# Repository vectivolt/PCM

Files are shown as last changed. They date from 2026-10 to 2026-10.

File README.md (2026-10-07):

<p align="center">
  PCM – power conversion modules: DC/DC and DC/AC, designed in Python
</p>

<p align="center">
  
  
  
  
  
</p>

**PCM** is a family of power conversion modules for solar-plus-storage systems: a 75 kW non-isolated bidirectional
MPPT DC/DC (PV-P75, with a 100/110 kW four-phase build), a 125 kW three-phase battery inverter (PCS-P125, with a
four-wire build PCS-P125-4W) and a 60 kW isolated dual-active-bridge DC/DC (DAB-D60). Everything here — KiCad 10 schematics, BOMs, costed BOMs and the
simulations behind every component value — is generated by Python scripts in this repository. Nothing is
bench-validated: every figure is calculated, simulated or estimated, and is labelled as such.

<p align="center">
  <a href="docs/README.md"><b>Documentation</b></a> ·
  <a href="docs/guide/01-overview.md">Overview</a> ·
  <a href="docs/guide/07-sourcing-and-cost.md">Cost</a> ·
  <a href="docs/guide/11-megarevo-comparison.md">Comparison</a> ·
  <a href="docs/guide/12-risks-and-open-items.md">Risks</a> ·
  <a href="docs/guide/13-repository-guide.md">Repository guide</a>
</p>

---

## ⚡ At a glance

| Product | What it is | Rating | Ports | Status as of 2026-10-07 |
|---|---|---|---|---|
| **PV-P75** | non-isolated bidirectional buck-boost DC/DC with MPPT | 75 kW · 82.5 kW max | both 250–1000 V · 135 A | power board **PV-PWR rev A2** + control board **PV-CTL rev A2** drawn (recorder flash, chainable stop, ready, battery-fault input and status relay added; Ethernet footprints only, [D-075](docs/requirements/DECISIONS.md)); every build check passes; independent review answered ([D-065](docs/requirements/DECISIONS.md), [D-072](docs/requirements/DECISIONS.md)); **75 kW from 556 V; 74.25 kW at 550 V × 135 A** — the current-limited corner (the delivered rating from 562 V at equal port voltages; calculated); DESAT string re-rated to 1,300 V diodes ([D-081](docs/requirements/DECISIONS.md)); BOM 980 / 820 USD |
| **PV-P100/110** | four-phase build of the same design | 100 / 110 kW | both 250–1000 V · 145 A on the battery port | PV-PWR-4 + PV-CTL drawn; checks pass; a derated build today (100 kW from 690 V, full power to 35 °C inlet); PV-P110's 110 kW is a PV-input rating (108.8 kW delivered A→B); BOM 1,171 / 981 USD |
| **PCS-P125** | three-phase bidirectional DC-to-AC battery inverter, three-wire (3W+PE) | 125 kW · 150 kVA for 2 min | DC 590–950 V required, 624–950 V calculated at 400 V AC · 400 V AC, 180 A | power board **PCS-PWR rev A0** + control board **PCS-CTL rev A0** (assembly PCS-CTL-3W) drawn, every build check passes; start-up from the grid through an AC tap and AC precharge, Ethernet (Modbus TCP) fitted ([D-074](docs/requirements/DECISIONS.md), [D-075](docs/requirements/DECISIONS.md)); control studied by calculation, off-grid accuracy and ride-through included ([D-066](docs/requirements/DECISIONS.md), [D-077](docs/requirements/DECISIONS.md)); independently re-checked (R2) and corrected at zero BOM cost — trip chain, gate resistor, backup band, start-up sequence, bounded transients ([D-078](docs/requirements/DECISIONS.md), [D-079](docs/requirements/DECISIONS.md)); re-checked again (R3) — one-coil synchronised close, both trip layers on the four-wire short, PCS / PV bus coordination, two SiC module grades, the declared off-grid envelope ([D-080](docs/requirements/DECISIONS.md)); and once more, economically (R4) — DESAT diodes re-rated to 1,300 V, the battery-less bus window enforced (750 V default, 782 V clamp), the envelope as a declared output capability, full operation from −10 °C inlet, grade B rated 124.57 kW at 60 °C ([D-081](docs/requirements/DECISIONS.md)); BOM 1,589 / 1,349 USD |
| **PCS-P125-4W** | the same inverter, four-wire (3W+N+PE), with a fourth two-level leg for the neutral | 125 kW · 100 % unbalanced load (one phase at its tier) | DC 650–950 V required, 624–950 V calculated (neutral leg in mode B) · 400/230 V AC, 180 A | power board **PCS-PWR-4W rev A0** + **PCS-CTL rev A0** (assembly PCS-CTL-4W) drawn, every build check passes ([D-074](docs/requirements/DECISIONS.md)); auxiliary supply re-rated for it ([D-076](docs/requirements/DECISIONS.md)); BOM 1,926 / 1,636 USD (a lower bound: two lines unpriced) |
| **DAB-D60** | isolated dual-active-bridge DC/DC | 60 kW | 590–950 V · 400–900 V | device study with Chinese discretes (not drawn), corrected after the review ([D-068](docs/requirements/DECISIONS.md)); board DAB60 rev B (Wolfspeed modules) frozen, to be redrawn cost-first |

<sub>Ratings: <a href="docs/requirements/REQUIREMENTS.md">REQUIREMENTS.md</a> (PV-01…08, AC-02, DAB-01, DAB-10/11). BOM figures are catalogue / 5,000 units in USD, estimates where no price exists (<a href="bom/COST.md">bom/COST.md</a>, as of 2026-10-07). The earlier full-featured eight-board platform is kept as the roadmap's reference implementation and is not developed further.</sub>

## 🔬 Status dashboard

| | Requirements | Architecture | Design study | Schematic | Build checks | Costed BOM | Bench test |
|---|:---:|:---:|:---:|:---:|:---:|:---:|:---:|
| **PV-P75** |  |  |  |  |  |  | — |
| **PV-P100/110** |  |  |  |  |  |  | — |
| **PCS-P125 / -4W** |  |  |  |  |  |  | — |
| **DAB-D60** |  |  |  |  |  |  | — |

<sub>Teal = done · amber = partial, in study or frozen · — = not started. Bench tests and PCB layout are outside this repository's scope. Generated detail: <a href="docs/guide/01-overview.md#-status">Overview › Status</a>. Pin audit: 247 parts drawn, 192 pass (1,961 pins), 0 fail, 55 not auditable with a written reason (<a href="gen/data/pin_audit_report.csv">pin_audit_report.csv</a>). Review registers: the independent review of commit <code>033d8d8</code> — 27 findings, 22 closed, 5 open — is <a href="gen/data/review_pcm.csv">gen/data/review_pcm.csv</a>; the re-check of commit <code>a427981</code> — 14 findings, all closed in the register — is <a href="gen/data/review_r2.csv">gen/data/review_r2.csv</a>; the re-check of commit <code>615e4b5</code> — 5 findings, all closed in the register — is <a href="gen/data/review_r3.csv">gen/data/review_r3.csv</a>; the economical re-check of commit <code>845131d</code> — 12 decision areas, all closed in the register — is <a href="gen/data/review_r4.csv">gen/data/review_r4.csv</a>; all four summarised in <a href="docs/guide/08-verification.md#-independent-design-reviews">Verification</a>.</sub>

**Independent re-check R2 (2026-10-07).** A second independent review re-checked commit `a427981` and raised 14
findings (8 high, 6 medium). Each was reproduced on our own models before anything changed: 9 *Confirmed*, 1 *Firmware
Handled*, 2 *Already Fixed*, 1 *Not Applicable*, 1 *Improvement Recommended* ([review_r2.csv](gen/data/review_r2.csv)).
[D-078](docs/requirements/DECISIONS.md) answers the power stage and protection chain — the inverter's trip turns the
gates off at about 520 A, so the turn-off gate resistor went from 7.5 to 8.75 Ω (1,437 V against 1,445 V, calculated),
the controller's backup band was lowered below the L1 knee, the SiC devices get an absolute R<sub>DS(on)</sub> limit with
a per-lot derating, and the AC coil and the residual-current monitor get one contract each.
[D-079](docs/requirements/DECISIONS.md) answers the control study — a 1,944-case tolerance regression (the reviewer's
own reproduction of the nominal margins matched ours), off-grid transients bounded at 0.43 / 1.77 pu (the 2.17 pu
figure is superseded), stiff-grid ride-through without derating (the derating is now the fallback) and the AC start as
an executed state machine with five repairs. Nothing was added to the BOM. The installation conditions the modules rely
on are collected, row by row with their source lines, in [INSTALLATION.md](docs/requirements/INSTALLATION.md); what only
hardware can close stays open in [Risks and open items](docs/guide/12-risks-and-open-items.md).

**Independent re-check R3 (2026-10-07).** A third review re-checked the R2 response, commit `615e4b5`, and raised five
findings (4 high, 1 low): 4 *Confirmed*, 1 *Improvement Recommended*, all closed in the register
([review_r3.csv](gen/data/review_r3.csv)). [D-080](docs/requirements/DECISIONS.md) answers them with firmware and
acceptance rules and one requirement row, nothing added to the BOM (simulated or calculated): the inverter's
synchronised close now pulls in one AC contactor coil at a time (38.9 / 42.2 W against the 48 W peak; 646 state-event
pairs and 24 fault runs pass); the four-wire line-to-neutral short is replayed through both hardware trip layers, and a
5 ms onset clamp keeps it 13.3 A below the lower one; the assumed 50 µs DC/DC stop is replaced by the coupled PCS / PV
trajectory, on which an island rides a full-load rejection with the PV modules' coordination row (its one-node 909 V is
a model validity, not a rating — the window enforced since D-081 is 750 / 782 V); the SiC devices grade each module A
or B with a full tier table (at 60 °C 198.0 / 216.0 / 242.9 A against 179.8 / 192.6 / 192.6 A; grade B's 179.8 A is
124.57 kW at PF 1), bound to the module serial; and the off-grid envelope is the ITIC-style curve from memory, adopted by
delegation as requirement AC-04 (+0.054 pu margin, simulated). The reviewer's own inner-loop reruns matched the study to
the last digit.

**Independent re-check R4 (2026-10-07).** A fourth, economical review of commit `845131d` grouped its points into
twelve decision areas (2 high, 5 medium, 5 low), each with a preferred option, an alternative, a no-change boundary and a
cost basis: 3 *Confirmed*, 4 *Already Fixed*, 3 *Improvement Recommended*, 2 *Not Applicable*, all closed in the
register ([review_r4.csv](gen/data/review_r4.csv)). [D-081](docs/requirements/DECISIONS.md) answers them (calculated or
simulated): its one new technical finding was right and our own envelope made it wider — the DESAT string of every
1,700 V gate-drive channel now has two 1,300 V diodes (Vishay BYG23T-M3/TR) instead of 1,000 V ones that relied on
unproven sharing, each blocking the 1,130 V static envelope alone, for +0.96 to +2.12 USD per module at 5,000 units; the
coupled DC bus carries the inter-module cable (up to +28 V) and runs inside an enforced window — 750 V default, 782 V
firmware clamp, no island start above 791 V — over a harness contract for the integrator; requirement AC-04 is reworded
as the module's declared output capability, not a load-compatibility claim, with a release sequence; the inverter's
passive cold-start table is too small to be useful, so its cold rating is full operation from −10 °C inlet (AC-02
amended by delegation); grade B states its rating, 124.57 kW at 60 °C; and the custom magnetics get an RFQ index
([RFQ-MAGNETICS.md](docs/requirements/RFQ-MAGNETICS.md)). No topology, capacitor bank, brake chopper or inter-module trip
line was added. The restrictions it accepts, each with the boundary that stays, are listed in
[Risks and open items](docs/guide/12-risks-and-open-items.md#standing-restrictions).

**Independent closure re-check R5 (2026-10-07).** A fifth review of commit `5c56aaa` found no new defect: six closure
rows, 4 *Already Fixed*, 1 *Not Applicable* (the earlier platform's GDRV-HB / DAB60 keep their own 1,200 V-class diode
strings, deferred with their own qualification), 1 *Improvement Recommended*, all closed in the register
([review_r5.csv](gen/data/review_r5.csv)). The reviewer verified D-081 at BOM level (the BYG23T counts per board) and by
his own arithmetic (the 6.415–9.365 V DESAT window, the 790.9 V bus permissive, the −10 °C inverter grade), and his
bottom line is accepted in [D-082](docs/requirements/DECISIONS.md): the next useful milestone is a representative
switching cell and a controlled prototype, not another declaration that every script passes. What changes is one
document: every open gate of the five rounds — the DESAT string's dynamic qualification, the battery-less bus and its
harness, the cold rating and grid code, the SiC cell's short-circuit survival, layout, supplier data, magnetics, bench
protection tests, pre-compliance, production controls — is consolidated into the
[Qualification plan](docs/requirements/QUALIFICATION-PLAN.md): 44 gates Q-01..Q-44 in four stages, each with the
acceptance criterion our records give, the test asset and the product or claim it blocks. No hardware change; nothing
is measured; no unrestricted HV, full-power or production sign-off is claimed from the script passes.

---

## 🧭 The cost-first PV module

One power board and one control board, control referenced to the negative DC rail, **one** reinforced barrier to
everything a person or another device can touch ([ARCHITECTURE-COSTFIRST.md](docs/requirements/ARCHITECTURE-COSTFIRST.md)):

```mermaid
%%{init: {"theme": "base", "themeVariables": {"primaryColor": "#EEF3F7", "primaryBorderColor": "#0B1F33", "primaryTextColor": "#0B1F33", "lineColor": "#5B6B7A", "secondaryColor": "#D9F2EF", "tertiaryColor": "#FFF4D6", "fontFamily": "Inter, Helvetica, Arial, sans-serif"}}}%%
flowchart LR
    PV["PV array<br/>250–1000 V"]:::ext
    BAT["battery or DC bus<br/>250–1000 V"]:::ext
    subgraph LIVE["DC side · referenced to BUS−"]
        PA["Port A<br/>varistors · contactor<br/>no fuse, no precharge"]:::live
        PH["3 interleaved buck-boost phases<br/>2 × 1700 V SiC per switch · 32 kHz<br/>12 NSI6651 gate drivers"]:::live
        PB["Port B<br/>aR fuse per pole · contactor<br/>precharge"]:::live
        AUX["75 W flyback<br/>fed from both ports"]:::live
        CTL["controller F280039C<br/>trip latch · watchdog"]:::live
    end
    subgraph SELV["SELV side"]
        COM["CAN · RS-485 · Ethernet option<br/>stop chain · ready · DI1 · relay"]:::selv
        FAN["3 fans"]:::selv
    end
    PV --> PA --> PH --> PB --> BAT
    PA --> AUX
    PB --> AUX
    AUX -- "3.3 V" --> CTL
    CTL <-- "PWM · measurements" --> PH
    CTL == "reinforced barrier B1" ==> COM
    AUX == "SELV winding" ==> FAN
    classDef live fill:#FDE7E0,stroke:#E4572E,color:#0B1F33
    classDef selv fill:#D9F2EF,stroke:#00A99D,color:#0B1F33
    classDef ext fill:#FFFFFF,stroke:#5B6B7A,stroke-dasharray:4 3
```

<sub>Red = hazardous-live DC side · teal = safe extra-low-voltage side. Detail: <a href="docs/guide/02-architecture.md">Architecture</a>, <a href="docs/guide/03-power-stage.md">Power stage</a>, <a href="docs/guide/04-protection-and-safety.md">Protection and safety</a>.</sub>

## 💰 Cost

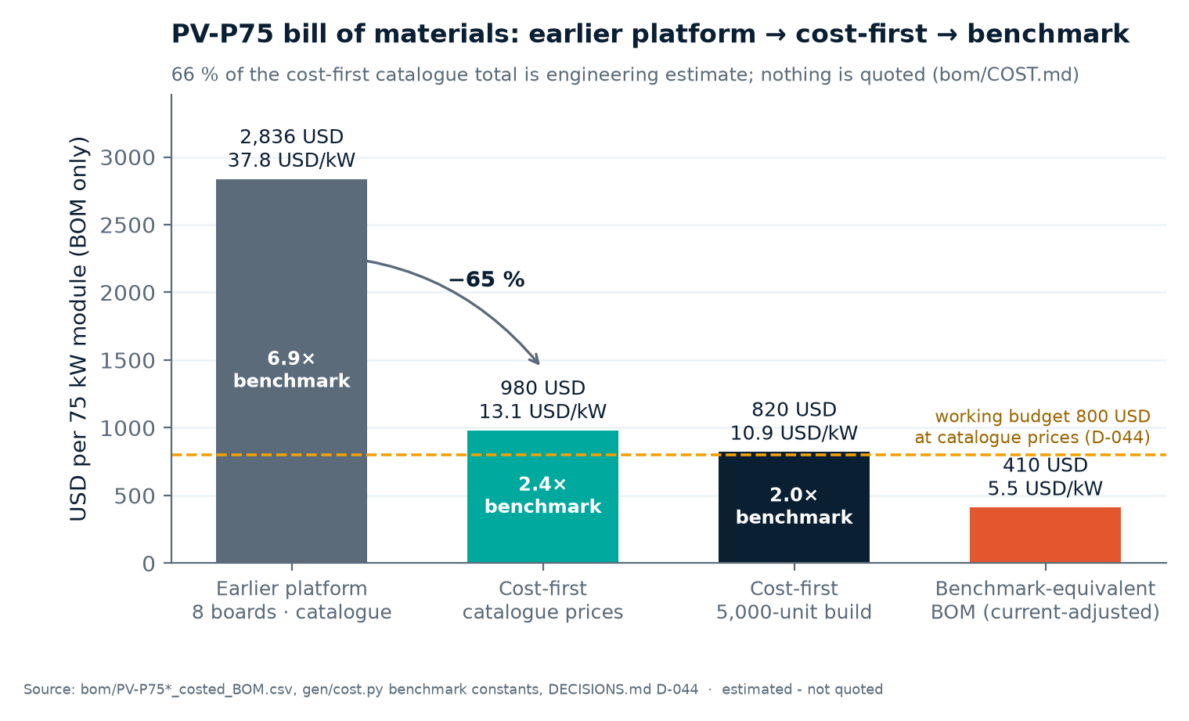
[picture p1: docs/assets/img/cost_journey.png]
PV-P75 BOM: earlier platform, cost-first at catalogue prices and at 5,000 units, against the benchmark-equivalent BOM

<p align="center"><sub>Source: <a href="bom/COST.md">bom/COST.md</a> (generated by <a href="gen/cost.py">gen/cost.py</a>) · estimated, nothing quoted</sub></p>

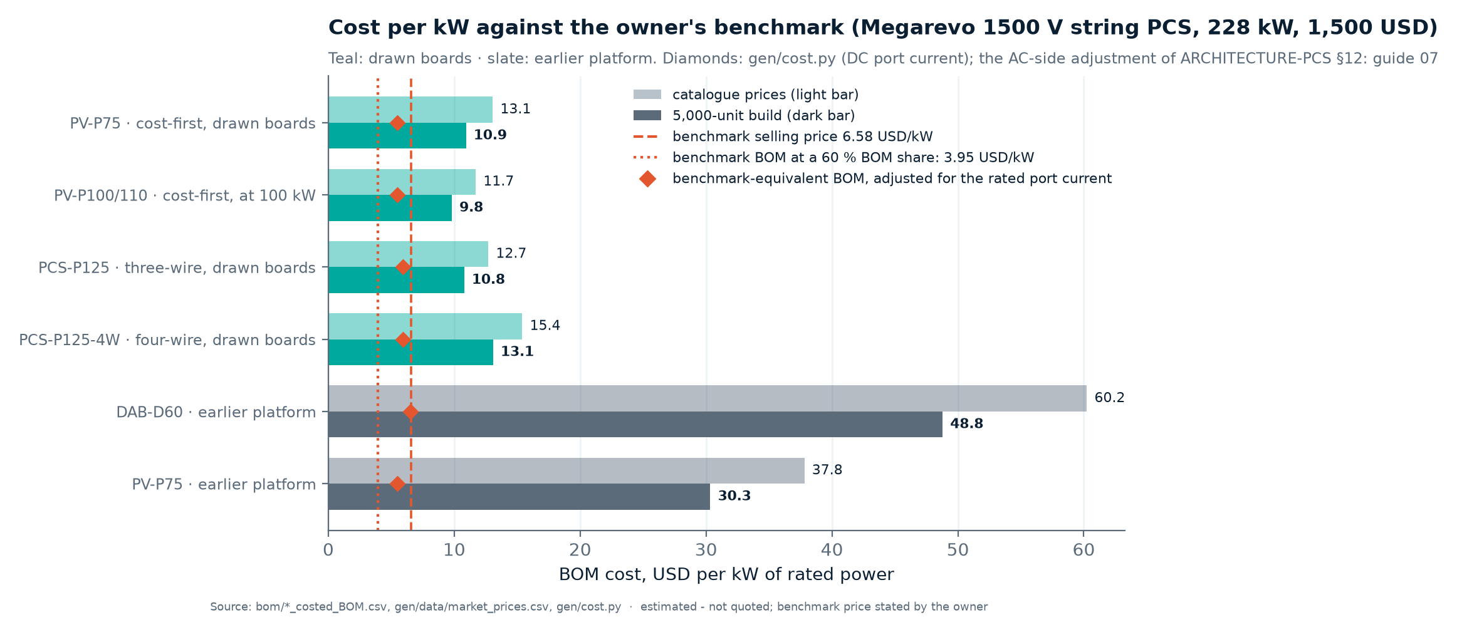
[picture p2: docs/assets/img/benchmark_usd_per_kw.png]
BOM cost per kW of every product against the owner's benchmark

<p align="center"><sub>Benchmark: Megarevo's 228 kW string PCS sells for 1,500 USD = 6.6 USD/kW (the owner's figure, a selling price). Source: <a href="gen/data/market_prices.csv">market_prices.csv</a>, <a href="sim/out/pcs_design/pcs_spec.json">pcs_spec.json</a>, <a href="bom/COST.md">bom/COST.md</a></sub></p>

<details>
<summary><b>The numbers behind the charts</b> (generated table)</summary>

<!-- BEGIN:cost-summary -->

| Product | What the figure is | kW | Catalogue USD | USD/kW | 5,000 units USD | USD/kW | Evidence | 5k ÷ benchmark-equivalent BOM |
|---|---|---:|---:|---:|---:|---:|---|---:|
| **PV-P75** | BOM of drawn boards (PV-PWR + PV-CTL) | 75 | **980** | 13.1 | **820** | 10.9 | 66 % of catalogue on estimates · 16 % of 5k on published breaks · 1 unpriced line (lower bound) | 2.0× (≈ 410 USD) |
| **PV-P100/110** | BOM of drawn boards (PV-PWR-4 + PV-CTL) | 100 / 110 | 1,171 | 11.7 / 10.6 | 981 | 9.8 / 8.9 | 64 % of catalogue on estimates · 16 % of 5k on published breaks · 2 unpriced lines (lower bound) | 1.8× / 1.8× |
| **PCS-P125** | BOM of drawn boards, three-wire (PCS-PWR + PCS-CTL-3W) | 125 | 1,589 | 12.7 | 1,349 | 10.8 | 77 % of catalogue on estimates · 9 % of 5k on published breaks · 1 unpriced line (lower bound) | 1.8× (≈ 744 USD) |
| **PCS-P125-4W** | BOM of drawn boards, four-wire (PCS-PWR-4W + PCS-CTL-4W) | 125 | 1,926 | 15.4 | 1,636 | 13.1 | 75 % of catalogue on estimates · 9 % of 5k on published breaks · 2 unpriced lines (lower bound) | 2.2× (≈ 744 USD) |
| PCS-P125 | design study, 3-wire (two-level, pcs_spec.json); the drawn boards above cost more (D-063) | 125 | 1,431 | 11.4 | 1,149 | 9.2 | 5 % of 5k on published prices | — |
| PCS-P125 | design study, 4-wire (two-level, pcs_spec.json); the drawn boards above cost more (D-063) | 125 | 1,731 | 13.8 | 1,392 | 11.1 | not stated for 4-wire | — |
| PV-P75 earlier platform | BOM of drawn boards (8 boards) | 75 | 2,836 | 37.8 | 2,275 | 30.3 | 51 % of catalogue on estimates · 17 % of 5k on published breaks · 7 unpriced lines (lower bound) | 5.5× |
| DAB-D60 earlier platform | BOM of drawn boards (5 boards) | 60 | 3,615 | 60.2 | 2,927 | 48.8 | 48 % of catalogue on estimates · 12 % of 5k on published breaks · 3 unpriced lines (lower bound) | 7.5× |
| PCS-P125 | three-level T-type estimate, **withdrawn by D-053** | 125 | 1,037 | 8.3 | 801 | 6.4 | — | — |

<sub>Generated by <a href="docs/assets/figures_overview.py">figures_overview.py</a> from <a href="bom/COST.md">bom/*_costed_BOM.csv</a>, <a href="sim/out/pcs_design/pcs_spec.json">pcs_spec.json</a> and <a href="gen/data/costfirst_pcs_bom.csv">costfirst_pcs_bom.csv</a>; benchmark arithmetic from <a href="gen/cost.py">gen/cost.py</a>. Do not edit between the markers.</sub>

<!-- END:cost-summary -->

</details>

Method, assumptions and the next cost levers: [Sourcing and cost](docs/guide/07-sourcing-and-cost.md).

## 📐 Against Megarevo, module for module

The owner's rule ([D-073](docs/requirements/DECISIONS.md)) is parity with the competitor's **modules** in both
directions — whatever its PMA inverter modules and its PMD-75-G3 DC/DC module offer, ours offer too, and the other way
round; cabinets, containers, hybrids and HMI panels are discarded, and both products stay bidirectional. Two generated
tables compare row by row, calculated against published: PV-P75 against the PMD-75-G3 — *2 better, 24 meets, 3 below,
5 not assessed, 0 pending, out of 34 published rows* — and PCS-P125 / PCS-P125-4W against the PMA0125 — *2 better, 38
meets, 4 below, 9 not assessed, 0 pending, out of 53 published rows*. The module-level items those tables do not cover
(grid type, start-up from the grid, Ethernet, the fault recorder and upgrade, discrete I/O, declarations) are tracked in
the register [gen/data/megarevo_2026_parity.csv](gen/data/megarevo_2026_parity.csv); its gaps were closed by D-074 to
D-077 except the altitude, which stays at 2,000 m with a 3,000 m / 5,000 m option specified. Details and the rows below
Megarevo: [Comparison with Megarevo](docs/guide/11-megarevo-comparison.md).

---

## 🧰 How the repository works

Python is the source of truth: simulations write the design values, generators turn them into checked schematics,
and the BOMs, costs and these charts are generated from the result. `hardware/` and `bom/` are never edited by hand.

```mermaid
%%{init: {"theme": "base", "themeVariables": {"primaryColor": "#EEF3F7", "primaryBorderColor": "#0B1F33", "primaryTextColor": "#0B1F33", "lineColor": "#5B6B7A", "secondaryColor": "#D9F2EF", "tertiaryColor": "#FFF4D6", "fontFamily": "Inter, Helvetica, Arial, sans-serif"}}}%%
flowchart LR
    REQ["docs/requirements<br/>scope lock · decisions"] --> SIM["sim/*.py<br/>design + simulation"]
    SIM -- "spec JSON" --> GEN["gen/*.py<br/>one generator per board"]
    LIB["docs/fetch.py<br/>datasheets"] -- "pin tables" --> GEN
    GEN --> HW["hardware/<br/>KiCad 10 · PDF · netlist"]
    HW --> CHK{"build checks<br/>ERC · netlist · domains<br/>stress · BOM"}
    CHK -- "pass" --> BOM["bom/<br/>board BOMs"]
    BOM -- "build_all.py --bom" --> MOD["module BOMs"]
    MOD -- "cost.py" --> COST["costed BOMs<br/>COST.md"]
    COST -- "figures_*.py" --> DOCS["docs/<br/>charts · tables"]
```

## 🧰 Quick start

```bash
# 1  Python 3.12 environment
python3.12 -m venv .venv
.venv/bin/pip install numpy scipy matplotlib pyelftools   # PyOpenMagnetics (requirements.txt) is optional: sim/magnetics.py only

# 2  Third-party datasheets and reference designs are not kept in git - the BOM check needs them
.venv/bin/python docs/fetch.py          # downloads every file of docs/SOURCES.csv and verifies its SHA-256

# 3  Build the cost-first PV module: KiCad project, ERC, netlist check, PDF and BOM per board
.venv/bin/python gen/pv_power.py        # PV-PWR and PV-PWR-4
.venv/bin/python gen/pv_ctrl.py         # PV-CTL
.venv/bin/python gen/build_all.py --bom # roll the board BOMs up into module BOMs
.venv/bin/python gen/cost.py            # costed BOMs and bom/COST.md

# 4  Run one simulation; refresh the documentation charts and generated tables
.venv/bin/python sim/pv_design.py
.venv/bin/python docs/assets/figures_overview.py
```

Tools: KiCad 10 (`kicad-cli`; on macOS `/Applications/KiCad/KiCad.app/Contents/MacOS/kicad-cli`) and ngspice 46 on
`PATH`. A few library files must be saved by hand (sites that refuse scripted downloads): the list is in
[docs/LIBRARY.md](docs/LIBRARY.md). Everything else — every board, audit and simulation — is in the
[Repository guide](docs/guide/13-repository-guide.md).

## 📚 Repository map

```
.
├── README.md                this page
├── CLAUDE.md                project rules
├── docs/
│   ├── README.md            documentation hub
│   ├── guide/               the documentation pages
│   ├── assets/              style guide, banner, figure scripts, generated charts
│   ├── requirements/        scope lock, decision register, architecture specifications
│   ├── reference-designs/   vendor reference designs (documents fetched, READMEs in git)
│   ├── datasheets/          component datasheets (fetched, not in git)
│   ├── SOURCES.csv          manifest: every library file with URL and SHA-256
│   ├── fetch.py             downloads the library again
│   └── LIBRARY.md           the reference library's own README
├── gen/                     schematic generators, build checks, audits, cost model
│   └── data/                prices, estimates, volume factors, pin ledgers, review findings
├── sim/                     design calculations and simulations (numpy, scipy, ngspice)
│   ├── data/                device and supplier surveys
│   ├── spice/               ngspice decks
│   └── out/                 one folder per study: report, spec JSON, plots
├── hardware/                generated KiCad 10 projects with PDF, netlist, ERC and report per board
└── bom/                     generated BOMs, costed BOMs and COST.md
```

## 📚 Documentation

| | Page | What it answers |
|---:|---|---|
| 01 | [Overview](docs/guide/01-overview.md) | the product family, the roadmap, the decision timeline, status |
| 02 | [Architecture](docs/guide/02-architecture.md) | how the cost-first module is built: blocks, barriers, boards |
| 03 | [Power stage](docs/guide/03-power-stage.md) | the converter phases, devices, gate drive and losses |
| 04 | [Protection and safety](docs/guide/04-protection-and-safety.md) | trips, contactors, fuses, insulation; hardware against firmware |
| 05 | [Control and firmware](docs/guide/05-control-and-firmware.md) | control loops, MPPT, protection timing, the controller |
| 06 | [Magnetics](docs/guide/06-magnetics.md) | inductors, transformers, chokes and how they were verified |
| 07 | [Sourcing and cost](docs/guide/07-sourcing-and-cost.md) | makers and evidence, cost per module, the benchmark |
| 08 | [Verification](docs/guide/08-verification.md) | build checks, audits, reviews — and what is not verified |
| 09 | [PCS-P125](docs/guide/09-pcs-p125.md) | the DC-to-AC battery inverter, three- and four-wire, with its start-up from the grid |
| 10 | [DAB-D60](docs/guide/10-dab-d60.md) | the isolated DC/DC |
| 11 | [Comparison with Megarevo](docs/guide/11-megarevo-comparison.md) | row by row against the PMD-75-G3 and the PMA0125; the module-parity register; cost against the benchmark |
| 12 | [Risks and open items](docs/guide/12-risks-and-open-items.md) | every open risk, ranked, with what would close it |
| 13 | [Repository guide](docs/guide/13-repository-guide.md) | build, simulate, re-cost; conventions for parts and boards |
| | [Glossary](docs/guide/glossary.md) · [Decisions](docs/guide/decisions.md) | terms and abbreviations · digest of the decision register |

---

> [!IMPORTANT]
> **Honesty boundary.** Nothing in this repository has been built, bought, quoted or measured. Efficiencies,
> temperatures and margins are *calculated* or *simulated*; prices are catalogue readings (the LCSC readings are a
> snapshot of 2026-10-05) or *estimates*; competitor figures are *published* and unverified by us. A review finding
> marked closed is a corrected calculation, not a test. Several standard values are transcribed from memory and still
> have to be checked against the purchased standards. Scope is schematic + BOM + simulation — no PCB layout, mechanics
> or firmware.

> [!WARNING]
> **Top open risks** — the full ranked register is in [Risks and open items](docs/guide/12-risks-and-open-items.md).
> 1. **No supplier quotations.** About two thirds of the PV-P75 BOM (66 % of the catalogue total) is engineering estimate, and the 800 USD budget is not met ([D-052](docs/requirements/DECISIONS.md)).
> 2. **The Chinese 1700 V SiC device** (Sichain SG2M040170HJ) publishes no qualification, short-circuit or cosmic-ray data; its LCSC price is now read (5.07 USD at 90+, [D-069](docs/requirements/DECISIONS.md)) but not quoted; PV-P75 uses 24, PCS-P125 36, PCS-P125-4W 48 ([D-043](docs/requirements/DECISIONS.md), [D-053](docs/requirements/DECISIONS.md)).
> 3. **Insulation** rests on standard values from memory and an unverified surge-arrester credit; the gate driver's impulse rating needs that credit ([D-032](docs/requirements/DECISIONS.md), [D-043](docs/requirements/DECISIONS.md)).
> 4. **Gate-drive margins** for false turn-on and short-circuit turn-off rest on estimated loop inductances and assumed device withstand times — the double-pulse test is the first bench item ([D-028](docs/requirements/DECISIONS.md)); on the inverter it must include the trip's turn-off near 520 A / 1,050 V (1,437 V calculated against 1,445 V) and short-circuit survival stays a hardware release gate ([D-078](docs/requirements/DECISIONS.md)).
> 5. **Requirements the calculations contradict:** PCS-P125's full load from 600 V at 400 V ±15 % (AC-02) is not reachable, PV-P75's 75 kW at 550 V needs 136.4 A against 135 A (75 kW from 556 V; 74.25 kW at 550 V × 135 A), and PV-P110's 110 kW is a PV-input rating — owner's decisions ([Risks, group G](docs/guide/12-risks-and-open-items.md#requirements-contradicted)); the inverter's −30 °C now holds as standby or a small passive table only (rated from −10 °C at power, [D-081](docs/requirements/DECISIONS.md)).

## 🗺️ What comes next

- **PV-P75 boards:** drawn (PV-PWR rev A2, PV-CTL rev A2), reviewed and corrected ([D-065](docs/requirements/DECISIONS.md), [D-072](docs/requirements/DECISIONS.md)); the control board gained the recorder flash, the chainable stop, a ready permissive, a battery-fault input and a status relay, with Ethernet as a footprint option ([D-075](docs/requirements/DECISIONS.md)); the DESAT string re-rated to two 1,300 V diodes per channel ([D-081](docs/requirements/DECISIONS.md)); BOM 980 USD at catalogue prices, 820 USD at 5,000 units. Next: the TLV9024's rejection measured at 3.3 V and 10 ppm/K ladder resistors (risk C9), the insulation audit extended to the cost-first boards, supplier quotations for the largest estimates, a sample set of the re-wound auxiliary transformer ([D-076](docs/requirements/DECISIONS.md)).
- **PCS-P125 and PCS-P125-4W:** both builds drawn and costed — 1,589 / 1,349 USD three-wire, 1,926 / 1,636 USD four-wire (catalogue / 5,000 units) ([D-074](docs/requirements/DECISIONS.md)). **Closed on 2026-10-06:** the start-up from the grid (risk F8: AC tap and AC precharge on both builds), the four-wire build (risk F9: a fourth leg, not a midpoint neutral), Ethernet for the EMS and the recorder flash for the fault recorder and the authenticated upgrade ([D-075](docs/requirements/DECISIONS.md)), the auxiliary supply's live winding ([D-076](docs/requirements/DECISIONS.md)), the neutral-leg loop and the ride-through limiter ([D-077](docs/requirements/DECISIONS.md)). **Corrected by the re-check R2 on 2026-10-07:** the trip chain at its real gates-off current with R<sub>G,off</sub> 8.75 Ω, the backup band below the L1 knee, the SiC acceptance and per-lot derating, one coil contract and the residual-current contract ([D-078](docs/requirements/DECISIONS.md)); the tolerance regression, the bounded off-grid transients, ride-through without derating and the repaired AC-start machine ([D-079](docs/requirements/DECISIONS.md)). **Corrected by the re-check R3 the same day:** the synchronised close one coil at a time, the four-wire short against both trip layers, the coupled PCS / PV bus coordination, two SiC module grades with full tier tables, the off-grid envelope as requirement AC-04 ([D-080](docs/requirements/DECISIONS.md)). **Answered after the economical re-check R4:** the DESAT string re-rated (1,300 V diodes), the cable-aware DC-bus window enforced with a harness contract, AC-04 as a declared output capability with a release sequence, the cold rating at −10 °C inlet with the passive table and its firmware rule, grade B's 124.57 kW, the magnetics RFQ index ([D-081](docs/requirements/DECISIONS.md)). **Still open:** the owner's decision on AC-02 and the owner's confirmation of AC-04 and of the −10 °C cold rating (both by delegation); the hardware gates of D-078 (short-circuit survival, the first-article L(I) test to 600 A, a double-pulse test near 520 A / 1,050 V, Sichain's R<sub>DS(on)</sub> distribution, which now decides the grade mix); the bench confirmation of the ride-through margin (20.5 A net of noise), the four-wire short's 13.3 A and the coupled-bus peaks; the new DESAT diode's V<sub>F</sub>, per-diode split and second source; an agreed load specification per managed island; a cold-rated fan from an RFQ; the magnetics quotations (18 RFQ rows still without a number); data sheets for the RFQ parts (AC contactor coil module, the 4-pole contactors, the type-B residual-current monitor, the four-bar CM choke, the precharge resistors); the L-N surge level (a 3+1 arrangement needs a GDT data sheet); pairing the DC-component measurement on one ADC; the CH9121T's supply current and stock; no spare GPIO on the inverter's controller; powder-core inductors and the stud count as cost levers.
- **DAB-D60:** the device study is corrected ([D-068](docs/requirements/DECISIONS.md)); drawing a board for it is the owner's decision (DAB-12); otherwise redraw the board cost-first ([ARCHITECTURE-COSTFIRST §16](docs/requirements/ARCHITECTURE-COSTFIRST.md#16-dab-d60-on-the-same-principles)).
- **Comparison with Megarevo:** the rows below the published tables — PV-P75: cold limit, altitude and standby; PCS-P125: the 3W+PE DC window (two rows), cold limit and altitude ([Comparison](docs/guide/11-megarevo-comparison.md#the-four-pcs-rows-below-the-pma0125)). The altitude option (15 mm isolators for 3,000 m full / 5,000 m derated) is specified and fitted on demand.
- **Before any hardware release** (outside this repository): double-pulse test of the gate drive, a wound inductor sample, the purchased standards checked against the values used.

<sub>Scope and rules: <a href="CLAUDE.md">CLAUDE.md</a> · requirements: <a href="docs/requirements/REQUIREMENTS.md">REQUIREMENTS.md</a> · decisions: <a href="docs/requirements/DECISIONS.md">DECISIONS.md</a></sub>

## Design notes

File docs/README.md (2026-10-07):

<p align="center">
  PCM – power conversion modules: DC/DC and DC/AC, designed in Python
</p>

<!-- breadcrumb --> [Home](../README.md) › Documentation

# 📚 Documentation

> Where to start, every page of the guide in reading order, and the records the pages are built from.






---

## 🧭 Start here

| If you are… | Read in this order | You will come away with |
|---|---|---|
| **Manager or product owner** | [Overview](guide/01-overview.md) → [Sourcing and cost](guide/07-sourcing-and-cost.md) → [Comparison with Megarevo](guide/11-megarevo-comparison.md) → [Risks](guide/12-risks-and-open-items.md) → [Decisions](guide/decisions.md) | what exists, what it costs against the benchmark, what is still open and who decided what |
| **Hardware engineer** | [Overview](guide/01-overview.md) → [Architecture](guide/02-architecture.md) → [Power stage](guide/03-power-stage.md) → [Protection and safety](guide/04-protection-and-safety.md) → [Magnetics](guide/06-magnetics.md) → [Verification](guide/08-verification.md) → [Repository guide](guide/13-repository-guide.md) | how the boards are built, why each value is what it is, and how to change one safely |
| **Firmware engineer** | [Architecture](guide/02-architecture.md) → [Control and firmware](guide/05-control-and-firmware.md) → [Protection and safety](guide/04-protection-and-safety.md) → [PCS-P125](guide/09-pcs-p125.md) → [DAB-D60](guide/10-dab-d60.md) | the controller, the loops, the trip paths and what firmware must duplicate |
| **Purchaser** | [Sourcing and cost](guide/07-sourcing-and-cost.md) → [Risks](guide/12-risks-and-open-items.md) (group A) → [Repository guide](guide/13-repository-guide.md#adding-a-part) → [Glossary](guide/glossary.md) | which makers, which parts need quotations first, and the evidence behind each price |

## 🗺️ Map of the guide

```mermaid
%%{init: {"theme": "base", "themeVariables": {"primaryColor": "#EEF3F7", "primaryBorderColor": "#0B1F33", "primaryTextColor": "#0B1F33", "lineColor": "#5B6B7A", "secondaryColor": "#D9F2EF", "tertiaryColor": "#FFF4D6", "fontFamily": "Inter, Helvetica, Arial, sans-serif"}}}%%
flowchart LR
    O["01 Overview"] --> A["02 Architecture"]
    subgraph DESIGN["How it is designed"]
        A --> P["03 Power stage"]
        A --> S["04 Protection and safety"]
        A --> C["05 Control and firmware"]
        P --> M["06 Magnetics"]
    end
    subgraph PRODUCTS["The other products"]
        PCS["09 PCS-P125"]
        DAB["10 DAB-D60"]
    end
    subgraph JUDGE["What it costs and how sure we are"]
        CO["07 Sourcing and cost"] --> CMP["11 Comparison with Megarevo"]
        V["08 Verification"] --> R["12 Risks and open items"]
        CMP --> R
    end
    O --> CO
    O --> PCS
    O --> DAB
    M --> V
    R --> G["13 Repository guide"]
```

## 📚 Every page

| | Page | What it answers |
|---:|---|---|
| 01 | [Overview](guide/01-overview.md) | the product family, the roadmap, the decision timeline, status by product and board |
| 02 | [Architecture](guide/02-architecture.md) | how the cost-first module is built: blocks, reference potentials, barriers, boards |
| 03 | [Power stage](guide/03-power-stage.md) | the converter phases, devices, gate drive, losses and thermal design |
| 04 | [Protection and safety](guide/04-protection-and-safety.md) | trips, contactors, fuses, insulation; what hardware does and what firmware duplicates |
| 05 | [Control and firmware](guide/05-control-and-firmware.md) | control loops, MPPT, protection timing, the controller's resources |
| 06 | [Magnetics](guide/06-magnetics.md) | inductors, transformers and chokes, and how each was verified |
| 07 | [Sourcing and cost](guide/07-sourcing-and-cost.md) | makers and evidence, cost per module at catalogue prices and at 5,000 units, the benchmark |
| 08 | [Verification](guide/08-verification.md) | build checks, audits and reviews — and what none of them proves |
| 09 | [PCS-P125](guide/09-pcs-p125.md) | the three-phase DC-to-AC battery inverter: the three-wire and four-wire builds, the start-up from the grid, the firmware specification |
| 10 | [DAB-D60](guide/10-dab-d60.md) | the isolated dual-active-bridge DC/DC |
| 11 | [Comparison with Megarevo](guide/11-megarevo-comparison.md) | row by row against the PMD-75-G3 and the PMA0125; the module-parity register; every product against the price benchmark |
| 12 | [Risks and open items](guide/12-risks-and-open-items.md) | every open risk, ranked, with its consequence and what would close it |
| 13 | [Repository guide](guide/13-repository-guide.md) | build a board, run a simulation, re-roll the cost; conventions for parts and boards |
| | [Glossary](guide/glossary.md) | abbreviations and project terms |
| | [Decisions](guide/decisions.md) | the decision register D-001…D-082, grouped by theme, with today's status |

> [!NOTE]
> **Status on 2026-10-07: the independent re-checks R2, R3 and R4 are answered.** A second independent review re-checked commit
> `a427981` and raised 14 findings (8 high, 6 medium); each was reproduced on our own models first and then classified —
> 9 *Confirmed*, 1 *Firmware Handled*, 2 *Already Fixed*, 1 *Not Applicable*, 1 *Improvement Recommended*
> ([review_r2.csv](../gen/data/review_r2.csv), all 14 closed in the register). [D-078](requirements/DECISIONS.md) answers
> the inverter's power stage and protection chain (the trip at its real gates-off current with R<sub>G,off</sub> 8.75 Ω,
> the backup band below the L1 knee, the SiC acceptance rule, one coil contract, the residual-current contract);
> [D-079](requirements/DECISIONS.md) the control study and hand-over (the tolerance regression, bounded off-grid
> transients, ride-through without derating, the AC start as an executed state machine). Everything stays calculated or
> simulated; the hardware gates are in [Risks](guide/12-risks-and-open-items.md#-the-re-check-r2-of-commit-a427981-2026-10-07),
> the installation conditions in [INSTALLATION.md](requirements/INSTALLATION.md).
>
> **The re-check R3 is answered too.** A third review re-checked the R2 response, commit `615e4b5`, and raised five
> findings (4 high, 1 low): 4 *Confirmed*, 1 *Improvement Recommended* ([review_r3.csv](../gen/data/review_r3.csv), all
> five closed in the register). [D-080](requirements/DECISIONS.md) answers them with firmware and acceptance rules and one
> requirement row: the synchronised close one AC coil at a time, the four-wire short replayed through both trip layers
> (a 5 ms onset clamp, 13.3 A margin), the coupled PCS / PV trajectory instead of an assumed 50 µs DC/DC stop (an island
> rides a full-load rejection with the PV modules' coordination row), two SiC module grades with full tier tables bound
> to the module serial, and the off-grid envelope as the ITIC-style points adopted by delegation as REQUIREMENTS AC-04 —
> nothing added to the BOM, all simulated or calculated ([Risks](guide/12-risks-and-open-items.md#-the-re-check-r3-of-commit-615e4b5-2026-10-07)).
>
> **The economical re-check R4 is answered as well.** A fourth review of commit `845131d` grouped its points into twelve
> decision areas: 3 *Confirmed*, 4 *Already Fixed*, 3 *Improvement Recommended*, 2 *Not Applicable*
> ([review_r4.csv](../gen/data/review_r4.csv), all twelve closed in the register). [D-081](requirements/DECISIONS.md)
> re-rates the DESAT string to two 1,300 V diodes per channel (each blocks the 1,130 V static envelope alone; +0.96 to
> +2.12 USD per module at 5,000 units), enforces the DC-bus window on a battery-less bus with the inter-module cable
> modelled (750 V default, 782 V firmware clamp, 791 V island permissive — the one-node 909 V is a model validity, not a
> rating) and a harness contract, rewords AC-04 as a declared output capability with a release sequence, sets the
> inverter's cold rating to full operation from −10 °C inlet, states grade B's 124.57 kW and indexes the magnetics RFQs
> ([RFQ-MAGNETICS.md](requirements/RFQ-MAGNETICS.md)); the restrictions it accepts and their boundaries are in
> [Risks](guide/12-risks-and-open-items.md#-the-re-check-r4-of-commit-845131d-2026-10-07).

---

## 📐 The records behind the pages

The pages explain; these files decide. Where a page and a record differ, the record wins.

| Record | What it holds | Edited by |
|---|---|---|
| [requirements/REQUIREMENTS.md](requirements/REQUIREMENTS.md) | the scope lock: every requirement with its source (roadmap or assumption) | the owner's instruction only |
| [requirements/DECISIONS.md](requirements/DECISIONS.md) | the decision register — rows are superseded, never deleted | appended per decision |
| [requirements/00-roadmap-source.md](requirements/00-roadmap-source.md) | the owner's engineering and product roadmap the requirements were distilled from | read-only |
| [requirements/COST-REVIEW.md](requirements/COST-REVIEW.md) | why the PV module was re-architected for cost | — |
| [requirements/ARCHITECTURE-COSTFIRST.md](requirements/ARCHITECTURE-COSTFIRST.md) | the cost-first PV module specification (and the DAB outline, §16) | — |
| [requirements/ARCHITECTURE-PCS.md](requirements/ARCHITECTURE-PCS.md) | the PCS-P125 architecture specification; its power stage is revised by D-053 | — |
| [requirements/INSTALLATION.md](requirements/INSTALLATION.md) | the installation conditions the modules depend on: 77 rows (INST-01…77), each with the generated line it comes from (review finding R2-12), and the installation-facing standing restrictions of the re-check R4; re-verified after the rebuild for the re-check R4 (D-081) on 2026-10-07 | by hand from the design checks; its quoted lines are re-verified after a rebuild |
| [requirements/RFQ-MAGNETICS.md](requirements/RFQ-MAGNETICS.md) | the request-for-quotation index for the ten custom magnetic parts: quantity per module and per build, the requirement rows a quotation must hold (inductance at current, losses, insulation, temperature), the type and production tests, the estimate held, the rows still without a number, and the 48 kHz weight-sensitive variant as an appendix (review R4, item E12) | by hand from the winding sheets and the costed BOMs; re-read after a magnetics or BOM rebuild |
| [requirements/QUALIFICATION-PLAN.md](requirements/QUALIFICATION-PLAN.md) | the consolidated qualification plan (D-082, review R5): every open gate of the five review rounds as Q-01…Q-44 — what is tested, the acceptance number our records give, the test asset, the product or claim it blocks and the stage (representative switching cell → controlled prototype → DVT → production controls) — with a "what a paper waiver cannot replace" section and a gate / blocks / stage / source table; nothing in it has been executed, and the R5 register [review_r5.csv](../gen/data/review_r5.csv) (six rows, all closed, no new defect) is the record behind it | by hand from the registers, the decisions' **Open** lists, INSTALLATION.md, RFQ-MAGNETICS.md and the generated checks; its quoted generated lines are re-found after a rebuild |
| [requirements/GDRV-ALTERNATES.md](requirements/GDRV-ALTERNATES.md) · [REFERENCE-LESSONS.md](requirements/REFERENCE-LESSONS.md) | gate-driver alternates from datasheets · what recent TI reference designs change, and (§6) the cross-check against Wolfspeed's firmware packages | — |
| `../gen/data/review_*.csv`, [integration_findings.csv](../gen/data/integration_findings.csv) | findings of the independent design reviews; [review_pcm.csv](../gen/data/review_pcm.csv) holds the 27 findings of the review of commit `033d8d8`, [review_r2.csv](../gen/data/review_r2.csv) the 14 of the re-check of `a427981`, [review_r3.csv](../gen/data/review_r3.csv) the 5 of the re-check of `615e4b5` and [review_r4.csv](../gen/data/review_r4.csv) the 12 decision areas of the economical re-check of `845131d` (each with a preferred option, an alternative, a no-change boundary and a cost basis), each with its status, class and closure | appended per review round |
| [../bom/COST.md](../bom/COST.md) | the cost model, line by line | generated by `gen/cost.py` |
| [../gen/data/megarevo_2026_parity.csv](../gen/data/megarevo_2026_parity.csv) | the module-parity register against Megarevo (D-073): item, their published statement, ours, verdict, the decision behind it | its `ours` / `verdict` / `action` cells per decision |
| `../sim/out/compare_megarevo/` · [`../sim/out/compare_megarevo_pcs/`](../sim/out/compare_megarevo_pcs/report.md) | the row-by-row comparisons with the PMD-75-G3 and the PMA0125 (`comparison.csv`, `report.md`) | generated by `sim/compare_megarevo.py` and `sim/compare_megarevo_pcs.py` |
| [reference-designs/megarevo/pma/spec-pma0125.md](reference-designs/megarevo/pma/spec-pma0125.md) · [MANUAL-NOTES.md](reference-designs/megarevo/pma/MANUAL-NOTES.md) | the PMA0125 table transcribed verbatim; the PMA user manual's module-level statements with page numbers | our notes on the competitor's documents (the PDFs are fetched, not kept in git) |
| `../sim/out/*/report.md` and `*_spec.json` | design calculations and simulations; the spec files are the hand-off to the generators | generated by `sim/*.py` |
| `../hardware/*/outputs/` | schematic PDF, netlist, ERC, build report and design check per board | generated by `gen/*.py` |
| [LIBRARY.md](LIBRARY.md) · [SOURCES.csv](SOURCES.csv) | the reference library: what is on file, what must be fetched by hand; one manifest row per document | `docs/fetch.py --summary` writes the counts |

## How to read the numbers

- **Calculated** — from a model or a datasheet in a script under `sim/` or `gen/`. **Simulated** — from a time-domain
  or circuit simulation (ngspice, Python). **Estimated** — an engineering judgement with its basis written next to it.
  **Published** — a competitor's or maker's statement, not verified by us. Nothing is **measured**.
- Numbers that will move carry an **as of** date; generated tables say which script wrote them and must not be edited
  between their `<!-- BEGIN -->` / `<!-- END -->` markers.
- Badge colours: teal = done or in force · amber = in study, partial or estimate · coral = open risk · slate = neutral
  · navy = reference. The visual rules are in the [style guide](assets/STYLE.md).
- Charts are drawn by [`assets/figures_overview.py`](assets/figures_overview.py) and
  [`assets/figures_design.py`](assets/figures_design.py) from the repository's own data files — never by hand.

---

<!-- footer --> ← [Home](../README.md) · Documentation index · [Overview](guide/01-overview.md) →

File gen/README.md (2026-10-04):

# Schematic generators

One Python script per board. Running it writes a real KiCad 10 project, verifies it and writes the BOM:

```bash
.venv/bin/python gen/bmu_gw.py        # -> hardware/BMU-GW/ (schematic, PDF, netlist, ERC, report) + bom/BMU-GW_BOM.csv
```

`gen/bmu_gw.py` is the pattern to copy. `gen/dcdclib.py` (docstring) defines the catalog-entry format and the
`Builder` API. `schgen.py`, `symlib.py`, `sexpr.py` are the KiCad writer copied from the Meter project — do not edit them.

## How a board is written

```python
B = L.Builder(PROJECT, "title", REV, DATE, CATALOG, rails=["+24V", "3V3"], returns=["GND"], ...)
B.new_sheet("01_name", "Sheet title", "two-line description")     # key must start NN_
B.block("Block title", "note printed under the block")
B.part("UCC21710", {"1": "NET_A", "2": None, ...})                # catalog key, {pin number: net}; None = no-connect
B.R("10k", "NET_A", "GND")                                        # jellybean resistor  (pkg=, tol=, note=)
B.C("100n", "3V3", "GND")                                         # jellybean MLCC      (pkg=, volt=, diel=, tol=)
B.flag("+24V")                                                    # PWR_FLAG where a rail enters via a connector/passive
sys.exit(L.build(B, domain_of=domain_of, isolators=iso, crossings=xing, waivers={...}))
```

- A **net is just its name**. The same name on two sheets is the same net. `rails`/`returns` are drawn as power symbols.
- **Every pin of every symbol must be given** a net or `None`. A net with a single pin is an ERC error — connect it,
  give it a test point (`B.TP(net)`), or make the pin `None`.
- Layout is automatic (blocks are packed on A3→A1). Keep a sheet to one function; fewer than 100 parts per reference
  prefix per sheet. Title "root title - sheet title" must stay ≤ 62 characters; cover-box description lines ≤ 85.
- **Catalog entries** live in the board script (`CATALOG = dict(catalog.PARTS, **{...})`). `gen/catalog.py` holds
  parts already verified and shared — use them, do not edit that file. `gen/interfaces.py` holds the inter-board
  connector pin maps — use `interfaces.pins(...)` for those connectors, do not edit that file.
- **Pin tables come from the datasheet PDF**, never from memory: `pdftotext -layout docs/datasheets/<cat>/<MPN>.pdf -`.
  If the PDF is not in `docs/datasheets/<category>/` yet, download it from the manufacturer's own site (PDF only, no
  login) to `docs/datasheets/<category>/<MPN>.pdf`. Put the document number and page/figure of the pin table in a
  comment next to the entry. KiCad stock symbols: `.venv/bin/python gen/dcdclib.py Device:D_Schottky` prints their pins.
- **MPN must be a real orderable part number**, `ds` an existing repo path or an https URL on the maker's site.
  Custom magnetics / busbars / heatsinks: `sourcing="CUSTOM"` with the full spec in `desc`.
- **Isolation domains:** `domain_of(net)` names the domain of every net; only parts listed in `isolators` (barrier
  components) or `crossings` (deliberate non-barrier bridges such as a Y capacitor or a sense divider) may touch two.
- **Part stress:** `vrange(net)` returns the DC range `(vmin, vmax)` of a net against its own domain's reference, or
  `None` for a net without one (switch node, gate, bus line). `build(..., vrange=...)` then checks every jellybean
  capacitor (applied voltage <= 80 % of rated) and resistor (dissipation <= 60 % of the package rating, voltage <= the
  package working voltage) between two ranged nets. Pulse load, ripple current and catalogue parts stay in the
  board's own `design_check()`. Pattern: `VDC` in `gen/bmu_gw.py`.
- ERC must be clean. `waivers={"violation_type": "reason"}` may silence a *warning* type with a written reason;
  errors can never be waived.

## What `build()` checks

ERC via kicad-cli (all severities) · exported netlist identical to the Python table · isolation domains ·
jellybean part stress (when `vrange` is given) · PDF rendered · BOM completeness (manufacturer + MPN + datasheet on file, or GENERIC/RFQ/CUSTOM/NOPART).

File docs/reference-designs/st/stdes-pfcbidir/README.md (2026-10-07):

# STDES-PFCBIDIR - 15 kW three-phase three-level bidirectional AFE (ST)
Data brief only (lower priority). STM32G474RET3, SiC, 100 kHz; STSW-PFCBIDIR firmware exists (not fetched).
- **Ratings (web-search summary of the ST data brief; NOT verified against a PDF):** 800 V DC nominal, 400 V AC / 50 Hz, 15 kW, efficiency > 98 %.
- **Informs:** AFE control cross-check only; the AC-side PCS is out of scope for this repo. (written before D-046 / D-053 brought the PCS-P125 inverter into scope; the AFE cross-check now informs the PCS control study, sim/out/pcs_design/crosscheck_wolfspeed.md and docs/guide/09-pcs-p125.md)
- **Limitation (roadmap):** high-current power stage and product packaging are not covered.
- **Status:** the data brief is MANUAL (st.com closes the connection for curl; retried once on 2026-10-04: same). Direct link in SOURCES.csv.

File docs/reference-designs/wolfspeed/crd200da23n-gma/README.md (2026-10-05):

# CRD200DA23N-GMA - 200 kW three-phase two-level inverter for a 1500 V DC bus (Wolfspeed)
Three CAB5R0A23GM4T (2300 V, 5 mohm) WolfPACK half-bridge modules, one per phase; TI LAUNCHXL-F28379D controller; three CGD1700HB2M-UNA gate-driver boards (TI UCC21710, desaturation protection on every switch position, differential signalling); forced-air heat sink. All figures below are Wolfspeed's, from user guide PRD-09623 Rev. 2 (February 2026); nothing here is ours or re-measured.
- **Native ratings** (Table 1): 200 kW maximum, DC bus 1500 V typical, 167 A rms phase current, 20 kHz typical / 50 kHz maximum, junction-to-ambient 0.343 K/W.
- **Power stage** (section 3.1): DC link of two series-stacked sets of five KEMET C4AQQEW5650A3BJ film capacitors (65 uF, 1.1 kV each) = 162.5 uF at 2.2 kV, i.e. 0.81 uF per kW; the midpoint is brought out for a load neutral or a split supply; balance / bleed resistors permanently connected (below 50 V in under 2.5 minutes); six-layer interleaved DC+ / DC- planes (Table 8); an RC snubber at the module terminals (section 3.3, Figure 27: waveforms at 1500 V and 167 A with and without it).
- **Gate drive and protection** (section 3.2): 0 ohm external gate resistors on these boards (the standard driver board has 1 ohm); desaturation detection with soft turn-off. A tripped driver switches off only its own channel; the other channels are held off through the controller's trip-zone input, which the guide says needs the firmware to be set up for it (section 3.2.2).
- **Tested** (section 5.2, Tables 11-12): 1000 V bus (the supply is a 1000 V / 30 kW unit), 167 A rms, 20 kHz, 400 ns dead time, 25 C ambient, into a 129 uH / 600 A three-phase inductor in wye with its neutral on the capacitor midpoint - a reactive load, so the supply only covers the losses. Module thermistor 43 C after 30 minutes. Efficiency against output power is given as a curve only (Figure 50). A PLECS model is part of the design files.
- **Caveat in the guide** (page 1): laboratory evaluation hardware, "not designed to meet any industrial, technical, or safety standards", not production-qualified. No grid filter, contactors, EMI filter or grid protection on the board; the firmware was not reviewed here.
- **Firmware** (package v1.0.0, supplied by the owner on 2026-10-05, unpacked in `firmware/`; this replaces "the firmware was not reviewed here" above): an **open-loop starting point** — a sine-PWM generator with no current loop, PLL, DC-link loop or grid forming and no protection in firmware beyond the drivers' DESAT trip zone; read statically in [FIRMWARE-NOTES.md](FIRMWARE-NOTES.md), lessons in `docs/requirements/REFERENCE-LESSONS.md` §6 (D-071).
- **Informs:** the DC-to-AC product PCS-P125 (decision D-053). It is a published precedent for a two-level SiC stage with the devices at 0.65 of their rating (1500 V on 2300 V parts) in place of a three-level stage - the rule our 950 V on 1700 V parts (0.56) follows - and for the size of a two-level film DC link. It is also the voltage class of the price benchmark (Megarevo 1500 V string PCS).
- **Limitation:** power modules, not paralleled discretes; 1500 V class, not our 1000 V class; tested at 1000 V, not at the rated bus voltage with full current.
- **Files:** user guide (plain download from wolfspeed.com) and the design-files archive V1.1 (02-2026), supplied by the owner on 2026-10-05 and byte-identical to the file behind the product page's link. Unpacked in `design-files/`: the schematic PDF and the assembly BOM; the Altium and Gerber archives stay inside the zip (no layout work in this project). An older V1.0 (11-2024) package exists and is not filed. See SOURCES.csv.
- **Related, not filed:** Wolfspeed PRD-08907 "Mitigating EMI with SiC Solutions in Renewable Energy and Grid-Connected Power Converters", linked from the same product page - fetch it when the PCS emission filter is designed.

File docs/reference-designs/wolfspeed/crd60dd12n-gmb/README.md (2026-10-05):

# CRD60DD12N-GMB - 60 kW isolated bidirectional DC/DC, dual active bridge (Wolfspeed)
Two CBB011M12GM4T (1200 V / 11 mohm Gen-4 WolfPACK full-bridge) modules on one liquid cold plate, UCC21710 gate drivers, isolated DC-bus and transformer-current sensing, TI TMDSCNCD280039C controller with baseline firmware. No transformer supplied.
- **Native ratings** (PRD-10001 Rev 1, May 2026, Table 1): 60 kW max; Vin 700 / 800 / 900 V (min/typ/max); Vout 400 / 800 / 900 V, **power derated below 600 V**; Iout <= 100 A; 100 kHz fixed; coldplate-to-fluid 0.045 degC/W.
- **Transformer** (UG section 5.2, p51): recommended custom Egston/YAGEO 81989-01, 202 x 81 x 73 mm; L_leak 7.5 uH, L_m 329 uH, Rw 78 mohm at 100 kHz (Table 9). Turns ratio not published.
- **Validated range in the guide:** 800 V to 800 V, 10-23 kW only (source rated 30 kW). The 99.2 % / > 98.8 % figures are web-page claims, not stated in the PDF text.
- **Hardware shown by the design files** (V2.0 schematics and assembly BOMs, unpacked in `design-files/`; power board 10/2024 = 2 sheets, control board 02/2025 = 12 sheets; the control schematic prints reference designators without the BOM's T/B layer suffix):
  - **Modules:** Q1 (primary) and Q2 (secondary) CBB011M12GM4T, "1200 V 100 A", press-fit, not soldered (power sheet 1 "POWER STAGE"; power BOM DNP-27). The power board carries no gate drivers; J1 (Samtec TSM-128-01-L-DV-A) takes gate, Kelvin-source and sensor signals to the control board.
  - **Gate drivers:** 8 x UCC21710QDWRQ1, one per switch, 4 per bridge (control sheets 3-6 "DRIVERS (12P) / (34P) / (12S) / (34S)", two per sheet). Each has its own UCC14141QDWNRQ1 1.5 W isolated bias module fed from a +12 V rail, giving +15 V / -4 V (UG p33). Turn-on resistor 0.91 ohm (8 x RCWE1210R910FKEA, control BOM item 40), turn-off 0 ohm; the DESAT/OC input is sensed through two series US3M-13 diodes; the module NTC is read on the AIN pin of the switch-2 drivers only (sheets 3 and 5). Fault gating: SN74HCS21 4-input ANDs (sheets 7-8), SN74LV541A / TXU0104 level shifting (sheet 9).
  - **Controller:** TMDSCNCD280039C (F280039C, **not** F28388D) in an HSEC8-160 edge connector (sheet 1, DNP-90 in the control BOM). 12 V barrel-jack input through an LTC4368 surge stopper and 2 x DMT12H007LPS; 5 V and 3.3 V from RECOM R-78E converters; CAN through a TCAN1044V (sheets 1-2). No HV bootstrap supply and no 24 V rail.
  - **Transformer / inductor:** not in either BOM or schematic. The AC mid-points PA/PB (primary) and SA/SB (secondary) end in screw lugs (J2/J4/J6/J8, McMaster 4164N12); there is no series inductor and no DC-blocking capacitor on the board.
  - **DC link:** 5 x KEMET C4AQNEW5650M3BJ, 65 uF 5 % 1 kV film: C60, C61 on the primary (130 uF), C62-C64 on the secondary (195 uF) (power sheet 1; the MPN is confirmed by power BOM item 7). Bleed: 24 x 220 kohm 2 W (TE CRGP2512F220K, 12 per side), bus below 50 V in under 3 minutes (UG p28).
  - **HF capacitors:** 23 x KEMET LDEQG2470KA5N00, 47 nF 10 % 1 kV **film, 5040 case**: 10 on the primary link (C11-C13, C17-C23), 13 on the secondary (C27-C29, C33-C39, C43-C45) (power sheet 1; UG Fig. 19).
  - **Snubbers:** four circuits of 3 branches = 12 x (6.8 ohm 1.5 W 2512, Stackpole RPC2512JT6R80, + 2.2 nF 2 kV **X7R** 2220, KEMET C2220C222KGRAC7800), i.e. 6 per bridge: SNBP0/SNBP1 (R19-R21, R28-R30) and SNBS0/SNBS1 (R31-R33, R37-R39) (power sheet 1; UG Fig. 22).
  - **Sensing:** 4 x LEM HO 120-NP-0100 (primary DC at P-, primary AC at PB, secondary DC at S-, secondary AC at SA) with AD8616 buffers (power sheet 2; the S- channel is inverted in hardware, "invert in software"), AD8618 conditioning (control sheets 11-12); DC voltages by 2 x AMC3330QDWERQ1 behind 6 x 1 Mohm + 5.62 kohm dividers (sheet 10).
- **Checked against the project** (`sim/dab_devices.py`, `sim/out/dab_design/dab_spec.json`): module, gate driver, sensors, snubber network, DC-link banks and NTC read-out match; the bias module is the CRD's UCC14141-Q1 on 12 V, the project's UCC14241-Q1 on 24 V is a deliberate change (D-016). Three differences: the HF capacitors are film (5040), 10 + 13, whereas the project models 10 ceramic capacitors per bridge with ESR 10 mohm / ESL 1 nH (assumed); the fitted turn-on resistor is 0.91 ohm, whereas the guide (Table 11) and the project say 1 ohm; the CRD snubber capacitors are X7R, the project's own network uses C0G.
- **Firmware** (separate package V1.1.0, supplied by the owner on 2026-10-05, unpacked in `firmware/`; the "no firmware" and "access terms unconfirmed" notes here predate it): an **open-loop starting point** — a single phase shift typed into the GUI, no current or voltage loop, no flux balance, and only 3 of the 8 driver fault lines reach a latched trip; read statically in [FIRMWARE-NOTES.md](FIRMWARE-NOTES.md), lessons in `docs/requirements/REFERENCE-LESSONS.md` §6 (D-071).
- **Informs:** DAB-D60 (S-3, DAB-01..09), transformer spec (DAB-06), GDRV (ECO-05).
- **Limitation (roadmap):** 900 V max port vs our 590-950 V DAB-10; operating map, transformer, controls and firmware are ours (firmware access terms unconfirmed).
- **Files:** user guide PRD-10001; `crd60dd12n-gmb_design-files.zip` (six nested ZIPs: cold plate, STEP, Altium, BOM, Gerber, Schematic; 65 MB); in `design-files/`: the schematic PDFs, assembly BOM xlsx, cold-plate drawings (PDF) and the two small cold-plate STEP files. No PLECS model and no firmware in the package.

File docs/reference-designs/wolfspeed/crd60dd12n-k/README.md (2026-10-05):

# CRD-60DD12N-K - 60 kW three-phase interleaved LLC DC/DC converter, unidirectional (Wolfspeed)
Three interleaved half-bridge LLC legs with two discrete 1200 V SiC MOSFETs per position (C3M0040120K, or C3M0032120K
for the high-efficiency version, TO-247-4), six transformers and six full-bridge SiC Schottky rectifiers (C6D20065D)
that are linked in series or in parallel for the output range; TMS320F28377D controller with closed-loop firmware and a
CAN GUI; forced air. **It is not a dual active bridge** and it cannot reverse power. The folder name `crd60dd12n-k`
follows the firmware package; Wolfspeed's part number is CRD-60DD12N-K. All figures below are Wolfspeed's, from user
guide PRD-07229 Rev. 1 (March 2023), cited by PDF page; nothing here is ours or re-measured.
- **Native ratings** (Table 2 p12, Tables 1a/1b p10): input 650 / 800 / 870 V (min / typ / max), 94 A; output 200-500 V
  with the rectifiers in parallel (200 A; 130 A in the two-phase full-bridge mode used below 250 V) or 500-1000 V in
  series (100 A); 60 kW; 120-250 kHz; output ripple ±2 %; power density 4.83 kW/L (p8). Measured efficiency
  (C3M0040120K version, Table 2): peak 98.5 % (850 V in, 708 V / 34 A out, series), full load 96.2-98.3 % depending on
  the voltages; tables of 20-100 % load on p41-46.
- **Operating concept** (p10-11, p27): the converter is the DC/DC stage of a unidirectional off-board charger; the PFC
  front end is expected to move the input bus with the battery voltage so that the LLC stays near its resonance ratio
  (output = 0.411 x input in parallel, 0.822 x in series for 660-840 V of bus); the output set-point is accepted only at
  the band edges (650-660 V and 840-870 V). Below 250 V output the controller restarts as a two-phase full bridge with
  combined frequency and phase-shift control. Not for direct battery connection: no charging algorithm (p8, p12).
- **Power stage** (p25): input film capacitors (4), output 12 film + 3 electrolytic capacitors; six transformers on
  three-leg gapped PQ6562 ferrite cores, 12:10:10; resonant tank per phase L_m 30 µH, L_r 7.5 µH, C_r 102 nF
  (f_r ≈ 182 kHz, calculated); a current transformer per resonant tank; two MOSFETs (Q64, Q65) balance the output
  capacitor halves in series mode at no or light load. No inrush limiter on either port (p38).
- **Gate drive and control** (p25-26): UCC5350MCQDQ1 drivers (Miller clamp, no desaturation detection), each on a RECOM
  R15P21503D isolated supply (+15 / −3 V); the control board is referenced to the input DC−; output voltage and its
  OVP / UVP signals cross to the controller through optocouplers; a 14.5 V auxiliary board makes four isolated rails
  (Table 4). Measured dead time at the gates 137 / 153 ns (Table 18 p59).
- **Protections** (Table 6 p34): output OVP > 1050 V (series) / > 550 V (parallel); input OVP > 890 V, UVP < 600 V;
  output short < 300 V (series) / < 100 V (parallel); resonant-tank OCP 120 A peak; power limit 60 kW ± 1.5 kW;
  current limit 100 / 133 / 200 A ± 1.5 A by output range. Tank OCP and short-circuit protection are described as
  one-shot protections that need a system reset - the firmware clears them with an OFF command (FIRMWARE-NOTES §4.3).
- **Communication** (p27-29, p59-62): CAN 2.0B at 125 kbit/s with 29-bit identifiers; one control frame (mode, on / off,
  power, voltage, current), periodic status and telemetry every 0.5 s and 3 s; the C# GUI needs a GCAN USBCAN-I adapter.
- **Firmware and GUI package** (supplied by the owner, unpacked in `firmware/`): CCS project V1.00 for the F28377D
  (linked 2023-03-13) with full source, and the C# GUI source and binaries written for the 30 kW predecessor
  CRD-30DD12N-K. Read and summarised in [FIRMWARE-NOTES.md](FIRMWARE-NOTES.md).
- **Informs:** the DAB-D60 and PCS-P125 firmware requirements through its protection classes, recovery rules,
  calibration storage, start inhibits and service interface (REFERENCE-LESSONS §6); the PCS ↔ DC/DC coordination idea of
  a bus that follows the battery. It does **not** inform the DAB modulation law, power reversal, flux balance or
  parallel-branch sharing.
- **Limitation:** LLC, unidirectional, diode output stage, 650-870 V input (our DAB port 1 is 590-950 V); discrete
  Wolfspeed devices and a resonant tank that are not ours; a laboratory evaluation board "not designed to meet any
  industrial, technical, or safety standards" (p1).
- **Files:** user guide `crd60dd12n-k_user-guide_prd-07229.pdf` (plain download from assets.wolfspeed.com on
  2026-10-05, link from the product page https://www.wolfspeed.com/products/power/reference-designs/crd-60dd12n-k/ -
  the address without the hyphen after "crd" returns 404); the firmware / GUI zip and its unpacked folder. See
  SOURCES.csv. The design-files archive (https://assets.wolfspeed.com/uploads/2023/03/crd-60dd12n-k_all_design_files.zip:
  main, controller, driver, auxiliary-power and resonant-capacitor boards) was not fetched.
- **Related, not filed:** "Design Challenges and Considerations of Wolfspeed 60kW LLC Converter" and the 60 kW LLC
  marketing brief (both linked from the product page); the 30 kW predecessor CRD-30DD12N-K (user guide PRD-05777).

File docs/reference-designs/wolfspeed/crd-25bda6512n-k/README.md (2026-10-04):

# CRD-25BDA6512N-K - 25 kW bidirectional three-phase T-type inverter / PFC (Wolfspeed)
One board, three T-type legs: C3M0032120K (1200 V, 32 mohm, TO-247-4) high and low, two C3M0025065K (650 V, 25 mohm, TO-247-4) in common drain as the middle switch; LC output filter; TI UCC5350MC drivers; TMS320F280039C on a TMDSCNCD280039C control card. All figures are Wolfspeed's: user guide PRD-08613 Rev. 2, Oct 2024 ("UG pN" = printed page), schematic rev 3.0, May 2024 ("sheet N" = Altium sheet number, x.1-x.3 = phases A-C), BOM rev 3.0 ("BOM line N" = its Line #). Nothing re-measured here; the firmware is not on file (UG p28: on request).
- **Informs:** the DC-to-AC product PCS-P125 (REQUIREMENTS section 8, AC-01..03; decision D-053) - the nearest published reference to it; cross-checked in `sim/pcs_crosscheck.py` -> `sim/out/pcs_design/crosscheck_wolfspeed.md`. Magnetics rows in `sim/data/reference_magnetics.csv` (REF-2, MAG-1).
- **Ratings** (UG Table 1 p10-11): DC 670 / 800 / 900 V (the table prints "Vrms" for DC - a typo); AC 380 / 400 / 480 V L-L (480 V derated at low line); 36 A rms at 800 V / 25 kW; 25 kW in both directions; 50 / 60 Hz; 60 kHz (programmable 47-60 kHz, p11); 320 x 235 x 50 mm, > 6 kW/L. Claimed: inverter 99 % peak at 40 % load and 98.5 % at full load (800 V, 400 V); PFC 99.25 % peak at 480 V, 98.5 % full load.
- **Tested conditions** (UG p32-41): inverter open loop (Lab 2) and closed current loop (Lab 3) from a DC source into a three-phase resistive load through an external Schaffner FN3256H-64-34 line filter (Fig. 26 p32), Yokogawa WT5000; PFC from a three-phase AC source into a DC load (Labs 5-7). the guide states that the unit was never tested grid-connected (p10); the grid-connected Lab 4 exists in the firmware, untested, gains not tuned (p33). The 15 V auxiliary (1.5 A) and the fans (12 V, 6 A total) come from external supplies (p30-31), so the measured efficiencies exclude drive, control and fan power. No reactive-power (low power factor) operation is described or tested.
- **Topology and devices** (UG 3.1 p12; sheet 2.x; BOM lines 55-56): T-type NPC, one device per position - 6 x C3M0032120K, 6 x C3M0025065K, 12 devices. Common-drain middle pair so that the high-side switch and one middle switch share the phase-node bias supply: 5 isolated bias supplies instead of 7 (UG p19-21). One heat sink per phase (Boyd 780453B extrusion, Max Clip MAX03NG), 1200 V and 650 V devices alternated for thermal coupling, 1 mm AlN insulators (UG 3.6 p15-16); the heat sinks are tied to the DC midpoint by 0 ohm links (sheet 2.x R25/R61). Wolfspeed's own loss simulation of SiC against a 24 kHz IGBT T-type: 275 W against 287 W at 25 kW, inverter mode (Table 2 p13).
- **Switching frequency and modulation:** 60 kHz; third-harmonic-injection PWM in inverter mode (UG p10); modulation index set by TINV_vdInvRef_pu in open loop (p33). Dead time and midpoint control are in the firmware, not on file.
- **DC link** (BOM lines 1-3, 61; UG p25; sheets 1 and 2.x): 8 x KEMET ALA8DD471EE500 (470 uF, 500 V snap-in aluminium electrolytic), 4 from DC+ to the midpoint and 4 from the midpoint to DC- = 1,880 uF per half, 75 uF per kW per half; the cans see 0.90 of their rating at the 900 V maximum. Per phase at the devices: 2 x TDK B32774D0205K000 (2 uF, 1100 V film, C9/C10) and 2 x KEMET CKC21C104 (0.1 uF, 650 V C0G 2220, C11/C12), one of each per half. 24 x 200 kohm 2010 resistors (R1-R24) across the bank for balance and discharge. Nothing else holds the midpoint: no balancing circuit; the modulation does it and a firmware limit trips it (Table 3).
- **Filter magnetics** (UG 3.4 p14-15, Fig. 3 p13, Fig. 5 p15; BOM lines 10, 46, 50, 63; sheets 1 and 2.x): LC filter, no grid-side inductor. Per phase a converter-side choke and 10 uF X2 film (TDK B32926C3106K000, 305 VAC, C22) in series with 0.68 ohm 7 W (TE SQMW7R68J, R26), in star; the star (YCAP) returns to the DC midpoint through C21 - 2.2 uF on sheet 1, "CAP FILM 0.1UF 440VAC" (WIMA MKX14W31005B00KSSD) in the BOM; the two disagree. Choke: BOM line 46 "Line Choke, 125uH, 100kHz, 6.5mOhm DCR" (L1_1..3, no maker, no part number); line 50 "Inductor, 131uH, 20kHz, 7.5mOhm DCR" (L5_1..3) is drawn in parallel with L1 on sheet 2.x, but the photograph (UG p28) shows one round-wire toroid per phase - we read L5 as an alternate footprint. The guide's procedure gave L_INV 102 uH and C_DM 24.9 uF (25 kW, 50 Hz, 64 kHz, 230 V); only 10 uF is fitted because the on-board filter is meant for nominal noise suppression, not EMI compliance - a separate EMI board was designed to IEC 61000-6-3 (details on request). Choke weight 700 g per phase at 64 kHz against 1,600 g for a 24 kHz IGBT design (Fig. 3). Constraints: height <= 40 mm, choke <= 120 C, minimum volume and loss, area-product method with powder-core design references (UG p15 and refs [8]-[9]). **Not given:** core, material, gap, turns, wire, loss (offered on request through the Wolfspeed forum). Bias magnetics: 5 x Wurth 750320528 push-pull transformers (interwinding capacitance about 9 pF, which the guide calls high for EMI and suggests an LLC bias supply for new designs, UG p20) and 5 x Wurth 744212820 82 uH common-mode chokes on the bias outputs (L3, L13, L14).
- **Gate drive** (UG 3.3 p14; sheets 2-8; BOM lines 12, 30-33, 48, 67-69, 87, 101-105): 12 x TI UCC5350MCDWVR (5 A / 5 A, active Miller clamp, UVLO, no desaturation input), one per device. PWM through SN74LVC126A buffers whose four output enables take PWM_EN (10 kohm pull-down: disabled by default; outputs pulled down), then 100 ohm / 330 pF at IN+. Bias per supply: SN6507 push-pull driver, 750320528 transformer, BAV70 rectifier, 82 uH common-mode choke, MMBT3904 with a 19 V zener as series regulator, a 3.3 V zener split -> +15 / -3.3 V (Fig. 1: "+15V/-3V"); 10 ohm + 1 uF filters per driver rail (the BOM lists these resistors as 4.7 ohm). Per device (sheet 2.x): turn-on 5.1 ohm (R40), turn-off 5.1 ohm in parallel with 5.1 ohm + SM5819 Schottky (R39, D3), 1 ohm in the Kelvin-source return (R41), 10 kohm + 1 nF gate-source at the pins, the clamp pin straight to the gate. **No desaturation or any other device-level short-circuit protection.**
- **Current and voltage sensing** (sheets 10, 12-16; BOM lines 106-109, 113): inductor current per phase by Allegro ACS733KLATR-65AB-T (isolated Hall, 1 MHz, 20 mV/A, 1.65 V at 0 A) between the choke and the filter capacitor, conditioned by an OPA4340 (U13); its FAULT output (threshold set on VOC by R123/R125) goes to the control card as Iocp. DC bus and midpoint through 6 x 1 Mohm strings each into an OPA2388 (U6); phase voltages through 6 x 1 Mohm 0.1 % strings per phase into an OPA4340 (U5); heat-sink temperature by an LMT87 per phase (NTC header option) and ambient by an LMT87-Q1; REF2033 for the 1.65 V offset. The current direction is calibrated in firmware per mode (UG p23).
- **Protection and where each trip lives** (UG 5.3 Table 3 p30; sheets 3, 11; BOM lines 45, 100): DC over-voltage > 900 V, midpoint over-voltage > 450 V, AC under-voltage < 50 V, phase over-current 40 A rms - all firmware limits (TINV_* variables); the over-current trip is one-shot and needs a reset. In hardware only: the ACS733 FAULT line (whether it reaches a trip-zone input depends on the firmware), driver UVLO, the PWM_EN buffer enable, and per phase a 40 A relay (American Zettler AZ2150-1A-12DEF) bypassing two 1 ohm NTC inrush limiters (Ametherm MS351R040) in series. No fuses, no DESAT, no discrete comparators.
- **Auxiliary supply** (UG p30-31, sheet 9): 15 V on J3 from a lab supply or from Wolfspeed's optional HV SiC auxiliary flyback board (PS1, fed from DC+ / DC-; not in the design files - the product page names a C2M1000170J in it); L7805 (5 V) and TLV1117 (3.3 V) linear regulators; relays and fan switches (2 x CSD18534) from 15 V; CAN through ISO1050, untested (UG p24).
- **Controller card** (UG 3.5 p15, sheet 15): TMS320F280039C on TI's TMDSCNCD280039C card in a 180-pin HSEC socket made of J13 (pins 1-120) and J14 (121-180); Fig. 1 still names F28379D. Code Composer Studio project on C2000Ware DigitalPower SDK 4.04, labs 2-7, no GUI; the guide points to TIDA-01606 for the firmware structure (UG p29). The card does PWM, the current loop (and the voltage loop and PLL in PFC mode) and every protection limit.
- **Measured efficiency** (UG Table 6 p42, Fig. 32 p43; Tables 8-10 p45-49): inverter 99.27 % peak (670 V, 7 kW), 99.00 % at 7-11 kW and 98.45 % at 24.85 kW (800 V / 400 V), 98.35 % at 25.98 kW (800 V / 380 V); at 900 V the source limited the test to 17.7 kW. PFC 99.28 % peak (480 V, 40 %), 98.51 % at 25 kW (400 V); THD 2.7 % and PF 0.999 at 25 kW, 20 % and 0.90 at 1.27 kW. The tables are not fully consistent: at full power Table 6's power columns imply 0.1-0.2 % less efficiency than its efficiency column, and Table 8's input power at 60-70 % load is lower than the output power.
- **Thermal** (UG 6.3 Table 12 p53): three fans of about 8 W, case temperature by thermocouple at 25 kW, 60 kHz: inverter 58.2 C (1200 V) and 55.5 C (650 V) MEASURED; junction 70.5 / 60.6 C CALCULATED from 28.5 / 11 W calculated losses and R_th(j-c) 0.44 / 0.46 K/W; PFC up to 65.3 C case / 72.4 C junction. Derating target 135 C; ambient not stated.
- **Stated limitations:** evaluation hardware, "not designed to meet any industrial, technical, or safety standards" (UG p3); not tested on the grid; nominal EMI filtering only; control card taller than the 40 mm height target (p15); CAN untested.
- **Files:** user guide; `crd-25bda6512n-k_design-files.zip` (21.6 MB: Altium project, SchDocs, PcbDoc, BomDoc and PCB layer PDFs - left inside the zip, no layout work in this project); in `design-files/` the schematic PDF and the BOM xlsx. The C3M0025065K data sheet was filed with this review (`docs/datasheets/power-semiconductors/`). See SOURCES.csv.

**What we take from it**
1. The per-device gate network for paralleled TO-247-4 parts: diode-steered asymmetric R_G, a 1 ohm Kelvin-return resistor, 10 kohm + 1 nF at the pins, the Miller clamp straight to the gate.
2. For any T-type variant, the common-drain middle switch: 5 bias supplies serve 12 channels.
3. The same per-unit filter choices as PCS-P125 - L for about 25 % peak-to-peak ripple of the peak current, C_f 2 % of base - and one published inductor mass (700 g for 125 uH / 36 A at 64 kHz) that calibrates our area-product cost check.
4. A measured efficiency to test our loss model on: devices plus choke DCR explain about two thirds of the measured loss at 25 kW; the rest, about 0.5 % of the power, is filter, relay, PCB and capacitor loss that a budget must carry.
5. What not to copy: every trip in firmware and no desaturation detection (D-050 keeps the discrete layer); 500 V electrolytics at 0.9 of rating; nominal EMI filtering; a midpoint bank that is only ever tested near unity power factor.

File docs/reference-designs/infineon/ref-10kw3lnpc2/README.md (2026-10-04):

# REF-10KW3LNPC2 - 10 kW three-phase three-level NPC2 inverter board (Infineon)
Modular: NPC2 main board with IGBT7 H7 (IKZA40N120CH7 1200 V + IKZA40N65EH7 650 V), 1ED3240MC12H EiceDRIVER on three 4-channel boards (ISODRV-3240C4P15N05-1), isolated aux PB-APS-24V-5V ISO; XMC7200 control board REF-CLBXMC7PEC sold separately.
- **Native ratings** (UG-2024-09, section 1.2, typical/maximum columns): input 650 V typ / 850 V max DC (board warns DC-link potential up to 1000 VDC); output 380 V typ / 400 V max L-L rms, 15.2 A, 10 kW; 24 kHz; 50-65 Hz.
- **Informs:** GDRV alternate (EiceDRIVER, DESAT concepts; ECO-05) and IGBT/NPC2 cost benchmark.
- **Limitation (roadmap):** scale to 100-230 A class, 950 V, production firmware; 24 kHz IGBT AC-side stage, out of scope here.
- **Files:** user manual only. A REF-10KW3LNPC2Q (QDPAK SiC variant) manual exists on infineon.com, not fetched.

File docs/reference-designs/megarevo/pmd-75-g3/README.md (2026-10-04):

# Megarevo PMD-75-G3 - 75 kW non-isolated bidirectional DC/DC (MPPT) module
Competitor target for PV-P75/100/110 (REQUIREMENTS section 2): one centralized MPPT, buck and boost between two 250-1000 V ports.
- **Native ratings:** see `spec.md` (verbatim web table, retrieved 2026-10-04): 75 kW rated / 82.5 kW max; 250~1000 V, 550~950 V full load, 135 A on both ports; 99 % max efficiency; forced air; 550*444*133 mm, 30 kg; 485/CAN + BMS; non-isolated.
- **Datasheet:** `pmd-75-g3_datasheet_v1-0.pdf` carries the identical table (checked by script) plus marketing claims (MPPT efficiency up to 99.99 %, protection response <= 3 ms, 2.55 MW/m3).
- **Versus roadmap "MPPT target":** no published number differs; details at the top of `spec.md`.
- **Limitation:** public figures only - no circuit, topology, device or loss data; the teardown items in the roadmap stay open.

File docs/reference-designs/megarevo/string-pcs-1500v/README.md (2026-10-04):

# Megarevo MPHV 1500 V string PCS (145–250 kW)

Datasheet V1.1, link supplied by the owner on 2026-10-04. It is an AC/DC product (three-level string PCS, IP66,
≤ 100 kg, 99 % maximum efficiency, DC contactor + soft-start, DC and AC EMI filters, LCL filter, AC relay, type II DC
surge protection, Ethernet / RS-485 / CAN) — not a DC/DC module — and is on file as the **price benchmark**:

> The owner states that the 228 kW version sells for **1,500 USD**, i.e. about **6.6 USD per kW** for the complete unit.

That figure, not the marketplace listings in `gen/data/market_prices.csv` (22–74 USD/kW), is the cost level this
project has to be measured against. See `docs/requirements/COST-REVIEW.md`.

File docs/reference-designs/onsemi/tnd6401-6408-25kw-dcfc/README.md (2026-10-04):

# onsemi 25 kW SiC DC fast-charger design series, TND6401/D ... TND6408/D
Eight-part series for a bidirectional 25 kW charger on SiC power integrated modules (kit SEC-25KW-SIC-PIM-GEVK): 1 structure and specs, 2 solution overview, 3 PFC, 4 DC-DC (DAB), 5 control algorithms and modulation, 6 gate drive, 7 auxiliary supplies for 800 V chargers, 8 thermal.
- **Ratings (web-search summaries of onsemi pages; NOT verified against PDFs):** 25 kW over 500-1000 V output, current limited to 50 A below 500 V; six-switch active rectifier plus phase-shift DAB; for 400 V and 800 V batteries.
- **Informs:** engineering checklist for DAB-D60 (parts 4-5), GDRV (part 6), AUX-HV (part 7), thermal (part 8).
- **Limitation (roadmap):** engineering checklist, not a plug-in design (P2).
- **Status: all eight documents are MANUAL** - onsemi's Akamai edge answers HTTP 403 to curl for every onsemi.com PDF path (retried once on 2026-10-04 with plain curl: still 403); not circumvented. Open in a browser; only TND6401's direct link is search-confirmed, the others are pattern links (see SOURCES.csv).

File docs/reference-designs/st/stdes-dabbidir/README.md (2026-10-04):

# STDES-DABBIDIR - 25 kW bidirectional dual-active-bridge DC/DC (ST)
ACEPACK 2 SiC power modules, STM32G474RE control, 100 kHz; STSW-DABBIDIR firmware exists (not fetched). Roadmap: "exceptionally complete 25 kW DAB manufacturing package".
- **Ratings below are NOT from a downloaded PDF** (st.com resets every curl connection, see below); they come from web-search summaries of data brief DB4879: 800 V nominal in, 400 V nominal out, 25 kW, 100 kHz, 98.4 % peak efficiency. Verify when you open the PDF.
- **Informs:** DAB-D60 control cross-check (DAB-08: soft switching, current/voltage loops, soft-start, protections); STGAP2SICS gate-driver alternate (ECO-05).
- **Limitation (roadmap):** a reproducible 25 kW, 800-to-400 V reference; DAB-D60 is 60 kW with 590-950 V / 400-900 V ports.
- **Status: all five documents are MANUAL** - data brief DB4879, user manual UM3198, test report TN1435 (extra), schematic v2.0, BOM v2.0. st.com's edge closes the HTTP/2 stream for non-browser clients (retried once on 2026-10-04 with plain curl: curl exit 92 again; not circumvented). Direct links are in SOURCES.csv; open them in a browser.

## Firmware package (supplied by the owner)
- `stsw-dabbidir.zip` = ST's STSW-DABBIDIR (manual download from st.com, 2026-10-04, 232,325 bytes), unpacked in `stsw-dabbidir/`: `STSW_DABBIDIR.hex`, `STSW_DABBIDIR.out` (ELF with debug info), `STSW_DABBIDIR.sim`. Binaries only, no source; registered in `SOURCES.csv`. This supersedes "firmware exists (not fetched)" above.
- Static inspection only (nothing was executed): [FIRMWARE-NOTES.md](FIRMWARE-NOTES.md) - target STM32G474 (Cortex-M4F), IAR EWARM 9.20.2, HRTIM PWM at 100 kHz, control structure, decoded parameters, what the binary cannot tell, and a side-by-side with our DAB control (DAB-08, REF-1). The parameters are also in `sim/data/st_dab_firmware_params.csv`.
- The `.sim` is a different build from the `.hex`/`.out` (older time stamp, 2022-11-29; dead time 600 ns vs 400 ns); the notes use the `.hex`/`.out` values.

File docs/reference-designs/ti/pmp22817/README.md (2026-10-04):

# PMP22817 - automotive SPI-programmable gate driver and bias supply, UCC5870-Q1 + UCC14240-Q1 (TI)
One-channel 800 V traction driver: UCC5870-Q1 (30 A peak, SPI-programmable protection, DESAT, CLAMP, VCE active clamp, ASC, six analog inputs) with a UCC14240-Q1 isolated bias module (+15/-5 V) and an LM5156-Q1 SEPIC making 24 V from a 6-42 V battery. TI: design not warranted production-worthy (schematic notice).
- **Native ratings** (TIDT256A Rev A Mar 2022 p.1, p.5, p.14, p.20; TIDMA63 Rev B p.1): bias and driver isolation 3 kVrms for 1 min, stated as sufficient for 800 V DC buses; +15/-5 V (69.8 kohm/10.0 kohm, 10.0 kohm/10.0 kohm); gate R 3 x 4.3 ohm per side; SEPIC 24 V / 130 mA at 445 kHz or 2 MHz; bias 1.6 W at 40 kHz into 100 nF -> UCC14240 73 degC at 21-23 degC ambient, no fan.
- **Informs:** GDRV bias module and barrier (D-016, UCC15241-Q1 option), bias start-up and self-heating references for the gen/gdrv.py design check, ECO-05 protection set (ASC and active clamp rejected for a DC/DC).
- **Limitation:** testing is about the SEPIC; the report defers UCC14240/UCC5870 performance to their datasheets (p.5) - no DESAT, fault or power-device test. The drawn active clamp (2 x SMCJ300A, 300 V stand-off each) cannot sit on the claimed 800 V bus; the BOM gives the UCC14240 as > 2.5 kVrms against 3 kVrms on p.1; p.5 misnames the bias part UCC14020-Q1. SPI driver is TI-only (D-031).
- **What we take from it:** +0.5 V start-up overshoot of the bias output (p.19) and about 32 K/W bias self-heating (p.14) for our design checks (detail in docs/requirements/REFERENCE-LESSONS.md).
- **Files:** test report TIDT256A, schematic TIDMA63 (Rev B), BOM TIDMA64 (Rev B). Not fetched: assembly drawing, PCB layout, Gerber/CAD (layout out of scope).

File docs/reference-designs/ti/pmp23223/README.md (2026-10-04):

# PMP23223 - smart isolated gate driver with bias supply, UCC21732-Q1 + UCC14240-Q1 (TI)
One-channel isolated driver board for a SiC/IGBT switch or module: UCC21732-Q1 (10 A, DESAT on the OC pin, internal two-level turn-off, CLMPE external Miller-clamp FET, AIN/APWM temperature sense) fed by a UCC14240-Q1 isolated bias module from 21-27 V. TI: design not warranted production-worthy (schematic notice).
- **Native ratings** (TIDT283 May 2022 p.1, p.3, p.9-10; TIDMAI7 Rev A p.2; TIDMAI8 p.1): VIN 21-27 V / 500 mA; rails +18/-4 V (VDD-VEE 77.7 kohm/10.0 kohm, COM-VEE 13.2 kohm/22.0 kohm); > 1.5 W bias; 10 A source/sink; 2.2 ohm on and off; DESAT 5.4 V / 130 ns through 2 x STTH112A (disabled as shipped, R1 DNP); Si2318CDS clamp FET on CLMPE.
- **Informs:** GDRV (ECO-05): Miller hold of the paralleled PV gates (D-028), bias-rail programming (D-016, PV +20/-4 V), AIN/APWM path of the DAB module NTC; driver selection under D-031.
- **Limitation:** tested only into a 100 nF capacitor - no power device, no double-pulse, short-circuit or fault-timing data. Bench APWM points (80.33 % at 0.6 V, 40 % at 2.5 V, p.8-9) sit 8-10 duty points below the line TI quotes (88 % to 10 % over 0.6-4.5 V); p.10 states about 1.5 W at 35 kHz while its own equation gives 1.78 W; thermal ambient not stated.
- **What we take from it:** external N-FET Miller clamp from a CLMPE-type pin as the candidate fix for D-028, and a two-point AIN/APWM check before the DAB NTC trip is trusted (detail in docs/requirements/REFERENCE-LESSONS.md).
- **Files:** test report TIDT283, schematic TIDMAI7, BOM TIDMAI8. Not fetched: assembly drawing, PCB layout, Gerber/CAD (layout out of scope).

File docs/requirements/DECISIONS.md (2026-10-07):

# Decision register

One row per decision. Never delete a row; supersede it with a new one.

| ID | Date | Decision | Why | Status |
|---|---|---|---|---|
| D-001 | 2026-10-03 | Scope = DC-DC modules (PV-P75/100/110, DAB-D60) + shared ecosystem boards; schematic + BOM + simulation only | User instruction; see REQUIREMENTS.md §1 | Frozen |
| D-002 | 2026-10-03 | Toolchain: Python 3.12 venv (numpy, scipy, matplotlib), KiCad 10 `kicad-cli`, ngspice-46. Schematic writer = `schgen.py` / `symlib.py` / `sexpr.py` copied from the Meter project | Already proven in-house against kicad-cli 10; no new dependency | Frozen |
| D-003 | 2026-10-03 | Footprints are not assigned. Each part carries a `Package` field only | PCB layout is out of scope | Frozen |
| D-004 | 2026-10-03 | Controller = TMS320F28388D on a common `CTRL-C2000` card | Roadmap §"Common control card" | Frozen |
| D-005 | 2026-10-03 | Gate driver = TI UCC21710 | Roadmap §"Auxiliary supply and gate drivers" | Frozen |
| D-006 | 2026-10-03 | Precharge = resistor + contactor | Roadmap §"DC-link and precharge" | Frozen |
| D-007 | 2026-10-04 | PV cell topology = **2-level four-switch buck-boost with 1700 V SiC**: 2 × MSC035SMA170B4 per switch position (8 per cell), 4 gate drivers, common negative rail between the ports. Detailed design point (`sim/pv_design.py`, chosen for ≥ 99.2 % at every full-power corner): 32 kHz, one 224 µH inductor (Kool Mµ MAX E-cores), 2 × 45 µF film per port per cell, +20/−4 V gate drive (the bias module cannot regulate 25 V within its limit, so −4 V instead of −5 V), hardware trips 72.4 A and 1100 V; calculated peak efficiency 99.61 %, corners 99.21–99.37 %, hottest junction 85 °C at 45 °C inlet. Runner-up: 3-level flying-capacitor with 1200 V SiC (16 devices, 8 drivers) — it only wins above 99.4 % full-load efficiency. Fallback if 1700 V cosmic-ray data force a lower DC limit: the same topology with 2000 V devices (IMYH200R024M1H) | Gate-0 study `sim/pv_tradeoff.py` → `sim/out/pv_tradeoff/report.md`: lowest cost at every efficiency level it can reach, 99.04 % at the worst full-power corner, no balancing loop. 2-level with 1200 V devices is excluded by the voltage rule (0.83 × V_DSS continuous) | Frozen. Open risk: no vendor FIT-vs-voltage curve for the 1700 V part is on file |
| D-008 | 2026-10-04 | PV-20 (ambient −30…+60 °C, derate above 45 °C) re-tagged from assumption to sourced | The PMD-75-G3 page and datasheet state it for the PMD itself (`docs/reference-designs/megarevo/pmd-75-g3/spec.md`) | Frozen |
| D-009 | 2026-10-04 | Six published PMD-75-G3 rows that the roadmap does not carry are recorded as *candidate* requirements PV-C1…C6 (REQUIREMENTS.md §2b) | They belong to the product the roadmap names as target, but adopting them is the owner's call | **OPEN** — owner to adopt or drop |
| D-010 | 2026-10-04 | Inter-board connector contracts fixed in `gen/interfaces.py` (CELL 40-way, PORT 26-way, SYS 80-way, GW 10-way); gate commands and fault lines cross boards as RS-422 pairs; the control card exposes all 32 ePWM outputs as 4 ports × 8 | Lets boards be designed in parallel without pin mismatches; 4 × 8 covers a 2-level or 3-level cell and the DAB without redesign | Frozen |
| D-012 | 2026-10-04 | Hardware safety chain is dual-channel. Channel A (E-stop A, 24 V UV, spare loop, watchdog) drives `GATE_EN` and the first contactor-supply switch; channel B (E-stop B, watchdog, separate parts) drives `CHB_OK`, which switches `+24V_GD` (the supply of every gate-driver bias converter) and a second contactor-supply switch | The first single-channel chain was drawn correctly but one stuck gate or one stuck E-stop input defeated it; the goal is no single point of failure | Frozen |
| D-013 | 2026-10-04 | Module 24 V system window = 21.6–26.0 V (24 V −10 % / +8 %), over-voltage cut-off between 26.10 and 26.45 V; AUX-HV regulates at 22.8 V so the cabinet supply carries the load when present | Fan (26.5 V max) and gate-drive bias module (21–27 V) limits: the first ±10 % window with a 27–28 V cut-off let a load run above its rating, so the window was tightened | Frozen (assumption — owner may change) |
| D-014 | 2026-10-04 | DAB-D60: n = 11:12, L = 6.5 µH (4.4 µH leakage + 2.1 µH external), Lm = 150 µH, triple-phase-shift modulation from a look-up table, firmware flux balance. Full power only inside the derating map of `sim/out/dab_design/derating_map.csv`; port 1 above 900 V is power-limited by the module's switching SOA | `sim/dab_design.py` | Frozen for schematic; assumptions DAB-10/11 are met only inside that map |
| D-015 | 2026-10-04 | DAB efficiency is reported twice: the loss model (peak 99.39 %, 98.69 % at 800/800 V 60 kW) and the same model scaled to Wolfspeed's measured reference data, which shows 2.5× the modelled loss (→ ≈ 97.6 % at 60 kW). DAB-04 is not claimed as met | Honesty boundary; the gap can only be closed on the bench | Noted |
| D-017 | 2026-10-04 | DAB-D60 stays at one CBB011M12GM4T per bridge (requirement DAB-02), with the risk stated: if the loss gap seen in Wolfspeed's own measurements is real, 60 kW is thermally sustainable at only 8 of 31 window points (junction would reach 198 °C if the extra loss is in the modules; a transformer hot spot of 395 °C if it is in the magnetics). The module NTC trip protects the hardware, so the consequence is derating, not damage. The quantified upgrade is two modules per bridge: 99.19 % at 800/800 V 60 kW, 95 % of window points ≥ 98.8 %, 92 °C junction in the pessimistic case | `sim/dab_design.py` pessimistic case and design-lever table | **OPEN for the owner** — choose 2 or 4 modules before hardware; the pessimistic derating map is the guaranteed envelope until bench data exists |
| D-019 | 2026-10-04 | Port protection for the 135 A port (PV-P75, DAB): 160 A gPV fuse on each pole, TDK HVC43-250A main contactor (bidirectional), resistor + relay precharge, fail-safe discharge, and a **hold-closed interlock**: above 382–442 A the contactor coil is held from the logic 24 V so that it never tries to break a current beyond its capability — the fuse clears first, even if the E-stop has cut the contactor supply. Result: no uncovered fault current from 162 A to 20 kA (one point at 420 A is marginal when three worst-case tolerances stack) | `sim/port_design.py` §6 | Frozen. Residual risks recorded there: a bus-capacitor dump into a terminal short may weld the contactor (16–25 kA peak against a 5 kA rating, fuses clear, weld detected on the auxiliary contact); loss of all 24 V during a > 450 A fault is a double fault |
| D-021 | 2026-10-04 | AUX-HV = single-switch DCM flyback at 65 kHz, UCC28C59-Q1 + C3M0900170J (1700 V), custom ETD29 transformer with triple-insulated wire, 22.8 V / 30 W, starts at 229 V, regulates 22.40–23.15 V over 200–1000 V, 84–87 % efficient, no heatsink. Input is a diode-OR of both ports on the PV module; **on the DAB module it is fed from port 1 only**, because a diode-OR between the two isolated ports would reduce their isolation to functional | `sim/aux_hv_design.py`, `gen/aux_hv.py` | Frozen |
| D-023 | 2026-10-04 | Independent reviews (three Opus design reviews, one integration review, a 1,348-pin audit) found 58 defects after every board already passed its own checks: 7 critical, 25 major, 26 minor. The critical ones: the Miller clamp on paralleled gates could not turn on; contactor coil suppression was bypassed (slow opening); the discharge resistor could be switched across a live port (reported by two reviewers); one shorted part could close a contactor without precharge; contactor feedback could not be read across the harness; the PV modules could never arm the safety chain (missing link plug). Separately, the control simulation found that a terminal short would destroy the SiC body diodes (D-027). All are assigned to board revisions; findings are in `gen/data/review_*.csv` and `gen/data/integration_findings.csv` | Review round | In progress |
| D-024 | 2026-10-04 | Contactor coil drive: every coil-current path has two independent switches (high-side feed from SYS-IO-AUX plus a low-side switch on the port board gated by the same line; the hold-closed path has its own high-side and low-side switch from two independent comparators), and the varistor directly across the coil is the only flyback path (≥ 50 V as TDK requires) | Review findings PA-01, PA-02, INT-03, CSR-05 | Frozen |
| D-025 | 2026-10-04 | Active discharge is inhibited in hardware while that port's main contactor is closed, is time-limited, and has a thermal cut-off on the resistor | Findings INT-01, PA-03: an E-stop during hold-closed or with a welded contactor put 430–810 W into a 100 W resistor | Frozen |
| D-026 | 2026-10-04 | SYS-IO-AUX connects the AUX-HV feed only when no cabinet 24 V feed is healthy, disconnects it if it is above the window, and keeps the fans off until firmware enables them. Contactor feedback lines are module-internal signals referenced to PELV GND | Findings INT-02, INT-08, INT-09, INT-10 | Frozen |
| D-028 | 2026-10-04 | Paralleled-gate turn-off on the PV cell: each device has its own PNP follower (ZXTP25040DFH) returning to a 1 µF capacitor on its own Kelvin pin, plus a 0.5 Ω Kelvin resistor; hardware dead time 191–511 ns. Independent ngspice check: no false turn-on anywhere in the envelope — the off device's die sees +1.42 V at the worst corner (1100 V, 72 A, 175 °C) against a 1.48 V minimum threshold, and +1.17 V at 1000 V / 60 A | Review finding PVR-01; `gen/gdrv.py` design_check and `sim/pv_design.py` DPT deck | Frozen. **Open risk:** the margin at the extreme corner is 0.06 V and rests on estimated loop inductance and ringing — first item for the double-pulse bench test |
| D-029 | 2026-10-04 | Module fan = Sanyo Denki San Ace 9GT1224P1S001 (−40…+85 °C, PWM + tach), one per cell, speed capped at 97 % (PV-P75) / 92.5 % (PV-P100/110) to stay at or under 65 dB(A). No derating from 25 to 60 °C, to 4000 m, or with one fan failed (nominal thermal model) | The first choice (ebm-papst 4414/2HHP) is rated only to −20 °C against PV-20's −30 °C. Only one qualifying fan was found, so there is no second source | Frozen |
| D-027 | 2026-10-04 | A reverse-clamp rectifier is fitted across each DC bank (DAB: one arm of an Infineon DD600N16K per port; PV: 8 × Vishay VS-60EPS16-M3 per bank, 16 per cell — one clamp per port still left 2.4 kA in each SiC device) so that a bolted terminal short, which rings the film bank negative, does not drive 8–15 kA through the SiC body diodes | Fault case found by `sim/pv_control.py`; confirmed for the DAB by `sim/dab_design.py` | Frozen |
| D-022 | 2026-10-04 | AUX-HV's 30 W covers the control card, system I/O, communications and gate-drive bias. It does **not** cover holding two main contactors (≈ 12 W) plus fans, so the module cannot run at power from AUX-HV alone: it boots, communicates, self-tests and shuts down in order. Full self-powered operation would need roughly 80 W | Budget in the requirement ECO-06 brief; raised by the AUX-HV design | **OPEN for the owner** — keep it as a bootstrap supply (current design) or size it for self-powered operation |
| D-020 | 2026-10-04 | The 180 A port needed by PV-P100/110 (4 cells) is **not** fully coordinated: with a 250 A fuse the HVC43 contactor is uncovered from 384 A to 20 kA. Options: a larger contactor (TDK HVC50-600B — its datasheet lacks carry and short-circuit data), or two 135 A port branches in parallel per port | `sim/port_design.py` §6 | **OPEN** — PV-P100/110 is the roadmap's second-generation product; PV-P75 is unaffected |
| D-018 | 2026-10-04 | Parallel DAB branches: no hardware carrier-sync line. Sharing = common reference over the CAN-B module bus + per-branch current loop (1 % error with ±5 % inductance mismatch). The system controller must cap total power at N_alive × P_branch,max and the PCS needs DC-current feed-forward (bus transient 19.5 V with, 65 V without, when one of two branches trips) | `sim/dab_control.py` | Frozen |
| D-016 | 2026-10-04 | Gate-drive bias = TI UCC14241-Q1 (reinforced, 1414 V DC working, certification still "planned" in its datasheet); Murata MGJ2 rejected (reinforced only to 150 V rms) | `gen/gdrv.py` design check | Frozen — certification status is a tracked risk |
| D-011 | 2026-10-04 | DAB-04 efficiency figures (99.2 % peak, > 98.8 % above 20 kW) are Wolfspeed web/support claims: the user guide PRD-10001 only documents 800 V → 800 V at 10–23 kW and lists Vin 700–900 V | Finding of the reference-library review | Noted — our own map comes from `sim/dab_design.py` |
| D-030 | 2026-10-04 | PV cell inductor current = LEM LA 150-P closed-loop transducer around a screened, insulated inductor lead, 20 Ω burden and a differential driver (20 mV/A, ±114 A linear, 0.52 µs). It replaces the 0.3 mΩ shunt + AMC3302 on the switch node | Review finding PVR-04: the isolated amplifier's ground sat on a node slewing 71–92 V/ns against a 95 V/ns minimum CMTI — no margin. Open: the LA 150-P has no published dv/dt figure (bench test) and 1.1 A offset, which firmware must re-zero while the gates are off | Frozen |
| D-031 | 2026-10-04 | Sourcing policy changed by the owner: cost-driving parts (switches, diodes, gate drivers, capacitors, contactors, fuses, sensors, magnetics materials) move to Asian — preferably Chinese — makers with documented qualification, checked on LCSC; TI C2000 stays. The Gate-0 topology choice (D-007, 2-level with 1700 V devices) and the DAB device choice (D-014, Wolfspeed module) are **re-opened** and re-run with the Asian device set and a cost model. Magnetics are verified with OpenMagnetics plus our own calculation and compared with the reference designs | Owner instruction (REQUIREMENTS.md §7, SRC-1…4, MAG-1/2, REF-1/2): the design has to compete with Chinese products on price without losing robustness | Frozen as policy; device and topology choices pending the studies |
| D-032 | 2026-10-04 | Insulation coordination frozen (`sim/insulation.py`): PV array, battery and DC bus are floating with insulation monitoring or one pole earthed, a first earth fault may persist; DC over-voltage category II at 1000 V; pollution degree 2 inside a closed electronics compartment with all HV boards coated, pollution degree 3 in the cooling-air path (only terminals, fuse bases and arresters there). HV to PELV = reinforced (8 kV impulse, 4400 V rms test); HV to PE = basic (6 kV); DAB port 1 to port 2 = basic at 1850 V DC. Heatsinks and the cold plate are earthed; the power devices sit on ceramic insulators with at least 5 mm overhang. Altitude: 2000 m is the claim once the listed failures are fixed; 3000–4000 m needs monitored arresters with an effective level of 4.0 kV or less at the terminals (reinforced then falls to 6 kV and the 8 mm isolator packages pass) — whether an arrester may be credited for reinforced insulation is **not verified against the standard text** | ECO-10; 132 barriers audited, 22 fail at 2000 m today (surge rating of AMC3302 / UCC12050, precharge relay, unspecified heatsink pads and magnetics insulation, choke and X-capacitor specs); standard tables transcribed from memory | Frozen as the design basis; standard values and the arrester credit to be confirmed against the purchased EN 62477-1 / IEC 62109-1 |
| D-033 | 2026-10-04 | Port source types: a port facing a battery rack or a stiff DC bus gets a battery-class fuse (ETI 200 A gBat), a battery-rated arrester (Raycap ProTec T2-1500DCGU-3Y with its own backup fuses) and two TDK HVC43 contactors in parallel; coordinated from 162 A to 30 kA at L/R ≤ 1 ms. The 180 A battery port (PV-P100/110) uses the same 200 A fuse with a firmware current limit of 180 A to 35 °C inlet falling to 136 A at 60 °C; the 135 A PV port is limited to 124 A at 60 °C by its fuse until a 200 A gPV link is coordinated. No Asian contactor, fuse or arrester had published data good enough to replace these (Hongfa: no auxiliary contact or 50–60 W coils; Sinofuse: no curves; Prosurge: no battery rating) | Review finding PA-06; supersedes D-020 (closed with the stated limit); `sim/port_design.py`, `port_spec.json` key `port_current_limit_vs_inlet_C` | Frozen; the Asian-sourcing gap on these three parts is recorded, not hidden |
| D-034 | 2026-10-04 | While the 24 V bus is fed from AUX-HV (no healthy cabinet feed), SYS-IO-AUX forces the fans, the gate-drive supply and the coil supply off in hardware and trips both safety latches; re-arming needs the firmware clear. Load on AUX-HV in that state 27.8 W (30.1 W for up to 200 s with two hold coils). The AUX feed has a 2.2 µF / 1 kΩ turn-on ramp: black start is one ramp of 0.4–1.5 s. Losing the cabinet feeds at full power lets the bus dip to 13.7 V: the control card reboots, the hardware latch state survives | AUX-HV does not limit a continuous load between 30 W and its 34–89 W trip, so a firmware error could overheat it (single point of failure); `gen/sys_io_aux.py` rev E, FMEA 75/75 | Frozen; hold-up for the control card is an open improvement |
| D-035 | 2026-10-04 | Isolated gate driver changes from TI UCC21710 to NOVOSENSE NSI6651ASC (10 A, DESAT, reinforced with VDE 0884-17 / UL 1577 / CQC granted, AEC-Q100 grade 1, about 3 USD on LCSC against 4.4 USD). The isolated bias supply is **not** settled: Mornsun QA modules are cheap but unregulated, have no power-good output and state no working voltage; TI UCC14241-Q1 (12.8 USD per channel) stays the documented option until a bias supply with a stated reinforced rating at 1100 V DC is chosen | SRC-1…4; `sim/data/asia_drivers.md` | Driver frozen; bias supply open |
| D-036 | 2026-10-04 | The isolated gate-drive bias supply stays TI UCC14241-Q1 (4.97 USD at 1 ku on ti.com; 12.8 USD single on LCSC). Mornsun QA243C-R3G / QA243CT-R4 are recorded as the cost-down option, to be adopted only with Mornsun's insulation report for an 1100 V DC working voltage | The Mornsun modules are unregulated (up to 15 % load regulation), have no power-good output and state no working voltage — only a 5 kV one-minute test and a typical partial-discharge level; at volume the price gap to the TI part is about 2 USD per channel, which does not justify an undocumented barrier (SRC-2, SRC-4) | Frozen; closes the open half of D-035 |
| D-037 | 2026-10-04 | Device sourcing rule for the re-run studies: every power switch position gets a primary and an alternate Asian maker and the design is done for the worse of the two. PV cell candidates: InventChip IV2Q170xxT4Z ("AEC-Q101 qualified" in the datasheet, own fab, no public price) and Sichain SG2M0xx170HJ (on LCSC, about 10 USD for the 20 mΩ part, no qualification statement). The cell stays 2-level unless the best 3-level candidate with 1200 V parts is more than 15 % cheaper per cell or no 2-level candidate meets the rules. DAB candidates: paralleled 1200 V TO-247-4 discretes (InventChip IV3Q12013T4Z, Sichain SG2M014120LJ) against Asian half-bridge modules | `sim/data/asia_devices.md`: Chinese 1700 V 20 / 40 mΩ parts exist, so the verified 2-level boards, control and magnetics can be kept. No Chinese maker publishes a reliability report or a short-circuit rating: the evidence level is the datasheet statement, and that is recorded as a risk | Rule frozen; the device choices follow from `sim/pv_tradeoff.py` and `sim/dab_design.py` |
| D-038 | 2026-10-04 | Design-to-cost targets (BOM at 1 k quantity, generated by `gen/cost.py`): PV-P75 ≤ 2,000 USD (about 27 USD/kW), DAB-D60 ≤ 1,700 USD (about 28 USD/kW), PV-P100/110 ≤ 2,500 USD. Sub-targets: PV-PORT ≤ 450 USD, PVCELL-25 with its inductor ≤ 300 USD per cell, fan + heatsink ≤ 60 USD per cell. Cost is a selection criterion next to efficiency in every re-run study | First costed BOM: PV-P75 4,948 USD (66 USD/kW), DAB-D60 4,283 USD (71 USD/kW), 45 % of it estimates. Comparable Chinese DC/DC modules sell for 22–74 USD/kW (median 34, 17 sourced listings), which implies a BOM of roughly 12–50 USD/kW. The money is in the port protection (PV-PORT 2,309 USD: DIN-rail arresters with backup fuses, NH fuses, three TDK contactors) and the Western SiC devices (946 USD), not in the control boards (CTRL 94, SYS 130 USD) | Targets frozen; the market benchmark has no public price for the Megarevo module itself |
| D-039 | 2026-10-04 | Magnetics are verified three ways (`sim/magnetics.py`: OpenMagnetics 1.7.33 built from source, an independent calculation, the designer's figure) and the construction of each magnetic part is now owned by the magnetics engineer, who writes `sim/out/magnetics/design_<part>.json`; the converter engineers keep the electrical requirements and read losses, thermal resistance and leakage from those files. The DAB transformer and series inductor are redesigned; the PV inductor, the AUX-HV transformer and the port chokes get a buildable construction | First verification: DAB transformer copper loss 236–337 W against the designer's 92 W (the assumed AC resistance ratio 1.15 is about 2.5) and its 0.4 K/W cooling requirement is not credible; series inductor 28–190 W against 11 W; AUX-HV transformer winding loss 2.3–5.7 W against 0.5 W; the PV inductor's round litz does not fit and its hot spot is 75 K, not 48 K; the port choke spec lets a typical core saturate. The Wolfspeed reference's measured winding resistance supports the higher DAB figure | Frozen as method; 14 findings MG-01…14 open until the new constructions pass |
| D-040 | 2026-10-04 | Second-source policy for everything that is not a power device (`gen/data/alternates.csv`, `sim/data/asia_ics.md`, 107 lines studied: 38 drop-in, 14 functional, 53 without a properly documented Asian part, 21 adopted). The reinforced isolated amplifier becomes Chipanalog CA-IS1311BG, fed on its high side by a Chipanalog CA-IS3115AW isolated DC/DC (also the pin-compatible replacement of UCC12050): VIMP 9846 V, VIOSM 12.8 kV, VDE 0884-17 reinforced granted — this closes the surge-rating failures of AMC3302 and UCC12050 without leaning on the arrester credit. Connectors and terminal blocks move to XKB / Kefa / Dinkle parts with drawings on file; current sensors to Sinomags are an option pending a quote. **Kept on purpose:** the isolated digital inputs of the E-stop channels, the CAN / RS-485 isolators, TPSI3050, ISO7720F — the Asian parts found are weaker on surge rating, would put both E-stop channels in one package, or have no obtainable datasheet | SRC-1…4; insulation findings IC-02, IC-03; temperature-audit gaps (Phoenix parts had no datasheet on file). The control boards are already cheap (CTRL 94 USD, SYS 130 USD), so there the change buys supply security and documentation, not money | Frozen; applied board by board in each board's next revision (BMU-GW rev B done) |
| D-041 | 2026-10-04 | Gate-0 re-run with Asian devices and prices in USD (`sim/out/pv_tradeoff/gate0b.md`): the PV cell **stays 2-level** (confirms D-007). Devices: primary 2 × Sichain SG2M040170HJ per position, alternate 2 × InventChip IV2Q17020T4Z, gate rails +18 / −3.5 V, NSI6651 driver. Cell cost 354 USD against 615 USD with the Microchip parts (target 300 not met: fan + heatsink 140 USD against 60); cell corners 99.07–99.24 %, peak 99.55 %; module peak 99.54 % | 2-level with Sichain 2 × 40 mΩ costs 332 USD per cell against 428 USD for the best 3-level candidate (1200 V parts, twice the gate-drive channels, flying capacitors), and keeps the verified boards, control and magnetics; the result holds for ±30 % device price and for InventChip at 1.5 × the Sichain price. **Open:** the lumped Miller model fails the InventChip set (+4.69 V at the die against a 1.47 V threshold) and leaves the Sichain set no margin; the driver's soft turn-off is 1.6–2.8 µs against the 1.0 µs required; no short-circuit rating exists for either part; Sichain states no qualification; two of the prices are estimates | Topology frozen; the device set is conditional on the gate-drive revision closing the Miller and short-circuit items |
| D-042 | 2026-10-04 | Port surge protection moves from DIN-rail arresters with NH backup fuses to a monitored varistor network on the board: per port three thermally protected varistors (Thinking TVT25751; pole to midpoint twice, midpoint to PE), each pole branch behind its own 30 kA 14×51 fuse; calculated effective level 3.79 kV pole-PE and pole-pole at 3 kA (Imax 25 kA), 1,230 V continuous across two in series; one monitoring loop through both fuses and all three thermal links, reported on the ID-line readback. This is also what the 6 kV reinforced credit of D-032 rests on. The TDK HVC43 contactors and the Mersen / ETI main fuses **stay**: Hongfa HFE85V-300M would coordinate as a single contactor per port, but its 3,000 V AC coil-to-contact rating is below the reinforced test level; no Asian main fuse with published curves was found. PV-PORT cost 2,309 → 1,493 USD against a 450 USD target | SRC-3, D-038; insulation findings IC-01, IC-12. **Open:** the varistors' thermal links have no DC rating (a certifier must accept that or require the IEC 61643-31 end-of-life tests on the board); IC-04 (precharge relay coil-to-contact rating); the 124 A at 60 °C limit of the PV port fuse; the 450 USD target needs either a contactor with a stated reinforced rating or an isolated coil supply, plus Asian main fuses with real data | Surge network frozen; contactor and fuse sourcing open (price and data research running) |
| D-043 | 2026-10-04 | Gate drive rev 5 (`gen/gdrv.py`, `sim/gdrv_miller.py`): NOVOSENSE NSI6651ASC-Q1 driver, TI UCC14241-Q1 bias; one clamp MOSFET per gate at the gate-Kelvin pins (clamp loop ≤ 1 nH is a layout rule); a short-circuit turn-off booster that fires above the driver's 9.8 V DESAT trip (PV set off in 0.62 µs, 1214 V against 1445 V allowed). PV cell devices: primary 2 × Sichain SG2M040170HJ at +18 / −3.5 V (die +1.38 V against a 1.94 V threshold); **the InventChip parts fail the false-turn-on check even with an ideal clamp, so they are not an alternate**; the qualified fallback is Microchip MSC035SMA170B4 × 2 at +20 / −4 V as an assembly variant of the same board | Review D-041's open items. **Conditions:** the NSI6651's impulse rating is 6,250 V against the 8 kV reinforced requirement (UCC21710: 8,000 V) — it passes only with the 6 kV arrester credit of D-032 / D-042, which is not verified against the standard; TI UCC21750 is the footprint-compatible fallback (all but two pins) if a certifier refuses the credit. Sichain publishes no qualification statement: its reliability data is a release condition. The short-circuit currents behind the booster figures are assumptions; the DAB devices are not yet simulated for false turn-on; the driver's input thresholds are specified at 5 V only | Frozen with the conditions listed |
| D-044 | 2026-10-04 | **Cost-first architecture** for the PV module (`docs/requirements/COST-REVIEW.md`). Benchmark from the owner: Megarevo's 228 kW string PCS sells for 1,500 USD = 6.6 USD/kW; our PV-P75 BOM is 2,789 USD = 37 USD/kW. The power-stage topology stays (two-level interleaved four-switch buck-boost, Chinese 1700 V SiC, NSI6651 gate-drive channel, verified inductor, control and MPPT design). The architecture around it changes: control referenced to the negative DC rail with ONE reinforced barrier (communication, fans, enable input) instead of a PELV control island with a barrier at every driver and sensor; one power board and one control board instead of eight boards; self-powered from the DC side; a single-core TI C2000; lean port protection (battery side: fuse pair, one contactor, precharge; PV side: no precharge, no fuses; varistors on the board; fault currents above the contactor's rating are left to the upstream battery protection, stated as an installation requirement); no terminal-short clamp banks; a single hardware trip latch with a watchdog. Working budget: PV-P75 BOM ≤ 800 USD at catalogue prices (my assumption — the owner gave a PCS price, not a DC/DC price); DAB-D60 ≤ 950 USD | Owner: "we must produce it within the budget". Trimming the present platform bottoms out near 1,700–1,900 USD, still about three times the benchmark. **Given up:** the PELV island and its 132 audited barriers, the common controller card and the SYS-IO-AUX feature set of the roadmap (Ethernet, CAN FD, spare I/O, redundant 24 V feeds, dual-channel safety chain), terminal-short survival. Supersedes D-012, D-019, D-024, D-025, D-033, D-034 and D-038 for the cost-first product; the existing boards stay in the repository as the roadmap's full-featured implementation and receive no further work | Frozen as direction; the architecture specification and its costed parts list are the next deliverable |
| D-045 | 2026-10-04 | Cost-first architecture specification accepted as the basis for implementation (`docs/requirements/ARCHITECTURE-COSTFIRST.md`, costed list `gen/data/costfirst_bom.csv`): power board with all phases + small control board with a TI F280039C (4.40 USD) on the negative rail; ONE reinforced barrier (auxiliary transformer's SELV winding + five isolators) to communication, stop input, status output and fans; self-powered by a 75 W flyback from both ports; both ports keep one Hongfa contactor (the PV port needs it for reverse polarity and to isolate a module with a shorted leg); battery port with one aR fuse per pole and precharge; heatsink earthed; passive bleeders. Costed total 966 USD for PV-P75 (12.9 USD/kW), 1,177 USD for PV-P100/110; about 736 USD at the architect's assumed volume factors. Board-to-board contract `PC` (2 × 32) defined in `gen/interfaces.py` | D-044. **Budget not met:** 21 % over the 800 USD working budget; the three inductors at 80 USD each are 25 % of it and are re-opened for cost. 86 % of the total is low-confidence estimates. The 1,000-part target is not reachable with the present gate-drive channel (about 85 parts each, 12 channels): about 1,850 parts. Given up: terminal-short survival, non-isolated service access, a rated emergency-stop function, cabinet 24 V, Ethernet, CAN FD, spare I/O, active discharge; device junction temperature rises from about 78 °C to about 110 °C. Risks: no quotes; Hongfa does not state coil-to-mounting insulation; the chosen fans are rated to −10 °C against −30 °C; the bias transformer is a new custom part; standard values from memory | Frozen as the implementation basis; the fan temperature rating and the budget gap are open |
| D-046 | 2026-10-04 | Scope extended by the owner: the product family needs a DC-to-AC PCS as well as the DC/DC, and costs are to be judged at a 5,000-unit volume. Baseline chosen for the PCS: the roadmap's PCS-P125 (125 kW, 590–950 V DC, 400/230 V AC) against Megarevo PMA0125, designed cost-first from the start; P60 / P105 follow as derivatives | Owner: "we need both dc dc and dc to ac .. check for volume like 5000 qty" (REQUIREMENTS.md §8). The owner named no rating: P125 is the roadmap's "highest commercial priority" and is a 1000 V-class product like the DC/DC; Megarevo's 1500 V string PCS is used as the price benchmark only | Frozen as scope; the rating is my assumption and can be changed by the owner |
| D-047 | 2026-10-04 | DC-to-AC PCS-P125 architecture accepted as the basis for the design study (`docs/requirements/ARCHITECTURE-PCS.md`, costed list `gen/data/costfirst_pcs_bom.csv`): three-level T-type with discrete Chinese IGBTs at 16 kHz (4 × 1200 V / 40 A outer and 3 × 650 V / 40 A inner per position, 42 devices, 12 gate-drive channels), LCL filter, split DC link, lean DC port from the PV design, controller on a live reference with the one reinforced barrier, the PV control board with a TI F280039C as an assembly variant; four-wire version = a fourth leg. Screening figures: 98.7 % peak, about 98.2 % at full load. Cost: three-wire 1,037 USD at catalogue prices, 801 USD at 5,000 units (6.4 USD/kW); four-wire 1,194 / 919 USD; PV-P75 on the same basis 966 / 731 USD | REQUIREMENTS.md §8. Against the benchmark adjusted for current per kW (a 400 V unit carries 1.58 × the AC current of the 630 V benchmark; about 690 USD equivalent): three-wire +16 %, four-wire +33 %, PV-P75 +78 %. **Not yet decided / at risk:** the outer IGBTs run at 0.79 of rated voltage at 950 V DC, against the 0.67 rule of the PV design — the design study must settle T-type against I-type on failure-rate evidence, not on cost alone; only 14–17 % of the 5,000-unit figures rest on real volume prices; the topology numbers are a first-order loss calculation; four IGBTs in parallel may not share; the three-wire version leaks current through the battery's capacitance to earth on an earthed-neutral grid; grid-code clauses are from memory | Accepted as the starting point; topology to be confirmed by `sim/pcs_design.py` |
| D-048 | 2026-10-04 | Magnetics of the cost-first design (`sim/magnetics.py`, 54 checks pass; constructions in `sim/out/magnetics/design_*.json`). **PV inductor rev M2:** same POCO toroid stack, the profiled litz replaced by magnet wire — 40.5 USD with solid round wire (84 W, hot spot 145 °C) or 44.6 USD with edgewise flat wire (73 W, 133 °C), against 80 USD (52 W, 106 °C) before; **the edgewise construction is the one to use**: 4 USD more buys 12 K of hot-spot margin on a thermal model that is only an estimate. **Port common-mode filter:** one flat-permeability nanocrystalline ring per port (10.9 USD) plus at least 127 nF of capacitance to PE per port; the architecture's ring-only derivation did not hold (2.8 dB, not 16 dB). **Gate-bias transformer:** DMEGC EP17, five-section bobbin, ≤ 3.4 pF, ratio 1:6.0, 2.18 USD (1.22 USD at 5,000 units plus about 4,000 USD of bobbin tooling). **75 W auxiliary transformer:** DMEGC EC39A, 8.5 USD (5.7 USD at 5,000 units) | D-044 budget; MAG-1, MAG-2. Prices are estimates, not quotes. **Consequences accepted:** the cheaper inductor costs about 0.1 point of efficiency at the worst point; the capacitance to PE puts about 11 mA into the protective conductor, so the product needs the high-touch-current measures (PE conductor ≥ 10 mm² Cu and a warning label) and the insulation monitor's settling time grows; emission margin is 8–12 dB below the earlier choke. Capacitances are calculated only; the aux transformer's leakage is 13.5 µH against a 14.2 µH limit | Frozen; the inductor file still names the round-wire option and is switched at the next magnetics round |
| D-049 | 2026-10-04 | Hardware / firmware allocation for the cost-first products (`ARCHITECTURE-COSTFIRST.md` §6.5). **Stays in discrete hardware:** driver DESAT with its turn-off booster, driver under-voltage lock-out, pull-downs that hold every gate off while the controller is in reset, the external stop wired straight onto the drivers' enable, the comparator that keeps a contactor closed above its breaking capacity, the coil economiser timer. **Moves into the controller's own hardware:** per-phase over-current (comparator subsystem), port over-voltage and port over-current (ADC limit trips), the trip latch and PWM gating (trip zone), dead time (dead-band generator). **Moves into firmware:** over-temperature with probe checks, contactor sequencing (polarity, precharge ΔV, weld check), monitoring and plausibility. Removed: discrete window comparators and references, the latch and OR network, the AND gates on the PWM lines, the heartbeat monoflop, the per-channel dead-time stretch, the negative-rail detector, the polarity / ΔV interlock comparators, the port over-current comparators | Owner: "offload whatever possible to the firmware to save cost … balance between hardware and software for edge cases" (REQUIREMENTS.md SRC-7). **Accepted consequence:** a firmware fault can close a contactor onto reversed polarity or a large voltage difference, miss an over-temperature, or set a wrong dead time; each ends in a DESAT trip, a blown fuse or a watchdog reset — a damaged or stopped unit, not a hazard. The firmware carries a safety-requirement list (thresholds, timing, start-up self-test of each trip path, configuration read-back and lock) | Frozen; supersedes the single-latch table of §6.1 |
| D-050 | 2026-10-05 | **Supersedes D-049.** The hardware protections stay as designed: discrete over-current, over-voltage and over-temperature comparators with the one latch and the PWM gating on the control board, the RC dead-time stretch and the negative-rail detector in every gate-drive channel, the polarity / precharge ΔV interlocks, the hold-off comparator and the port over-current comparators on the power board. Firmware duplicates each as a second layer and takes sequencing, monitoring and every rare edge case that is not a hazard; no new hardware is added for an edge case unless firmware cannot cover it | Owner: "if it's not a significant saving, keep it … decide yourself everything". Worked out part by part, removing them saves about 17 USD per module (about 2 %). Against that: with the dead-time stretch removed a firmware dead time of zero destroys the switches within milliseconds (the overlap ends before DESAT's blanking); a lost negative rail dissipates about 50 W per leg undetected; a firmware sequencing error closes a contactor onto reversed polarity. The lighter variants remain available as options in `gen/port.py` and `gen/gdrv.py` | Frozen |
| D-051 | 2026-10-05 | The owner delegated the open decisions ("decide yourself everything"). Taken on that basis and recorded here so they can be overturned: the DC-to-AC baseline is PCS-P125 (D-046); the working budgets are 800 USD (PV-P75) and 950 USD (DAB-D60) of BOM at catalogue prices, with the 5,000-unit figure reported next to them (D-044); the inductor uses the edgewise flat-wire construction and the port filter a ring plus capacitance to PE (D-048); hardware protections stay (D-050); the LINK-PP RJ45 data sheet fetched with a referrer header stays on file with that noted in its manifest row; the earlier open items D-009 (candidate requirements: adopted as design targets), D-017 (DAB parallel modules: superseded by the paralleled-discrete design), D-020 (180 A port: closed by the lean port's limits) and D-022 (auxiliary supply: self-powered 75 W in the cost-first design) are closed accordingly | Owner instruction 2026-10-05 | Frozen until the owner says otherwise |
| D-052 | 2026-10-05 | Cost status of the cost-first PV module on drawn boards (`gen/cost.py`, `bom/COST.md`; power board PV-PWR rev A1, control board PV-CTL rev A0): PV-P75 **959 USD at catalogue prices (12.8 USD/kW), 803 USD at 5,000 units (10.7 USD/kW)**; PV-P100/110 1,152 / 963 USD; the old platform on the same basis 2,824 / 2,265 USD. Against the benchmark-equivalent BOM (Megarevo's 6.6 USD/kW selling price, 25 % margin, BOM 80 % of cost of goods, 70 % of cost scaling with current: about 410 USD for a 135 A module) the PV-P75 is 2.3 × at catalogue prices and 2.0 × at 5,000 units; the old platform was 6.9 × / 5.5 ×. Next levers, to be worked in the integration round: a smaller contactor on the PV port (it never sees more than the array's short-circuit current), fewer port film capacitors with the interleaving credited, re-checking the switching frequency against the new inductor cost | SRC-3, SRC-5, SRC-6. 78 % of the catalogue total is engineering estimate without a quote, and 84 % of the 5,000-unit figure rests on assumed volume factors: the remaining gap cannot be judged honestly without supplier quotations (SiC devices, inductors, contactors, film capacitors) | Recorded; budget of 800 USD at catalogue prices not yet met |
| D-053 | 2026-10-05 | **PCS-P125 power stage: two-level with 1700 V SiC; the three-level T-type of D-047 is withdrawn** (`sim/pcs_design.py`, `sim/out/pcs_design/report.md`, `pcs_spec.json`; self-check passes on an independent re-run). 6 × Sichain SG2M040170HJ per switch (36 devices, 6 gate-drive channels each with a current buffer, 8 channels in the four-wire version), 32 kHz; LCL filter L1 97 µH, C_f 50 µF with its star tied to the DC midpoint, L2 15 µH; DC link 5 + 5 Faratronic C3D1U147 film capacitors. Calculated: peak efficiency 99.20 %, 98.65 % at 125 kW / 750 V; worst junction 116 °C at 110 % load and 45 °C inlet, 151 °C after 200 ms at 259 A. Cost: three-wire **1,086 USD at catalogue prices, 869 USD at 5,000 units (7.0 USD/kW)**; four-wire 1,289 / 1,032 USD. Hardware protections follow D-050, as on the PV module: the discrete comparators, latch and PWM gating of the PV control board, the dead-time stretch and negative-rail detector per gate-drive channel, the DC-port interlocks and hold-off comparator - about 8 USD of that total | The risk D-047 left open, settled on evidence and on cost. Every device sits at ≤ 0.56 of its rating at 950 V; the T-type's 1200 V outer devices sit at 0.79 (Semikron AN 17-003: about 104 FIT per unit from cosmic rays at 950 V, sea level, against 0.16 here; no Chinese maker publishes such data). D-047's own figures did not hold: its 42 IGBTs overheat (66 needed) and its 660 µF per half cannot hold the midpoint at power factor 0 (about 3.5 mF per half for any three-level stage), so the corrected T-type costs about 1,015 USD at 5,000 units. Two-level also shares the SiC device, the driver and the control board with the PV module, halves the gate-drive channels and needs no midpoint control. Chinese three-level modules (`sim/data/asia_modules.md`): none has a public price, the best-fitting HIITIO part prints no short-circuit data, and one module per phase overheats by 27–32 K in the overloads. **Not verified:** the SiC device price (4.07 USD is an estimate), its qualification and short-circuit withstand; current sharing across six paralleled devices is a layout requirement, not a result; every inductor, contactor, fuse and heatsink price; the control loops; the standards clauses (quoted from memory); the battery's capacitance to earth, which limits three-wire operation below about 680 V; the step response of the ±500 A phase-current sensors, which must keep the hardware trip within about 1.5 µs; the dead-time stretch values for six gates behind one buffer (a new preset in `gen/gdrv.py`); only 7 % of the 5,000-unit figure rests on real volume prices | Baseline for the control simulation, the magnetics and the boards. A cross-check against Wolfspeed's 25 kW T-type reference design (design files supplied by the owner on 2026-10-05) is running and can overturn it |
| D-054 | 2026-10-05 | **PV inductor: solid round wire, not edgewise flat wire** (amends D-048 and the corresponding line of D-051). Rev M2 keeps the POCO NPC 26 toroid stack and 37 turns; the winding is 3.15 mm round enamelled copper in one layer: 83.8 W and a 145 °C hot spot at the worst point (1000 V, duty 0.5, 45 A; limit 155 °C), 40.5 USD. The 75 W auxiliary transformer's SELV winding goes to 200-strand litz for the 95.3 W design power (86.6 W four-phase load + 10 %): 8.8 USD at catalogue prices, 5.9 USD at 5,000 units | D-048 chose edgewise on a 73 W / 133 °C figure that came from the in-house model alone: the OpenMagnetics check for that row had been run on a litz stand-in by mistake. With the real rectangular conductor the tool gives 60.2 W of copper loss against the model's 47.5 W, and the design rule is to take the higher: 85.6 W, 147 °C, 44.6 USD. Edgewise is then 2 K worse and 4.1 USD dearer per inductor (12 USD per PV-P75). `sim/magnetics.py` passes all checks with the round-wire choice. Cost after the change (`gen/cost.py`): PV-P75 **947 USD at catalogue prices, 792 USD at 5,000 units**; PV-P100/110 1,136 / 950 USD (D-052 recorded 959 / 803 and 1,152 / 963) | Frozen; the two models disagree by 27 % on the flat wire's copper loss, so a wound sample decides if edgewise is ever reconsidered |
| D-055 | 2026-10-05 | **Power modules from Chinese makers stay request-for-quotation alternates; the designs stay on paralleled discretes** (`sim/data/asia_modules.csv`, `asia_modules.md`: 24 candidates from HIITIO, StarPower, Macmic, BASiC, Leapers and others, plus HIITIO contactors, fuses, arrester and transducer). Break-even prices a module must beat: 38.7 USD per phase leg for the PCS, 36 USD per half-bridge for the DAB, 16.5 USD per half-bridge for the PV cell. For the DAB-D60 the BASiC BMF008MR12E2G3 (8.1 mΩ, best documents) is the module to quote against the discretes | Owner: check HIITIO and similar Chinese makers of clone modules. No candidate has a public price (HIITIO quotes on request; none is stocked at LCSC). No 1700 V SiC module in the 20–60 mΩ class exists at any maker that could be read, so the PV cell has no module option. Only StarPower (IGBT), Macmic and BASiC publish short-circuit ratings; HIITIO's module sheets disagree with Leapers' for the same 62 mm part and are treated as unverified; only AccoPower claims pin compatibility with a Western package and its sheet is behind a contact form. HIITIO's HCHVF1000 fuses (UL Recognized, I²t per rating) and HCF contactors (make / break tables, 8 kA withstand) are documented well enough to be candidates for the 400 A-class PCS port | Recorded; revisit when quotations exist |
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

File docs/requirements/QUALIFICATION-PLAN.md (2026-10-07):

<!-- breadcrumb --> [Home](../../README.md) › [Documentation](../README.md) › Qualification plan

# 🔬 Qualification plan: every open gate

> One consolidated plan of the gates the five review rounds left open: what is tested, the acceptance number our records
> give, the asset that can close it, the product or claim it blocks and the stage it belongs to.








---
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

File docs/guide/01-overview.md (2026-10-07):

<!-- breadcrumb --> [Home](../../README.md) › [Documentation](../README.md) › Overview

# 🧭 Overview

> What the PCM product family is, what each product is for, where the design came from and where it stands as of 2026-10-07.






---
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

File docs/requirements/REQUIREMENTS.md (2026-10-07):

# DC-DC platform — requirements (scope lock)

**Status:** baseline 2026-10-03, amended 2026-10-04 (§7 sourcing, cost, magnetics, budget; §8 DC-to-AC PCS, 5,000-unit cost basis) · **Owner:** Chinmoy Bhuyan · **Source of truth:** [00-roadmap-source.md](00-roadmap-source.md)

This file is what the project is measured against. If a task is not traceable to a line here, it is a
diversion: stop and ask. Changes to this file are made only on the user's instruction and are logged in
[DECISIONS.md](DECISIONS.md).
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

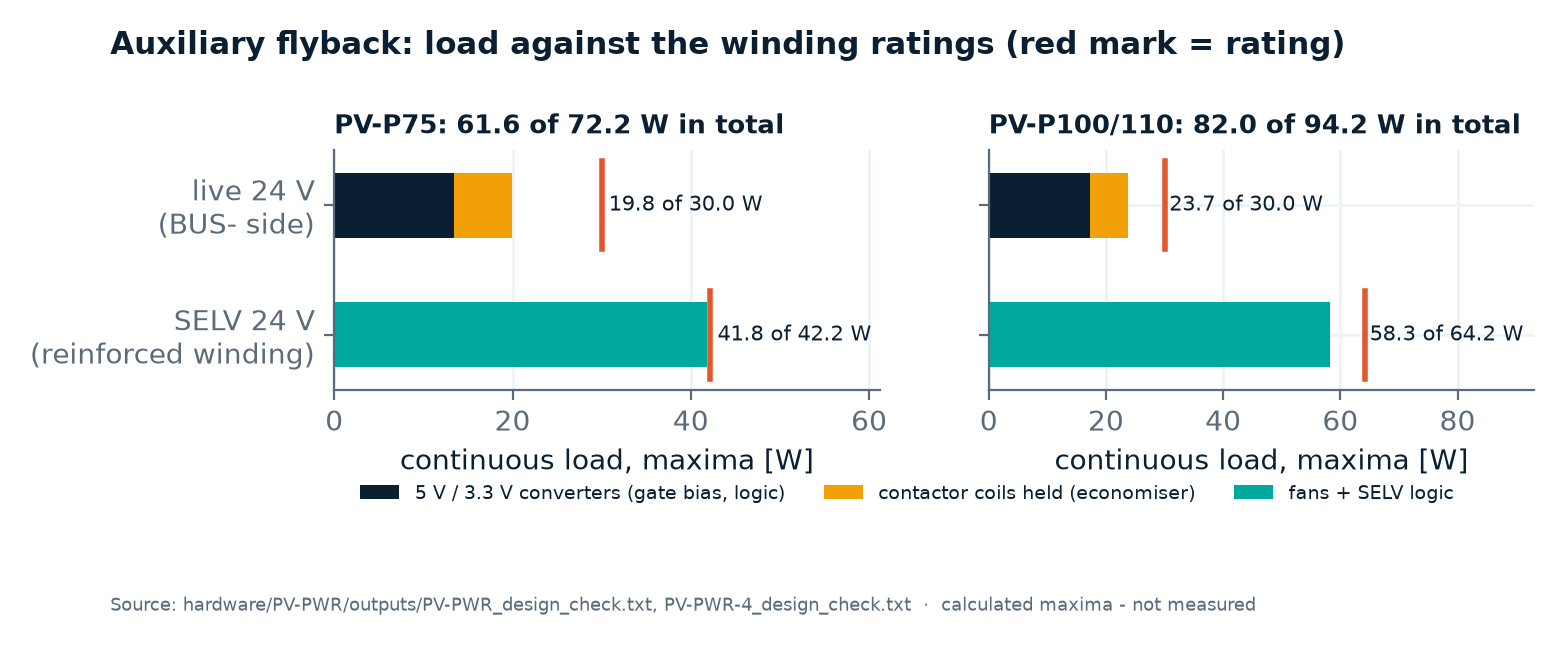
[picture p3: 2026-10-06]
docs/assets/img/design_supply_budget.png

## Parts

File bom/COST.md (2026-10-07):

# Cost model - generated by gen/cost.py (do not edit)

**Honesty boundary.** No part has been bought or quoted. A *priced* line has a looked-up price (gen/data/prices.csv, URL and date 2026-10-04); an *estimated* line has a stated engineering basis (gen/data/cost_estimates.csv); an *unpriced* line has neither and is listed, never counted as zero. All prices are single-source web readings, not contracts. Cost per kW uses the rated power of the product (PV-01, PV-15, DAB-01). The modules PV-P75 and PV-P100-110 are the cost-first baseline (D-044/D-045: boards PV-PWR / PV-PWR-4 and PV-CTL); the modules ending in -FULL are the roadmap's earlier platform, kept for contrast.

**Catalogue price** = the break at the highest quantity <= 1000 pieces from the best source (LCSC first, then the maker's own site, then distributors, brokers and aggregators; cheapest within a class; a one-piece price loses to any source that has a volume break). Currencies at the ECB rates of 2026-10-02 (1 EUR = 1.1225 USD = 7.5259 CNY, so 1 USD = 6.705 CNY). Chip passives use reel-price class rules; custom parts use engineering estimates (copper and aluminium at LME cash of 2026-10-02: 14,355 and 3,109.5 USD/t). Prices marked 'single-piece price' are catalogue prices for one piece. A price row can belong to an equivalent part of another maker with the same type designation (its note in prices.csv says so). Confidence: high = LCSC or maker price read from its page; medium = distributor/broker price or an estimate pinned to a close equivalent; low = engineering estimate.

**Price at a 5000-unit build** (SRC-6; the annual quantity of a line is 5000 x its quantity per module). REAL = a published price of the part at a break of at least 1000 pieces and at most the annual quantity (LCSC highest break, TI.com 1ku list price, a distributor's volume tier, or the highest break of the LCSC listing that a chip-passive class is built on). ASSUMED = the catalogue price times a factor of gen/data/volume_factors.csv, chosen by part class, with its basis written out there. A REAL price is never above the catalogue price, and the highest published break can still be above what a 5,000-unit buyer would be quoted: no quote exists.

## Summary

| module | rated kW | BOM catalogue USD | USD/kW | BOM at 5000 units USD | USD/kW | 5k total REAL % | 5k total ASSUMED % | catalogue total on engineering estimates % | unpriced lines | BOM + outside, catalogue USD/kW | BOM + outside, 5000 units USD/kW |
|---|---|---|---|---|---|---|---|---|---|---|---|
| PV-P75 | 75 | 979.55 | 13.1 | 820.41 | 10.9 | 16 | 84 | 66 | 1 | 17.9 | 15.1 |
| PV-P100-110 | 100 | 1171.28 | 11.7 | 980.74 | 9.8 | 16 | 84 | 64 | 2 | 16.0 | 13.4 |
| PV-P100-110 | 110 | 1171.28 | 10.6 | 980.74 | 8.9 | 16 | 84 | 64 | 2 | 14.5 | 12.2 |
| PCS-P125 | 125 | 1588.90 | 12.7 | 1349.14 | 10.8 | 9 | 91 | 77 | 1 | 15.1 | 12.8 |
| PCS-P125-4W | 125 | 1925.77 | 15.4 | 1635.98 | 13.1 | 9 | 91 | 75 | 2 | 18.0 | 15.3 |
| PV-P75-FULL (old platform, for contrast) | 75 | 2835.80 | 37.8 | 2275.27 | 30.3 | 17 | 83 | 51 | 7 | 42.5 | 34.3 |
| PV-P100-110-FULL (old platform, for contrast) | 100 | 3379.94 | 33.8 | 2692.32 | 26.9 | 16 | 84 | 51 | 7 | 37.8 | 30.3 |
| PV-P100-110-FULL (old platform, for contrast) | 110 | 3379.94 | 30.7 | 2692.32 | 24.5 | 16 | 84 | 51 | 7 | 34.4 | 27.5 |
| DAB-D60-FULL (old platform, for contrast) | 60 | 3614.70 | 60.2 | 2927.30 | 48.8 | 12 | 88 | 48 | 3 | 65.6 | 53.3 |

Unpriced lines carry no cost, so the totals of these modules are lower bounds: PV-P75: 1 line(s), 5 parts; PV-P100-110: 2 line(s), 7 parts; PCS-P125: 1 line(s), 5 parts; PCS-P125-4W: 2 line(s), 7 parts; PV-P75-FULL (old platform, for contrast): 7 line(s), 67 parts; PV-P100-110-FULL (old platform, for contrast): 7 line(s), 84 parts; DAB-D60-FULL (old platform, for contrast): 3 line(s), 5 parts (listed under each module).

## PV-P75

Total BOM cost **979.55 USD at catalogue prices = 13.1 USD per kW at 75 kW**; **820.41 USD at a 5000-unit build = 10.9 USD per kW at 75 kW**. Lines: 311 (304 purchased-part lines; 7 NOPART lines such as test points and net ties are not costed).

### Evidence behind the catalogue total

| basis | lines | parts | USD | share of the costed total |
|---|---|---|---|---|
| real price of the part (looked up) | 83 | 582 | 301.80 | 30.8 % |
| chip-passive class rule (price of a real LCSC example part of the same class) | 165 | 1275 | 35.40 | 3.6 % |
| engineering estimate with stated basis | 55 | 290 | 642.35 | 65.6 % |
| no price at all (UNPRICED, not in the total) | 1 | 5 | not known | not in the total |

### The 5000-unit view

| basis of the 5000-unit price | lines | USD at 5000 units | share of the 5000-unit total |
|---|---|---|---|
| REAL: a published price at a break >= 1000 pieces | 240 | 128.98 | 15.7 % |
| ASSUMED: catalogue price x factor of volume_factors.csv | 63 | 691.43 | 84.3 % |

The 5000-unit total is 83.8 % of the catalogue total.

| factor class used | factor | lines | catalogue USD | USD at 5000 units | confidence |
|---|---|---|---|---|---|
| protection_estimate | 0.80 | 9 | 217.11 | 173.69 | low |
| short_table | 0.85 | 5 | 168.37 | 143.11 | medium |
| asia_part_estimate | 0.85 | 31 | 160.60 | 136.51 | low |
| custom_magnetic_large | 0.85 | 2 | 143.30 | 121.81 | low |
| custom_mech | 0.85 | 9 | 79.50 | 67.58 | low |
| single_piece_list | 0.52 | 2 | 36.34 | 18.90 | medium |
| ceramic_pad | 0.70 | 1 | 24.00 | 16.80 | low |
| custom_magnetic_small | 0.67 | 2 | 15.34 | 10.28 | low |
| custom_harness | 0.80 | 1 | 2.50 | 2.00 | low |
| chip_passive_class | 0.96 | 1 | 0.80 | 0.77 | medium |

### Split by function group

Groups are assigned by rule from the line's description and the board that carries it (approximate; see group_of in gen/cost.py).

| group | catalogue USD | % of BOM | USD at 5000 units | lines | of which estimated |
|---|---|---|---|---|---|
| protection (fuses, contactors, SPD, TVS) | 257.40 | 26.3 | 208.43 | 22 | 13 |
| magnetics | 164.62 | 16.8 | 137.16 | 9 | 8 |
| power semiconductors | 124.20 | 12.7 | 105.57 | 2 | 1 |
| capacitors | 107.24 | 10.9 | 94.57 | 56 | 56 |
| thermal | 87.92 | 9.0 | 71.13 | 5 | 3 |
| gate drive | 82.64 | 8.4 | 62.57 | 31 | 6 |
| connectors + harness | 45.25 | 4.6 | 38.37 | 11 | 6 |
| control + communications | 42.31 | 4.3 | 41.49 | 26 | 5 |
| sensing | 34.46 | 3.5 | 29.29 | 8 | 5 |
| resistors + other board parts | 18.90 | 1.9 | 17.68 | 122 | 116 |
| auxiliary supply | 14.61 | 1.5 | 14.14 | 11 | 1 |
| **total BOM** | **979.55** | 100 | **820.41** | 303 | |
| PCB / mechanics outside the BOM (rough, not in the BOM total) | 365.77 | | 308.37 | | all assumed |

### Outside the BOM (rough figures, not part of the BOM total)

| item | catalogue USD | USD at 5000 units | assumption (see gen/data/cost_estimates.csv outside: rows) |
|---|---|---|---|
| bare PCB PV-CTL-P75 x1 | 8.42 | 7.16 | 288 parts per board x 0.65 cm2 = 187 cm2 x 0.045 USD/cm2 |
| bare PCB PV-PWR x1 | 161.72 | 137.46 | 1843 parts per board x 0.65 cm2 = 1198 cm2 x 0.045 USD/cm2 x 3 (6-layer heavy copper) |
| board assembly (2131 placements, 2 boards) | 50.62 | 40.50 | 0.020 USD per placement + 4.0 USD per board |
| enclosure / sheet metal / packaging | 90.00 | 76.50 | see cost_estimates.csv outside:enclosure |
| final assembly, test and burn-in | 55.00 | 46.75 | see cost_estimates.csv outside:final_assembly_test |
| **BOM + outside, rough** | **1345.32** (17.9 USD per kW at 75 kW) | **1128.78** (15.1 USD per kW at 75 kW) | |

### Top 25 cost lines (catalogue)

| # | BOM item | qty | value / MPN | unit USD | ext USD | % of BOM | unit USD at 5000 | basis at 5000 units | basis (catalogue) | conf |
|---|---|---|---|---|---|---|---|---|---|---|
| 1 | 257 | 24 | SG2M040170HJ | 5.071 | 121.70 | 12.4 | 4.31 | ASSUMED x0.85 [short_table] | LCSC C42456100 @90+ (2026-10-05) | high |
| 2 | 6 | 3 | L_CELL 224uH (CUSTOM) | 40.5 | 121.50 | 12.4 | 34.42 | ASSUMED x0.85 [custom_magnetic_large] | estimate L_CELL 224uH (CUSTOM): ESTIMATE (sim/magnetics.py design_pv_inductor.js | low |
| 3 | 208 | 2 | HFE82V-300C/1000-24-H-C5-1 | 57.5 | 115.00 | 11.7 | 46 | ASSUMED x0.80 [protection_estimate] | estimate HFE82V-300C/1000-24-H-C5-1: ESTIMATE: no price for the 1000 V / 24 V va | low |
| 4 | 214 | 13 | FCSA3DS456K050H8F9DE3 | 5.4 | 70.20 | 7.2 | 4.59 | ASSUMED x0.85 [asia_part_estimate] | estimate FCSA3DS456K050H8F9DE3: ESTIMATE (architect's list 5.40): Jianghai CBB-t | low |
| 5 | 200 | 3 | AFB1224SHE-F00 | 12.85 | 38.55 | 3.9 | 10.92 | ASSUMED x0.85 [short_table] | Master Electronics (web-search result; page not read)  @504+ (2026-10-04) | medium |
| 6 | 209 | 2 | HPE501/000B100-250 | 18 | 36.00 | 3.7 | 14.4 | ASSUMED x0.80 [protection_estimate] | estimate HPE501/000B100-250: ESTIMATE: Hongfa HPE501 size-000 aR 250 A 1000 V DC | low |
| 7 | 222 | 12 | NSI6651ASC-Q1SWR | 2.978 | 35.73 | 3.6 | 1.548 | ASSUMED x0.52 [single_piece_list] | LCSC C33959952 @1+ (2026-10-04) single-piece price | high |
| 8 | 11 | 1 | heatsink 24 x TO-247 (CUSTOM) | 24.3 | 24.30 | 2.5 | 20.66 | ASSUMED x0.85 [custom_mech] | estimate heatsink 24 x TO-247 (CUSTOM): ESTIMATE: one Al extrusion of about 3.6  | low |
| 9 | 8 | 24 | PAD AlN 1 mm (CUSTOM) | 1 | 24.00 | 2.5 | 0.7 | ASSUMED x0.70 [ceramic_pad] | estimate PAD AlN 1 mm (CUSTOM): ESTIMATE: AlN ceramic insulator 15.9 x 20.9 mm + | low |
| 10 | 203 | 4 | 002637115 | 6 | 24.00 | 2.5 | 4.8 | ASSUMED x0.80 [protection_estimate] | estimate 002637115: ESTIMATE: ETI CH14x51 gPV 36 A 1000 V d.c. fuse link (varist | low |
| 11 | 311 | 2 | N-C-644025 | 10.9 | 21.80 | 2.2 | 9.265 | ASSUMED x0.85 [custom_magnetic_large] | estimate N-C-644025: ESTIMATE (sim/magnetics.py design_port_cm_choke.json rev M2 | low |
| 12 | 248 | 72 | PMEG4010CEJ | 0.3026 | 21.79 | 2.2 | 0.3026 | REAL: LCSC C50704 @1000+ break (annual qty 360000) | LCSC C50704 @1000+ (2026-10-04) | high |
| 13 | 9 | 4 | busbar (CUSTOM) | 5 | 20.00 | 2.0 | 4.25 | ASSUMED x0.85 [custom_mech] | estimate busbar (CUSTOM): ESTIMATE: copper busbar terminal-to-board for 135 A, 1 | low |
| 14 | 304 | 18 | 7461057 | 1.1 | 19.80 | 2.0 | 0.935 | ASSUMED x0.85 [asia_part_estimate] | estimate 7461057: ESTIMATE: Wurth REDCUBE press-fit M3 terminal 100 A, no readab | low |
| 15 | 258 | 3 | STK-HO/A 75 | 5 | 15.00 | 1.5 | 4.25 | ASSUMED x0.85 [asia_part_estimate] | estimate STK-HO/A 75: ESTIMATE (architect's list, STK-HO/A 130 RFQ estimate 5.00 | low |
| 16 | 251 | 1 | G7L-2A-X DC24 | 12.71 | 12.71 | 1.3 | 10.17 | ASSUMED x0.80 [protection_estimate] | estimate G7L-2A-X DC24: ESTIMATE: no price for the -X variant; DigiKey G7L-2A-BU | low |
| 17 | 264 | 7 | OPA2388IDR | 1.475 | 10.32 | 1.1 | 1.475 | REAL: TI.com OPA2388IDR @1000+ break (annual qty 35000) | TI.com OPA2388IDR @1000+ (2026-10-04) | high |
| 18 | 276 | 7 | TLV3502AIDCNR | 1.448 | 10.14 | 1.0 | 1.448 | REAL: LCSC C48618 @1000+ break (annual qty 35000) | LCSC C48618 @1000+ (2026-10-04) | high |
| 19 | 310 | 2 | X 2.2u 1300V RFQ | 4.5 | 9.00 | 0.9 | 3.6 | ASSUMED x0.80 [protection_estimate] | estimate X 2.2u 1300V RFQ: ESTIMATE: same value, voltage and pitch as KEMET C4AQ | low |
| 20 | 12 | 1 | AUX-T1 75 W (CUSTOM) | 8.8 | 8.80 | 0.9 | 5.896 | ASSUMED x0.67 [custom_magnetic_small] | estimate AUX-T1 75 W (CUSTOM): ESTIMATE (sim/magnetics.py design_aux75_transform | low |
| 21 | 212 | 18 | FCSA3DS225K050IC90BE3 | 0.45 | 8.10 | 0.8 | 0.3825 | ASSUMED x0.85 [asia_part_estimate] | estimate FCSA3DS225K050IC90BE3: ESTIMATE (architect's list 0.45): Jianghai 2.2 u | low |
| 22 | 1 | 1 | DC terminal A+ 135 A (CUSTOM) | 8 | 8.00 | 0.8 | 6.8 | ASSUMED x0.85 [custom_mech] | estimate DC terminal * 135 A (CUSTOM): ESTIMATE: M8 copper stud feed-through 200 | low |
| 23 | 2 | 1 | DC terminal A- 135 A (CUSTOM) | 8 | 8.00 | 0.8 | 6.8 | ASSUMED x0.85 [custom_mech] | estimate DC terminal * 135 A (CUSTOM): ESTIMATE: M8 copper stud feed-through 200 | low |
| 24 | 3 | 1 | DC terminal B+ 135 A (CUSTOM) | 8 | 8.00 | 0.8 | 6.8 | ASSUMED x0.85 [custom_mech] | estimate DC terminal * 135 A (CUSTOM): ESTIMATE: M8 copper stud feed-through 200 | low |
| 25 | 4 | 1 | DC terminal B- 135 A (CUSTOM) | 8 | 8.00 | 0.8 | 6.8 | ASSUMED x0.85 [custom_mech] | estimate DC terminal * 135 A (CUSTOM): ESTIMATE: M8 copper stud feed-through 200 | low |

### Largest estimates (where the uncertainty sits)

| BOM item | qty | value / MPN | ext USD | % of BOM | conf | basis |
|---|---|---|---|---|---|---|
| 6 | 3 | L_CELL 224uH (CUSTOM) | 121.50 | 12.4 | low | L_CELL 224uH (CUSTOM): ESTIMATE (sim/magnetics.py design_pv_inductor.json rev M2, design to cost D-044 / D-048): 2 x POCO NPC290026 16 + 0.54 kg solid |
| 208 | 2 | HFE82V-300C/1000-24-H-C5-1 | 115.00 | 11.7 | low | HFE82V-300C/1000-24-H-C5-1: ESTIMATE: no price for the 1000 V / 24 V variant; the same HFE82V-300C is 57.50 USD at 10 in a made-in-china.com listing ( |
| 214 | 13 | FCSA3DS456K050H8F9DE3 | 70.20 | 7.2 | low | FCSA3DS456K050H8F9DE3: ESTIMATE (architect's list 5.40): Jianghai CBB-type 45 uF 1300 VDC, no Chinese price found; Faratronic C3D1X505KB00C00 0.557 US |
| 209 | 2 | HPE501/000B100-250 | 36.00 | 3.7 | low | HPE501/000B100-250: ESTIMATE: Hongfa HPE501 size-000 aR 250 A 1000 V DC square-body fuse, no public price; taken as the cost-first BOM estimate (gen/d |
| 11 | 1 | heatsink 24 x TO-247 (CUSTOM) | 24.30 | 2.5 | low | heatsink 24 x TO-247 (CUSTOM): ESTIMATE: one Al extrusion of about 3.6 kg for 24 devices (R_sa <= 0.06 K/W at 400 m3/h, ARCHITECTURE-COSTFIRST section |
| 8 | 24 | PAD AlN 1 mm (CUSTOM) | 24.00 | 2.5 | low | PAD AlN 1 mm (CUSTOM): ESTIMATE: AlN ceramic insulator 15.9 x 20.9 mm + overhang, 1.0 mm: sim/out/pv_design/cell_spec.json cost_usd insulators 8.0 USD |
| 203 | 4 | 002637115 | 24.00 | 2.5 | low | 002637115: ESTIMATE: ETI CH14x51 gPV 36 A 1000 V d.c. fuse link (varistor branch fuse); ETI publishes no prices; engineering estimate for a 14x51 PV.. |
| 311 | 2 | N-C-644025 | 21.80 | 2.2 | low | N-C-644025: ESTIMATE (sim/magnetics.py design_port_cm_choke.json rev M2, D-048): cased flat-mu nanocrystalline ring, 0.27 kg at 20 USD/kg 6.93 + case. |

### Lines with no price

| item | qty | value / MPN | sourcing | what is missing |
|---|---|---|---|---|
| 277 | 5 | TLV9024PWR | ORDERABLE | no row with a price in prices.csv and no estimate in cost_estimates.csv |

## PV-P100-110

Total BOM cost **1171.28 USD at catalogue prices = 11.7 USD per kW at 100 kW / 10.6 USD per kW at 110 kW**; **980.74 USD at a 5000-unit build = 9.8 USD per kW at 100 kW / 8.9 USD per kW at 110 kW**. Lines: 310 (303 purchased-part lines; 7 NOPART lines such as test points and net ties are not costed).

### Evidence behind the catalogue total

| basis | lines | parts | USD | share of the costed total |
|---|---|---|---|---|
| real price of the part (looked up) | 83 | 726 | 382.54 | 32.7 % |
| chip-passive class rule (price of a real LCSC example part of the same class) | 163 | 1529 | 43.72 | 3.7 % |
| engineering estimate with stated basis | 55 | 336 | 745.02 | 63.6 % |
| no price at all (UNPRICED, not in the total) | 2 | 7 | not known | not in the total |

### The 5000-unit view

| basis of the 5000-unit price | lines | USD at 5000 units | share of the 5000-unit total |
|---|---|---|---|
| REAL: a published price at a break >= 1000 pieces | 238 | 152.05 | 15.5 % |
| ASSUMED: catalogue price x factor of volume_factors.csv | 63 | 828.69 | 84.5 % |

The 5000-unit total is 83.7 % of the catalogue total.

| factor class used | factor | lines | catalogue USD | USD at 5000 units | confidence |
|---|---|---|---|---|---|
| short_table | 0.85 | 5 | 221.78 | 188.52 | medium |
| protection_estimate | 0.80 | 9 | 217.11 | 173.69 | low |
| asia_part_estimate | 0.85 | 31 | 188.53 | 160.25 | low |
| custom_magnetic_large | 0.85 | 2 | 183.80 | 156.23 | low |
| custom_mech | 0.85 | 9 | 103.26 | 87.77 | low |
| single_piece_list | 0.52 | 2 | 48.25 | 25.09 | medium |
| ceramic_pad | 0.70 | 1 | 32.00 | 22.40 | low |
| custom_magnetic_small | 0.67 | 2 | 17.52 | 11.74 | low |
| custom_harness | 0.80 | 1 | 2.80 | 2.24 | low |
| chip_passive_class | 0.96 | 1 | 0.80 | 0.77 | medium |

### Split by function group

Groups are assigned by rule from the line's description and the board that carries it (approximate; see group_of in gen/cost.py).

| group | catalogue USD | % of BOM | USD at 5000 units | lines | of which estimated |
|---|---|---|---|---|---|
| protection (fuses, contactors, SPD, TVS) | 269.40 | 23.0 | 218.63 | 22 | 13 |
| magnetics | 207.30 | 17.7 | 173.05 | 9 | 8 |
| power semiconductors | 164.77 | 14.1 | 140.05 | 2 | 1 |
| capacitors | 131.59 | 11.2 | 116.04 | 56 | 56 |
| thermal | 115.87 | 9.9 | 93.69 | 5 | 3 |
| gate drive | 108.94 | 9.3 | 82.33 | 31 | 6 |
| connectors + harness | 51.91 | 4.4 | 44.02 | 11 | 6 |
| control + communications | 45.92 | 3.9 | 45.07 | 31 | 5 |
| sensing | 40.02 | 3.4 | 34.02 | 8 | 5 |
| resistors + other board parts | 20.03 | 1.7 | 18.79 | 115 | 114 |
| auxiliary supply | 15.53 | 1.3 | 15.06 | 11 | 1 |
| **total BOM** | **1171.28** | 100 | **980.74** | 301 | |
| PCB / mechanics outside the BOM (rough, not in the BOM total) | 428.28 | | 361.06 | | all assumed |

### Outside the BOM (rough figures, not part of the BOM total)

| item | catalogue USD | USD at 5000 units | assumption (see gen/data/cost_estimates.csv outside: rows) |
|---|---|---|---|
| bare PCB PV-CTL x1 | 8.48 | 7.21 | 290 parts per board x 0.65 cm2 = 188 cm2 x 0.045 USD/cm2 |
| bare PCB PV-PWR-4 x1 | 200.33 | 170.28 | 2283 parts per board x 0.65 cm2 = 1484 cm2 x 0.045 USD/cm2 x 3 (6-layer heavy copper) |
| board assembly (2573 placements, 2 boards) | 59.46 | 47.57 | 0.020 USD per placement + 4.0 USD per board |
| enclosure / sheet metal / packaging | 100.00 | 85.00 | see cost_estimates.csv outside:enclosure |
| final assembly, test and burn-in | 60.00 | 51.00 | see cost_estimates.csv outside:final_assembly_test |
| **BOM + outside, rough** | **1599.56** (16.0 USD per kW at 100 kW / 14.5 USD per kW at 110 kW) | **1341.80** (13.4 USD per kW at 100 kW / 12.2 USD per kW at 110 kW) | |

### Top 25 cost lines (catalogue)

| # | BOM item | qty | value / MPN | unit USD | ext USD | % of BOM | unit USD at 5000 | basis at 5000 units | basis (catalogue) | conf |
|---|---|---|---|---|---|---|---|---|---|---|
| 1 | 255 | 32 | SG2M040170HJ | 5.071 | 162.27 | 13.9 | 4.31 | ASSUMED x0.85 [short_table] | LCSC C42456100 @90+ (2026-10-05) | high |
| 2 | 6 | 4 | L_CELL 224uH (CUSTOM) | 40.5 | 162.00 | 13.8 | 34.42 | ASSUMED x0.85 [custom_magnetic_large] | estimate L_CELL 224uH (CUSTOM): ESTIMATE (sim/magnetics.py design_pv_inductor.js | low |
| 3 | 206 | 2 | HFE82V-300C/1000-24-H-C5-1 | 57.5 | 115.00 | 9.8 | 46 | ASSUMED x0.80 [protection_estimate] | estimate HFE82V-300C/1000-24-H-C5-1: ESTIMATE: no price for the 1000 V / 24 V va | low |
| 4 | 212 | 16 | FCSA3DS456K050H8F9DE3 | 5.4 | 86.40 | 7.4 | 4.59 | ASSUMED x0.85 [asia_part_estimate] | estimate FCSA3DS456K050H8F9DE3: ESTIMATE (architect's list 5.40): Jianghai CBB-t | low |
| 5 | 198 | 4 | AFB1224SHE-F00 | 12.85 | 51.40 | 4.4 | 10.92 | ASSUMED x0.85 [short_table] | Master Electronics (web-search result; page not read)  @504+ (2026-10-04) | medium |
| 6 | 220 | 16 | NSI6651ASC-Q1SWR | 2.978 | 47.64 | 4.1 | 1.548 | ASSUMED x0.52 [single_piece_list] | LCSC C33959952 @1+ (2026-10-04) single-piece price | high |
| 7 | 207 | 2 | HPE501/000B100-250 | 18 | 36.00 | 3.1 | 14.4 | ASSUMED x0.80 [protection_estimate] | estimate HPE501/000B100-250: ESTIMATE: Hongfa HPE501 size-000 aR 250 A 1000 V DC | low |
| 8 | 8 | 32 | PAD AlN 1 mm (CUSTOM) | 1 | 32.00 | 2.7 | 0.7 | ASSUMED x0.70 [ceramic_pad] | estimate PAD AlN 1 mm (CUSTOM): ESTIMATE: AlN ceramic insulator 15.9 x 20.9 mm + | low |
| 9 | 11 | 1 | heatsink 32 x TO-247 (CUSTOM) | 31.1 | 31.10 | 2.7 | 26.43 | ASSUMED x0.85 [custom_mech] | estimate heatsink 32 x TO-247 (CUSTOM): ESTIMATE: one Al extrusion of about 4.8  | low |
| 10 | 246 | 96 | PMEG4010CEJ | 0.3026 | 29.05 | 2.5 | 0.3026 | REAL: LCSC C50704 @1000+ break (annual qty 480000) | LCSC C50704 @1000+ (2026-10-04) | high |
| 11 | 9 | 4 | busbar (CUSTOM) | 6 | 24.00 | 2.0 | 5.1 | ASSUMED x0.85 [custom_mech] | estimate busbar (CUSTOM)@PV-P100-110: ESTIMATE: as the 135 A busbar with 60 mm2  | low |
| 12 | 201 | 4 | 002637115 | 6 | 24.00 | 2.0 | 4.8 | ASSUMED x0.80 [protection_estimate] | estimate 002637115: ESTIMATE: ETI CH14x51 gPV 36 A 1000 V d.c. fuse link (varist | low |
| 13 | 303 | 20 | 7461057 | 1.1 | 22.00 | 1.9 | 0.935 | ASSUMED x0.85 [asia_part_estimate] | estimate 7461057: ESTIMATE: Wurth REDCUBE press-fit M3 terminal 100 A, no readab | low |
| 14 | 310 | 2 | N-C-644025 | 10.9 | 21.80 | 1.9 | 9.265 | ASSUMED x0.85 [custom_magnetic_large] | estimate N-C-644025: ESTIMATE (sim/magnetics.py design_port_cm_choke.json rev M2 | low |
| 15 | 256 | 4 | STK-HO/A 75 | 5 | 20.00 | 1.7 | 4.25 | ASSUMED x0.85 [asia_part_estimate] | estimate STK-HO/A 75: ESTIMATE (architect's list, STK-HO/A 130 RFQ estimate 5.00 | low |
| 16 | 249 | 1 | G7L-2A-X DC24 | 12.71 | 12.71 | 1.1 | 10.17 | ASSUMED x0.80 [protection_estimate] | estimate G7L-2A-X DC24: ESTIMATE: no price for the -X variant; DigiKey G7L-2A-BU | low |
| 17 | 1 | 1 | DC terminal A+ 180 A (CUSTOM) | 11 | 11.00 | 0.9 | 9.35 | ASSUMED x0.85 [custom_mech] | estimate DC terminal * 180 A (CUSTOM): ESTIMATE: M10 stud feed-through 250 A wit | low |
| 18 | 2 | 1 | DC terminal A- 180 A (CUSTOM) | 11 | 11.00 | 0.9 | 9.35 | ASSUMED x0.85 [custom_mech] | estimate DC terminal * 180 A (CUSTOM): ESTIMATE: M10 stud feed-through 250 A wit | low |
| 19 | 3 | 1 | DC terminal B+ 180 A (CUSTOM) | 11 | 11.00 | 0.9 | 9.35 | ASSUMED x0.85 [custom_mech] | estimate DC terminal * 180 A (CUSTOM): ESTIMATE: M10 stud feed-through 250 A wit | low |
| 20 | 4 | 1 | DC terminal B- 180 A (CUSTOM) | 11 | 11.00 | 0.9 | 9.35 | ASSUMED x0.85 [custom_mech] | estimate DC terminal * 180 A (CUSTOM): ESTIMATE: M10 stud feed-through 250 A wit | low |
| 21 | 210 | 24 | FCSA3DS225K050IC90BE3 | 0.45 | 10.80 | 0.9 | 0.3825 | ASSUMED x0.85 [asia_part_estimate] | estimate FCSA3DS225K050IC90BE3: ESTIMATE (architect's list 0.45): Jianghai 2.2 u | low |
| 22 | 262 | 7 | OPA2388IDR | 1.475 | 10.32 | 0.9 | 1.475 | REAL: TI.com OPA2388IDR @1000+ break (annual qty 35000) | TI.com OPA2388IDR @1000+ (2026-10-04) | high |
| 23 | 274 | 7 | TLV3502AIDCNR | 1.448 | 10.14 | 0.9 | 1.448 | REAL: LCSC C48618 @1000+ break (annual qty 35000) | LCSC C48618 @1000+ (2026-10-04) | high |
| 24 | 143 | 16 | 4.7n 2000V | 0.6248 | 10.00 | 0.9 | 0.6248 | REAL: class example LCSC C1021538 @1000+ break (annual qty 80000) | estimate class:mlcc_2220_c0g_2kv_le100n: GENERIC class rule, reel price of a typ | high |
| 25 | 309 | 2 | X 2.2u 1300V RFQ | 4.5 | 9.00 | 0.8 | 3.6 | ASSUMED x0.80 [protection_estimate] | estimate X 2.2u 1300V RFQ: ESTIMATE: same value, voltage and pitch as KEMET C4AQ | low |

### Largest estimates (where the uncertainty sits)

| BOM item | qty | value / MPN | ext USD | % of BOM | conf | basis |
|---|---|---|---|---|---|---|
| 6 | 4 | L_CELL 224uH (CUSTOM) | 162.00 | 13.8 | low | L_CELL 224uH (CUSTOM): ESTIMATE (sim/magnetics.py design_pv_inductor.json rev M2, design to cost D-044 / D-048): 2 x POCO NPC290026 16 + 0.54 kg solid |
| 206 | 2 | HFE82V-300C/1000-24-H-C5-1 | 115.00 | 9.8 | low | HFE82V-300C/1000-24-H-C5-1: ESTIMATE: no price for the 1000 V / 24 V variant; the same HFE82V-300C is 57.50 USD at 10 in a made-in-china.com listing ( |
| 212 | 16 | FCSA3DS456K050H8F9DE3 | 86.40 | 7.4 | low | FCSA3DS456K050H8F9DE3: ESTIMATE (architect's list 5.40): Jianghai CBB-type 45 uF 1300 VDC, no Chinese price found; Faratronic C3D1X505KB00C00 0.557 US |
| 207 | 2 | HPE501/000B100-250 | 36.00 | 3.1 | low | HPE501/000B100-250: ESTIMATE: Hongfa HPE501 size-000 aR 250 A 1000 V DC square-body fuse, no public price; taken as the cost-first BOM estimate (gen/d |
| 8 | 32 | PAD AlN 1 mm (CUSTOM) | 32.00 | 2.7 | low | PAD AlN 1 mm (CUSTOM): ESTIMATE: AlN ceramic insulator 15.9 x 20.9 mm + overhang, 1.0 mm: sim/out/pv_design/cell_spec.json cost_usd insulators 8.0 USD |
| 11 | 1 | heatsink 32 x TO-247 (CUSTOM) | 31.10 | 2.7 | low | heatsink 32 x TO-247 (CUSTOM): ESTIMATE: one Al extrusion of about 4.8 kg for 32 devices (R_sa <= 0.049 K/W): 4.8 kg x 4.7 USD/kg = 22.6 + machining 4 |
| 9 | 4 | busbar (CUSTOM) | 24.00 | 2.0 | low | busbar (CUSTOM)@PV-P100-110: ESTIMATE: as the 135 A busbar with 60 mm2 for 180 A (architect's list: qty 4 at 6.00 USD) |
| 201 | 4 | 002637115 | 24.00 | 2.0 | low | 002637115: ESTIMATE: ETI CH14x51 gPV 36 A 1000 V d.c. fuse link (varistor branch fuse); ETI publishes no prices; engineering estimate for a 14x51 PV.. |

### Lines with no price

| item | qty | value / MPN | sourcing | what is missing |
|---|---|---|---|---|
| 275 | 5 | TLV9024PWR | ORDERABLE | no row with a price in prices.csv and no estimate in cost_estimates.csv |
| 276 | 2 | TLV9024PWR | ORDERABLE | no row with a price in prices.csv and no estimate in cost_estimates.csv |

## PCS-P125

Total BOM cost **1588.90 USD at catalogue prices = 12.7 USD per kW at 125 kW**; **1349.14 USD at a 5000-unit build = 10.8 USD per kW at 125 kW**. Lines: 342 (335 purchased-part lines; 7 NOPART lines such as test points and net ties are not costed).

### Evidence behind the catalogue total

| basis | lines | parts | USD | share of the costed total |
|---|---|---|---|---|
| real price of the part (looked up) | 90 | 460 | 331.30 | 20.9 % |
| chip-passive class rule (price of a real LCSC example part of the same class) | 174 | 1125 | 38.64 | 2.4 % |
| engineering estimate with stated basis | 70 | 449 | 1218.96 | 76.7 % |
| no price at all (UNPRICED, not in the total) | 1 | 5 | not known | not in the total |

### The 5000-unit view

| basis of the 5000-unit price | lines | USD at 5000 units | share of the 5000-unit total |
|---|---|---|---|
| REAL: a published price at a break >= 1000 pieces | 256 | 122.49 | 9.1 % |
| ASSUMED: catalogue price x factor of volume_factors.csv | 78 | 1226.65 | 90.9 % |

The 5000-unit total is 84.9 % of the catalogue total.

| factor class used | factor | lines | catalogue USD | USD at 5000 units | confidence |
|---|---|---|---|---|---|
| custom_mech | 0.85 | 15 | 679.56 | 577.63 | low |
| asia_part_estimate | 0.85 | 41 | 334.03 | 283.93 | low |
| short_table | 0.85 | 5 | 226.19 | 192.26 | medium |
| protection_estimate | 0.80 | 10 | 176.63 | 141.30 | low |
| single_piece_list | 0.52 | 2 | 18.47 | 9.61 | medium |
| custom_magnetic_small | 0.67 | 2 | 15.34 | 10.28 | low |
| custom_magnetic_large | 0.85 | 1 | 10.90 | 9.27 | low |
| custom_harness | 0.80 | 1 | 2.50 | 2.00 | low |
| chip_passive_class | 0.96 | 1 | 0.40 | 0.38 | medium |

### Split by function group

Groups are assigned by rule from the line's description and the board that carries it (approximate; see group_of in gen/cost.py).

| group | catalogue USD | % of BOM | USD at 5000 units | lines | of which estimated |
|---|---|---|---|---|---|
| resistors + other board parts | 604.18 | 38.0 | 518.81 | 155 | 133 |
| protection (fuses, contactors, SPD, TVS) | 254.22 | 16.0 | 207.73 | 24 | 15 |
| power semiconductors | 185.05 | 11.6 | 157.29 | 2 | 1 |
| connectors + harness | 149.59 | 9.4 | 127.19 | 15 | 9 |
| thermal | 125.42 | 7.9 | 106.60 | 7 | 5 |
| capacitors | 90.90 | 5.7 | 80.80 | 57 | 57 |
| sensing | 43.75 | 2.8 | 37.18 | 9 | 5 |
| gate drive | 42.84 | 2.7 | 30.96 | 17 | 5 |
| control + communications | 35.30 | 2.2 | 34.59 | 27 | 5 |
| magnetics | 32.22 | 2.0 | 24.62 | 8 | 7 |
| auxiliary supply | 25.45 | 1.6 | 23.37 | 13 | 2 |
| **total BOM** | **1588.90** | 100 | **1349.14** | 334 | |
| PCB / mechanics outside the BOM (rough, not in the BOM total) | 297.49 | | 250.44 | | all assumed |

### Outside the BOM (rough figures, not part of the BOM total)

| item | catalogue USD | USD at 5000 units | assumption (see gen/data/cost_estimates.csv outside: rows) |
|---|---|---|---|
| bare PCB PCS-CTL-3W x1 | 9.59 | 8.15 | 328 parts per board x 0.65 cm2 = 213 cm2 x 0.045 USD/cm2 |
| bare PCB PCS-PWR x1 | 49.49 | 42.07 | 1692 parts per board x 0.65 cm2 = 1100 cm2 x 0.045 USD/cm2 |
| board assembly (2020 placements, 2 boards) | 48.40 | 38.72 | 0.020 USD per placement + 4.0 USD per board |
| enclosure / sheet metal / packaging | 120.00 | 102.00 | see cost_estimates.csv outside:enclosure |
| final assembly, test and burn-in | 70.00 | 59.50 | see cost_estimates.csv outside:final_assembly_test |
| **BOM + outside, rough** | **1886.39** (15.1 USD per kW at 125 kW) | **1599.59** (12.8 USD per kW at 125 kW) | |
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

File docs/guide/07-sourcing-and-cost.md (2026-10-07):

<!-- breadcrumb --> [Home](../../README.md) › [Documentation](../README.md) › Sourcing and cost

# 💰 Sourcing and cost

> Where the parts come from, how firm each price is, what the products cost at catalogue prices and at a 5,000-unit build, and how that compares with the owner's price benchmark.






---

> [!IMPORTANT]
> **No part has been bought or quoted.** A price here is either a looked-up catalogue reading (URL and date in
> [`gen/data/prices.csv`](../../gen/data/prices.csv)), a class rule for chip passives, or an engineering estimate with
> its basis written next to it ([`gen/data/cost_estimates.csv`](../../gen/data/cost_estimates.csv)). About two thirds
> (66 %) of the PV-P75 catalogue total is estimate. Read every figure on this page as *estimated*.

## 💰 The costs in one table

<!-- BEGIN:cost-summary -->

| Product | What the figure is | kW | Catalogue USD | USD/kW | 5,000 units USD | USD/kW | Evidence | 5k ÷ benchmark-equivalent BOM |
|---|---|---:|---:|---:|---:|---:|---|---:|
| **PV-P75** | BOM of drawn boards (PV-PWR + PV-CTL) | 75 | **980** | 13.1 | **820** | 10.9 | 66 % of catalogue on estimates · 16 % of 5k on published breaks · 1 unpriced line (lower bound) | 2.0× (≈ 410 USD) |
| **PV-P100/110** | BOM of drawn boards (PV-PWR-4 + PV-CTL) | 100 / 110 | 1,171 | 11.7 / 10.6 | 981 | 9.8 / 8.9 | 64 % of catalogue on estimates · 16 % of 5k on published breaks · 2 unpriced lines (lower bound) | 1.8× / 1.8× |
| **PCS-P125** | BOM of drawn boards, three-wire (PCS-PWR + PCS-CTL-3W) | 125 | 1,589 | 12.7 | 1,349 | 10.8 | 77 % of catalogue on estimates · 9 % of 5k on published breaks · 1 unpriced line (lower bound) | 1.8× (≈ 744 USD) |
| **PCS-P125-4W** | BOM of drawn boards, four-wire (PCS-PWR-4W + PCS-CTL-4W) | 125 | 1,926 | 15.4 | 1,636 | 13.1 | 75 % of catalogue on estimates · 9 % of 5k on published breaks · 2 unpriced lines (lower bound) | 2.2× (≈ 744 USD) |
| PCS-P125 | design study, 3-wire (two-level, pcs_spec.json); the drawn boards above cost more (D-063) | 125 | 1,431 | 11.4 | 1,149 | 9.2 | 5 % of 5k on published prices | — |
| PCS-P125 | design study, 4-wire (two-level, pcs_spec.json); the drawn boards above cost more (D-063) | 125 | 1,731 | 13.8 | 1,392 | 11.1 | not stated for 4-wire | — |
| PV-P75 earlier platform | BOM of drawn boards (8 boards) | 75 | 2,836 | 37.8 | 2,275 | 30.3 | 51 % of catalogue on estimates · 17 % of 5k on published breaks · 7 unpriced lines (lower bound) | 5.5× |
| DAB-D60 earlier platform | BOM of drawn boards (5 boards) | 60 | 3,615 | 60.2 | 2,927 | 48.8 | 48 % of catalogue on estimates · 12 % of 5k on published breaks · 3 unpriced lines (lower bound) | 7.5× |
| PCS-P125 | three-level T-type estimate, **withdrawn by D-053** | 125 | 1,037 | 8.3 | 801 | 6.4 | — | — |

<sub>Generated by <a href="../assets/figures_overview.py">figures_overview.py</a> from <a href="../../bom/COST.md">bom/*_costed_BOM.csv</a>, <a href="../../sim/out/pcs_design/pcs_spec.json">pcs_spec.json</a> and <a href="../../gen/data/costfirst_pcs_bom.csv">costfirst_pcs_bom.csv</a>; benchmark arithmetic from <a href="../../gen/cost.py">gen/cost.py</a>. Do not edit between the markers.</sub>

<!-- END:cost-summary -->

**How to read it.** *Catalogue* = the price break at the highest quantity up to 1,000 pieces from the best source
(LCSC first). *5,000 units* = a published break of at least 1,000 pieces where one exists (REAL), otherwise the
catalogue price times a factor per part class from [`gen/data/volume_factors.csv`](../../gen/data/volume_factors.csv)
(ASSUMED). *Benchmark-equivalent BOM*: see [Against the benchmark](#-against-the-benchmark) below. The full model, line
by line, is [`bom/COST.md`](../../bom/COST.md).

**Note on the PCS ratio.** Both inverter builds are now drawn and priced by `gen/cost.py`
([D-074](../requirements/DECISIONS.md)): PCS-P125 (three-wire) 1,589 USD at catalogue prices and 1,349 USD at 5,000 units
(10.8 USD/kW), PCS-P125-4W (four-wire) 1,926 / 1,636 USD (13.1 USD/kW; a lower bound, two lines unpriced). The
design-study rows below them are `pcs_spec.json`'s, for reference. Two benchmark adjustments exist for the inverter:
`gen/cost.py` scales the benchmark BOM by the rated **DC port** current (250 A) and arrives at 744 USD, the figure in the
table's last column (1.8× / 2.2×); [ARCHITECTURE-PCS.md §12](../requirements/ARCHITECTURE-PCS.md#12-cost--both-products-catalogue-and-5000-units-against-the-benchmark)
scales it by the **AC-side** current of a 125 kW / 400 V unit and arrives at about 690 USD (about 2.0× / 2.4×; our
arithmetic on the two records). Neither is a quotation.

**Cost movements of 2026-10-06** (catalogue / 5,000 units, [bom/COST.md](../../bom/COST.md)):

| What moved | Before | After | Why |
|---|---:|---:|---|
| PV-CTL control board, 1 ku | 15.89 USD | 17.72 USD (PV-P75 assembly 17.22) | relay 0.62, 4-channel isolator 0.60, recorder flash 0.43 USD, less the 0.11 USD EEPROM ([D-075](../requirements/DECISIONS.md)); the Ethernet option adds 3.89 USD with assembly where fitted |
| PV-P75 module | 976 / 817 USD | **978 / 819 USD** | the control board's additions |
| PV-P100/110 module | 1,167 / 977 USD | **1,169 / 979 USD** | the same |
| PCS-P125 module | 1,557 / 1,322 USD | **1,588 / 1,348 USD** | the AC start-up path (24.80 / 20.57 USD, [D-074](../requirements/DECISIONS.md)) and the control board with the Ethernet bridge fitted (PCS-CTL 21.32 USD three-wire at 1 ku, [design check](../../hardware/PCS-CTL/outputs/PCS-CTL_design_check.txt)) |
| PCS-P125-4W module | — | **1,924 / 1,635 USD** | new: fourth leg, neutral inductor, 4-pole contactors, fourth fan and heatsink section; 1,924 / 1,635 USD before [D-076](../requirements/DECISIONS.md)'s 200 Ω precharge resistor, whose RFQ line has no estimate row and is now unpriced (so the total fell by that line's 4.00 / 3.20 USD) |
| Auxiliary block AUX-75 | 36.42 USD | 36.42 USD | re-rated to 30 / 48 W live and 42.2 / 64.2 W SELV with the same parts list and no cost delta ([D-076](../requirements/DECISIONS.md)) |

**Cost movement of 2026-10-07 — the DESAT string** ([D-081](../requirements/DECISIONS.md), review R4 E01): two Vishay
BYG23T-M3/TR (1,300 V) per gate-drive channel replace the US1MH (1,000 V) on both 1,700 V presets — the inverter keeps two
diodes per channel, the PV phases go from three to two. The diode lines (catalogue / 5,000 units):

| Module | Diodes, before → after | Diode lines | Module BOM, before → after |
|---|---|---:|---:|
| PV-P75 | 36 US1MH → 24 BYG23T | +1.84 / +1.59 USD | 977.71 / 818.82 → **979.55 / 820.41 USD** |
| PV-P100/110 | 48 US1MH → 32 BYG23T | +2.46 / +2.12 USD | 1,168.82 / 978.62 → **1,171.28 / 980.74 USD** |
| PCS-P125 | 12 US1MH → 12 BYG23T | +1.12 / +0.96 USD | 1,587.79 / 1,348.18 → **1,588.90 / 1,349.14 USD** |
| PCS-P125-4W | 16 US1MH → 16 BYG23T | +1.49 / +1.28 USD | 1,924.28 / 1,634.70 → **1,925.77 / 1,635.98 USD** |

<sub>BYG23T-M3/TR: LCSC C145454, 0.1257 USD at 500+ (the catalogue basis) and 0.1079 USD at 5,400+ (a published break,
REAL), read 2026-10-07 ([prices.csv](../../gen/data/prices.csv)); the US1MH it replaces was an estimate of 0.0326 /
0.0277 USD. Source: [bom/COST.md](../../bom/COST.md) and the four `*_costed_BOM.csv`. The module difference can differ by
0.01 USD from the diode lines (rounding). The review priced this option only as a per-diode premium times 12 / 16
diodes ([review_r4.csv](../../gen/data/review_r4.csv) E01, "no quote"); the premium read here is about 0.08 USD per diode
at 5,000 units.</sub>

The earlier steps — the live LCSC price of the SG2M040170HJ (5.07 USD at 90+ instead of the 4.07 USD estimate,
[D-069](../requirements/DECISIONS.md)), the inverter's frozen phase-current sensor and its six removed DESAT diodes
([D-067](../requirements/DECISIONS.md)) — had moved PV-P75 952 → 976 / 796 → 817 USD, PV-P100-110 1,135 → 1,167 /
949 → 977 USD and PCS-P125 1,521 → 1,557 / 1,292 → 1,322 USD on 2026-10-05.

---

## 📐 Sourcing policy

The owner's instruction of 2026-10-04 ([REQUIREMENTS.md §7](../requirements/REQUIREMENTS.md#7-sourcing-cost-and-magnetics-owner-instruction-2026-10-04))
and the rules derived from it in the [decision register](../requirements/DECISIONS.md):

| Rule | What it means in practice | Source |
|---|---|---|
| Asian, preferably Chinese, makers for every cost-driving part | SiC switches, drivers, capacitors, contactors, fuses, sensors and magnetic materials; the TI C2000 controller stays | SRC-1, D-031 |
| "Proper, verified and reliable" | complete datasheet on file, documented qualification, an established maker; availability checked on LCSC | SRC-2 |
| Primary **and** alternate maker per power-switch position | the design is done for the worse of the two; a candidate that fails a design check is not an alternate | D-037, D-043 |
| Second source for everything else | 107 lines studied: 38 drop-in, 14 functional, 53 without a properly documented Asian part, 21 adopted | D-040 |
| Kept on purpose | E-stop input isolators, CAN / RS-485 isolators and a few others where the Asian part is weaker or has no obtainable datasheet (earlier platform) | D-040 |
| Reliability is not traded for cost | derating rules, hardware protection and single-fault behaviour stay | SRC-4, D-050 |
| Chinese power modules | catalogued as request-for-quotation alternates; the designs stay on paralleled discretes | D-055 |
| Costs reported at a 5,000-unit build too | with the share of the figure that rests on real volume prices | SRC-6 |

## Cost-driving parts and the evidence behind them

Evidence is graded twice: **qualification** (is the part proven?) and **price** (how firm is the number?).

| Function | Maker · part | Qualification evidence | Price evidence | Open point |
|---|---|---|---|---|
| SiC MOSFET 1700 V, 40 mΩ (24 per PV-P75, 36 per PCS-P125) | Sichain · SG2M040170HJ | **none published** — a release condition | LCSC C42456100: 5.07 USD at 90+ (6.73 at 1), 418 in stock, read 2026-10-05 — a catalogue reading, no quote | qualified fallback: Microchip MSC035SMA170B4 as an assembly variant ([D-043](../requirements/DECISIONS.md)); for the inverter, matched devices per switch ([D-067](../requirements/DECISIONS.md)) |
| Isolated gate driver (12 per PV-P75) | NOVOSENSE · NSI6651ASC-Q1 | AEC-Q100 grade 1; VDE 0884-17, UL 1577, CQC granted | stocked at LCSC (single-piece reading) | impulse rating 6,250 V against 8 kV reinforced: passes only with the surge-arrester credit ([D-043](../requirements/DECISIONS.md)) |
| Gate-drive bias | TI · SN6505B + custom transformer (DMEGC EP17 core) | TI datasheet; transformer is a new custom part | TI.com 1ku list; transformer estimate | partial-discharge test on samples (ARCHITECTURE-COSTFIRST R-06) |
| DC contactor 300 A / 1000 V (2 per PV-P75) | Hongfa · HFE82V-300C/1000 | datasheet; coil-to-mounting insulation **not stated** | quote needed (marketplace listing of the same family) | R-04 |
| aR fuse 250 A / 1000 V DC (battery port) | Hongfa · HPE501 size 000 | datasheet; curves read conservatively | quote needed (no public price) | R-03 |
| Port film capacitors 45 µF / 1300 V | Jianghai · FCSA3DS456 | datasheet | quote needed (no Chinese price found) | Faratronic second source is rated 1200 V at 70 °C |
| PV inductor 224 µH (one per phase) | custom · POCO NPC 26 toroids, solid round wire | own design, checked by two models ([D-054](../requirements/DECISIONS.md)) | estimate, no quote | wound sample and thermal test |
| Surge protection | Thinking Electronic · TVT25751 varistors + ETI 14×51 fuses | datasheets; thermal links have **no DC rating** | estimate | [D-042](../requirements/DECISIONS.md) |
| Inductor current sensor | Sinomags · STK-HO/A 75 | datasheet; no dv/dt immunity figure | quote needed (estimate) | R-07 |
| Inverter phase-current sensor (3 per PCS-P125) | Sinomags · STK-250HO/4 | datasheet (±625 A linear, 8 kV impulse); no working-voltage, qualification or dv/dt statement | estimate 6.0 USD (no LCSC listing, no published price) | frozen by [D-067](../requirements/DECISIONS.md); the residual-current sensor is still a quotation |
| Reinforced barrier B1 (6 isolators) | Chipanalog · CA-IS3050W, CA-IS3082WNX, CA-IS3820LG / 3821LG, CA-IS3842HW | datasheet ratings pass in the [PV-CTL design check](../../hardware/PV-CTL/outputs/PV-CTL_design_check.txt), with mandatory conformal coating over the barrier | stocked at LCSC (1,000+ breaks) for most | coating to pollution degree 1 |
| Fans (3 per PV-P75) | Delta · AFB1224SHE-F00 | datasheet: rated **−10 °C**, requirement −30 °C | distributor reading (web-search result) | R-05 |
| Controller | TI · F280039C | TI (kept by policy) | TI.com 1ku list | — |
| Power modules (alternative to discretes) | HIITIO, StarPower, Macmic, BASiC, Leapers and others — 24 candidates | short-circuit ratings only on StarPower (IGBT), Macmic and BASiC sheets; HIITIO sheets treated as unverified | **no public price; none on LCSC** | RFQ alternates; [D-055](../requirements/DECISIONS.md), [survey](../../sim/data/asia_modules.md) |

**Parts added on 2026-10-06** — control board rev A2 ([D-075](../requirements/DECISIONS.md)) and the inverter's
AC-side start-up and four-wire build ([D-074](../requirements/DECISIONS.md)); prices from the costed BOMs, LCSC pages read
on 2026-10-04, nothing quoted:

| Function | Maker · part | Where | Qualification evidence | Price evidence (catalogue / 5,000 units) | Open point |
|---|---|---|---|---|---|
| Ethernet bridge (Modbus TCP) | WCH · CH9121T | PCS-CTL (fitted), PV-CTL (footprints) | maker datasheet V2.6 on file | LCSC C45354919: 2.56 USD at 504+, 2.48 USD at 1008+ (REAL) | supply current typical only (× 1.3 assumed); LCSC stock 1,155 at the reading; the LAN set-up tool cannot be disabled |
| Reinforced 4-channel isolator (Ethernet UART, DI1) | Chipanalog · CA-IS3842HW | every control-board variant | datasheet: 8 kV surge, 5.7 kV rms, 8 / 8 mm | LCSC C20598875: 0.60 USD at 1000+ | 8 mm sets the 2,000 m ceiling; the 15 mm CA-IS3842HWW is about 1.12 USD (estimate, not on LCSC) |
| Recorder flash 4 MB | GigaDevice · GD25Q32ESIGR | every variant (replaces the EEPROM) | datasheet, −40…+85 °C | LCSC C2832998: 0.43 USD at 1000+ | — |
| RJ45 with magnetics | HanRun · HR913550AE | with the Ethernet bridge | datasheet (image-only, 4 pp.): 2,250 V DC magnetics, −40…+85 °C | LCSC C192706: 0.82 USD at 1000+ | — |
| Ethernet ESD array | MSKSEMI · SRV05-4 | with the Ethernet bridge | datasheet | LCSC C2836319: 0.02 USD | — |
| Status relay (changeover) | Hongfa · HFD27/005-S | every variant | datasheet: 1,500 V AC coil–contact, −40…+85 °C | LCSC C23911: 0.62 USD at 1000+ | pick-up margin 4.79 V against 4.66 V at 85 °C with an assumed ≤ 3 Ω driver |
| Grid-tap fuse 1.6 A / 500 V AC, 200 A breaking | Conquer · ABB-A 1.60 | PCS-PWR and PCS-PWR-4W, 3 each | catalogue PDF p. 30 | estimate 1.47 / 1.18 USD (the 2 A sibling's LCSC breaks) | a quotation for the 1.6 A code |
| 4-pole AC contactor AC-1 ≥ 248 A, 24 V DC coil | RFQ (CHINT NXC-225 4P / Delixi CJX2s-185 4P class) | PCS-PWR-4W, 2 in series | **no data sheet on file** | RFQ estimate 55 / 46.75 USD each (the 3-pole row + 10 USD, ASSUMED) | one coil contract for the RFQ, the budget and the self-check: pull-in ≤ 20 W for ≤ 100 ms, hold ≤ 4 W ([D-078](../requirements/DECISIONS.md)); the 24 / 5.5 W the auxiliary would allow is margin, not the contract |
| Type-B residual-current sensor | RFQ (fluxgate class) | PCS-PWR (3 conductors), PCS-PWR-4W (3 + N) | **no data sheet on file** | RFQ estimate 10 USD (three-wire) / 12 USD (four-wire) | a part that detects DC and carries 4 × 250 A busbars, to the interface contract of [D-078](../requirements/DECISIONS.md): ±2.0 A, 2.50 V + 1.00 V/A, a fault band outside 0.5–4.5 V, a 50 mA test winding, 5 V ≤ 50 mA, apertures 27 × 19 / 30.5 × 18 mm (ASSUMED until a part is chosen) |
| Four-wire DC precharge resistor 200 Ω | RFQ, same family as the 220 Ω | PCS-PWR-4W | no pulse curve on file | **unpriced** (no estimate row) | the four-wire total is a lower bound by this line |

**Part added on 2026-10-07** — the DESAT string of the 1,700 V presets ([D-081](../requirements/DECISIONS.md), review R4
E01):

| Function | Maker · part | Where | Qualification evidence | Price evidence (catalogue / 5,000 units) | Open point |
|---|---|---|---|---|---|
| DESAT blocking diode, 1,300 V, 2 per gate-drive channel | Vishay · BYG23T-M3/TR (SMA) | PV-PWR 24, PV-PWR-4 32, PCS-PWR 12, PCS-PWR-4W 16 (and PVCELL-25 of the earlier platform) | datasheet on file (doc 89429): V<sub>RRM</sub> 1,300 V, t<sub>rr</sub> ≤ 75 ns, avalanche E<sub>R</sub> 5 mJ non-repetitive, I<sub>R</sub> ≤ 5 / 50 µA at 25 / 125 °C, C<sub>J</sub> 9 pF at 4 V; commercial grade, **no AEC-Q101 variant**; pin audit pass | LCSC C145454: 0.1257 USD at 500+, 0.1079 USD at 5,400+ (REAL), read 2026-10-07 | LCSC showed 10,840 in stock against 60–160 k parts a year: a second source by RFQ (ST STTH112A was rejected: dearer, or failing SRC-2) |

Line-by-line prices and their sources: [`bom/PV-P75_costed_BOM.csv`](../../bom/PV-P75_costed_BOM.csv),
[`bom/PCS-P125_costed_BOM.csv`](../../bom/PCS-P125_costed_BOM.csv),
[`bom/PCS-P125-4W_costed_BOM.csv`](../../bom/PCS-P125-4W_costed_BOM.csv). The survey
behind each choice: [`sim/data/asia_devices.md`](../../sim/data/asia_devices.md),
[`asia_drivers.md`](../../sim/data/asia_drivers.md), [`asia_fuses.md`](../../sim/data/asia_fuses.md),
[`asia_ics.md`](../../sim/data/asia_ics.md), [`asia_modules.md`](../../sim/data/asia_modules.md).

> [!NOTE]
> **Break-even prices for a module** ([D-055](../requirements/DECISIONS.md)): a Chinese module must cost less than
> 38.7 USD per phase leg (PCS-P125), 36 USD per half-bridge (DAB-D60) or 16.5 USD per half-bridge (PV cell) to beat the
> discretes it would replace. No 1700 V SiC module of the size the PV cell needs exists at any maker that could be read,
> so the PV module has no module option. For the DAB-D60 the BASiC BMF008MR12E2G3 is the module to quote.

---

## 💰 Where the money is

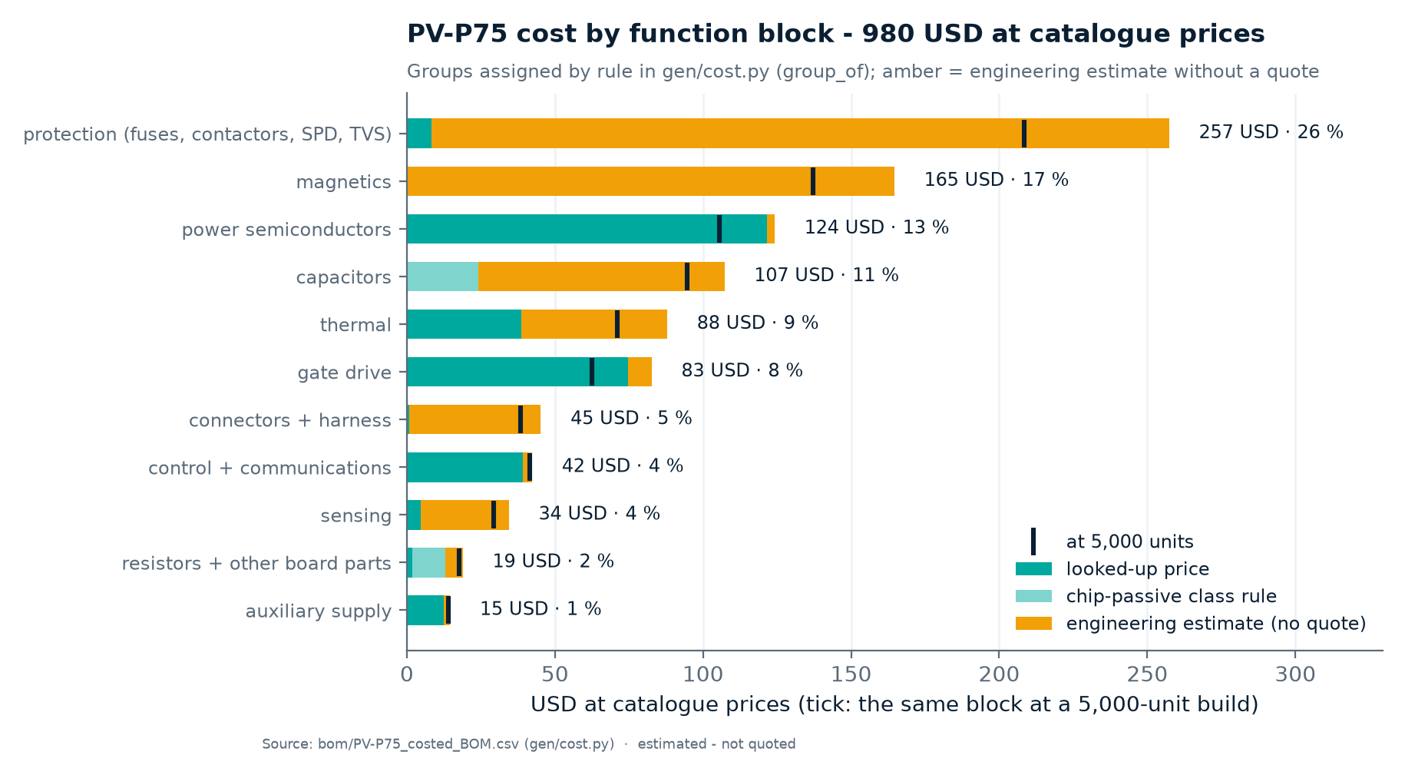
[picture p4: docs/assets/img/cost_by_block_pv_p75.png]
PV-P75 cost by function block, split into looked-up prices, class rules and engineering estimates

<p align="center"><sub>Source: <a href="../../bom/PV-P75_costed_BOM.csv">bom/PV-P75_costed_BOM.csv</a>, groups by <code>group_of()</code> in <a href="../../gen/cost.py">gen/cost.py</a> · estimated, not quoted</sub></p>

- **Protection** (contactors, fuses, surge network, terminals) and **magnetics** are the two largest blocks, and both
  are almost entirely estimate.
- The **power semiconductors** — 24 SiC devices — are about an eighth of the BOM (124 USD, 12.7 %), now at the live LCSC
  price.
- Control and communications are small: the cost-first design moved the money out of boards and into a few chassis parts.
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

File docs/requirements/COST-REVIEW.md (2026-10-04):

# Cost review — what is over-engineered, and is the topology right?

**Date:** 2026-10-04 · **Trigger:** owner: "cost is too high compared with Megarevo … check what we are
over-engineering … is our topology correct and proper … we must produce it within the budget", with the benchmark
"Megarevo 1500 V string PCS, 228 kW version sells for 1,500 USD".

Every cost figure below comes from `gen/cost.py` (`bom/COST.md`), run on 2026-10-04. About 45 % of the total is
estimates; nothing has been quoted or bought.

## 1. The benchmark
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

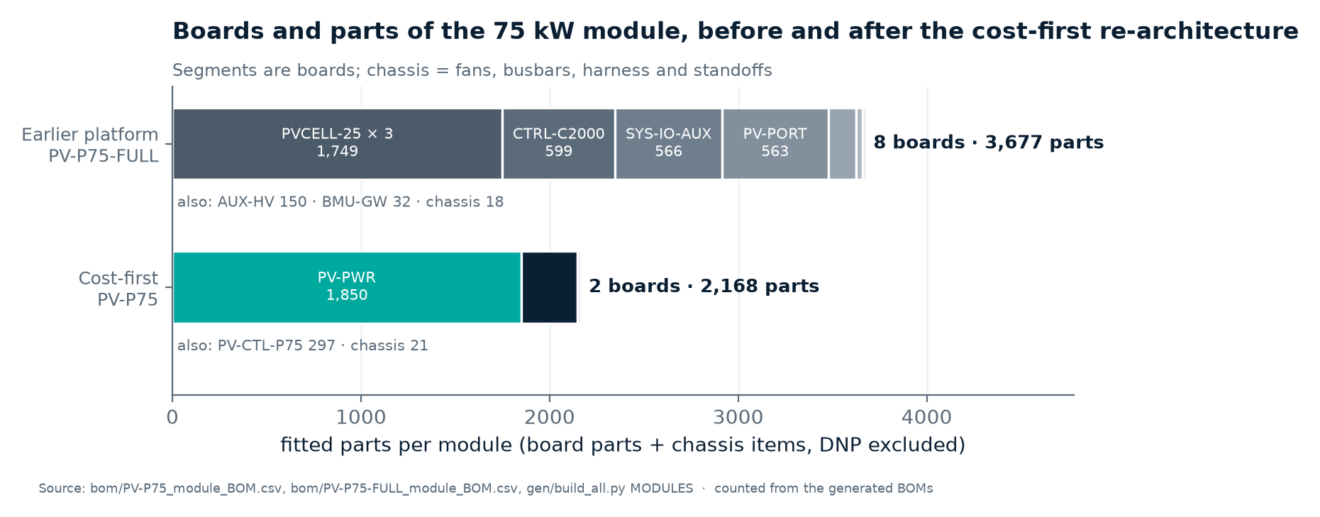
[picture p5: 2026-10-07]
docs/assets/img/parts_and_boards.png

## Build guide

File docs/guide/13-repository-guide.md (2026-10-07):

<!-- breadcrumb --> [Home](../../README.md) › [Documentation](../README.md) › Repository guide

# 🧰 Repository guide

> How to build a board, run a simulation, re-roll the BOMs and the cost, run the audits, and add a part or a board without breaking the rules.






---

> [!IMPORTANT]
> **Python is the source of truth.** Everything in `hardware/` and `bom/` is written by a script; a hand edit is lost
> on the next build and breaks the netlist identity check. Change the generator, then rebuild
> ([CLAUDE.md](../../CLAUDE.md), [REQUIREMENTS.md §6](../requirements/REQUIREMENTS.md#6-working-rules)).

## 🧰 Set up

```bash
python3.12 -m venv .venv
.venv/bin/pip install numpy scipy matplotlib pyelftools
.venv/bin/python docs/fetch.py              # third-party documents: not in git, needed by the BOM check
```

| Tool | Version | Used by |
|---|---|---|
| Python | 3.12 with numpy, scipy, matplotlib, pyelftools | everything |
| KiCad | 10 — `kicad-cli` (macOS: `/Applications/KiCad/KiCad.app/Contents/MacOS/kicad-cli`) | ERC, netlist export, PDF |
| ngspice | 46, on `PATH` | the decks in `sim/spice/` |
| PyOpenMagnetics | 1.7.33, optional | `sim/magnetics.py` only; no macOS-arm64 wheel — built from source, procedure in [magnetics report §1](../../sim/out/magnetics/report.md) |

## ⚡ Build a board

One generator per board. A run writes the KiCad project, runs every check and writes the BOM:

```bash
.venv/bin/python gen/pv_power.py    # one board (here two: PV-PWR and PV-PWR-4)
.venv/bin/python gen/build_all.py   # every maintained board, then the module BOMs
```

| Generator | KiCad projects | Role |
|---|---|---|
| `gen/pv_power.py` | PV-PWR, PV-PWR-4 | cost-first power board, 3 and 4 phases |
| `gen/pv_ctrl.py` | PV-CTL (BOM variant PV-CTL-P75) | cost-first control board; reads the PV-PWR design check as built and refuses a stale copy (hash stamp) |
| `gen/pcs_power.py` | PCS-PWR, PCS-PWR-4W | inverter power board, three-wire and four-wire: two-level legs (four with the neutral leg), split DC link, lean DC port at 250 A, AC contactors (3- or 4-pole), the AC start-up tap and AC precharge, LCL chassis parts; reads `sim/out/pcs_design/pcs_spec.json` and the magnetics design files at build time |
| `gen/pcs_ctrl.py` | PCS-CTL (BOM variants PCS-CTL-3W and PCS-CTL-4W) | inverter control board: a re-valued variant of PV-CTL with the Ethernet bridge fitted and its own pin plan, `gen/data/pcs_ctrl_pin_plan.csv` (four-wire view `gen/data/pcs_ctrl_pin_plan_4w.csv`, written on each build); reads the control study's sampling plan (`sim/out/pcs_control/pcs_control_spec.json`) and the PCS-PWR and PCS-PWR-4W checks as built (refuses a stale copy) |
| `gen/pvcell.py` | PVCELL-25 | earlier platform: one 25 kW cell |
| `gen/port.py` | PV-PORT, PV-PORT-180; with `lean`: PORT-LEAN, PORT-LEAN-HOLD | earlier platform port board; verification boards of the lean port |
| `gen/ctrl_c2000.py` · `gen/sys_io_aux.py` | CTRL-C2000 · SYS-IO-AUX | earlier platform controller card and system I/O |
| `gen/aux_hv.py` · `gen/bmu_gw.py` · `gen/gdrv.py` | AUX-HV · BMU-GW · GDRV-HB | earlier platform auxiliary supply, BMS gateway, gate-drive card |
| `gen/dab60.py` | DAB60 | **frozen**: rev B outputs kept, generator not maintained ([build_all.py](../../gen/build_all.py)); the DAB study in `sim/out/dab_design/` is not this board ([D-068](../requirements/DECISIONS.md)) |

**Frozen inputs of the earlier platform.** `gen/ctrl_c2000.py` (CTRL-C2000) and `gen/pvcell.py` (PVCELL-25) read frozen
snapshots of the specs they were designed to — [gen/data/control_spec_platform1.json](../../gen/data/control_spec_platform1.json)
and [gen/data/cell_spec_platform1.json](../../gen/data/cell_spec_platform1.json), the specs of commit `033d8d8` — because
the live `sim/out/pv_control/control_spec.json` and `sim/out/pv_design/cell_spec.json` now describe the cost-first boards
([D-065](../requirements/DECISIONS.md)). Like the frozen DAB60 outputs, they are not re-derived. The loaders the review
read fail closed (PCM-23): a missing or stale input stops the run instead of falling back to a built-in value.

Each board's outputs land in `hardware/<board>/outputs/`: the schematic PDF, the netlist (`.net` and XML), the ERC
result, `<board>_report.json` (the checks below), `<board>_design_check.txt` (the board's own calculations) and the
symbol pin list used by the pin audit. Live status of every board: [Overview › Status](01-overview.md#-status).

### What every build checks

| Check | Passes when | Can it be waived? |
|---|---|---|
| ERC (`kicad-cli`, all severities) | no unwaived violation | a *warning* type, with a written reason; errors never |
| Netlist identity | the exported KiCad netlist equals the Python design table, net by net | no |
| Isolation domains | only declared isolators and deliberate crossings touch two domains | no |
| Part stress (jellybean parts) | capacitors ≤ 80 % of rated voltage; resistors ≤ 60 % of rated power and within their working voltage | no |
| PDF | the schematic renders | no |
| BOM completeness | every line has maker + MPN + datasheet on file, or is GENERIC / RFQ / CUSTOM / NOPART | no |
| Board design check | the board's own `design_check()`: trip thresholds, timing, ratings, loads across connectors | it fails the build |

Details of the writer and the `Builder` API: [gen/README.md](../../gen/README.md). What the checks do **not** prove —
layout, parasitics, real component behaviour — is in [Verification](08-verification.md).

## 🔬 Run a simulation

```bash
.venv/bin/python sim/pv_design.py        # writes sim/out/pv_design/ (report.md, cell_spec.json, plots)
```

| Script | Output folder | What it decides |
|---|---|---|
| `sim/pv_tradeoff.py` | `pv_tradeoff/` | PV cell topology (Gate-0 and its re-run with Asian devices) |
| `sim/pv_design.py` · `sim/pv_module.py` | `pv_design/` | cell power stage; module losses, thermal, derating, noise |
| `sim/pv_control.py` · `sim/pv_mppt.py` | `pv_control/` · `pv_mppt/` | control loops on the drawn boards, protection timing, the delivered-power envelope (`envelope.csv`); MPPT |
| `sim/port_design.py` | `port_design/` | DC ports: precharge, coordination, sensing, insulation monitor |
| `sim/aux_hv_design.py` | `aux_hv_design/` | auxiliary flyback (30 W earlier, 75 W cost-first) |
| `sim/gdrv_miller.py` | `gdrv_miller/` | false turn-on check of the gate-drive channel |
| `sim/magnetics.py` | `magnetics/` | three-way magnetics verification; constructions and specifications |
| `sim/insulation.py` | `insulation/` | insulation coordination and the barrier audit |
| `sim/dab_design.py` · `sim/dab_control.py` | `dab_design/` · `dab_control/` | DAB-D60 device study (not the drawn DAB60 rev B0): power stage, admitted map, firmware rules FW-DAB-1…11; control |
| `sim/pcs_design.py` | `pcs_design/` | PCS-P125 power stage, DC link, operating envelope; the four-wire build, the AC-side start-up and the declarations (section i); firmware hand-over (30 rows) |
| `sim/pcs_control.py` | `pcs_control/` | PCS-P125 control: current loop, PLL, DC-link loop, grid forming, THDi estimate, sampling plan and protection state machine ([D-066](../requirements/DECISIONS.md)); off-grid restoration and accuracy, THDu, imbalance, the ride-through limiter and the neutral-leg loop ([D-077](../requirements/DECISIONS.md)) |
| `sim/pcs_tradeoff.py` | `pcs_design/tradeoff.md` | PCS-P125 stage and filter re-optimisation with the designed inductors (D-059, corrected by D-060) |
| `sim/pcs_crosscheck.py` | `pcs_design/crosscheck_wolfspeed.md` | independent check of the inverter topology against Wolfspeed's reference designs (D-057) |
| `sim/compare_megarevo.py` | `compare_megarevo/` | the row-by-row comparison of PV-P75 with the PMD-75-G3 |
| `sim/compare_megarevo_pcs.py` | `compare_megarevo_pcs/` | the row-by-row comparison of PCS-P125 and PCS-P125-4W with the PMA0125 (columns `megarevo_pma0125_published`, `pcs_p125_calculated`, `pcs_p125_4w_calculated`, `verdict`, `evidence`; one verdict per row) |
| `sim/pv_devices.py` · `sim/dab_devices.py` · `sim/pcs_devices.py` | `audit/` | device data with datasheet page references; device audits |

Every report states what is calculated, what is simulated and what is assumed. The spec JSON files are the hand-off:
generators read them, so a design value has one source. For the inverter the order is `sim/pcs_design.py` →
`sim/pcs_control.py` → `gen/pcs_power.py` → `gen/pcs_ctrl.py`: the control board reads the control study's sampling
plan, and the study takes the sensing chain (current-chain delay, divider poles) from the two boards' design checks.

### Regeneration order

After a change to a study, the whole chain in this order (as run on 2026-10-06):

```bash
.venv/bin/python sim/aux_hv_design.py      # only when the auxiliary allocations change (about 4 min)
.venv/bin/python sim/pv_design.py          # about 6 min
.venv/bin/python sim/pv_module.py          # module losses, thermal, standby - read by sim/compare_megarevo.py
.venv/bin/python sim/pv_control.py
.venv/bin/python sim/pv_mppt.py
.venv/bin/python sim/pcs_design.py
.venv/bin/python sim/pcs_control.py
.venv/bin/python sim/magnetics.py          # the PCS filter and auxiliary transformer designs the generators read
.venv/bin/python gen/build_all.py          # every maintained board and its variants (about 5 min), then the module BOMs
.venv/bin/python gen/port.py lean          # PORT-LEAN and PORT-LEAN-HOLD, which build_all does not build
.venv/bin/python gen/build_all.py --bom    # module BOMs from the board BOMs
.venv/bin/python gen/cost.py               # costed BOMs and bom/COST.md
.venv/bin/python sim/compare_megarevo.py       # PV-P75 against the PMD-75-G3
.venv/bin/python sim/compare_megarevo_pcs.py   # PCS-P125 / PCS-P125-4W against the PMA0125
.venv/bin/python gen/pin_audit.py
.venv/bin/python gen/temp_audit.py
.venv/bin/python sim/insulation.py
.venv/bin/python docs/assets/figures_overview.py
.venv/bin/python docs/assets/figures_design.py
```

Exit codes that are reports, not failures: both compare scripts exit 1 while a row is BELOW or PENDING (today: 3 PV rows
and 4 PCS rows below); `gen/temp_audit.py` exits 1 while a part has no audit row; `sim/insulation.py` exits 1 on its known
problems (102 today, risk B10); `sim/magnetics.py` exits 0 but prints the known MG-15 FAIL (risk D9). Read their output
diffs, not their exit codes. Long runs stall if the computer sleeps: keep it awake for the multi-minute scripts.

## 💰 Re-roll the BOMs and the cost

```bash
.venv/bin/python gen/build_all.py --bom   # module BOMs from the board BOMs (no rebuild)
.venv/bin/python gen/cost.py              # bom/*_costed_BOM.csv and bom/COST.md
.venv/bin/python docs/assets/figures_overview.py   # charts and generated tables of these pages
```

`gen/cost.py` prices each line from [`gen/data/prices.csv`](../../gen/data/prices.csv) (looked-up prices with URL and
date), [`cost_estimates.csv`](../../gen/data/cost_estimates.csv) (estimates with their basis) and
[`volume_factors.csv`](../../gen/data/volume_factors.csv) (5,000-unit factors). The supplier surveys behind the price
rows are in `sim/data/`: `asia_*.md` and the LCSC sourcing pass [lcsc_semis.md](../../sim/data/lcsc_semis.md) /
[lcsc_semis.csv](../../sim/data/lcsc_semis.csv) (every transistor and diode position, stock and price ladders read on
2026-10-05, [D-069](../requirements/DECISIONS.md)) — re-read the LCSC pages before ordering. A line with neither price nor estimate is
listed as UNPRICED and never counted as zero. The script exits with code 1 if its self-check fails.
[Sourcing and cost](07-sourcing-and-cost.md) explains the method.

## 🔬 Audits

| Command | What it proves |
|---|---|
| `.venv/bin/python gen/pin_audit.py` | every drawn pin table equals a ledger transcribed from the datasheet by someone who had not seen the drawing (`list` writes the parts list) |
| `.venv/bin/python gen/temp_audit.py` | every orderable part against the −30…+60 °C ambient requirement (hot limit 85 °C inside the enclosure) |
| `.venv/bin/python gen/check_interfaces.py` | the cables of the earlier platform's modules: pin map, driver direction, power. The cost-first board-to-board contract (`PC`) is checked inside the PV-PWR and PV-CTL design checks, and the inverter's `PCS_PC` and `PCS_X` inside the PCS-PWR and PCS-CTL design checks |
| `.venv/bin/python sim/insulation.py` | every barrier part of the earlier platform's boards against the insulation requirements — it has no domain map for PV-CTL, PCS-PWR, PCS-PWR-4W, PCS-CTL, PORT-LEAN and PORT-LEAN-HOLD and currently stops with 98 problems ([08 · Verification](08-verification.md#-audits)); those boards check their own barrier parts in their design checks |
| `.venv/bin/python sim/magnetics.py` | every magnetic part three ways; exits 1 if a check fails |

Review findings of the independent design reviews are kept in `gen/data/review_*.csv` and
`gen/data/integration_findings.csv` ([D-023](../requirements/DECISIONS.md)).
[review_pcm.csv](../../gen/data/review_pcm.csv) (27 findings of the review of commit `033d8d8`) added status, class and
closure columns; its dispositions are decisions D-065 to D-069 and D-072.
[review_r2.csv](../../gen/data/review_r2.csv) (14 findings of the re-check of commit `a427981`, severities high /
medium) has the same columns; its dispositions are [D-078](../requirements/DECISIONS.md) and
[D-079](../requirements/DECISIONS.md). [review_r3.csv](../../gen/data/review_r3.csv) (5 findings of the re-check of
commit `615e4b5`, severities high / low) has them too; its disposition is [D-080](../requirements/DECISIONS.md). The
economical re-check, [review_r4.csv](../../gen/data/review_r4.csv) (commit `845131d`: 12 decision areas E01–E12,
severities high / medium / low), keeps the same status, classification and closure columns; each area's preferred option,
alternative and no-change boundary are in its finding text, its cost basis in the evidence column and the boundary that
may not be waived in the recommendation column; its disposition is [D-081](../requirements/DECISIONS.md). The latest,
[review_r5.csv](../../gen/data/review_r5.csv) (the closure re-check of commit `5c56aaa`: six rows R5-01…R5-06, all severity
low, no new defect), has the same columns and its recommendation column names what a waiver may not replace; its
disposition is [D-082](../requirements/DECISIONS.md).

### Records added on 2026-10-06

| File or folder | What it is | Written by |
|---|---|---|
| [gen/data/megarevo_2026_parity.csv](../../gen/data/megarevo_2026_parity.csv) | the module-parity register against Megarevo (32 rows: area, item, their published statement, ours, verdict, action) | by hand per decision ([D-073](../requirements/DECISIONS.md) to [D-077](../requirements/DECISIONS.md)); rendered on [11 · Comparison](11-megarevo-comparison.md#-module-parity-register) by `figures_overview.py` |
| [gen/data/pcs_ctrl_pin_plan_4w.csv](../../gen/data/pcs_ctrl_pin_plan_4w.csv) | the four-wire view of the inverter controller's pin plan | `gen/pcs_ctrl.py` |
| [hardware/PCS-PWR-4W/](../../hardware/PCS-PWR-4W/outputs/PCS-PWR-4W_design_check.txt) | the four-wire power board: KiCad project, PDF, netlist, ERC, report, design check | `gen/pcs_power.py` |
| [bom/PCS-PWR-4W_BOM.csv](../../bom/PCS-PWR-4W_BOM.csv), [bom/PCS-CTL-4W_BOM.csv](../../bom/PCS-CTL-4W_BOM.csv), [bom/PCS-P125-4W_module_BOM.csv](../../bom/PCS-P125-4W_module_BOM.csv), [bom/PCS-P125-4W_costed_BOM.csv](../../bom/PCS-P125-4W_costed_BOM.csv) | the four-wire board, assembly, module and costed BOMs | the generators, `gen/build_all.py --bom`, `gen/cost.py` |
| [sim/compare_megarevo_pcs.py](../../sim/compare_megarevo_pcs.py) → [sim/out/compare_megarevo_pcs/](../../sim/out/compare_megarevo_pcs/report.md) | the PCS comparison script and its `comparison.csv` / `report.md` | the script |
| [docs/reference-designs/megarevo/pma/spec-pma0125.md](../reference-designs/megarevo/pma/spec-pma0125.md), [MANUAL-NOTES.md](../reference-designs/megarevo/pma/MANUAL-NOTES.md) | the PMA0125 datasheet table transcribed verbatim; the PMA user manual's module-level statements with page numbers | by hand from the fetched PDFs |
| `docs/reference-designs/megarevo/catalogue-2026/` | Megarevo's 2026 catalogue V1.2 (module pages used) — the PDF is a manifest row in [docs/SOURCES.csv](../SOURCES.csv), fetched, not kept in git | `docs/fetch.py` |

Added on 2026-10-07: [requirements/INSTALLATION.md](../requirements/INSTALLATION.md) collects the installation conditions the modules depend on, one row per requirement with the generated line it comes from; it is written by hand from the design checks, so its quoted lines are re-verified after a rebuild (done after the rebuild of D-078 / D-079, again after that of D-080 and again after that of D-081: 77 rows). [gen/data/review_r2.csv](../../gen/data/review_r2.csv) holds the re-check R2; new keys of the hand-offs: `protection_chain` in `pcs_spec.json` (the trip chain at its gates-off current, the L1 trajectory, the backup-band requirement), `tolerance_regression`, `vf_bounded`, `dc_rejection_bounded`, `ride_through_rule`, `four_wire_coupled`, `ac_start_state_machine` and `review_r2` in `pcs_control_spec.json`. Added the same day by the re-check R3 ([D-080](../requirements/DECISIONS.md)): [gen/data/review_r3.csv](../../gen/data/review_r3.csv); `commutation_and_gate_drive.desat.rds_acceptance.grade_tier_tables`, `declarations.tiers_by_grade` and `grid_tie_start` in `pcs_spec.json`; `sync_close_state_machine`, `four_wire_short_protection`, `dc_bus_coupled_pv`, `vf_envelope_basis` and `review_r3` in `pcs_control_spec.json`.

### Records added on 2026-10-07 by the re-check R4

| File or key | What it is | Written by |
|---|---|---|
| [gen/data/review_r4.csv](../../gen/data/review_r4.csv) | the register of the economical re-check R4: twelve decision areas with status, classification and closure | by hand per review round ([D-081](../requirements/DECISIONS.md)) |
| [docs/requirements/RFQ-MAGNETICS.md](../requirements/RFQ-MAGNETICS.md) | the request-for-quotation index for the ten custom magnetic parts: quantities per module and build, the rows a quotation must hold, type and production tests, the estimate held, 18 open rows, the 48 kHz variant as an appendix | by hand from the winding sheets and the costed BOMs; re-read after a magnetics or BOM rebuild |
| `docs/datasheets/power-semiconductors/BYG23T.pdf` | Vishay BYG23T-M3 datasheet (doc 89429), the new DESAT diode — a manifest row in [docs/SOURCES.csv](../SOURCES.csv) and [docs/datasheets/SOURCES.csv](../datasheets/SOURCES.csv), fetched, not kept in git; its price rows (LCSC C145454) in `gen/data/prices.csv`, its pin-ledger rows in `gen/data/pin_ledger_E.csv` | `docs/fetch.py` |
| `BYG23T`, `DESAT_1700` and `STRING_ENV` in [gen/gdrv.py](../../gen/gdrv.py) | the diode's catalog entry; the 1,700 V-class string preset (two diodes, the V<sub>F</sub> band); the reverse-voltage envelope every 1,700 V board check is asserted against (1,150 V static, 1,445 V peak) | the generator |
| `CM_RING` in [gen/pv_power.py](../../gen/pv_power.py) | the port CM ring's BOM line, now the flat-permeability grade as an RFQ item keyed by the size code N-C-644025 | the generator |
| `commutation_and_gate_drive.desat.string_envelope`, `thermal_and_losses.cold_start` in `pcs_spec.json`; `dc_bus_cable`, `dc_bus_operating_window`, `vf_envelope_basis.statement` / `release_sequence` / `not_claimed` and `review_r4` in `pcs_control_spec.json` | the DESAT reverse-voltage states, the inverter's passive cold-start table, the cable model, the enforced DC-bus window with the harness contract, the envelope's capability statement and release sequence, the study's R4 dispositions | `sim/pcs_design.py`, `sim/pcs_control.py` |

### Records added on 2026-10-07 by the re-check R5

| File | What it is | Written by |
|---|---|---|
| [gen/data/review_r5.csv](../../gen/data/review_r5.csv) | the register of the closure re-check R5: six rows with status, classification and closure — no new defect | by hand per review round ([D-082](../requirements/DECISIONS.md)) |
| [docs/requirements/QUALIFICATION-PLAN.md](../requirements/QUALIFICATION-PLAN.md) | the one consolidated plan of every open gate of the five review rounds, Q-01…Q-44: what is tested, the acceptance number our records give, the test asset, the product or claim it blocks, the stage (representative switching cell → controlled prototype → DVT → production controls); what a paper waiver cannot replace; a gate / blocks / stage / source table | by hand from the registers, the decisions' **Open** lists, [INSTALLATION.md](../requirements/INSTALLATION.md), [RFQ-MAGNETICS.md](../requirements/RFQ-MAGNETICS.md) and the generated checks; its quoted generated lines are re-found after a rebuild |

## 📐 Conventions

### Adding a part

1. **Datasheet first.** Save the maker's PDF as `docs/datasheets/<category>/<MPN>.pdf` (maker's own site, no login) and
   add its row to the manifests ([docs/LIBRARY.md](../LIBRARY.md), "How to add a document").
2. **Pin table from the PDF, never from memory** (`pdftotext -layout`), with the document number and page in a comment.
3. **Catalog entry** in the board script; a part shared by several boards goes into `gen/catalog.py`.
4. **Real orderable MPN**, or `sourcing="CUSTOM"` / `"RFQ"` / `"GENERIC"` with the full specification in the description.
5. **Price**: a row in `gen/data/prices.csv` (source, quantity break, date) or an estimate with its basis in
   `gen/data/cost_estimates.csv`.
6. **Pin ledger** row for the pin audit, transcribed independently.

### Adding a board

1. Copy the pattern of [`gen/bmu_gw.py`](../../gen/bmu_gw.py); the `Builder` API is in [gen/README.md](../../gen/README.md).
2. Every pin of every symbol gets a net or `None`; a net with one pin is an ERC error.
3. Declare the isolation domains, isolators and crossings; give `vrange()` for the part-stress check.
4. Inter-board connectors come from `gen/interfaces.py` — both ends import the same table.
5. Register the board in `BOARDS` and its module in `MODULES` of [`gen/build_all.py`](../../gen/build_all.py).

### Scope rules

A task that does not trace to [REQUIREMENTS.md](../requirements/REQUIREMENTS.md) is a diversion — ask first. No PCB
layout, footprints, Gerbers or mechanics. Nothing is presented as measured.

## 📚 The reference library

Third-party documents (datasheets, reference designs, competitor files) are **not redistributed** in this
repository; [`docs/SOURCES.csv`](../SOURCES.csv) lists every file with its URL and SHA-256, and our own notes
(READMEs, `spec.md`) stay in git.

| Command | What it does |
|---|---|
| `.venv/bin/python docs/fetch.py` | downloads every missing file marked OK with a plain request and keeps it only if its SHA-256 matches the manifest |
| `.venv/bin/python docs/fetch.py --check` | verifies what is on disk; also flags a file without a manifest row, a path listed twice, and a by-hand file that is present |
| `.venv/bin/python docs/fetch.py --summary` | regenerates the count tables of [docs/LIBRARY.md](../LIBRARY.md) |

Files that sites refuse to serve to a script are marked MANUAL and must be saved by hand — the list and the current
counts are in [docs/LIBRARY.md](../LIBRARY.md), which `docs/fetch.py --summary` writes (do not edit it by hand). Never
move or rename a library file without first searching `gen/`, `sim/`, `bom/` and `hardware/` for its path.

**Firmware packages of reference designs** (the Wolfspeed CRD200DA23N-GMA, CRD60DD12N-GMB and CRD-60DD12N-K,
[D-071](../requirements/DECISIONS.md)) have their manifest rows like any other file and are unpacked in a `firmware/`
folder next to the design, which git ignores. Our static reading of each package lives beside its README as
`FIRMWARE-NOTES.md` (every number labelled read / calculated / inferred, with file and line); what they change for our
firmware is [REFERENCE-LESSONS.md §6](../requirements/REFERENCE-LESSONS.md). Nothing in them was built or run.

## 🧰 The documentation itself

| Item | Where |
|---|---|
| Style guide (voice, page skeleton, palette, Mermaid init block) | [docs/assets/STYLE.md](../assets/STYLE.md) |
| Charts of the landing, cost, comparison and status pages | [`docs/assets/figures_overview.py`](../assets/figures_overview.py) → `docs/assets/img/` |
| Charts of the design pages | [`docs/assets/figures_design.py`](../assets/figures_design.py) |
| Generated tables | between `<!-- BEGIN:name -->` and `<!-- END:name -->` in the pages; rewritten by the figure script — do not edit by hand |

Run the figure scripts after `gen/cost.py`, a board build or either compare script; they read the data at run time,
fail loudly if a data file or a marker is missing, and finish with a self-check. `figures_overview.py` writes the blocks
`cost-summary` (README, 07), `board-status` (01), `megarevo-score`, `megarevo-table`, `megarevo-pcs-score`,
`megarevo-pcs-table` and `megarevo-parity` (11), and the scorecards `megarevo_scorecard.png` and
`megarevo_pcs_scorecard.png`.

---

<!-- footer --> ← [Risks and open items](12-risks-and-open-items.md) · [Documentation index](../README.md) · [Glossary](glossary.md) →

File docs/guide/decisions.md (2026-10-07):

<!-- breadcrumb --> [Home](../../README.md) › [Documentation](../README.md) › Decisions

# 📐 Decisions

> A readable digest of the decision register, D-001 to D-082, grouped by theme — what was decided, why, and whether it still holds.





---

> [!NOTE]
> This page summarises; **[DECISIONS.md](../requirements/DECISIONS.md) is the record** and wins wherever the two differ.
> The register never deletes a row — a later decision supersedes it. The badge shows where a decision stands today,
> taking the later rows into account; the register's own status column is left as it was written.

**Badges.**
 in force ·
 awaiting a decision ·
 work running ·
 a finding or status, not a design choice ·
 holds for the full-featured platform only ·
 replaced by a later decision ·
 settled by a later decision

---

## 📐 Scope, process and tools

| ID | Decision · why | Today |
|---|---|---|
| D-001 | **Scope:** the DC/DC modules PV-P75/100/110 and DAB-D60 with their shared boards; schematic + BOM + simulation only.<br/><sub>Owner instruction. The DC-to-AC PCS joined the scope with D-046.</sub> |  |
| D-002 | **Toolchain:** Python 3.12 (numpy, scipy, matplotlib), KiCad 10 `kicad-cli`, ngspice 46; the schematic writer comes from an earlier in-house project.<br/><sub>Already proven against kicad-cli 10; no new dependency.</sub> |  |
| D-003 | **No footprints:** every part carries a package field only.<br/><sub>PCB layout is out of scope.</sub> |  |
| D-008 | **Ambient −30…+60 °C, derating above 45 °C,** re-tagged from assumption to sourced requirement.<br/><sub>The PMD-75-G3 page and datasheet state it for the competitor product itself.</sub> |  |
| D-009 | **Six published PMD-75-G3 rows** the roadmap did not carry (MPPT accuracy, start-up voltage, protections, lightning, insulation detection, environment) recorded as candidate requirements.<br/><sub>Adopted as design targets by D-051.</sub> |  |
| D-046 | **DC-to-AC PCS in scope,** baseline PCS-P125 (125 kW, 590–950 V DC, 400/230 V AC) against Megarevo PMA0125; costs also judged at 5,000 units.<br/><sub>Owner: "we need both dc dc and dc to ac .. check for volume like 5000 qty". The rating is an assumption the owner can change.</sub> |  |
| D-051 | **The owner delegated the open decisions;** taken and recorded: working budgets (800 USD PV-P75, 950 USD DAB-D60), the port filter, hardware protections stay; D-009, D-017, D-020 and D-022 closed.<br/><sub>Can be overturned by the owner. Its inductor line was amended by D-054.</sub> |  |
| D-073 | **Megarevo parity, modules only, both directions:** match the competitor module for module — the PMA inverter modules and the PMD-75-G3 DC/DC module — and the other way round; cabinets, containers, 1500 V PCS, integrated hybrids, HMI panels and mechanics discarded; both products stay bidirectional; the register `gen/data/megarevo_2026_parity.csv`, the PMA0125 table and the user-manual notes filed.<br/><sub>Owner instruction of 2026-10-05. The gaps it found (grid type 3W+N+PE, start-up from the grid, the operating modes, Ethernet, the fault recorder, altitude) went to D-074 / D-075; a smaller AC module and AC-02's 600 V stay the owner's items. The datasheet, not the catalogue, is the source where they differ.</sub> |  |

## 🧭 Architecture and protection philosophy

| ID | Decision · why | Today |
|---|---|---|
| D-044 | **Cost-first architecture** for the PV module: control on the negative DC rail behind one reinforced barrier, two boards instead of eight, self-powered, a single-core C2000, lean ports, no clamp banks, one trip latch.<br/><sub>The full-featured BOM was several times the benchmark level and trimming could not close the gap ([COST-REVIEW.md](../requirements/COST-REVIEW.md)). Supersedes D-012, D-019, D-024, D-025, D-033, D-034 and D-038 for the cost-first product.</sub> |  |
| D-045 | **Cost-first specification accepted** ([ARCHITECTURE-COSTFIRST.md](../requirements/ARCHITECTURE-COSTFIRST.md)): power board + F280039C control board, one barrier, a 75 W flyback fed from both ports, one contactor per port.<br/><sub>Budget not met at the architect's estimate; the fan's temperature rating is open.</sub> |  |
| D-049 | **Offload protection to the controller and firmware** instead of discrete comparators.<br/><sub>Superseded by D-050: the saving was about 17 USD per module.</sub> |  |
| D-050 | **Discrete hardware protections stay;** firmware duplicates each as a second layer and takes sequencing and rare edge cases.<br/><sub>Removing them saves about 2 %; a firmware dead time of zero would destroy the switches before DESAT could act.</sub> |  |
| D-075 | **Control board rev A2: Ethernet, recorder flash, discrete I/O, port roles, altitude, SELV allocation** (one schematic for PV-CTL, PV-CTL-P75 and PCS-CTL): a CH9121T UART-to-Ethernet bridge (Modbus TCP) through a CA-IS3842HW, fitted on PCS-CTL and footprints only on PV-CTL; a GD25Q32E 4 MB flash in place of the EEPROM (71 fault records of 32 channels × 200 ms beside two firmware images); a chainable stop, a ready permissive, a battery-fault input and a changeover relay; port roles CAN = module bus, RS-485 or CAN = BMS, Ethernet or RS-485 = EMS; altitude kept at 2,000 m with a 15 mm isolator option for 3,000 m full / 5,000 m derated; SELV logic 2.2 W.<br/><sub>D-073 parity. Cheapest implementation inside the B1 rule; the option costs +1.53 to +3.02 USD per board, above the ~1 USD rule set here. PV-CTL 15.89 → 17.72 USD; PV-P75 standby 12.6 / 22.3 W (12.7 / 22.4 W after D-076). Open: the CH9121T's supply current and stock, its LAN set-up tool, the relay pick-up margin, +3.3 V at 94 %, no spare GPIO on the inverter's plan; not matched: two Ethernet ports, a web server, a hardware sync pair, the 12 V HMI supply.</sub> |  |
| D-004 | **Controller TMS320F28388D** on a common CTRL-C2000 card.<br/><sub>The cost-first design uses a single-core F280039C (D-045).</sub> |  |
| D-010 | **Inter-board connector contracts** in `gen/interfaces.py`; gate commands and faults cross boards as RS-422 pairs.<br/><sub>The cost-first boards use the `PC` contract (D-045).</sub> |  |
| D-012 | **Dual-channel hardware safety chain,** no single point of failure.<br/><sub>Superseded for the cost-first product by D-044 (one latch).</sub> |  |
| D-013 | **24 V system window** 21.6–26.0 V with an over-voltage cut-off.<br/><sub>The cost-first module has no cabinet 24 V.</sub> |  |
| D-026 | **System I/O feed rules:** the HV bootstrap feeds the 24 V bus only when no cabinet feed is healthy; fans stay off until firmware enables them.<br/><sub>Review findings on the earlier platform.</sub> |  |
| D-034 | **Bootstrap-only operation:** fans, gate-drive and coil supplies forced off in hardware; black start in one ramp.<br/><sub>Superseded for the cost-first product by D-044.</sub> |  |

## ⚡ PV power stage and gate drive

| ID | Decision · why | Today |
|---|---|---|
| D-007 | **PV cell topology:** two-level four-switch buck-boost with 1700 V SiC, 32 kHz, one 224 µH inductor per cell.<br/><sub>Gate-0 study: lowest cost at every efficiency level it reaches. Confirmed with Asian devices by D-041. Open: no FIT-against-voltage curve for the device.</sub> |  |
| D-037 | **Device sourcing rule:** a primary and an alternate Asian maker per switch position; the design is done for the worse of the two.<br/><sub>No Chinese maker publishes a reliability report or a short-circuit rating — recorded as a risk.</sub> |  |
| D-041 | **Gate-0 re-run with Asian devices:** the cell stays two-level; primary 2 × Sichain SG2M040170HJ per position.<br/><sub>Cheaper than the best three-level option; the device set is conditional on the gate-drive items (closed in D-043 with conditions).</sub> |  |
| D-043 | **Gate drive rev 5:** NSI6651 with a clamp per gate and a short-circuit turn-off booster; InventChip is *not* an alternate; Microchip MSC035SMA170B4 is the qualified fallback.<br/><sub>Conditions: the driver's 6,250 V impulse rating needs the arrester credit; Sichain's reliability data is a release condition.</sub> |  |
| D-005 | **Gate driver TI UCC21710.**<br/><sub>Changed to NOVOSENSE NSI6651 by D-035.</sub> |  |
| D-035 | **Gate driver NOVOSENSE NSI6651ASC:** 10 A, DESAT, reinforced with VDE 0884-17 / UL 1577 / CQC certificates, AEC-Q100 grade 1.<br/><sub>About 3 USD against 4.4 USD; its open bias-supply half was settled by D-036.</sub> |  |
| D-016 | **Gate-drive bias TI UCC14241-Q1** (reinforced; certification "planned" in its datasheet).<br/><sub>The cost-first channel uses a per-phase bias transformer (D-045, D-048).</sub> |  |
| D-036 | **Bias supply stays UCC14241-Q1;** cheaper Mornsun modules only with an insulation report for 1100 V DC.<br/><sub>Closes the open half of D-035.</sub> |  |
| D-028 | **Paralleled-gate turn-off:** a PNP follower per device to its own Kelvin pin; hardware dead time 191–511 ns.<br/><sub>**Open risk:** the margin at the extreme corner rests on an estimated loop inductance — the first item for the double-pulse test.</sub> |  |
| D-030 | **Inductor current by a closed-loop transducer** (LEM LA 150-P) instead of a shunt and isolated amplifier.<br/><sub>The cost-first power board uses Sinomags STK-HO/A 75 sensors.</sub> |  |
| D-027 | **Reverse-clamp rectifiers** across each DC bank, so a terminal short does not drive kiloamperes through the SiC body diodes.<br/><sub>Terminal-short survival was given up in the cost-first design (D-044).</sub> |  |
| D-065 | **PV control re-based on the drawn boards; the phase-current limit separated from the port limits.** The inductor is held at 45 A in buck / boost and 47.70 A in the band, the ports separately: PV-P75 is rated from 562 V (73.3 kW at 550 / 550 V), PV-P100 from 690 / 697 V, and PV-P110 delivers 108.8 kW A→B (110 kW is an input-side rating). On the drawn sensing chain the current loop keeps PM ≥ 57.6° and GM ≥ 11.6 dB; the constant-power corner is 44.3° / 45.0°.<br/><sub>Review PCM-01 / 02 / 13 / 23: the 45 A clamp was a port rating applied to the inductor (70.0 kW at 550 / 550 V), and the loop evidence predated the drawn boards. The requirement set is inconsistent by 1 % at 550 V (75 kW needs 136.4 A against 135 A) — published as such. Calculated.</sub> |  |
| D-072 | **PV boards: review corrections.** Leg commutation re-run on the drawn Jianghai capacitors (1,374 V worst against 1,445 V); the comparator's common-mode term in every band (window 67.9–80.5 A, the 1.10 floor missed by 0.58 A, kept with an open line); the firmware over-voltage stop derived from the hardware band (1,034 V); one fan-supply contract (S_24V ≥ 24.5 V, fans at 23.6 V, airflow × 0.983); the cold-start restriction with its passive power table; the port A declaration; live-24 V budgets with typical values; the MDD TVS.<br/><sub>Review PCM-14 / 16 / 17 / 18 / 19 / 26. Open: the TLV9024's rejection at 3.3 V and its maximum delay, the Jianghai reversal allowance and surge current, the port A making current (R-04), the four-phase pull-in reserve, the inlet NTC's failure behaviour.</sub> |  |

## 🛡️ DC ports, protection and insulation

| ID | Decision · why | Today |
|---|---|---|
| D-006 | **Precharge by resistor and contactor.**<br/><sub>From the roadmap; kept on the cost-first battery port.</sub> |  |
| D-019 | **135 A port protection:** gPV fuses, TDK contactor, a hold-closed interlock so the fuse always clears first.<br/><sub>Superseded for the cost-first product by D-044.</sub> |  |
| D-020 | **The 180 A port is not fully coordinated.**<br/><sub>Superseded by D-033; closed by D-051.</sub> |  |
| D-024 | **Contactor coil drive** with two independent switches in every coil-current path.<br/><sub>Superseded for the cost-first product by D-044.</sub> |  |
| D-025 | **Active discharge** inhibited while the contactor is closed, time-limited, with a thermal cut-off.<br/><sub>Superseded for the cost-first product by D-044: passive bleeders.</sub> |  |
| D-033 | **Port source types:** battery-class fuse, battery-rated arrester and two contactors in parallel for stiff sources.<br/><sub>Supersedes D-020; superseded for the cost-first product by D-044.</sub> |  |
| D-042 | **Surge protection by a monitored varistor network** on the board instead of DIN-rail arresters.<br/><sub>Reused in the cost-first design. Open: the varistors' thermal links have no DC rating.</sub> |  |
| D-032 | **Insulation coordination:** reinforced between the DC side and anything touchable (8 kV impulse), basic to PE; 2000 m once the listed failures are fixed.<br/><sub>Standard values transcribed from memory; the arrester credit is not verified against the standard text.</sub> |  |

## ⚡ Auxiliary supply and thermal

| ID | Decision · why | Today |
|---|---|---|
| D-021 | **HV bootstrap supply:** 30 W single-switch flyback on 1700 V SiC, starting at 229 V; on the DAB fed from port 1 only.<br/><sub>The cost-first module has a 75 W flyback fed from both ports (D-045).</sub> |  |
| D-022 | **The 30 W bootstrap cannot run the module at power** — it boots, communicates and shuts down.<br/><sub>Closed by D-051: the cost-first design is self-powered at 75 W.</sub> |  |
| D-029 | **Fan San Ace 9GT1224P1S001,** −40…+85 °C, one per cell.<br/><sub>The cost-first fan is rated −10 °C — an open risk (R-05).</sub> |  |
| D-076 | **Auxiliary supply AUX-75 rev A3: one design re-rated for the four-wire inverter** — live 30 W continuous / 48 W for 1 s, SELV 42.2 / 64.2 W, total 72.2 / 94.2 W; turns 50:9:10 on the same core, current sense 3 × 0.866 Ω; no BOM cost delta. The four-wire DC precharge drawn at 200 Ω of the same family.<br/><sub>The four-wire live load (26.2 W) and the contactor pull-in peaks (42.2 / 38.9 W) did not fit 24 / 32 W (D-074). Margins: flux 5.7 %, drain 3.1 %; efficiency 76.3–84.8 %. Open: a new transformer sample set; about ±0.5 % of nominal L<sub>p</sub> works with the 0.866 Ω sense; the AC coil module stays RFQ (four-wire live reserve 3.8 W); PV-P100/110 held standby 20.13 W at the stack of maxima.</sub> |  |

## 🧲 Magnetics

| ID | Decision · why | Today |
|---|---|---|
| D-039 | **Magnetics verified three ways** (OpenMagnetics, our own calculation, the designer's figure); the magnetics engineer owns every construction.<br/><sub>The first verification found large loss gaps on the DAB transformer and series inductor.</sub> |  |
| D-048 | **Cost-first magnetics:** PV inductor rev M2 (magnet wire on the same toroids), port filter = one ring plus capacitance to PE, new bias and auxiliary transformers.<br/><sub>About 11 mA into PE accepted (high-touch-current measures). The winding choice was amended by D-054.</sub> |  |
| D-054 | **PV inductor in solid round wire,** 145 °C hot spot at the worst point (limit 155 °C); the auxiliary transformer's SELV winding goes to litz.<br/><sub>D-048's edgewise choice rested on a tool run on the wrong conductor; the two models disagree by 27 % on the flat wire.</sub> |  |

## 💰 Sourcing and cost

| ID | Decision · why | Today |
|---|---|---|
| D-031 | **Sourcing policy:** cost-driving parts from Asian, preferably Chinese, makers with documented qualification, checked on LCSC; the TI C2000 stays.<br/><sub>Owner instruction; re-opened the device and topology choices for re-runs.</sub> |  |
| D-038 | **Design-to-cost targets** at 1,000 pieces (PV-P75 ≤ 2,000 USD).<br/><sub>Superseded by the 800 USD working budget of D-044.</sub> |  |
| D-040 | **Second sources for everything that is not a power device:** 107 lines studied, 21 adopted; some parts kept on purpose.<br/><sub>On the control boards this buys supply security and documentation rather than money.</sub> |  |
| D-052 | **Cost of the drawn cost-first boards** recorded against the benchmark, with the next cost levers.<br/><sub>Its figures predate D-054; current figures are generated in <a href="../../bom/COST.md">bom/COST.md</a>. Budget not met; most of the total is estimate.</sub> |  |
| D-055 | **Chinese power modules stay request-for-quotation alternates;** the designs stay on paralleled discretes.<br/><sub>No candidate has a public price; break-even prices are set; the BASiC BMF008MR12E2G3 is the module to quote for the DAB.</sub> |  |
| D-069 | **LCSC sourcing pass for every transistor and diode position.** The main switch SG2M040170HJ is on LCSC (C42456100, 5.07 USD at 90+, 418 in stock), not an RFQ part at an estimated 4.07 USD; 25 of 42 positions are in stock as specified; the three drop-in MDD TVS are adopted; other substitutes are recorded with their re-check; no orderable part exists for the 1700 V flyback switch and the inverter's PNP followers; four price rows are corrected.<br/><sub>The owner's instruction of 2026-10-05. The cost model uses the live switch price (+24 / +32 / +36 USD per PV-P75 / PV-P100-110 / PCS-P125 module). No Chinese SiC datasheet states a short-circuit rating. Stock and prices are a snapshot.</sub> |  |
| D-056 | **PV module re-run on the drawn boards:** peak 99.47 %, full power to 45 °C inlet; a seventh battery-side film capacitor and a narrower over-current window go into the next board revisions; 32 kHz stays; the PV-side bank is not reduced.<br/><sub>Four comparison rows fall below Megarevo's published table (cold limit, altitude, standby, load rejection until the seventh capacitor); PV-P100/110 is a derated build on these boards.</sub> |  |
| D-058 | **Board revisions of D-056 drawn:** PV-PWR and PV-PWR-4 rev A2, PV-CTL rev A1; battery-side film bank of the three-phase board 7 × 45 µF (315 µF), bleeder 8 × 73.2 kΩ per port, over-current window 68.9–79.9 A with the thresholds derived from each sensor's own reference output.<br/><sub>Closes the load-rejection overshoot and moves the window's lower edge from 6 % to 10.6 % above the normal peak; the 70 A target is missed by 1.1 A and accepted. Four former 24 V / 5 V pins of the board-to-board connector now carry the sensor references, and standby with both contactors held rises to 21.0 W. Open: the comparator's offset at the trip node, the reference output's drive rating and drift, and the trip chain of sim/pv_control.py — the first and the last were taken up by D-072 and D-065.</sub> |  |

## ⚡ DAB-D60

| ID | Decision · why | Today |
|---|---|---|
| D-011 | **The DAB-04 efficiency figures are Wolfspeed web claims;** the user guide documents less.<br/><sub>Our own efficiency map comes from `sim/dab_design.py`.</sub> |  |
| D-014 | **DAB-D60 design:** turns ratio 11:12, 6.5 µH total series inductance, 150 µH magnetising, triple-phase-shift modulation, firmware flux balance.<br/><sub>Full power only inside the derating map.</sub> |  |
| D-015 | **DAB efficiency reported twice:** by the loss model and by the model scaled to Wolfspeed's measurements (about 2.5 × the loss).<br/><sub>DAB-04 is not claimed; only the bench can close the gap.</sub> |  |
| D-017 | **One power module per bridge,** with the thermal risk stated.<br/><sub>Closed by D-051: superseded by the paralleled-discrete design — which D-068 records as a study without a schematic; the drawn DAB60 rev B0 keeps the modules.</sub> |  |
| D-018 | **Parallel DAB branches** share current through a common reference over CAN and a current loop per branch; no carrier-sync line.<br/><sub>The system controller caps total power; the PCS needs DC-current feed-forward.</sub> |  |
| D-068 | **DAB-D60 study identity, fault timing, admitted map and light-load policy.** The drawn board is DAB60 rev B0 (2 × CBB011M12GM4T); the discrete D2W proposal is a study with no schematic. The short-circuit chain is 0.99 × the assumed withstand (release block: maker-confirmed t<sub>SC</sub> ≥ 2.22 µs and E<sub>SC</sub> ≥ 2.18 J); fault peak 632 A, series-inductor saturation requirement 700 A. The admitted map follows the commutation deck at V<sub>DS</sub> ≤ 1,200 V: 60 kW at 11 of 20 window points until a double-pulse test; calibrated claim 99.09 % peak, 98.80 % at 800 / 800 V. Firmware rules FW-DAB-1…7 for light load and FW-DAB-8…10 for the inverter's 0.41 mF link.<br/><sub>Review PCM-09…12: a mixed-generation spec, an arithmetic error in the fault chain, an unjustified 1.5 × credit on the deck peaks and no idle policy. Full load at 900 V on either port is not admitted today. Calculated.</sub> |  |

## ⚡ PCS-P125

| ID | Decision · why | Today |
|---|---|---|
| D-047 | **PCS-P125 architecture:** three-level T-type with discrete Chinese IGBTs at 16 kHz.<br/><sub>Withdrawn by D-053: its devices overheat and its DC link cannot hold the midpoint at power factor 0.</sub> |  |
| D-053 | **PCS-P125 power stage: two-level on 1700 V SiC,** 6 × Sichain SG2M040170HJ per switch, 32 kHz, LCL filter.<br/><sub>Every device at ≤ 0.56 of its rating; confirmed by the cross-check of D-057. Its frequency, filter, cost and efficiency are replaced by the design point of D-060 (which corrects D-059).</sub> |  |
| D-057 | **Two-level stands after an independent cross-check** against Wolfspeed's T-type and two-level reference designs - on robustness and simplicity, not on cost.<br/><sub>Inductors were priced at half their material cost (about 979–1,028 USD at 5,000 units, not 869); peak efficiency about 98.9–99.1 %, not 99.20 %; threshold binning is required for six paralleled devices; AC-02 now states full current at any power factor. The cost and efficiency figures are replaced by D-060 (which corrects D-059).</sub> |  |
| D-059 | **PCS-P125 design point after re-optimisation with real inductor designs: the two-level SiC stage stays, at 24 kHz** — 36 × SG2M040170HJ (6 per switch), L1 130 µH, C<sub>f</sub> 75 µF, L2 6 µH, hardware trip ±450 A.<br/><sub>Calculated: peak efficiency 99.09 %, 98.42 % at full load; three-wire 1,365 USD at catalogue prices and 1,092 USD at 5,000 units (8.7 USD/kW), four-wire 1,629 / 1,304 USD; the filter is 404 USD and 30 kg of that. More than twenty candidates were compared with their inductors designed, not priced by a rule: the earlier design corrected costs 1,194 USD, a SiC T-type 1,236 USD (1,279 USD with 1700 V outer devices), an IGBT T-type at 16 kHz 1,607 USD. Open: powder-core inductors were not searched (the filter is 37 % of the BOM), L1 sits at its 140 °C hot-spot limit, the stiff-grid resonance is 7.7 kHz against 8.0 kHz, the current-loop bandwidth falls to 0.75 kHz with THDi not simulated, and nothing is quoted. Its 24 kHz point and these figures are superseded by D-060: they rested on a fault in the magnetics tool.</sub> |  |
| D-060 | **Corrects D-059: the inverter's design point is 32 kHz, L1 120 µH, C<sub>f</sub> 50 µF, L2 6 µH** — still two-level on 36 × SG2M040170HJ.<br/><sub>Calculated: peak efficiency 98.99 %, 98.30 % at full load; worst junction 123 °C at 110 % load and 45 °C inlet; three-wire 1,409 USD at catalogue prices and 1,131 USD at 5,000 units (9.0 USD/kW), four-wire 1,694 / 1,361 USD; the filter is 443 USD (549 at catalogue prices), 39 kg and 39 % of the BOM. The 24 kHz point rested on a fault in the magnetics tool (a permeability of 1 for the amorphous core material at 20–30 kHz, so an air core): modelled properly its inductor loses 263 W, not 165 W, and reaches 198 °C. With the corrected model the next two-level point is only 11 USD away, so the exact frequency and inductance are not a firm result; the two-level choice is (148 USD below the cheapest T-type that keeps the voltage rule). Open: powder-core inductors were not searched, the two loss models differ by 1.8 × on foil copper loss, the amorphous core-loss fit is quoted from memory, L1 sits at its hot-spot limit, THDi and the control loops are not simulated, and nothing is quoted. The control study followed in D-066.</sub> |  |
| D-061 | **Inverter power board PCS-PWR rev A0 drawn** (`gen/pcs_power.py`; 26 sheets, 1,692 parts, 763 nets): three two-level legs of 6 × SG2M040170HJ per switch, the split film DC link, the lean DC port scaled to 250 A with a 400 A fuse per pole, two AC contactors in series and the 75 W auxiliary supply; L1, L2 and the common-mode choke are chassis parts.<br/><sub>A new gate-drive preset for six paralleled devices (per-device 8.75 / 7.5 Ω, a 0.5 Ω Kelvin resistor, two PNP turn-off followers; a short circuit is off in 0.60 µs with 1,212 V overshoot against 1,445 V allowed). `PCS_PC` is the PV contract pin for pin, plus a 2 × 8 header `PCS_X`. Open: the desaturation may trip in the 200 ms overload; the hardware dead time of 185–510 ns is above the study's 300 ns; the current sensors and other parts are quotation items; the 400 A fuse is not coordinated with the DC contactor; the AC arresters are not monitored; there is no start-up path from the AC side; the auxiliary's live winding runs at 23 of 24 W. The desaturation, the phase sensor, the fuse coordination and the bleeders were taken up by D-067, the AC start-up path and the auxiliary's live winding by D-074 and D-076.</sub> |  |
| D-062 | **Inverter control board PCS-CTL rev A0, first stage drawn** (`gen/pcs_ctrl.py`, a re-valued variant of the PV control board; the PV board's outputs are unchanged).<br/><sub>Hardware current window about ±455 A (422–491 A worst case), DC-link over-voltage about 1,025 V with the band top at 1,050 V, lower-half over-voltage about 540 V, inductor over-temperature about 130 °C. AC contactor 1 is gated by HEALTHY only; the DC contactor keeps HEALTHY OR HOLD, because dropping HOLD would remove a layer of its hold-off protection. To confirm: the phase-current sensor (a quotation part, 4.0 mV/A assumed) and the control limits the study does not specify. Completed by D-064, which corrects its controller budget; its window was re-valued for the frozen sensor by D-067 (426–486 A).</sub> |  |
| D-063 | **First board-level cost of the inverter: 1,521 USD at catalogue prices, 1,292 USD at 5,000 units (10.3 USD/kW)** — the module BOM of the drawn boards (`bom/PCS-P125_module_BOM.csv`).<br/><sub>The design study said 1,409 / 1,131 USD. Reasons: +39 USD for 48 press-fit studs (the study allowed 13 USD for studs, harness and standoffs together), +71 USD of circuitry the study's allowances did not cover, and about 50 USD more at 5,000 units from the cost model's own volume factors. About 1.9 × the current-adjusted benchmark BOM of about 690 USD; the stud count and powder-core inductors are the first cost levers. With the live switch price of D-069 the same BOM is 1,557 / 1,322 USD today (<a href="../../bom/COST.md">bom/COST.md</a>).</sub> |  |
| D-064 | **Inverter control board PCS-CTL rev A0 complete for the three-wire build** (`gen/pcs_ctrl.py`; 8 sheets, 305 parts, 209 nets).<br/><sub>Added: the `PCS_X` signals into the ADC, the second AC contactor through the trip latch, the residual-current test output and the inverter's own pin plan. It corrects D-062's controller budget: the 100-pin F280039C has 23 analog pins, the three-wire build's 24 signals fit on 21 because the eight temperature inputs share one pin through a multiplexer, and 6 of 16 PWM outputs are used. With PCS-PWR the inverter now has its schematic set, module BOM and costed BOM. Open then: the four-wire build (drawn since D-074); the phase-current and residual-current sensors are quotation parts with assumed data; the open items of D-061 and D-062 stand; no control simulation and no independent review — the last two since done (D-066, D-067), and the phase sensor frozen.</sub> |  |
| D-066 | **PCS-P125 control study:** an αβ PR current loop at 1,750 Hz (usable band 1.0–3.25 kHz) with h1 / h5 / h7; with the passive R<sub>d</sub>–C<sub>d</sub> branch PM ≥ 48.7° and GM ≥ 12.1 dB from a stiff grid to SCR 5 — without it the stiff grid is unstable, so the branch stays; PLL 30 Hz; DC-link loop 40 Hz with a mandatory DC-current feed-forward; grid forming with a terminal short held at 366 A; THDi estimated at 1.5–2.2 %; a protection state machine checked for eight invariants.<br/><sub>Review PCM-21 and risk E1. The earlier claim that 1 kHz was the highest usable current-loop bandwidth was wrong: 1 kHz is the lower edge, and a weak grid lowers the loop to about 0.3 kHz. A 0.1 pu dip tripped the window (465 A) — answered by the ride-through limiter of D-077; the DC link a DC/DC sees is 0.41 mF. Not established: a switched model, measured THD, the standards text, anti-islanding, the four-wire build (the neutral leg since D-077). Calculated.</sub> |  |
| D-067 | **PCS-P125 corrections from the review:** the DC-link inventory is 409.4 µF (precharge 185 J at 950 V, resistor rating 280 J; bleeders 4 × 93.1 kΩ, 14.7 min worst case under the 15 min label); the upper DC-link half gets a firmware limit; the P–Q–V<sub>dc</sub>–V<sub>ac</sub> envelope is published (605–643 V DC for rated current at 400 V, 698–737 V at 460 V); a six-device acceptance rule bounds sharing at 1.08 × the mean; DESAT 2 × US1MH (6.41–9.37 V, margin 1.08 at 161 °C); the DC-port fuse–contactor coordination with two installation requirements; the phase sensor frozen to the STK-250HO/4 (window 426–486 A); the Al<sub>2</sub>O<sub>3</sub> pad text; a live-24 V step budget (38.9 W against the 32 W peak with an assumed coil — inside 48 W since D-076).<br/><sub>Review PCM-03…07, 14, 15, 20, 25. Open: AC-02's full load from 600 V is not reachable (the owner's decision); the sensor's working voltage, qualification and dv/dt immunity; device binning with Sichain; the 14.7 against 15 min margin; a shorted capacitor over-stresses the other half for about 20 ms. The DESAT diodes are 1,300 V BYG23T-M3/TR since D-081 (same window).</sub> |  |
| D-074 | **PCS-P125: four-wire build drawn, start-up from the grid on both builds, firmware specification, declarations.** PCS-PWR-4W + PCS-CTL-4W = module PCS-P125-4W with a fourth two-level leg (not a midpoint neutral: 43.2 mF of electrolytics, 2,337 / 1,376 USD, against 300 / 243 USD); DC window mode A from 724 V, mode B from 624 V at 230 V; an AC tap with a 1.6 A fuse and six avalanche diodes into the auxiliary plus an AC precharge (risk F8 closed); 30 firmware rows (modes, transfers ≤ 15.7 ms, parallel operation, recorder, upgrade); declarations (kVA tiers, AC short circuit, airflow, frequency, precision by RSS, load acceptance, insulation-monitor validity, two-source label).<br/><sub>D-073 parity. Drawn BOMs PCS-P125 1,587.79 / 1,348.18 USD, PCS-P125-4W 1,924.28 / 1,634.70 USD (catalogue / 5k). Open then: the aux live winding and the four-wire precharge (→ D-076), the neutral-leg loop and the 0.1 pu ride-through (→ D-077); still open: the L-N surge level (a 3+1 needs a GDT data sheet), the DC-component measurement pairing, the PCS cold start, the RFQ parts without data sheets.</sub> |  |
| D-077 | **PCS control study extended:** VF secondary restoration (voltage accuracy 0.59 % worst-case sum, frequency ±60 ppm), THDu 1.31 % / 1.98 % (three- / four-wire, analytical), imbalance ±0.41 % / ±0.76 %, a ride-through state with a 380 A per-sample clamp and a stiff-grid derating (95.5 / 105.5 / 115 kW at 0 / 0.1 / 0.2 pu), the neutral leg on the off-grid cascade (PM 57°, GM 8.7 dB).<br/><sub>The four published off-grid rows had no computed counterpart and D-074 left the ride-through and neutral-leg items open; the PCS comparison now has no pending row. Firmware only. Open: the stiff-grid first-millisecond peak is handled by derating; full-load off-grid steps dip to 0.38 pu and overshoot to 2.17 pu; not modelled: paralleled restoration, a switched neutral leg, the per-phase virtual reactance. D-079 revised it: the derating became the fallback behind a 270 A ride-through clamp, and the 0.38 / 2.17 pu came from an unbounded model (now 0.43 / 1.77 pu); D-080 moved the clamp to 378.0 A and re-tabled the fallback (94.5 / 104.5 / 114.0 / 124.0 kW at 0 / 0.1 / 0.2 / 0.3 pu).</sub> |  |
| D-078 | **Re-check R2, power stage and protection chain:** the window trip turns the gates off above the window top — 520.8 A in the register's text, 520.5 A over 3.54 µs in the generated chain on the L1 envelope — where R<sub>G,off</sub> 7.5 Ω peaked at 1,457 V against 1,445 V: **R<sub>G,off</sub> 8.75 Ω**, 1,437 V, admissible 533.6 A; the **CMPSS backup lowered** to DAC ±1,075 codes (423.9–497.5 A inside 417.3–504.2 A), so no gates-off current reaches the L1 knee (flux rule 566 A, hot knee 578 A) — the device's pulse rating is not what the ceiling protects; the L1 type test to 600 A; **R<sub>DS(on)</sub> ≤ 40.0 mΩ** per device, switches above it on 209 A tiers by lot (one corner — replaced by the grade map of D-080); **one coil contract** (20 W pull-in ≤ 100 ms, 4 W hold); the residual-current monitor's RFQ contract; [INSTALLATION.md](../requirements/INSTALLATION.md).<br/><sub>Review R2-02, -03, -06, -07, -12, -13, all Confirmed. Zero BOM cost: device loss +16 W, peak efficiency 98.98 %; the firmware PPB over-voltage backup 1,045 → 1,035 V. Rejected: a core holding the flux rule to 650 A (+32 / +27 USD per three-wire module), three more films per leg, a 10 ppm/K ladder. Open (hardware gates): short-circuit survival; the L(I) test; the × 1.5 layout inductance near 520 A / 1,050 V; no turn-off SOA above 70 A per device; the comparator delay (2 × typical) and the 1.40 T hot saturation flux are estimates; RFQ items: the R<sub>DS(on)</sub> distribution or bin, an RCM and an AC coil module meeting the contracts; 8.75 Ω is not E96. Calculated.</sub> |   |
| D-079 | **Re-check R2, control study and hand-over:** a tolerance regression (1,944 factorial + 1,000 random cases at the assembly's tolerances, worst PM 48.10°, GM 11.82 dB); off-grid steps **bounded at 0.43 / 1.77 pu** with a load-current feed-forward (1 kHz) and an over-voltage deadbeat (1.2 pu), and a declared envelope (≤ 1.9 pu to 0.5 ms … 1.03 pu after; re-set to the ITIC-style points of AC-04 by D-080); **stiff-grid ride-through without derating** by a 270 A ride-through clamp on the divider-inverted C<sub>f</sub> voltage (onset ≤ 403 A, 23 A margin) — the derating becomes the fallback above an estimated SCR 64.5 (8.07 MVA per module; 61.7 / 7.71 MVA since D-080); in CV mode the soft limit holds the DC loop and the DC/DC power is 89.5 / 119.5 / 125 kW at SCR 5 / 10 / 20; a DC/DC on a battery-less bus cuts within 0.51 ms (the PV row: 209 µs, valid to a 782 V set point); coupled four-wire cases; the **AC start as an executed state machine** (17 states, 35 fault cases) with repairs H1–H5 and its own AC_STOP state; 31 firmware-limit rows on PCS-CTL.<br/><sub>Review R2-01, -04, -13, -14 (Confirmed) and R2-05 (Firmware Handled). The reviewer's independent reproduction of the nominal margins (71.15 / 61.38 / 61.68 / 49.04°) is recorded as corroboration; D-077's "no firmware can catch the onset" is withdrawn. Open: the bench and a switched model for the 23 A margin and the first millisecond; the standards texts (ITIC, IEC 62040-3, EN 50549); relay timings and the 40 W auxiliary draw ASSUMED; DC_MATCH unused but in the table; the H2 numbers not yet in the JSON; no DC-match timeout in RECTIFY with a battery; a sag during the pull-in not among the cases. Simulated / calculated.</sub> |   |
| D-080 | **Re-check R3 — synchronised close, four-wire trip layers, DC-bus coordination, SiC grades, off-grid envelope:** the grid-tie close **one coil at a time** (SYNC → SYNC_CLOSE_K2 → settled 200 ms → SYNC_CLOSE_K1; I12 unconditional, I14 / I15 added; 646 state-event pairs and 24 fault runs over both starts, no breach; coil peak 38.9 / 42.2 W against 48 W, was 54.9 / 58.2 W); the four-wire L-N short **replayed through both trip layers** — the D-079 firmware let the CMPSS backup trip at a low corner, so a 270 A clamp for a 5 ms onset window (hold 378.7 A, 13.3 A below 423.9 A, firmware trip at 200 ms; a hardware trip declared: FAULT, no automatic clear); every "may trip" screen on the lower edge 423.9 A — per-sample clamp **378.0 A**, onset margins 20.5 / 18.4 A net of an ADC-noise term, fallback derating 94.5 / 104.5 / 114.0 / 124.0 kW from an estimated SCR 61.7 (7.71 MVA per module); the **coupled PCS / PV trajectory** instead of an assumed 50 µs DC/DC stop — the island rides through to a 909 V set point (921 V with one PV module) on the one-node model — a model validity, not a rating, as D-081 states — the PV coordination row mandatory, no hardwired line below that; **two module grades** — A (every device ≤ 40.0 mΩ): full tiers to 45 °C, 198.0 / 216.0 / 242.9 A at 60 °C; B: its own table, 179.8 / 192.6 / 192.6 A at 60 °C; one 200 ms cap rule (0.22 s, 12 min); the grade in the parameter set, reported with the module serial; the **off-grid envelope** re-set to the ITIC-style points (FROM MEMORY), adopted by delegation as REQUIREMENTS AC-04 (+0.054 pu at the tightest point; IEC 62040-3 not claimed).<br/><sub>Review R3-01…04 Confirmed, R3-05 Improvement Recommended. Firmware and acceptance rules and one requirement row; no hardware change, nothing added to the BOM. The reviewer's independent inner-loop reruns (1,944 cases stable, worst spectral radius 0.999518, nominal PM 71.15 / 61.38 / 61.68 / 49.04°) match to the last digit and are recorded as corroboration. Open: the relay timings, the synchronisation model, the path check and the ADC noise ASSUMED; the 13.3 A hold margin and the 909 V validity need a switched model and the bench; the ITIC and IEC 62040-3 texts not on file; short-circuit survival a hardware gate; Sichain's R<sub>DS(on)</sub> distribution or a ≤ 40 mΩ bin (RFQ); hot R<sub>DS(on)</sub> on the typical curve ASSUMED. Simulated / calculated. The DESAT diode rating, the cable model and the envelope statement were completed by D-081.</sub> |  |
| D-081 | **Re-check R4 (economical) — DESAT diodes re-rated, the DC-bus window enforced, the envelope as a declared capability, the cold rating, grade B's rating, the magnetics RFQ index:** the DESAT string of every 1,700 V gate-drive channel (inverter and PV phases) is **2 × Vishay BYG23T-M3/TR, 1,300 V each**, each diode alone blocking the 1,130 V static envelope of an off switch (× 1.15; design value 1,150 V), the dynamic share ≤ 867 V per diode — the inverter's window stays 6.41–9.37 V (grade tables identical), the PV preset goes from three diodes to two (6.41–9.37 V, was 5.43–8.47 V), +0.96 to +2.12 USD per module at 5,000 units; the coupled bus model carries the **inter-module cable** (up to +28 V, every corner rides through) and the window is a **product rule** — default 750 V (755 V four-wire mode A), a 782 V clamp in the PV module, island start only ≤ 791 V; 909 / 921 / 846 V are model validities, not ratings — with a **harness contract** for the integrator (≤ 20 m and ≤ 20 µH per run, DC+ / DC− together, loop ≤ 12.6 mΩ, nothing else on the link, ≤ 2 PV-P75 per link); **AC-04 reworded** as the module's declared output capability, not a load-compatibility claim, with a release sequence (grid-following first, then managed island loads with an agreed specification, general off-grid only with an output class and its test method); the inverter's **cold rating** is full operation from −10 °C inlet (passive table 20 / 15 / 8 kVA three-wire at 600 V DC; AC-02 amended by delegation; the −30 °C fan on file rejected, a cold-rated fan RFQ open); **grade B** states 124.57 kW at 60 °C (PF 1, 400 V); [RFQ-MAGNETICS.md](../requirements/RFQ-MAGNETICS.md) indexes ten RFQs; the port ring's BOM line names the flat-µ grade and AUX-T1's thermal test reads 94.2 W.<br/><sub>Review R4 by the register: 3 Confirmed (E01, E04, E11), 4 Already Fixed, 3 Improvement Recommended, 2 Not Applicable (D-081's text counts 4 / 4 / 2 / 2). No topology, capacitor bank, brake chopper or inter-module trip line. Open: the new diode's V<sub>F</sub> extrapolation and temperature coefficient, the per-diode split after reverse conduction (bench), creepage across one diode in layout, no AEC-Q101 variant and thin LCSC stock; the DAB / GDRV-HB 1,200 V string keeps 3 × US1MH (OPEN); the harness figures, ESR, skin effect and the PV voltage loop not credited; the coupled-bus peaks and the 13.3 A on the bench; a managed-island load specification; the cold-rated fan RFQ; the magnetics RFQ's 18 open rows. Calculated / simulated.</sub> |  |

## 🔬 Reviews

| ID | Decision · why | Today |
|---|---|---|
| D-023 | **Independent reviews** found 58 defects (7 critical) after every board already passed its own checks.<br/><sub>Assigned to board revisions; findings in `gen/data/review_*.csv` and `integration_findings.csv`.</sub> |  |
| D-070 | **Pin audit ledger E completed for the cost-first boards:** 239 drawn parts, 180 pass (1,854 pins), 55 not auditable with a written reason; four naming mismatches corrected in the drawing to the datasheet wording (pin numbers and functions agreed); the F280039C's 100 pins transcribed from its datasheet table and cross-checked against its figure.<br/><sub>DEL-4. The generated audit report now counts 240 parts, 185 passing (1,892 pins), 0 failing.</sub> |  |
| D-071 | **Wolfspeed firmware packages filed and cross-checked** (CRD200DA23N-GMA, CRD60DD12N-GMB, CRD-60DD12N-K): the -K is a three-phase LLC, not a DAB; the GMA and GMB firmware are open-loop starting points with almost no protection in firmware. Adopted as firmware requirements: R-WS-1…9 and, for the DAB, FW-DAB-11 (sensor offsets nulled at idle).<br/><sub>REF-2. Nothing device-specific is carried over; R-WS-10…14 stay recommendations. Notes in each package's `FIRMWARE-NOTES.md` and [REFERENCE-LESSONS §6](../requirements/REFERENCE-LESSONS.md).</sub> |  |
| D-082 | **Re-check R5 (closure) — no new defect; the qualification plan:** the reviewer verified D-081 at BOM level (12 / 16 / 24 / 32 BYG23T-M3/TR on PCS-PWR / PCS-PWR-4W / PV-PWR / PV-PWR-4, two per channel) and by his own arithmetic (the 6.415–9.365 V DESAT window; 150 V of margin at the 1,150 V design envelope), confirmed the cable-aware bus window (790.9 V permissive, 1.70 V harness drop, 755 V), the −10 °C inverter grade, the AC-04 wording and the two-grade policy, and recorded that the 1,300 V diode closure does not transfer to the earlier platform's 1,200 V class; no hardware, firmware or requirement change. [QUALIFICATION-PLAN.md](../requirements/QUALIFICATION-PLAN.md) consolidates every open gate of the five rounds as Q-01 … Q-44: Q-01…Q-03 the DESAT string's dynamic qualification, Q-04…Q-06 the battery-less bus and harness, Q-07…Q-09 the cold rating, managed-island load acceptance and grid-code compliance, Q-10…Q-12 the SiC switching cell (short-circuit survival 2.03 µs / 0.80 J requested, not demonstrated), Q-13 onward the layout-, supplier- and production-dependent items — each with the acceptance number our records give, the test asset, the product or claim it blocks and the stage (representative switching cell → controlled prototype → DVT → production controls).<br/><sub>Register [review_r5.csv](../../gen/data/review_r5.csv): six rows, all closed (4 Already Fixed, 1 Not Applicable, 1 Improvement Recommended). The next useful milestone is a controlled prototype and a representative switching-cell qualification, not another script pass; a paper waiver cannot replace the physical gates. Open: every gate of the plan, by definition. Documentation only; nothing measured.</sub> |  |

The independent review of commit `033d8d8` (27 findings, [review_pcm.csv](../../gen/data/review_pcm.csv)) was answered
the same day by D-065 to D-069 and D-072; with PCM-14 and PCM-22 closed by D-076 / D-074, 22 findings are closed and 5
open. The re-check R2 of commit `a427981` (14 findings, [review_r2.csv](../../gen/data/review_r2.csv): 9 Confirmed,
1 Firmware Handled, 2 Already Fixed, 1 Not Applicable, 1 Improvement Recommended) was answered by D-078 and D-079; all 14
rows are closed in the register, their hardware gates stay open. The re-check R3 of commit `615e4b5` (5 findings,
[review_r3.csv](../../gen/data/review_r3.csv): 4 Confirmed, 1 Improvement Recommended) was answered by D-080; all five
rows are closed in the register, with the bench and the standards texts as the gates. The economical re-check R4 of
commit `845131d` (12 decision areas, [review_r4.csv](../../gen/data/review_r4.csv): 3 Confirmed, 4 Already Fixed,
3 Improvement Recommended, 2 Not Applicable by the register) was answered by D-081; all twelve rows are closed in the
register, and the restrictions it accepts are stated with their boundaries
([12 · Risks](12-risks-and-open-items.md#standing-restrictions), [08 · Verification](08-verification.md#-independent-design-reviews)).
The closure re-check R5 of commit `5c56aaa` (6 rows, [review_r5.csv](../../gen/data/review_r5.csv): 4 Already Fixed, 1 Not Applicable,
1 Improvement Recommended) found no new defect and was answered by D-082, which adds the
[qualification plan](../requirements/QUALIFICATION-PLAN.md) — every open gate in one list.

---

<!-- footer --> ← [Glossary](glossary.md) · [Documentation index](../README.md) · [Overview](01-overview.md) →

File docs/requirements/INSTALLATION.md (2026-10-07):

<!-- breadcrumb -->
[Home](../../README.md) › [Documentation](../README.md) › Installation conditions

# 🛡️ Installation conditions

> What a cabinet integrator must provide for the PV modules' and the inverter's stated protection and ratings to hold — one list, every row traced to the generated line it comes from.







---

> [!IMPORTANT]
> **What this list is, and what it is not.** It collects, in one place, the conditions that the modules' own checks
> assume about the world outside the module: the source on each DC port, the upstream protection and the fault
> currents it must clear, the earthing, the environment, the control wiring and the labels. Nothing here is
> bench-validated. Every figure is calculated, simulated or assumed in the file it is quoted from, and the file's own
> labels — ASSUMED, ESTIMATE, RFQ (request for quotation), FROM MEMORY, OPEN — are kept where it puts them.
> **A condition recorded here is not a protection the module provides.** Where a row says the upstream device must clear
> a current band, the module does not clear that band itself; a cabinet that does not meet the row leaves the band
> unprotected and the module's stated coverage does not hold (review finding R2-12,
> [review_r2.csv](../../gen/data/review_r2.csv)). This is not a certification, a safety case or a claim of standalone
> protection.

> [!NOTE]
> **Re-verified after the rebuild of 2026-10-07** ([D-078](DECISIONS.md), [D-079](DECISIONS.md)), and again after the
> re-runs of the inverter chain and the PV boards at about 12:00 and 12:07 the same day. Every quoted fragment was found again in its
> file and its line number corrected (hashes in the box below); where the text had changed the quote now carries the new
> text (the L1 saturation current, the four-wire coil contract, the attempt counter, the ride-through measure, the
> uncoordinated DC-rejection figures). INST-27 was rewritten and INST-71 to INST-74 added; four rows of
> [Where the records disagree](#where-the-records-disagree) are reconciled by notes in the architecture files.
> **Re-verified again after the rebuild for the re-check R3** ([D-080](DECISIONS.md), later on 2026-10-07): every quoted
> fragment found in its file at the line its link names (68 labels re-pointed to moved lines); the quotes whose text
> changed now carry the new text — the module grades and their tier tables (INST-73, INST-44), the coupled PCS / PV
> bus rules (INST-71), the ride-through clamp and fallback figures (INST-27), the grid-tie close (INST-74) — and INST-75
> (the bolted output short on the four-wire build) is added. **Re-verified once more after the rebuild for the
> economical re-check R4** ([D-081](DECISIONS.md), the evening of 2026-10-07): every quoted fragment found in its file at
> the line its link names (97 labels re-pointed — the generated files gained lines, and the guide pages cited by line were
> edited in the same documentation pass); the quotes whose text changed carry the new text — the enforced DC-bus window
> and the cable model (INST-71), the inverter's environment line with its −10 °C rating (INST-44); INST-76 (the harness
> between the PV modules and the inverter) and INST-77 (the inverter's cold rating) are added, grade B's 124.57 kW is in
> INST-73, INST-28 carries the staged release of grid forming, and the installation-facing
> [standing restrictions](#standing-restrictions) of the review are listed. After a
> later rebuild, re-find each quoted fragment with `grep -nF '<fragment>' <file>` and correct the line number in its link;
> a fragment that no longer matches means the requirement may have changed.

## How to read this page

| Module | Power board | Control board | Its generated checks |
|---|---|---|---|
| PV-P75 (75 kW, three phases) | PV-PWR | PV-CTL (build PV-CTL-P75) | [PV-PWR][PV-PWR:1], [PV-CTL][PV-CTL:1] |
| PV-P100 / PV-P110 (four phases) | PV-PWR-4 | PV-CTL | [PV-PWR-4][PV-PWR-4:1], [PV-CTL][PV-CTL:1] |
| PCS-P125 (inverter, three-wire) | PCS-PWR | PCS-CTL (build 3W) | [PCS-PWR][PCS-PWR:1], [PCS-CTL][PCS-CTL:1] |
| PCS-P125-4W (inverter, four-wire) | PCS-PWR-4W | PCS-CTL (build 4W) | [PCS-PWR-4W][PCS-PWR-4W:1], [PCS-CTL][PCS-CTL:1] |

- **Rows.** Each requirement has an ID, `INST-nn`, in the order of the sections below; the table at the end is the list,
  one row per requirement with *why* (the module's own limit that makes it necessary) and *source* (the generated
  line). The sections carry the evidence: verbatim quotes with the line they are on.
- **Quotes.** Verbatim (the generated files are ASCII; the hand-written records keep their own characters); `…` between two quoted pieces marks an omission. A link
  such as [PV-PWR:15] goes to that line (`?plain=1` for Markdown files, which GitHub would otherwise render).
- **Labels kept from the files.** CALCULATED: a model or data sheet in a script under `sim/` or `gen/`. ASSUMED /
  ESTIMATE: the file says so. RFQ: part or data not yet in hand. OPEN: the file says it is not closed.
- **Which number wins.** Where two records give different numbers the row uses the generated one — the record wins over
  a page — and the difference is listed under [Where the records disagree](#where-the-records-disagree).
- **Terms, once.** IMD: insulation monitoring device. RCM: residual-current monitor. SPD: surge protective device. OVC:
  overvoltage category. SCR: short-circuit ratio (grid strength). EMS / BMS: energy / battery management system.
  SELV / PELV: safety / protective extra-low voltage. DVC: decisive voltage class. PE: protective earth. PD: pollution degree. K_A / K_B: the contactors of port A / B. L/R: time constant of the fault circuit. pu: per unit.

<details>
<summary>Source files as read — sha256 (first 16 hex), lines and modification time, re-read after the rebuild for the re-check R4 (D-081) on 2026-10-07 (PV-CTL's check and the module report rewritten with the same content)</summary>

| File | Lines | sha256 (first 16 hex) | Modified |
|---|---:|---|---|
| [hardware/PV-PWR/outputs/PV-PWR_design_check.txt](../../hardware/PV-PWR/outputs/PV-PWR_design_check.txt) | 39 | `605ad30b98672cbf` | 2026-10-07 20:21 |
| [hardware/PV-PWR-4/outputs/PV-PWR-4_design_check.txt](../../hardware/PV-PWR-4/outputs/PV-PWR-4_design_check.txt) | 39 | `93927cc86c53954f` | 2026-10-07 20:21 |
| [hardware/PV-CTL/outputs/PV-CTL_design_check.txt](../../hardware/PV-CTL/outputs/PV-CTL_design_check.txt) | 89 | `c762b158ba7926ef` | 2026-10-07 20:22 |
| [hardware/PCS-PWR/outputs/PCS-PWR_design_check.txt](../../hardware/PCS-PWR/outputs/PCS-PWR_design_check.txt) | 34 | `7de3d8949f0b72da` | 2026-10-07 20:22 |
| [hardware/PCS-PWR-4W/outputs/PCS-PWR-4W_design_check.txt](../../hardware/PCS-PWR-4W/outputs/PCS-PWR-4W_design_check.txt) | 46 | `dc0c3fe173066ceb` | 2026-10-07 20:23 |
| [hardware/PCS-CTL/outputs/PCS-CTL_design_check.txt](../../hardware/PCS-CTL/outputs/PCS-CTL_design_check.txt) | 136 | `c61398a6ce70b363` | 2026-10-07 20:23 |
| [sim/out/pcs_design/pcs_spec.json](../../sim/out/pcs_design/pcs_spec.json) | 13330 | `92c24c603f2865af` | 2026-10-07 20:13 |
| [sim/out/port_design/report.md](../../sim/out/port_design/report.md) | 471 | `7d15d615f48e685a` | 2026-10-05 20:49 |
| [sim/out/port_design/port_spec.json](../../sim/out/port_design/port_spec.json) | 916 | `96916e7da3b75eb7` | 2026-10-05 20:49 |
| [sim/out/pcs_design/report.md](../../sim/out/pcs_design/report.md) | 810 | `2acf70a88a54ec16` | 2026-10-07 20:13 |
| [sim/out/pcs_control/report.md](../../sim/out/pcs_control/report.md) | 967 | `bc682a5be70bd1c3` | 2026-10-07 20:20 |
| [sim/out/pv_control/report.md](../../sim/out/pv_control/report.md) | 458 | `1e9991ffb992a2c9` | 2026-10-07 20:15 |
| [sim/out/pv_design/module_report.md](../../sim/out/pv_design/module_report.md) | 139 | `48719cae5328d9ad` | 2026-10-07 19:43 |
| [sim/out/insulation/report.md](../../sim/out/insulation/report.md) | 380 | `2134017ef90341b0` | 2026-10-07 20:26 |

The design checks print the hashes of their own inputs in their first lines ("Built from", "Inputs read at this
build"); the hand-written records cited by line (REQUIREMENTS, DECISIONS, the architecture files, the guide pages)
are not stamped.

</details>

---

## ⚡ 1 DC port of the PV modules

The PV modules have two DC ports on one shared negative rail. Port A faces the PV array, port B a battery or DC bus.
Each port has one contactor (K_A, K_B). Only port B has fuses (one 250 A aR link per pole) and a precharge; port A has
neither.

### 1.1 Port A — the PV array

Port A's declaration is printed by both power-board checks (review PCM-16, [D-072](DECISIONS.md)). The three-phase
PV-PWR is the PV-P75, the four-phase PV-PWR-4 the PV-P100/110; only the numbers differ.

> `Port A admits: a current-limited PV array only - short-circuit current at the module terminals <= 168.8 A (1.25 x the 135 A port rating; K_A breaks 300 A at 1000 V both polarities x 200 operations: margin x1.78, carries x2.22), open-circuit voltage <= 1000 V (OV trip band 1039-1110 V), connected to the DC terminals through string fuses in the combiner (IEC 62548, ARCHITECTURE-COSTFIRST 6.3) and a load-break isolator, array and cable capacitance terminal to terminal <= 1.1 uF behind >= 11 uH (the 330 A discharge peak the making estimate assumes, back-calculated: ESTIMATE; the array's capacitance to PE is 16.5 uF, common mode only)` — [PV-PWR:15]

→ INST-01 … INST-05, INST-09

> `short-circuit current at the module terminals <= 225.0 A (1.25 x the 180 A port rating; K_A breaks 300 A at 1000 V both polarities x 200 operations: margin x1.33, carries x1.67)` … `the array's capacitance to PE is 22.0 uF` — [PV-PWR-4:15]

> `Port A does NOT admit: a stiff DC source (battery, DC bus, rectifier, another converter) - K_A would close onto the empty 290 uF bank with a peak of about 7.4 kA at 1000 V (0.03 ohm + 3.5 uH source and loop, 145 J stored: 53x the making rating's 140 A, weld likely), a fault fed by it is cleared only by K_A (<= 300 A normal opening, hold-off to 967-1033 A, 1500 A once) with no fuse behind it, and nothing blocks reverse current; a stiff DC source on port A requires the PV-PORT-180 / lean port with fuse and precharge (gen/port.py lean_port as the battery port B: 2 x HPE501 250 A aR links, 220 ohm precharge, polarity and dV interlocks)` — [PV-PWR:15]

> `K_A would close onto the empty 386 uF bank with a peak of about 8.3 kA at 1000 V (0.03 ohm + 3.5 uH source and loop, 193 J stored: 59x the making rating's 140 A, weld likely)` — [PV-PWR-4:15]

→ INST-06

> `Reverse power B -> A is NOT admitted with an array: there is no series diode, fuse or precharge on port A, the port over-current window (387-413 A, both directions, FLT_N) protects the module and not the array, and an array driven backwards conducts through its cells and bypass diodes (limited only by the modules' reverse-current rating and the combiner's string fuses) - firmware holds the port A current at >= 0 while the port is declared PV (second layer behind the converter's own current limit).` — [PV-PWR:15]

→ INST-07

> `K_A only after an insulation measurement of ≥ 33 kΩ (IEC 62109-2 rule, quoted from memory)` — [guide 04:169]
>
> `a load-break DC isolator upstream for maintenance` — [ARCH-COSTFIRST:281]

→ INST-04, INST-08

**Not closed (OPEN).** Connecting the array while port B is dead is the one case the files do not cover:

> `with port B live, after the converter has pre-charged the 290 uF A bank to within 20 V (then the making current is the array's Isc), otherwise onto the EMPTY bank at the array's Voc: making current about 499 A (Isc 169 A + 330 A discharge, ESTIMATE) against a published making rating of 140 A at 20 V only - covered: NO (Hongfa to confirm, R-04).` — [PV-PWR:15]
>
> `making current about 555 A (Isc 225 A + 330 A discharge, ESTIMATE)` — [PV-PWR-4:15]

→ INST-10. No installation condition closes it; the module's own mitigation is the precharge-first rule with port B live.

### 1.2 Port B — battery or DC bus

The PV power-board checks print no port B coordination line; it is in the port report (lean port) and in `port_spec.json`.
The lean battery port holds the contactor closed above its hold-off band and lets the aR link clear the high currents;
the band in between belongs to the installation ([guide 04:179-184]):

| Current from the battery into the module | Who clears it |
|---|---|
| ≤ 300 A | converter control and K_B, normal opening |
| 300 A – 967 A | K_B opens (fault opening; contactor replaced afterwards) |
| **967 A – 1,250 A** | **neither — the upstream battery protection** (K_B is held; the 250 A aR link breaks only from 1.25 kA) |
| 1,250 A – 50 kA | HPE501/000B100-250 aR fuse in each pole |

> `upstream protection interrupts any current of 0.97-1.25 kA into the battery port within 0.26 s; prospective short-circuit current <= 50 kA at the module terminals with L/R <= 1 ms (the contactor's breaking data are at L/R <= 1 ms; Hongfa states no L/R for the HPE501's 50 kA); the cable to the module is protected upstream.` — [port report:456]
>
> `967-1250 A within 0.26 s` … `contactor held, aR link below its 5 In breaking range; fastest pre-arc at 5 In with the curve 10 % left` — [port report:434]
>
> `The upstream battery protection (rack fuse, DC breaker or BMS-controlled rack contactor)` — [ARCH-COSTFIRST:269]

The same numbers are machine-readable in [port_spec:696-702] (`installation`: band 967–1250 A, 0.261 s, 50 kA, L/R 1 ms).
→ INST-11 … INST-13. R2-12 asks for the upstream device, the fault current, L/R and the clearing time: the device types
the files name are a rack fuse, a DC breaker or a BMS-controlled rack contactor; they do not give that device a DC
voltage rating (the contactor data the band is matched to are at 1000 V).

---

## ⚡ 2 DC port of the inverter

The inverter's battery port is the same lean port scaled to 250 A: one contactor (HFE82V-300C), a 400 A aR link per
pole (HIITIO HCHVF1000-400A-38R), the 220 Ω precharge (200 Ω on the four-wire board). The coordination of the fuse with
the contactor is calculated in the port report, section 14 (review PCM-15); both power-board checks print its result.

> `up to the hold-off band the contactor breaks (port OC window 387-413 A, 2.3 openings at 1033 A, 1000 V, L/R <= 1 ms); 967-2009 A nothing clears quickly (contactor held, fuse below its breaking range / slower than the contactor's 180 C curve); the 400 A links clear first only 2029-7414 A; above 7487 A prospective the contactor's short-circuit capacity (8 kA 6 ms, 10 kA 1.5 ms) is exceeded and the let-through peak reaches the bounce region (>= 6 kA from 6083 A, >= 8 kA from 19348 A; at 50 kA 10122 A by the cut-off chart, 12770-16861 A DC at the melting I2t).` — [PCS-PWR:15], [PCS-PWR-4W:16]

> `INSTALLATION REQUIREMENT: the battery-side protection must interrupt any current of 0.97-2.01 kA into the PCS DC port within 2.5 s (the contactor's 130 C curve at the band top; 25 s at 1 kA), and either limit the battery's prospective short-circuit current at the PCS DC terminals to <= 7.5 kA (L/R <= 1 ms) or interrupt currents above it within the contactor's short-circuit capacity (6 ms at 8 kA, 1.5 ms at 10 kA) - the PCS's own 400 A links protect the contactor only between 2.0-7.4 kA.` — [PCS-PWR:15], [PCS-PWR-4W:16]

> `The fuse data are averages from a chart with no tolerance band (+/-10 % in current assumed); its high-current tail (2.5-6 ms at 20-50 kA) is not consistent with the tabulated 43 kA2s melting I2t (adiabatic melting at 50 kA takes < 1 ms) - an RFQ / test item.` — [PCS-PWR:15], [PCS-PWR-4W:16]

| Fault current into the DC port | Cleared by | The installation must |
|---|---|---|
| up to the 967–1,033 A hold-off band | the contactor, on the 387–413 A window (about 2.3 openings at the band top) | nothing |
| 0.97–2.01 kA | nothing quickly | interrupt within 2.5 s (25 s at 1 kA) |
| 2.0–7.4 kA | the 400 A links | nothing; at 2 kA and above the contacts are likely bonded (weld check) |
| above 7.5 kA prospective | the contactor's capacity is exceeded (8 kA for 6 ms, 10 kA for 1.5 ms) | limit the prospective current to ≤ 7.5 kA at L/R ≤ 1 ms, or interrupt above it within that capacity |

<sub>Bands from [port report:463-468]; the 7.5 kA of the requirement is the 7,487 A "not coordinated above" figure of [port_spec:904] rounded.</sub>

→ INST-14, INST-15. The chart tail that does not match the tabulated I²t is open (see [Open](#open-what-the-files-do-not-close)).

**The battery's earth capacitance (three-wire builds, and four-wire mode B).** Below about 680 V DC at 400 V AC the
converter needs a zero-sequence offset, which puts a 150 Hz voltage on the battery's capacitance to earth:

> `so above about 680 V (400 V AC; about 780 V at 460 V AC) there is no 150 Hz common-mode voltage at all; below, the min-max zero sequence is needed` — [pcs_design report:435]
>
> `the battery may have up to 6 uF to earth for a 300 mA budget (24 uF for the 10 mA/kVA one) when it is operated below 680 V; above, no limit from this source.` — [pcs_design report:451]
>
> `(c) an installation limit on the battery's capacitance to earth for operation below 680 V (stated above)` … `The battery rack sits at +-V_dc/2 against earth in operation (as the architecture noted): its insulation and IMD must be rated for that.` — [pcs_design report:455]
>
> `in mode B the DC side carries the 150 Hz zero sequence to N / earth as the three-wire build does (step f installation limit on the battery's capacitance to earth)` — [PCS-PWR-4W:34]

[pcs_spec:7355-7356] give the unrounded limits: 5.79 µF at 300 mA, 24.1 µF at 10 mA per kVA. The report's
residual-current values (10 mA per kVA, 300 mA, steps of 30 / 60 / 150 mA) are IEC 62109-2 quoted FROM MEMORY.
→ INST-16, INST-17

**Low-frequency battery current and the voltage window.**

> `750 V, 216/0/0 A at 0 deg: I_N 216 A, HF 103 A + C_f / C_fN 20 A per half, 21.0 A per capacitor, battery LF 47 A rms` … `950 V, 216/0/0 A at 0 deg: I_N 216 A, HF 97 A + C_f / C_fN 28 A per half, 20.3 A per capacitor, battery LF 37 A rms` — [PCS-PWR-4W:38]
>
> `100 Hz battery current of single-phase load (~39 A rms at 750 V) is an installation item` — [pcs_spec:12808]

→ INST-18

> `V_dc >= 1.02 x sqrt(2) x V_LL,rms(measured) + 10 V and >= the map's V_dc for the commanded P / Q: 624 V at 400 V, 718 V at 460 V (no load)` — [pcs_spec:12859], [PCS-CTL:94]
>
> `rated current at PF 0, Q > 0 needs 643 V DC at 400 V, 737 V at 460 V` — [pcs_spec:12858]
>
> `230.9 V L-N (nominal): mode A 724 V to connect / 746 V for rated current (worst PF), mode B 624 / 643 V, bare 2 sqrt2 V_LN 653 V` — [PCS-PWR-4W:34]
>
> `meanwhile the body-diode rectifier drives 846 A peak / 730 A mean DC (460 V AC on 590 V, stiff grid, L1 saturation and R not modelled; 113 / 98 A at SCR 5) for <= 50 ms (AC contactor release, ASSUMED)` — [pcs_spec:12860]

→ INST-19. The 5 % loop headroom and the dead-time compensation behind these windows are ASSUMED (risk G1).

**DC/DC converters on the inverter's DC link** (reviews R2-04, R3-03 and R4 E04, [D-079](DECISIONS.md),
[D-080](DECISIONS.md), [D-081](DECISIONS.md)). The inverter's link is 0.41 mF of film and it has no brake chopper, so
system rules fall on whatever else is connected to the DC bus. Since D-080 the battery-less case is the coupled PCS / PV
trajectory — the PV modules' own protections read from their specs, simulated on the averaged model — instead of an
assumed 50 µs DC/DC stop; since D-081 the model carries the cable between the modules, and the set point is an
**enforced window**, not a figure the integrator chooses:

> `with the coordination row the island rides through at 750 / 782 V set points (bus <= 853 V against the 975 V soft limit, the PV current cut 0.20-0.28 ms after the rejection) and the PCS trips at 950 V (bus 994-1016 V, dark)` … `uncoordinated the comparator trips 1.50 / 1.94 ms after the step (band edges 978 / 1048 V) and the bus is left at 1060-1061 V, latched - below the aux's 1107 V input lock-out` — [pcs_spec:12773], [PCS-CTL:107]
>
> `enforced operating window (product rule in both modules' parameter sets, pcs_control_spec dc_bus_operating_window, review R4 E04): CV set point default 750 V (3W+PE 750 V, 3W+N+PE, mode A (N leg at 50 %) 755 V, 3W+N+PE, mode B (zero sequence on four legs) 750 V); clamped to <= 782 V in the PV module's parameter set` … `the PCS refuses to start an island (VF) on a bus declared battery-less above 791 V` — [pcs_spec:12773], [PCS-CTL:107]
>
> `the one-node model's 921 V (1 x 82.5 kW) / 909 V (2 x 75 kW) and the cable model's 846 V are model validities, NOT ratings (64 V between the clamp and the cable validity); cable model (2 / 10 / 20 m runs, 0.6 / 1 uH/m): every corner rides through, PCS-node peaks 849-887 V at 750 V, 878-914 V at 782 V` — [pcs_spec:12773], [PCS-CTL:107]
>
> `the PV modules' coordination row (V_B > V_B* + 30 V -> every cell's current reference to zero) is required for VF on a battery-less bus: without it every full-load rejection trips the PCS (bus 1063-1069 V); the CV set point in VF on a battery-less bus: default 750 V, firmware limit <= 782 V (the PV coordination row's own validity) - the enforced product rule (review R4 E04: pcs_control_spec dc_bus_operating_window); 909 V is this one-node model's validity only (no cable, the PV banks on the PCS node) - not a rating; the PV power on one link <= the PCS's DC power tier (one module at 82.5 kW and two at the 2-min tier studied)` — [pcs_spec:12773], [PCS-CTL:107]
>
> `a hardwired trip line (cost class low: an isolated digital line, a connector and a latch input, a few USD per module) is not needed inside the enforced window; in this one-node model it would be needed above 909 V and must stop the modules within 1 x 82.5 kW 116 us, 2 x 75 kW 56 us of the rejection at 950 V; not added; with the PV firmware dead the bus ends at 1126-1130 V, above the aux's 1107 V input lock-out: dark until it bleeds down` … `a CAN message is too slow; the PCS cannot absorb the energy (no brake chopper drawn)` — [pcs_spec:12773], [PCS-CTL:107]
>
> `x2 holds to V_B* = 782 V, above it a shared hardwired trip line or a battery` — [pv_control report:343]
>
> `parameter set: V_B* default 750 V in CV mode on a bus the installation declares battery-less (755 V when the PCS-P125 is the 3W+N+PE, mode A (N leg at 50 %) build), clamped to <= 782 V` … `a V_B* above the clamp is refused while the bus is declared battery-less, and the coordination row stays enabled; the PCS-P125 starts an island only at V_dc <= 791 V (its own refusal)` — [pv_control report:345]

The PV modules carry the cut as a firmware row (V<sub>B</sub> 30 V above its set point → every phase's current reference
to 0, 209 µs; [pv_control report:343]) and, since D-081, the window as a second system row (default, clamp and refusal;
[pv_control report:345]); the inverter carries its own island-start refusal. → INST-71

**The harness between the PV modules and the inverter** (review R4 E04, [D-081](DECISIONS.md)). The coupled model's
validity depends on the runs between the modules' port-B terminals and the inverter's DC terminals; the harness the study
assumed (2 / 10 / 20 m, 0.6 / 1.0 µH per metre, ASSUMED) becomes a contract for the integrator:

> `harness contract (installation): run length <= 20 m per PV module, its port-B terminals to the PCS's DC terminals; one run per module (a shared busbar section counts in each run)` … `loop inductance <= 1 uH per metre of run and <= 20 uH per run including fuses, disconnectors and busbar sections: DC+ and DC- routed together (a two-core cable, or the single cores bundled and touching in the same tray), never separated or looped through other sections; no series choke or ferrite on the link (its differential-mode inductance counts)` — [pcs_spec:12773], [PCS-CTL:107]
>
> `cross-section: copper, sized by the installation rules for the module's 135 A port current; loop resistance <= 12.6 mOhm per run (20 m of 70 mm2 at 90 C: 1.7 V at 135 A, the drop the set-point floors carry); heavier conductors allowed (the first peak hardly depends on the resistance: +1.8 V lossless at the worst run)` — [pcs_spec:12773], [PCS-CTL:107]
>
> `nothing else on the link: no capacitance, filter, DC source or load beyond the PCS's DC link and the PV modules' port-B banks as drawn (a battery or another source is a different study); at most two PV-P75 modules per PCS link, their power <= the PCS's DC power tier (section 7d)` … `the commissioning record carries the as-built runs (length, cross-section, routing), the battery-less declaration, the set point and both modules' serials` — [pcs_spec:12773], [PCS-CTL:107]
>
> `Harness ASSUMED ('dc_cable'): runs of 2, 10, 20 m, loop inductance 0.6 / 1 uH per metre of run (DC+ and DC- together), the resistance of 95 mm2 copper at 20 C (the least damping` … `capacitor ESR, busbars and the skin effect not credited` — [pcs_control report:592]

→ INST-76. The figures are a study's assumptions turned into limits; a run outside them (longer, more inductive,
separated conductors, a choke, a third module, a battery or another source on the link) is outside the study.

> `SCR 5 89.5 kW, SCR 10 119.5 kW, SCR 20 125 kW, stiff 125 kW: a DC/DC trip then stays below the 975 V soft limit (simulated, averaged; full power from SCR 20)` … `the row at or below the estimate / 1.3, no interpolation upward, no valid estimate = the weakest row (selection ASSUMED); published to the DC/DC over the module CAN / the EMS, which enforce it` — [pcs_spec:12771], [PCS-CTL:106]

→ INST-72

---

## ⚡ 3 AC port of the inverter

### 3.1 Both builds

The inverter has no AC fuse in its main power path (the 1.6 A fuses of the start-up tap protect only the tap). Two AC
contactors in series (K1, K2) disconnect it and are not short-circuit protective devices; the upstream device is the
protection.

> `converter running: the circular current limiter holds 367 A peak (259 A rms) for <= 200 ms, then trips` … `a shorted leg is fed from the battery through the two 400 A aR fuses (2.0-7.4 kA, port coordination) and from the grid through the body diodes of the healthy legs - that grid-fed current is limited only by L2 + L1 until L1 saturates, then by the installation.` — [PCS-PWR:29], [PCS-PWR-4W:41]

> `Grid-fed bolted leg short through L2 + L1 (L1 keeps its inductance to 578 A at 100 C): stiff 5834 A rms (16502 A peak), L1 saturated after 0.22 ms; SCR 50 3543 A rms (10021 A peak), L1 saturated after 0.37 ms; SCR 20 2229 A rms (6306 A peak), L1 saturated after 0.58 ms; SCR 5 781 A rms (2210 A peak), L1 saturated after 1.66 ms - the filter leaves the upstream protection well under 2 ms, then the installation's prospective current flows.` — [PCS-PWR:29], [PCS-PWR-4W:41]

> `The two AC contactors in series are disconnecting devices, not short-circuit protective devices: AC-1 >= 248 A (RFQ class), making / breaking about 1.5 x Ie at cos phi 0.95 (IEC 60947-4-1 AC-1, from memory), opened by firmware at zero current only; they must withstand the upstream device's let-through (conditional short-circuit current with that device: an RFQ item).` — [PCS-PWR:29], [PCS-PWR-4W:41]

> `INSTALLATION REQUIREMENT: upstream AC protection rated >= 250 A (the 216 A 2-min tier must not trip it), breaking capacity >= the prospective short-circuit current at the connection point, let-through within the module's AC-path withstand (contactor conditional current, busbars, L2 / L1 - RFQ / test item); gG fuses 250 A or an MCCB with an instantaneous release; residual-current protection upstream type B if the code requires an RCD (the module has its own RCM, IEC 62109-2 style); earthing TN-S or TT (three-wire build in TN: step f limit on the battery's earth capacitance); the DC side: the port declaration (battery-side protection 0.97-2.01 kA within 2.5 s, prospective current <= 7.5 kA at the DC terminals or interrupted within the contactor's capacity).` — [PCS-PWR:29], [PCS-PWR-4W:41]
>
> `upstream AC protection rated >= 250 A (the 216 A 2-min tier must not trip it), breaking capacity >= the prospective short-circuit current at the connection point` — [pcs_spec:12311]

→ INST-20 … INST-24

> `3 x TVT25751 (Uc 465 V AC >= 1.1 x 400 V for an earth fault in IT) + 3 x Y1 4.7 nF (500 V AC) to PE_T; type-B RCM sensor (RFQ) to PCS_X RCM / RCM_TST.` — [PCS-PWR:16], [PCS-PWR-4W:17]
>
> `residual current (type-B sensor): 30 / 60 / 150 mA step trips within 0.3 / 0.15 / 0.04 s and the continuous limit per code (from memory - verify), sensor self-test` — [pcs_spec:12854]

→ INST-23, INST-24

> `basic OVC III to PE (4 kV, 2.5 kV with the AC SPD credit; clearance 3.0 / 3.5 / 3.9 mm at 2000 / 3000 / 4000 m - ARCHITECTURE-PCS section 3)` — [PCS-PWR:24], [PCS-PWR-4W:28]
>
> `400 V +-15 %, 50/60 Hz, SCR 5..stiff` — [pcs_spec:12804]
>
> `"grid_SCR_range": "5 .. stiff"` — [pcs_spec:12791]

→ INST-25, INST-26

### 3.2 The four-wire build — the neutral

> `K1 + K2 4-pole (RFQ, the N pole switched with the phases, the same coil contract: 20 W pull-in / 4 W hold)` … `RCM type B around L1-L3 + N (RFQ, aperture 4 x 250 A); N terminal 250 A as the phases` … `L-N protection through two discs in series, 2 x 1240 V = 2480 V at 150 A (8/20 us) against the 4 kV OVC III rated impulse at 230 V` — [PCS-PWR-4W:19]

> `per phase at 230 V rated 41.6 kW, continuous 45.7 kW, 2_min 49.9 kW, 200_ms 59.9 kW; one phase at I, two at 0 (100 % unbalance): I_N = I` … `per-phase P / Q set points with the three currents in phase: I_N up to 3 I - the firmware limits I_N to the N leg's tiers; half the module power on one phase = 271 A, above every tier (the 100 % unbalanced load is one phase at its own tier)` — [PCS-PWR-4W:37]

> `neutral current IL4 <= the phase tiers (198 A rms continuous, 216 A 2 min, 259 A 200 ms)` — [pcs_spec:12867]

> `<= 280 A peak per phase (89 A DC, 140 A rms), L_N peak 311 A = the L1 part's continuous peak; battery LF 43 A rms at 750 V; output DC component <= 1.15 V (0.5 % Un) by the firmware regulator` — [PCS-PWR-4W:39]

→ INST-34 … INST-38. The files do not say where the neutral is bonded to earth (see [Open](#open-what-the-files-do-not-close)).

**A bolted output short in four-wire grid forming** (review R3-02, [D-080](DECISIONS.md); simulated on the averaged
per-phase model with both hardware trip layers replayed on their own signals). The module declares what it does; the
island's own short-circuit protection is planned around it:

> `a bolted output short in four-wire grid forming: ridden for the firmware's 200 ms at the 200 ms tier (the onset clamp keeps every studied corner off both hardware layers), then the firmware trip -> FAULT` — [pcs_spec:12314]
>
> `a unit whose layers sit outside the modelled bands trips in hardware instead: gates off within the protection chain (far below the ceiling), the latch holds, FAULT; no automatic clear after an over-current trip (the latch-clear row); a restart by command into a persisting short trips again; the third hazard trip of a class within 10 min -> LOCKOUT (ASSUMED, the firmware-practice row)` — [pcs_spec:12315]
>
> `"onset_clamp": "270 A per phase (and the N leg) for 5 ms after the phase-to-N voltage collapses, prediction on the divider-inverted C_f voltage, then the normal 378.0 A clamp",` … `"hold_A": 378.661,` — [pcs_spec:12316-12318]

→ INST-75. The 13.3 A between the hold's largest sensed peak and the lower trip edge rests on the averaged model; a
switched model and the bench are the gate ([pcs_design report:710]).

### 3.3 Firmware rows that put a condition on the installation

These are rows of the inverter's firmware hand-over (`handover.firmware_requirements` in `pcs_spec.json`, mirrored in the
PCS-CTL check). They are specifications for firmware that does not exist yet; the values are ASSUMED where the file says so.

**Grid stiffness and ride-through** (reviews R2-05 and R3-02, [D-079](DECISIONS.md), [D-080](DECISIONS.md)). Since the
re-check R2 the firmware keeps the onset of a deep dip under both hardware layers at rated power — in the averaged
model; since R3 the screen uses the lower edge of the two layers and a noise term:

> `with the per-sample clamp at 378.0 A (min(window low edge 426.0 A, CMPSS backup low edge 423.9 A) = 423.9 A - ripple/2 30.9 A - iclamp_margin_A 15.0 A = 378.0 A (sampled, ripple-midpoint current; the window-referenced value was 380.1 A)), set to 270 A while the state runs and predicting on the divider-inverted C_f voltage (the adopted onset measure, review R2-05): onset 382 A at a stiff 0 pu dip, 403 A at the worst corner / dip instant, screened against the lower edge of the two hardware layers (window 426.0 A, CMPSS backup 423.9 A): margin 23.0 / 20.9 A, net of the 2.53 A noise term 20.5 / 18.4 A (review R3-02); every onset, in-dip and recovery peak <= 389 A from stiff to SCR 5 at 0-0.5 pu residual voltage - rated current, no derating (SIMULATED, averaged model)` — [pcs_spec:12880], [PCS-CTL:115]

If a switched model or the bench shows less than that margin, the fallback applies, and with it a condition on the
connection:

> `FALLBACK if a switched model or the bench shows less margin: with the D-077 limiter rated current passes up to SCR 80.2 / 113.8 / 184.3 / 793.8 at 0 / 0.1 / 0.2 / 0.3 pu residual voltage` … `engages the derating at an estimated SCR >= 61.7: stiff 94.5 / 104.5 / 114 / 124 kW at 0 / 0.1 / 0.2 / 0.3 pu, the control study's table between` — [pcs_spec:12881], [PCS-CTL:116]
>
> `under the fallback the profile rides through at rated current where the connection's fault level per 125 kW module is below 7.71 MVA (SCR 61.7 with the estimate's tolerance; 10.02 MVA at the computed boundary SCR 80.2) - n modules at one point: the point's fault level / n; above it the derating table applies` — [pcs_spec:12769]
>
> `0 pu: 94.5 kW (76 %, onset 423 A); 0.1 pu: 104.5 kW (84 %, onset 424 A); 0.2 pu: 114.0 kW (91 %, onset 423 A); 0.3 pu: 124.0 kW (99 %, onset 423 A)` — [pcs_control report:291]

→ INST-27 (rewritten on 2026-10-07: the derating was the primary measure before [D-079](DECISIONS.md); its figures
re-tabled against the lower edge 423.9 A by [D-080](DECISIONS.md) — they were 8.07 MVA and 95.5 / 105.5 / 115 kW). The estimator's
accuracy (±30 %) is ASSUMED, and the reactive-current profile and every connection-code figure stay FROM MEMORY
([pcs_control report:347]).

**Off-grid loads.**

> `off-grid loads: crest factor <= 2.04 at rated rms below the 367 A limiter, DOL motors <= 36 A rated at a 6 x start` — [PCS-PWR:31], [PCS-PWR-4W:43]

[pcs_spec:12709-12724] adds the crest-factor curve (146.6 A rms at CF 2.5, 122.2 A rms at CF 3.0) and the motor tier (216 A
for 2 min, 259.2 A for 200 ms). Since [D-081](DECISIONS.md) (review R4 E06) the off-grid envelope is the module's
declared output capability, not a statement about the loads, and grid forming is released in stages:

> `release sequence: (1) grid-following operation qualified and released first -> (2) grid forming (VF) released for managed island loads with an agreed voltage-time and interruption specification, against which the declared capability is checked -> (3) general-purpose off-grid or UPS-like supply only after the required output class and its test method are established (IEC 62040-3 not claimed)` — [pcs_spec:12874], [PCS-CTL:109]

→ INST-28

**The module's grade** (reviews R2-07 and R3-04, [D-078](DECISIONS.md), [D-080](DECISIONS.md)). The overload and
continuous tiers depend on the module's SiC grade — grade A if every device passed an absolute on-resistance limit,
grade B otherwise, each with its own tier table by inlet temperature, DC voltage, power factor and start state. The grade
is bound to the module serial, and the integrator records it:

> `R_DS(on) <= 40.0 mOhm for each device at V_GS 18 V, I_D 38 A pulsed (< 200 us), T_J 25 C` … `a module with any of them is grade B and runs grade B's tier table (pcs_spec desat rds_acceptance grade_tier_tables, by inlet, V_dc, PF and start state; at 45 C inlet continuous 196.8 A, 2 min = 200 ms 207.5 A; at 60 C 179.8 / 192.6 A, 110 % not held), a parameter set bound to the module serial` — [pcs_spec:12817]
>
> `the end-of-line test writes the grade's tier table into the controller's parameter set (CRC with the calibration set) from the lot's incoming R_DS(on) record, the controller reports the grade with the module serial, and the integrator records the grade with the module serial; a module without a grade record runs grade B; replacing a device re-grades the module from the replacement's record` — [pcs_spec:12818]
>
> `grade A (every device <= 40.0 mOhm): 198 / 216 / 259.2 A at <= 45 C, at 60 C 198.0 / 216.0 / 242.9 A (continuous / 2 min / 200 ms from steady)` — [PCS-CTL:99]
>
> `a 200 ms excursion is admitted only from the continuous state or cold; once the current has been above the continuous tier for more than 0.22 s (the 200 ms excursion + 20 ms) the 200 ms limit equals the 2 min tier until the current has been at or below the continuous tier for 12 min - both grades` — [PCS-CTL:100], [pcs_spec:12865]

→ INST-73; the load and motor-start sizing of INST-28 uses the tiers of the module's grade.

**Generator following, island transfer, parallel operation.**

> `frequency window 45-55 Hz (60 Hz: 55-65 Hz), ROCOF ride-through <= 4 Hz/s, voltage 0.85-1.10 Un; no reverse power: the genset keeps >= 30 % of its rating (wet-stacking floor), so discharge <= P_load - 0.3 P_gen and charge <= 0.9 P_gen - P_load; power ramps <= 10 % of P_gen per s; P(f) droop following the genset's 4 %; competitor claim, no published parameters; our values ASSUMED (standards not on file)` — [PCS-CTL:113], [pcs_spec:12878]

> `automatic, with an interruption of about 150 ms = detection 100 ms (ASSUMED) + the grid-tie contactor's drop-out 50 ms (CHINT NXC-225 class with its DC coil module, ASSUMED - the RFQ class of our AC contactors)` … `a seamless unplanned transfer needs a static transfer switch: out of scope (REQUIREMENTS: not STS)` — [PCS-CTL:119], [pcs_spec:12884]

> `GFL: independent current sources, the EMS splits P / Q (shared set point); GFM: P-f / Q-V droop; the module bus = the control board's CAN (paralleling, carrier synchronisation by CAN time-stamping, software addressing) and zero-sequence circulating-current control on a shared battery; no hardware sync pair fitted` … `load sharing +/-5 % of rated by droop, +/-2 % with the shared CAN set point; carrier jitter +/-2 us (ASSUMED); up to 16 modules on one CAN (ASSUMED bus load)` — [PCS-CTL:120], [pcs_spec:12885]

→ INST-29 … INST-31

**AC start (grid start with the DC side dead).** Since [D-079](DECISIONS.md) (review R2-14) the sequence is the control
study's executed, fault-injected state machine with five repairs (H1–H5); four of its rules put a condition on the
installation — the grid's state at each contactor command, the battery's voltage before the DC connection, and the
retry limit that survives a reset:

> `grid present, DC side dead (battery absent, empty or its own contactors open): the 6-diode tap feeds the 75 W aux through its OR diode` — [PCS-PWR:26], [PCS-PWR-4W:30]
>
> `rectified 416-651 V at 340-460 V AC, the 75 W block's full rating from 250 V (aux75_spec ratings 'design': from_V 250), the brown-in below it` — [PCS-PWR:24], [PCS-PWR-4W:28]
>
> `<= 3 attempts per start >= 30 s apart, counted across controller resets (H5: count, spacing and lock-out in the recorder flash), then lock-out until a service reset` — [PCS-PWR:27], [PCS-PWR-4W:31]
>
> `then the relay test onto the precharged link (H1): K2 alone, then K1 alone, the converter passive` … `each commanded only with V_dc >= 0.95 x sqrt2 x V_LL,meas, the grid inside +/-10 % at the command (H3) and the DC contactor open - checked at each coil command, not once before the sequence` — [pcs_spec:11428-11429]
>
> `DC port (H4): K_B only with VBX >= 1.05 x sqrt2 x V_LL,meas (the rectification threshold)` … `below the threshold no DC connection, standby on the grid and a report` — [pcs_spec:11431]

→ INST-32, INST-74, and the two consequences in sections 4 and 7 (INST-43, INST-68). What the executed machine leaves
open is listed under [Open](#open-what-the-files-do-not-close).

**Grid-tie close with the DC side live** (review R3-01, [D-080](DECISIONS.md)). The synchronised close from the battery
side now pulls in one AC contactor at a time and checks the grid window at each coil command, as the grid start does:

> `"path": "SYNC -> SYNC_CLOSE_K2 -> SYNC_CLOSE_K1 -> GFL (grid start) / GFM (dead-bus start)",` — [pcs_spec:11923]
>
> `VG inside +/-10 %, |dV| <= 5 %, |dtheta| <= 5 deg, |df| <= 0.1 Hz (ASSUMED), V_dc above the DC closing permissive - at the K2 and the K1 command and every tick of the settle wait until the path forms` — [pcs_spec:12026]

→ INST-74.

**Grid code (set at commissioning).**

> `grid protection EN 50549-1 / GB/T 34120: U/f windows and times, ROCOF / vector shift, active anti-islanding where IEC 62116 applies, LVRT / HVRT with reactive current, P(f), Q(U), cos phi(P) (settings by country)` — [pcs_spec:12853]
>
> `LVRT: 0 pu for 150 ms, 0.2 pu to 625 ms, linear to 0.9 pu at 2 s, reactive current k = 1.5 (dI_q / dU) up to 1.0 Ir; HVRT: 1.2 pu 10 s, 1.25 pu 1 s, 1.3 pu 0.5 s (absorbing reactive current) - FROM MEMORY` — [pcs_spec:12879], [PCS-CTL:114]
>
> `cease to energise within 2 s (IEC 62116 class, FROM MEMORY; not simulated)` — [pcs_spec:12882], [PCS-CTL:117]

→ INST-33

---

## 🛡️ 4 Earthing and insulation monitoring

**PV modules.** Array and battery are one galvanically connected circuit through the shared negative rail:

> `PV array, battery and DC bus are floating with insulation monitoring or one pole earthed, a first earth fault may persist` — [DECISIONS:38]
>
> `IT (floating) with insulation monitoring (PV-C5), OR one pole earthed by the installation; a FIRST EARTH FAULT may persist (the IMD only alarms)` — [insulation report:39]
>
> `ports A and B share BUS- (non-isolated), so they are ONE circuit` — [insulation report:40]

> `the module disables its own by keeping IMD_SW_P/N de-energised (strings open, fail-safe); it still loads each pole with the 6.005 M dividers, which the active monitor must count (system spec)` — [port report:367]
>
> `One active insulation monitor per galvanically connected system` — [guide 04:194]
>
> `PV-P75/100/110 has no residual-current sensor (DC/DC: insulation monitoring only)` — [PV-CTL:50]

→ INST-39, INST-40

> `Y1 4.7 nF to PE_T: 1144 V pole-PE vs 1500 VDC (VY1 p1) = 76 %; MOV3 / Y / IMD strings return through the removable PE_T link` — [PV-PWR:9]
>
> `(6) the PE return for the Y capacitors, MOV3 and the IMD strings (removable strap` — [ARCH-COSTFIRST:134]

→ INST-41

> `the capacitance to PE puts about 11 mA into the protective conductor, so the product needs the high-touch-current measures (PE conductor ≥ 10 mm² Cu and a warning label)` — [DECISIONS:54]
>
> `A PE stud with ≥ 16 mm² Cu (line conductors 35-50 mm²; the stud carries the installation's PE sized to the line` … `conductors - the module's own PE bond is ≥ 10 mm² Cu per D-048, INSTALLATION.md INST-42)` — [ARCH-COSTFIRST:128-129]

→ INST-42. The two records used to give different conductor sizes; since 2026-10-07 the architecture file reconciles
them — the 16 mm² stud carries the installation's PE sized to the line conductors, the module's own PE bond is ≥ 10 mm²
Cu (see below).

**Inverter.** The grid tap ties the DC side to the grid whenever the AC terminals are live:

> `with a battery connected and the grid present, DC- is peak-clamped to the most negative phase; the insulation monitor's PE -> DC- state is then not valid (R_iso- is covered by the residual-current monitor once connected): firmware runs the full two-state insulation test with the grid absent or treats the DC- result as 'clamped by the grid'` — [PCS-PWR:28], [PCS-PWR-4W:32]
>
> `LIVE: the tap ties DC- to the grid phases through its lower diodes (the converter does the same through its body diodes once the AC contactors close)` — [PCS-PWR:24], [PCS-PWR-4W:28]

→ INST-43

---

## 📐 5 Environment

> `−30…+60 °C, full power to 45 °C, derate above` — [REQUIREMENTS:64]
>
> `Cold rating amended by delegation (D-081, review R4 / E11): full operation from -10 C inlet; below -10 C the fans stay off and the module holds only the passive-cooling table of the design check` — [REQUIREMENTS:169]
>
> `| sea level | 82.5 | 82.5 | 82.5 | 82.5 | 82.5 | 78.7 | 71.5 | 62.2 |` — [module report:76]
>
> `at 60 C inlet the firmware's overload tiers are the grade-A tier table's 120 % 2 min 216.0 A, 200 ms 242.9 A (the lowest over 600-950 V; this population holds them at its 900 V corner)` — [PCS-PWR:5], [PCS-PWR-4W:5]

The PV-P75 row is its power held in kW at an inlet of 25, 30 … 60 °C (sea level, [module report:74-76]). PV-P100/110 holds
88.6 kW to 55 °C and 79.3 kW at 60 °C with the battery-port current cap (`| sea level | 88.6 | 88.6 | 88.6 | 88.6 | 88.6 | 88.6 | 88.6 | 79.3 |`,
[module report:90]); without the cap ("thermal only") it holds 110 kW to 35 °C and 100.9 kW at 45 °C ([module report:94]). → INST-44

> `environment: operating -10..+60 C at power (> 45 C derating by module grade - tiers_by_grade, at 60 C grade A 198.0 / 216.0 / 242.9 A; grade B 179.8 / 192.6 / 192.6 A (grade B: the 60 C continuous limit 179.8 A = 124.57 kW at PF 1 and 400 V AC - the rated 125 kW at 400 V needs 180.42 A (the rated 180 A is 124.71 kW))); -30..-10 C inlet: fans off (rated -10 C), standby or the passive table only - the milder rating, decided by cost; a cold-rated fan RFQ is the path back to -30 C at power` … `storage -40..+70 C (ASSUMED: parts' storage ratings to confirm), altitude: see the control board's barrier rating, OVC DC II / AC III, pollution degree external 3 / internal 2; IP rating and enclosure out of scope (schematic and BOM only)` — [PCS-PWR:31], [PCS-PWR-4W:43]
>
> `both Delta fans are rated -10..60 C operating (p.3 4-1; storage -40..+75 C)` — [module report:40]

→ INST-45, INST-47

**Altitude.** The ceiling is set by the control board's barrier, not by the thermal model:

> `DECLARED 2000 m - BARRIER: 2000 m (B1 isolators 8.0 mm minimum clearance). THERMAL MODEL (module_spec, 45 C inlet, PV only; the inverter has no altitude model): PV-P75 100.0 / 93.8 / 86.3 / 79.2 / 70.4 % at 0 / 1000 / 2000 / 3000 / 4000 m; PV-P100/110 80.6 / 80.6 / 77.3 / 68.4 / 60.5 % at 0 / 1000 / 2000 / 3000 / 4000 m` — [PV-CTL:26], [PCS-CTL:25]
>
> `clearance 8.0 / 9.2 / 10.4 / 11.9 mm needed at 2000 / 3000 / 4000 / 5000 m` — [PV-CTL:24], [PCS-CTL:23]
>
> `The 15 mm (WW) parts exist and reach 5000 m` … `above the ~1 USD rule -> NOT fitted, the boards stay rated 2000 m` … `a port SPD with Up,eff <= 4.0 kV and its own altitude rating (module decision, power board): the 8 mm parts then reach 4000 m` — [PV-CTL:26], [PCS-CTL:25]
>
> `(4) module level, not this board: power board B2 6.3 / 7.1 mm at 3000 / 4000 m, the port SPDs' own altitude ratings (Raycap 59.D040: 3000 m max; DEHN 952515 not stated), contactors, fuses and fans not assessed` — [PV-CTL:27], [PCS-CTL:26]

→ INST-46

**Pollution degree, overvoltage category, standards.**

> `pollution degree 3 external / 2 internal, DC OVC II` — [REQUIREMENTS:113]
>
> `EN 62477-1, EN 62109-1/-2, EN IEC 61000-6-2, EN IEC 61000-6-4` — [REQUIREMENTS:114]
>
> `pollution degree 2 inside a closed electronics compartment with all HV boards coated, pollution degree 3 in the cooling-air path (only terminals, fuse bases and arresters there)` — [DECISIONS:38]

→ INST-26, INST-47, INST-50. Humidity, IP rating and noise appear only as the owner's undecided candidate PV-C6 (`> 3000 m derating; ≤ 95 % RH non-condensing; IP20; ≤ 65 dB @ 1 m`, [REQUIREMENTS:79], decision D-009 open); the inverter's declaration puts IP rating and enclosure out of scope.

**Inlet air and airflow.** The module's own fans deliver the airflow; the thermal model keeps a 3 % tolerance on it:

> `R_sa <= 0.060 K/W incl. air rise at ~402 m3/h` … `the airflow reduction is 1.7 % against the 3 % allowed` … `sink 77.4 C at 45 C inlet` — [PV-PWR:4]
>
> `R_sa <= 0.049 K/W incl. air rise at ~456 m3/h` … `airflow x1.000 = 456 m3/h` … `sink 80.0 C at 45 C inlet` — [PV-PWR-4:4]
>
> `airflow 264 CFM (2.11 CFM/kW) against the competitor's 3.8 CFM/kW` — [PCS-PWR:31]
>
> `airflow 352 CFM (2.82 CFM/kW) against the competitor's 3.8 CFM/kW` — [PCS-PWR-4W:43]
>
> `3 x R_sa 0.050 K/W at 149 m3/h` — [PCS-PWR:22]
>
> `4 x R_sa 0.050 K/W at 149 m3/h` — [PCS-PWR-4W:26]

→ INST-48. The files give no allowance for back-pressure, filters or recirculation in the cabinet (see [Open](#open-what-the-files-do-not-close)).

**Cold start.**

> `inlet NTC < fan rating (-10 C) at start-up: fans OFF, module power <= the table row of the inlet reading (table kW, nominal), no other change to the control` … `passive power PV-P75 19.2 / 17.5 / 15.5 kW at -30 / -20 / -10 C inlet; PV-P100/110 19.9 / 14.9 / 4.9 kW at -30 / -20 / -10 C inlet (ESTIMATE +-50 %, module_spec.json); start regardless of the inlet: heatsink NTC 80 C, inductor NTC 135 C` — [PV-CTL:89]

→ INST-49 (the PV modules).

The inverter has the same rule since [D-081](DECISIONS.md) (review R4 E11), on its own passive table — too small to be
useful, which is why its cold rating is full operation from −10 °C inlet:

> `COLD START, fans off (review R4 / E11; pcs_spec thermal_and_losses cold_start; ESTIMATES +/-50 %): kVA at 400 V AC this build holds without its fans, by inlet -30 / -20 / -10 C: 600 V DC 20 / 15 / 8, 650 V DC 14 / 8 / 0, 700 V DC 3 / 0 / 0, 750 V DC 0 / 0 / 0` — [PCS-PWR:23]
>
> `600 V DC 14 / 7 / 0, 650 V DC 5 / 0 / 0, 700 V DC 0 / 0 / 0` — [PCS-PWR-4W:27]
>
> `fans OFF while the inlet NTC reads below -10 C (the AFB1224SHE-F00 rating, -10..60 C); below it the current reference is limited to this table at the measured inlet and V_dc (the warmer inlet row and the higher V_dc point between table points); where the table is 0 the module stays in standby, gates off (aux and contactor coils only)` … `fans ON at an inlet of -10 C or above, or whatever the inlet reads once any heatsink NTC exceeds 80 C` — [PCS-PWR:23], [PCS-CTL:101]
>
> `inlet NTC open / short -> fans ON (protects the module; the fan may then run below its rating)` — [PCS-CTL:101]

→ INST-77 (risk F14, [guide 12:366]).

---

## 🎛️ 6 Communications and control wiring

**Ports and roles** (declared in firmware / configuration; the hardware is one CAN, one RS-485, one stop input, one
status relay and, on the inverter only, one Ethernet port):

> `module bus (paralleling, carrier synchronisation by CAN time-stamping, software addressing) = the one CAN; BMS = RS-485 (Modbus RTU) or, when the module is not paralleled, CAN; EMS = Ethernet (Modbus TCP, port 502, not fitted on PV-CTL) or RS-485; HMI / local PC tool = Modbus TCP over the Ethernet bridge or the RS-485 at 9600-8-N-1 (the HMI panel and its 12 V supply are a cabinet accessory, not added; no web server: the bridge is transparent)` — [PV-CTL:49]
>
> `EMS = Ethernet (Modbus TCP, port 502, fitted) or RS-485` — [PCS-CTL:49]
>
> `One Ethernet port, not the PMA's two: a daisy chain is the cabinet's switch.` — [PV-CTL:49], [PCS-CTL:49]
>
> `Where it fails: a CAN-only BMS whose bit rate or identifiers cannot share the module bus while the modules run in parallel -> BMS on RS-485 needed (the EMS then on Ethernet); on PV-CTL (Ethernet not fitted) fit the Ethernet option first` — [PV-CTL:49], [PCS-CTL:49]

→ INST-51 … INST-54, INST-56

**Termination, addresses, loss of communication.**

> `CAN: split 2 x 60.4 R + 4.7 nF switched in by a solder jumper (1); RS-485: 120 R by a solder jumper (1); open = not terminated (the two bus ends close theirs; fail-safe receiver). Selectable today, no DIP added. Module address: by software over the module CAN (firmware row), no address DIP` — [PV-CTL:48], [PCS-CTL:48]
>
> `ramp to zero and stop on communication loss (ASSUMED 1 s on CAN)` — [PCS-CTL:88]
>
> `ramp to zero and stop on communication loss (grid-following: fallback to zero power; grid-forming keeps forming)` — [pcs_spec:12849]

→ INST-53, INST-55

**Stop chain, ready permissive, battery-fault input, status relay.**

> `ON >= 8.8 V (a 24 V PLC output: ON >= 15 V), OFF <= 3.4 V; the dry contact fed from S_24V >= 12 V gives 9.7 V; open contact, cut wire or lost SELV -> STOP_OK low within 1.47 ms (RC from the 5.1 V clamp to 0.8 V) + 12 ns isolator, no firmware` — [PV-CTL:13], [PCS-CTL:10]
>
> `Rev A2: J_STOP 2 / 3 stop line in / out and 4 / 5 0 V in / out (loop-through) to chain a cabinet 24 V stop line (each module 0.84 mA at 36 V); the S_EN_SRC dry-contact supply serves 1 module (ON >= 8.8 V at S_24V >= 12 V); READY permissive (PMA rocker p.13) = J_IO 6-7 in series (wire link if unused): open = stop in hardware - the firmware sees one STOP_OK for both.` — [PV-CTL:47], [PCS-CTL:47]
>
> `DI1 battery fault / BMS contact (PMA BAT_FAULT): J_IO 4 = 5 V wetting via 1.0k, 5 = input, 10k down, 10k + 100 nF (1.1 ms), 5.1 V clamp -> CA-IS3842HW -> GPIO52 (XINT3): closed contact 4.43 V >= 2.2 V (VIT+ 2.0 V + 10 %); NO / NC meaning set in firmware.` — [PV-CTL:47], [PCS-CTL:47]
>
> `energised = healthy, NC on any trip, stop or supply loss` … `SELV contacts only (<= 30 V AC / 60 V DC, 2 A 30 V DC)` — [PV-CTL:47], [PCS-CTL:47]

→ INST-57 … INST-60

**What may be connected, and how far from live copper.**

> `Field I/O (isolated CAN/RS-485, digital inputs, BMS gateway, Ethernet): DVC A on both sides of their isolators; the BMS communication port is assumed SELV/PELV per the battery system's own standard.` — [insulation report:44]
>
> `The BMS / PCS side may earth its 0 V; the SELV 0 V is tied to PE through 1 MΩ ‖ 4.7 nF Y2` — [ARCH-COSTFIRST:113]
>
> `(3) layout: every SELV connector (fans, stop / IO, CAN, RS-485, Ethernet) and the SELV harness >= 9.2 mm clearance from LIVE copper and >= 10.0 mm creepage (PD2) - the architecture's 10 mm keep-out holds to 3000 m, 4000 m needs 10.4 mm` — [PV-CTL:27], [PCS-CTL:26]
>
> `SELV connectors at the front, ≥ 10 mm from any live part` — [ARCH-COSTFIRST:133]

→ INST-61, INST-62

**No rated safety function; no cabinet 24 V.**

> `a cabinet that needs a rated stop must open its own DC switching devices; service needs isolated tools` — [guide 12:283]
>
> `the module is dark when both ports are below ~200 V` — [ARCH-COSTFIRST:499]
>
> `a port rises above 206–215 V` — [guide 04:356]

→ INST-63, INST-64

---

## 🧰 7 Service

**Discharge time and labels.** The passive bleeders take the banks to 60 V once the sources are disconnected (the inverter's figure is stated with the DC contactor and both AC contactor sets open):

> `port A 289.8 uF incl. decoupling: 1100 -> 60 V in 8.2 min (bleeder alone 8.2 min, with the 6 M divider 7.5); worst case (R +1 %, C +10 %, divider, from 1144 V) 8.4 min; port B 334.8 uF incl. decoupling: 1100 -> 60 V in 9.5 min (bleeder alone 9.5 min, with the 6 M divider 8.7); worst case (R +1 %, C +10 %, divider, from 1144 V) 9.7 min` … `label 'wait 10 min'` — [PV-PWR:14]
>
> `worst case (R +1 %, C +10 %, divider, from 1144 V) 11.2 min` … `label 'wait 15 min'` — [PV-PWR-4:14]
>
> `(3) the label "Hazardous voltage — wait 10 min (PV-P100/110: 15 min) after` — [ARCH-COSTFIRST:131]

→ INST-65, INST-66

> `with the DC contactor and both AC contactor sets open, bank, films, C_f + C_d (60 uF per phase, star on M) and the aux input bulk (6.6 uF) fall below 60 V between any two conductors after 14.7 min worst case (13.3 nominal; R +1 %, C +10 %, the five 6 M dividers VB / VA / VC1-3 credited, from 1050 V with C_f at the 460 V AC peak) <= label 'wait 15 min'` — [PCS-PWR:3]
>
> `fall below 60 V between any two conductors after 14.8 min worst case` — [PCS-PWR-4W:3]
>
> `the aux input and, with a welded precharge relay, the DC link are live whenever the AC terminals are live: enclosure label 'isolate AC and DC, wait 15 min'` — [PCS-PWR:28], [PCS-PWR-4W:32]

→ INST-67, INST-68

**Contactors and tools.**

> `above 300 A flags the contactor for replacement.` — [guide 04:175]
>
> `terminal voltage does not follow; a weld blocks restart.` — [guide 04:177]
>
> `"HAZARDOUS VOLTAGE — isolated debug probe only (≥ 1000 V DC rated, e.g. an isolated XDS)"` — [ARCH-COSTFIRST:120]

→ INST-69, INST-70

---

## ⚠️ Standing restrictions (review R4)

The economical re-check R4 ([review_r4.csv](../../gen/data/review_r4.csv), [D-081](DECISIONS.md)) accepted several
limitations instead of adding hardware, each with a boundary that may not be waived. These are the installation-facing
ones — what a site must not do, and which row of this list carries it. They are accepted limitations, not ignored
hazards; the full set, with what would lift each, is on
[12 · Risks](../guide/12-risks-and-open-items.md#standing-restrictions).

| Restriction (R4 area) | What the installation must not do | Boundary that stays | Rows |
|---|---|---|---|
| PV-P75 at 550 V (E07) | size a site for 75 kW delivered at a 550 V battery or bus: the 135 A port carries 75 kW from 556 V, 74.25 kW at 550 V × 135 A (the delivered rating from 562 V at equal port voltages) | no 75 kW claim at that corner; the arithmetic is not waived | — (REQUIREMENTS PV-04 / PV-05; risk G2) |
| PV-P100/110 battery port, 145 A | expect 100 kW below 690 V (A→B) / 697 V (B→A), or full power above 35 °C inlet; PV-P110's 110 kW is a PV-input rating | the ideal minima (689.66 / 758.62 V) are not ratings: the delivered direction and the losses stay in | INST-44 |
| Battery-less DC bus (E04) | run the bus above the 782 V clamp, put a battery, filter or another source on the link, or wire outside the harness contract | the one-node 909 V is a model validity, not a rating; above 782 V the coordination margin is not held | INST-71, INST-76 |
| Grid forming (E06) | treat the declared envelope as compatibility with any 400 / 230 V island load: grid forming is released for managed island loads with an agreed voltage-time and interruption specification | not a universal ITIC or UPS claim; IEC 62040-3 not claimed | INST-28, INST-75 |
| Cold ambient (E11) | run the inverter at power below −10 °C inlet, or the PV modules below −10 °C other than on their passive table | a storage rating is not fan qualification; an untested passive table is not a full-power guarantee | INST-44, INST-49, INST-77 |
| Upstream DC fault protection (E10) | leave the 0.97–1.25 kA band (PV battery port), the 0.97–2.01 kA band or a prospective current above 7.5 kA (inverter DC terminals) without an upstream device that clears it | no waiver of the uncovered bands: the actual device, its clearing time, the prospective current and L/R are bound per installation | INST-11 … INST-15 |
| Grade B (E05) | size a grade-B inverter for 125 kW at 60 °C inlet: it is a 124.57 kW module there (PF 1, 400 V) | grade B only inside its published map; short-circuit survival is still a release gate | INST-73 |
| Three-wire against four-wire (E12) | use the three-wire build for line-to-neutral or unbalanced loads; on a TN grid run it below 680 V DC with more than the stated battery capacitance to earth | no four-wire or unbalanced-load claim on the three-wire hardware | INST-16, INST-34 … INST-38 |

<sub>Not installation-facing, and so not rows here: the PV comparator's 1.09 nuisance margin (E08, an availability
restriction of the module) and the deferred DAB-D60 (E09, no product to install).</sub>

## ⚠️ Where the records disagree

Each row gives the number this page uses and the other record. None is resolved here; the records are the owner's to
reconcile. Rows marked *reconciled* were settled by the notes ARCHITECTURE-COSTFIRST.md and ARCHITECTURE-PCS.md received
on 2026-10-07; they stay listed so that the trace is kept. The generated line is used where one exists, as the [documentation index](../README.md) says a record wins
over a page.

| What | This page uses | The other record | Note |
|---|---|---|---|
| **Battery-port fault band of the PV modules** (INST-11, INST-12) — band and time reconciled on 2026-10-07, L/R not | 0.97–1.25 kA (967–1,250 A) within 0.26 s; ≤ 50 kA at L/R ≤ 1 ms — [port report:456], [port_spec:696-702], [guide 04:183] | 0.95–1.3 kA within 0.25 s; ≤ 50 kA at L/R ≤ 3 ms — [ARCH-COSTFIRST:265], [ARCH-COSTFIRST:269-274], [ARCH-COSTFIRST:584]; repeated as risk B6, 0.95–1.3 kA — [guide 12:284] | The architecture now names the drawn values beside its own and says the stricter of each pair (0.95–1.3 kA, 0.25 s) satisfies both, and that this page carries the drawn values ([ARCH-COSTFIRST:269-274]). Still different: its 50 kA at **L/R ≤ 3 ms** against the drawn ≤ 1 ms — the 1.0 kA rule rests on contactor data at L/R ≤ 1 ms, "not at the architecture's 3 ms" ([port report:457]); INST-12 keeps 1 ms |
| **PE conductor and leakage current** (INST-42) — conductor sizes reconciled on 2026-10-07, touch current not | PE conductor ≥ 10 mm² Cu and a high-touch-current label, about 11 mA — [DECISIONS:54], [guide 03:460], [guide 12:282] | PE stud ≥ 16 mm² Cu, which "carries the installation's PE sized to the line conductors", and "the module's own PE bond is ≥ 10 mm² Cu per D-048" — [ARCH-COSTFIRST:128-129]; "touch current with PE open ≤ 3.5 mA", estimate 0.5–16 mA rms — [ARCH-COSTFIRST:380-383]; 1.06 mA at 150 Hz and 14.2 mA at 20 kHz — [port report:398] | the two sizes now describe two conductors: the installation's PE at the stud (sized to the 35–50 mm² line conductors, ≥ 16 mm²) and the module's own bond (≥ 10 mm²); INST-42 states both. Still different: D-048 accepted about 11 mA, above the architecture's 3.5 mA touch-current figure |
| **Three-wire build on a TN grid** (INST-16) — reconciled on 2026-10-07 | allowed with a battery capacitance to earth ≤ 5.8 µF below 680 V; four-wire or an isolation transformer where it is exceeded — [pcs_design report:455] | "the installer must connect 3W+PE through a transformer or keep N unloaded", now marked "superseded by the drawn rule: the three-wire build limits the battery's earth capacitance to about 6 µF on a TN grid" — [ARCH-PCS:110-112] | the architecture text was for the three-level stage with 150 V of zero sequence; the two-level study (D-053) recomputed it ([pcs_design report:451]) and the architecture now defers to it; no difference left |
| **100 Hz battery current of a single-phase load** (INST-18) — reconciled on 2026-10-07 | up to 47 A rms at 750 V (216 A tier), 37 A at 950 V — [PCS-PWR-4W:38] | about 39 A rms at 750 V — [pcs_spec:12808]; about 45 A rms for about 42 kW, now annotated "the drawn figures are about 39 A at the operating-map point and 47 A rms worst in the four-wire design check - different load points" — [ARCH-PCS:118-120] | different load points, now stated in the architecture too: the 39 A matches one phase at the rated 180 A (230 V × 180 A ÷ (√2 × 750 V)), the 47 A one phase at 216 A, the 45 A the earlier T-type stage; INST-18 states the largest of the current design |
| **Discharge time to 60 V** (INST-65, INST-66) | PV-P75 9.7 min, PV-P100/110 11.2 min worst case — [PV-PWR:14], [PV-PWR-4:14] | 9.2 min and 10.5 min — [port report:443], [port report:444] | the check counts the leg decoupling ("incl. decoupling"); both fit the labels (10 / 15 min); the PV-P75's 0.3 min is the thinnest margin on any label |
| **Inlet temperature for full power** (INST-44) | full power to 45 °C, derating above (PV-P75 62.2 kW = 75 % at 60 °C) — [REQUIREMENTS:64], [module report:76], [DECISIONS:62] | "60 C inlet (module_spec: full power to 60 C)" — [port report:24], [port report:60] | the port report's 60 °C is a conservative fuse-temperature basis worded as a rating; INST-44 is unaffected |
| **Altitude derating of the PV modules** (INST-46) | derating from 1,000 m (PV-P75 93.8 / 86.3 / 79.2 / 70.4 % at 1,000–4,000 m) — [PV-CTL:26] | "No derating from 25 to 60 °C, to 4000 m" — [DECISIONS:29]; "the thermal design claims no derating to 4000 m (D-029)" — [insulation report:47]; PV-C6 "> 3000 m derating" — [REQUIREMENTS:79] | D-029 is the earlier fan and platform, replaced by the cost-first module of D-056 and D-075; PV-C6 is a candidate the owner has not adopted (D-009) |
| **Are the AC surge arresters monitored?** (INST-24, INST-26) | not monitored; a failure goes unseen, the alarm is still RFQ — [guide 12:362], [guide 12:458], [guide 09:835] | "monitored" — [pcs_design report:433] | the generated inverter checks do not say; treat as not monitored until the records agree |
| **Wording of the inverter's two-source label** (INST-68) | 'isolate AC and DC, wait 15 min' — [PCS-PWR:28] | "two sources — isolate AC and DC; wait 15 min" — [guide 09:493], [guide 12:289] | same meaning; the generated line is used |
| **Uncoordinated DC/DC on a battery-less bus** (INST-71) — reconciled (found on the R4 re-verification of 2026-10-07) | gates off 1.50 / 1.94 ms after the step, bus left at 1,060–1,061 V (the coupled PCS / PV trajectory of [D-080](DECISIONS.md)) — [pcs_spec:12773], [PCS-CTL:107], [pcs_control report:528] | the PV module's coordination row now prints the same figures ("1.50-1.94 ms after the rejection and the bus is left at 1060-1061 V, latched") — [pv_control report:343]; it printed D-079's 0.59–0.75 ms and 1,048–1,110 V when this row was written | no difference left; the row's own rule (209 µs, × 2 to 782 V) did not change |

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

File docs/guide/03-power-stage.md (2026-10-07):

<!-- breadcrumb -->
[Home](../../README.md) › [Documentation](../README.md) › Power stage

# ⚡ Power stage — the interleaved four-switch buck-boost

> One phase, the interleaved module, why it is two-level, which devices it uses and on what evidence, the gate-drive channel and what each part of it protects against, the capacitors, the operating modes, the calculated losses and temperatures, and the port circuits.







---

> [!NOTE]
> All efficiencies, temperatures and stresses here are **calculated** (loss models on datasheet curves, ngspice decks
> with fitted device models). The cell design is [sim/out/pv_design/report.md](../../sim/out/pv_design/report.md) and
> [cell_spec.json](../../sim/out/pv_design/cell_spec.json); the as-built values are in the
> [PV-PWR design check](../../hardware/PV-PWR/outputs/PV-PWR_design_check.txt). "Phase" on this page is what the earlier
> platform called a "cell" (PVCELL-25).

## ⚡ One phase

A non-inverting four-switch buck-boost (FSBB) with a common negative rail: leg A faces port A, leg B faces port B, and
one inductor joins the two switch nodes. Every switch position is two paralleled 1700 V SiC MOSFETs.

```mermaid
%%{init: {"theme": "base", "themeVariables": {"primaryColor": "#EEF3F7", "primaryBorderColor": "#0B1F33", "primaryTextColor": "#0B1F33", "lineColor": "#5B6B7A", "secondaryColor": "#D9F2EF", "tertiaryColor": "#FFF4D6", "fontFamily": "Inter, Helvetica, Arial, sans-serif"}}}%%
flowchart LR
    AP["A+ · bank A"]:::live
    S1["S1 · 2 × SG2M040170HJ"]:::live
    S2["S2 · 2 × SG2M040170HJ"]:::live
    SWA(("SW_A"))
    TMR["TMR current sensor<br/>STK-HO/A 75"]:::live
    L["Inductor 224 µH<br/>2 × NPC290026 toroid"]:::live
    SWB(("SW_B"))
    S3["S3 · 2 × SG2M040170HJ"]:::live
    S4["S4 · 2 × SG2M040170HJ"]:::live
    BP["B+ · bank B"]:::live
    NEG["BUS- · common negative"]:::live
    AP --- S1 --- SWA --- S2 --- NEG
    SWA --- TMR --- L --- SWB
    BP --- S3 --- SWB --- S4 --- NEG
    classDef live fill:#FDE7E0,stroke:#E4572E,color:#0B1F33
```

| Mode | When | Leg A (S1 / S2) | Leg B (S3 / S4) |
|---|---|---|---|
| Buck | V<sub>B</sub> / V<sub>A</sub> ≤ D<sub>max</sub> = 0.943 | switches | S3 on, S4 off |
| Band | between the two | switches, D<sub>A</sub> = D<sub>max</sub> · min(1, V<sub>B</sub>/V<sub>A</sub>) | switches, D<sub>B</sub> = D<sub>max</sub> · min(1, V<sub>A</sub>/V<sub>B</sub>) |
| Boost | V<sub>B</sub> / V<sub>A</sub> ≥ 1 / D<sub>max</sub> = 1.060 | S1 on, S2 off | switches |

<sub>Source: [cell_spec.json](../../sim/out/pv_design/cell_spec.json) `switching.modes`. Bootstrap gate supplies are
impossible because S1 or S3 stays on for whole seconds; hence the isolated bias below. The mode transitions and their
hysteresis are on [05 · Control and firmware](05-control-and-firmware.md).</sub>
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

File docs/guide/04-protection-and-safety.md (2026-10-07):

<!-- breadcrumb -->
[Home](../../README.md) › [Documentation](../README.md) › Protection and safety

# 🛡️ Protection and safety

> Every trip of the cost-first PV module — where it is detected, its threshold band and response time against the requirement — the latch, the split between hardware and firmware and the numbers behind it, the contactor rules, the port A declaration and the installation requirement, what differs on the inverter, the start-up, shutdown and fault sequences, the insulation coordination, and what the design does not protect against.







---

> [!NOTE]
> Thresholds, bands and response times are **calculated worst cases** from the drawn netlists and the datasheets
> ([PV-CTL design check](../../hardware/PV-CTL/outputs/PV-CTL_design_check.txt),
> [PV-PWR design check](../../hardware/PV-PWR/outputs/PV-PWR_design_check.txt)); the requirements come from simulation
> ([pv_control report §9–§10](../../sim/out/pv_control/report.md)) and the port design
> ([port_spec.json](../../sim/out/port_design/port_spec.json) `lean`). Nothing has been tested on hardware.
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

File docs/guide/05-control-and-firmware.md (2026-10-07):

<!-- breadcrumb -->
[Home](../../README.md) › [Documentation](../README.md) › Control and firmware

# 🎛️ Control and firmware

> How the PV module is controlled — loops, modulation and mode transitions, interleaving and current sharing, MPPT — with the plant numbers, the simulated stability margins and transients, the controller's resource use, the list of firmware requirements the hardware relies on, the control board's ports, recorder and upgrade path, and a summary of the inverter's firmware specification.
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

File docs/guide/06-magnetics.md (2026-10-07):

<!-- breadcrumb -->
[Home](../../README.md) › [Documentation](../README.md) › Magnetics

# 🧲 Magnetics

> Every custom magnetic part of the PV module, the DAB and the inverter's filter — what it is for, how it is built, how it was verified three ways (designer, OpenMagnetics, an independent calculation), how it compares with the reference designs, which Asian materials it uses, what it costs, what a first article must prove — and how OpenMagnetics was
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

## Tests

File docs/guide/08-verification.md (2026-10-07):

<!-- breadcrumb -->
[Home](../../README.md) › [Documentation](../README.md) › Verification

# 🔬 Verification

> What "verified" means in a project with no hardware: the build pipeline and its checks, the board design checks, the pin, temperature and insulation audits, the independent design reviews, the simulation self-checks and the three-way magnetics check — with the result for every board, and an honest list of what has not been verified.










---

> [!IMPORTANT]
> **"Verified" here never means measured.** It means one of: *build-checked* (a script proved a property of the drawn
> netlist), *design-checked* (a board's own calculation asserted every value against its datasheet and its
> requirement), *audited* (an independent table compared against the drawing), *reviewed* (an independent engineer read
> the design and logged findings), or *simulated* (a model with its own self-checks). Each claim on these pages names
> which one applies.

## 🔬 The build pipeline

Every board is a Python script; running it regenerates the KiCad 10 project, checks it and writes the outputs. Nothing
under `hardware/` or `bom/` is edited by hand ([gen/README.md](../../gen/README.md), [gen/dcdclib.py](../../gen/dcdclib.py)).

```mermaid
%%{init: {"theme": "base", "themeVariables": {"primaryColor": "#EEF3F7", "primaryBorderColor": "#0B1F33", "primaryTextColor": "#0B1F33", "lineColor": "#5B6B7A", "secondaryColor": "#D9F2EF", "tertiaryColor": "#FFF4D6", "fontFamily": "Inter, Helvetica, Arial, sans-serif"}}}%%
flowchart TD
    SPEC["Design hand-off files<br/>sim/out/*.json"] --> GEN["Board script gen/board.py<br/>design table: parts, pins, nets"]
    GEN --> DC["design_check()<br/>asserts every value"]
    GEN --> DOM["Isolation domains<br/>only declared isolators bridge two"]
    DOM --> STR["Part stress<br/>C ≤ 80 % of rated V, R ≤ 60 % of P"]
    STR --> KI["KiCad 10 project written"]
    KI --> ERC["kicad-cli ERC<br/>all severities"]
    ERC --> NET["Exported netlist<br/>identical to the design table"]
    NET --> PDF["Schematic PDF rendered"]
    PDF --> BOM["BOM: maker, MPN, datasheet on file<br/>or GENERIC / RFQ / CUSTOM"]
    BOM --> REP["board_report.json<br/>passed true or false"]
    DC --> TXT["board_design_check.txt"]
    TXT -.->|"PV-CTL reads PV-PWR as built"| GEN
```

| Check | What it proves | What it cannot prove |
|---|---|---|
| Isolation domains | every net belongs to one domain; only parts declared as isolators or deliberate crossings touch two | that the isolator's rating is adequate (that is the insulation audit and the design check) |
| Part stress | every jellybean capacitor ≤ 80 % of its rated voltage and resistor ≤ 60 % of its power, on nets with a known DC range | pulse load, ripple, temperature derating — left to each board's design check |
| ERC (kicad-cli, all severities) | no electrical-rule error; warnings only with a written waiver | function |
| Netlist identity | the KiCad export equals the Python design table, net by net and part by part | that the design table is right |
| BOM completeness | every line has a maker, an orderable MPN and a datasheet on file, or is marked GENERIC, RFQ or CUSTOM | availability or price |
| Design check (per board) | the board's numbers against datasheets and requirements: stress, budgets, trip bands, interfaces | anything the model leaves out (layout, parasitics, real parts) |

## 🔬 Every board, as of 2026-10-07

| Board | Rev | Role | Sheets | Parts | Nets | Build checks | ERC warnings (all waived with a reason) |
|---|---|---|---:|---:|---:|---|---:|
| **PV-PWR** | A2 | cost-first power board, PV-P75 | 22 | 1,862 | 927 | 6 / 6 pass | 12 |
| **PV-PWR-4** | A2 | cost-first power board, PV-P100/110 | 25 | 2,306 | 1,134 | 6 / 6 pass | 16 |
| **PV-CTL** | A2 | cost-first control board | 8 | 316 | 222 | 6 / 6 pass | 0 |
| **PCS-PWR** | A0 | inverter power board, three-wire | 27 | 1,708 | 768 | 6 / 6 pass | 6 |
| **PCS-PWR-4W** | A0 | inverter power board, four-wire | 31 | 2,110 | 930 | 6 / 6 pass | 8 |
| **PCS-CTL** | A0 | inverter control board, both assemblies (re-valued PV-CTL) | 9 | 339 | 241 | 6 / 6 pass | 0 |
| PORT-LEAN | F0 | stand-alone build of the lean port functions | 8 | 272 | 200 | 6 / 6 pass | 0 |
| PORT-LEAN-HOLD | F0 | the lighter interlock option kept by D-050 | 8 | 245 | 186 | 6 / 6 pass | 0 |
| GDRV-HB | J0 | gate-drive card, one half-bridge | 3 | 128 | 68 | 6 / 6 pass | 2 |
| DAB60 | B0 | DAB-D60 board — frozen, to be redrawn cost-first | 16 | 1,264 | 683 | 5 / 5 pass (no stress check) | 12 |
| AUX-HV | C1 | earlier platform, reference | 4 | 150 | 70 | 6 / 6 pass | 0 |
| CTRL-C2000 | E0 | earlier platform, reference | 14 | 599 | 468 | 4 / 4 pass (no domain or stress check) | 0 |
| SYS-IO-AUX | E0 | earlier platform, reference | 12 | 566 | 351 | 5 / 5 pass | 0 |
| PV-PORT | F0 | earlier platform, reference | 6 | 563 | 345 | 6 / 6 pass | 16 |
| PV-PORT-180 | F0 | earlier platform, reference | 6 | 563 | 345 | 6 / 6 pass | 16 |
| PVCELL-25 | C0 | earlier platform, reference | 9 | 583 | 280 | 6 / 6 pass | 4 |
| BMU-GW | B0 | earlier platform, reference | 1 | 32 | 23 | 6 / 6 pass | 0 |

<sub>Source: `hardware/<board>/outputs/<board>_report.json` for each board, e.g.
[PV-PWR](../../hardware/PV-PWR/outputs/PV-PWR_report.json), [PV-CTL](../../hardware/PV-CTL/outputs/PV-CTL_report.json),
[PCS-PWR](../../hardware/PCS-PWR/outputs/PCS-PWR_report.json), [PCS-CTL](../../hardware/PCS-CTL/outputs/PCS-CTL_report.json),
[DAB60](../../hardware/DAB60/outputs/DAB60_report.json). The PV-PWR and PCS-PWR waiver is a single warning type: the
NSI6651's pin 3 is named GND2 in the datasheet but is the floating Kelvin reference of the gate island. PV-PWR,
PV-PWR-4 and PVCELL-25 lost 12 / 16 / 4 parts and as many nets when the DESAT strings of [D-081](../requirements/DECISIONS.md)
went from three diodes to two; the inverter boards kept their two diodes per channel and their counts.</sub>

**Board design checks of the cost-first boards.** The [PV-PWR design check](../../hardware/PV-PWR/outputs/PV-PWR_design_check.txt)
asserts its values on every build (a failed assertion stops the build): devices, shared heatsink, inductor, banks,
damper, X / Y capacitors, gate-drive channel and dead time, sensors, port currents, bleeders, the 5 V / 3.3 V
converters, the auxiliary budget, contactor pull-in and hold, the levels on every connector pin, and the default-off
state with the connector unplugged. The [PV-CTL design check](../../hardware/PV-CTL/outputs/PV-CTL_design_check.txt)
reports **40 PASS, 8 INFO, 2 OPEN and no FAIL**, including the latch evaluated from the netlist for 86 fault cases and an
interface check that reads the power board's design check *as built* (since [D-072](../requirements/DECISIONS.md) the
build refuses a stale copy by its hash). The OPEN lines are the over-current window's design margin — the band misses the
1.10 × normal-peak floor by 0.58 A once the comparator's common-mode term is in it ([risk C9](12-risks-and-open-items.md))
— and the SELV winding allocation of the power board at stacked maxima.
The design checks also raised findings that were then implemented: the heatsink trip lowered to ≤ 89.9 °C, the inductor
trip raised above the 145 °C full-load hot spot, and the IA / IB filter changed to reach 10 kHz. After the review round
below they also print the port A declaration, one fan-supply contract, the leg commutation with the drawn capacitors
(PV-PWR) and the live-24 V budget with typical values beside the stacked maxima.

The inverter's two boards have the same pair of checks. The [PCS-PWR design check](../../hardware/PCS-PWR/outputs/PCS-PWR_design_check.txt)
asserts the DC link, bleeders, power stage, gate drive and dead time, desaturation, LCL filter, sensing, DC and AC
ports, supplies, trip sources and thermal inputs, and prints its open items; the
[PCS-CTL design check](../../hardware/PCS-CTL/outputs/PCS-CTL_design_check.txt) reports **50 PASS, 9 INFO, 2 OPEN and no
FAIL** (the OPEN lines: the SELV winding allocation and the last spare GPIO) and reads the power board's check *as built*
and the control study's sampling plan. Since [D-067](../requirements/DECISIONS.md) the PCS-PWR check also prints the
full DC-link inventory and discharge time, the DESAT coordination with the overload, the device acceptance rule, the
DC-port fault coordination and the live-24 V step budget of the contactor pull-ins; since
[D-078](../requirements/DECISIONS.md) the protection chain at its gates-off current (both power boards), the absolute
R<sub>DS(on)</sub> limit, the residual-current interface contract and the one coil contract, and the PCS-CTL check
passes the trip chain against `protection_chain` (3.54 µs → 520.5 A ≤ 533.6 A), the CMPSS backup DAC (423.9–497.5 A
inside 417.3–504.1 A), the 1,035 V ADC-PPB backup and the residual-current channel, and prints the hand-over's
firmware-limit rows — 33 since [D-080](../requirements/DECISIONS.md), which added the 200 ms cap rule and the grid-tie
close and rewrote the grade, DC-bus and envelope rows, and 34 since [D-081](../requirements/DECISIONS.md), which added
the fans' cold-start rule and rewrote the same three again (grade B's kW rating, the enforced DC-bus window with the
harness contract, the envelope as a declared output capability); its window check now takes the firmware clamp at
378.0 A (17.1 A left against the 15 A rule). Since D-080 both power-board checks also print the module grade map
("MODULE GRADES") and the 200 ms rule during and after a 2-minute overload, and since D-081 the DESAT string's rating
argument ("STRING RATING") and the cold-start table ("COLD START"). The check counts did not change: 50 PASS, 9 INFO,
2 OPEN, no FAIL.
PCS-PWR's build checks passed on an independent rebuild ([D-061](../requirements/DECISIONS.md)); all of them are
calculations on the drawn netlists, not tests.

## 🔬 Audits

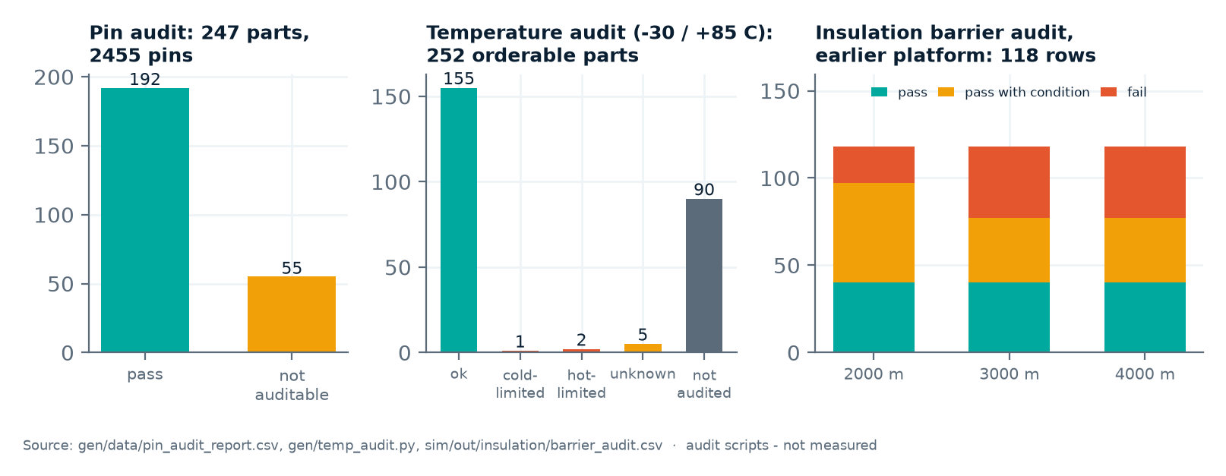
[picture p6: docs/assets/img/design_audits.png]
Pin audit, temperature audit and insulation barrier audit results


<sub>Chart: [figures_design.py](../assets/figures_design.py) from [pin_audit_report.csv](../../gen/data/pin_audit_report.csv),
a run of [gen/temp_audit.py](../../gen/temp_audit.py) and [barrier_audit.csv](../../sim/out/insulation/barrier_audit.csv).</sub>

| Audit | What it compares | Result | Coverage gap |
|---|---|---|---|
| **Pin audit** ([gen/pin_audit.py](../../gen/pin_audit.py)) | every drawn symbol's pin numbers and names against a ledger transcribed from the datasheet by someone who had not seen the symbol | 247 parts drawn, 2,455 pins: **192 parts pass (1,961 pins), 0 fail**, 55 not auditable with a written reason ([pin_audit_report.csv](../../gen/data/pin_audit_report.csv); after the rebuild for [D-081](../requirements/DECISIONS.md): the new DESAT diode BYG23T-M3/TR passes (ledger E: cathode and anode by the datasheet's polarity band), the port CM ring N-C-644025 — now an RFQ line for the flat-permeability grade — left the not-auditable list) | ledger E ([D-070](../requirements/DECISIONS.md)) added the cost-first and inverter boards, and the parts of the control board rev A2 and the four-wire power board were added on 2026-10-06; four naming mismatches were corrected in the drawing to the datasheet wording (pin numbers and functions agreed). The not-auditable parts are two-terminal parts and connectors whose datasheets print no terminal numbers, a bare core, a contactor and RFQ parts. D-070 counts 239 / 180 / 1,854 for the earlier state of the same audit — the generated report is the later record |
| **Temperature audit** ([gen/temp_audit.py](../../gen/temp_audit.py)) | every orderable part in the module BOMs against −30 °C (PV-20) and +85 °C (enclosure air) | 252 parts (the three-wire inverter module included): 155 ok, 1 cold-limited, 2 hot-limited, 5 unknown, **90 not audited** | the 90 are mostly new cost-first and inverter parts — among them the SiC MOSFET SG2M040170HJ, the driver NSI6651ASC-Q1, the F280039C, the fan AFB1224SHE-F00 (known to be rated only to −10 °C, R-05; the inverter's cold rating is −10 °C at power since D-081) and the new DESAT diode BYG23T-M3/TR; the script's module list does not include the four-wire module PCS-P125-4W |
| **Insulation barrier audit** ([sim/insulation.py](../../sim/out/insulation/report.md)) | 118 barrier rows on eight boards of the earlier platform against coordinated requirements at 2000 / 3000 / 4000 m | last run (2026-10-07, unchanged): 2000 m: 40 pass, 57 pass with a condition, 21 fail; 3000 m and 4000 m: 41 fail. "Altitude that can be claimed today: none" | **covers the earlier platform only, and a run stops:** the script has no domain map (`BOARD_DOMAINS`) for PV-CTL, PCS-PWR, PCS-PWR-4W, PCS-CTL, PORT-LEAN and PORT-LEAN-HOLD, and its PV-PORT IMD-switch override no longer matches the drawn pair, so it ends with "98 problem(s)" (102 before D-081 took PVCELL-25's DESAT strings from three diodes to two) and a non-zero exit — an open tooling item (pre-existing, not raised by the reviews). No barrier is unchecked: the cost-first and inverter boards check their own barrier parts against `insulation_spec.json` (B1 ratings and the altitude the barrier reaches in the PV-CTL and PCS-CTL design checks, isolation domains in every build), but the audit's single table does not include them |

<sub>The temperature-audit numbers come from the run inside [figures_design.py](../assets/figures_design.py) on the current BOMs (2026-10-07, after the rebuild for D-081, which added the new diode); cold-limited is a
SIKA flow switch on DAB60 (−25 °C), hot-limited a RECOM DC/DC on PVCELL-25 (71 °C) and the same SIKA part (70 °C);
unknown are a Mersen fuse and four Phoenix Contact terminals without a stated range (as named on 2026-10-05).</sub>

## 🔬 Independent design reviews

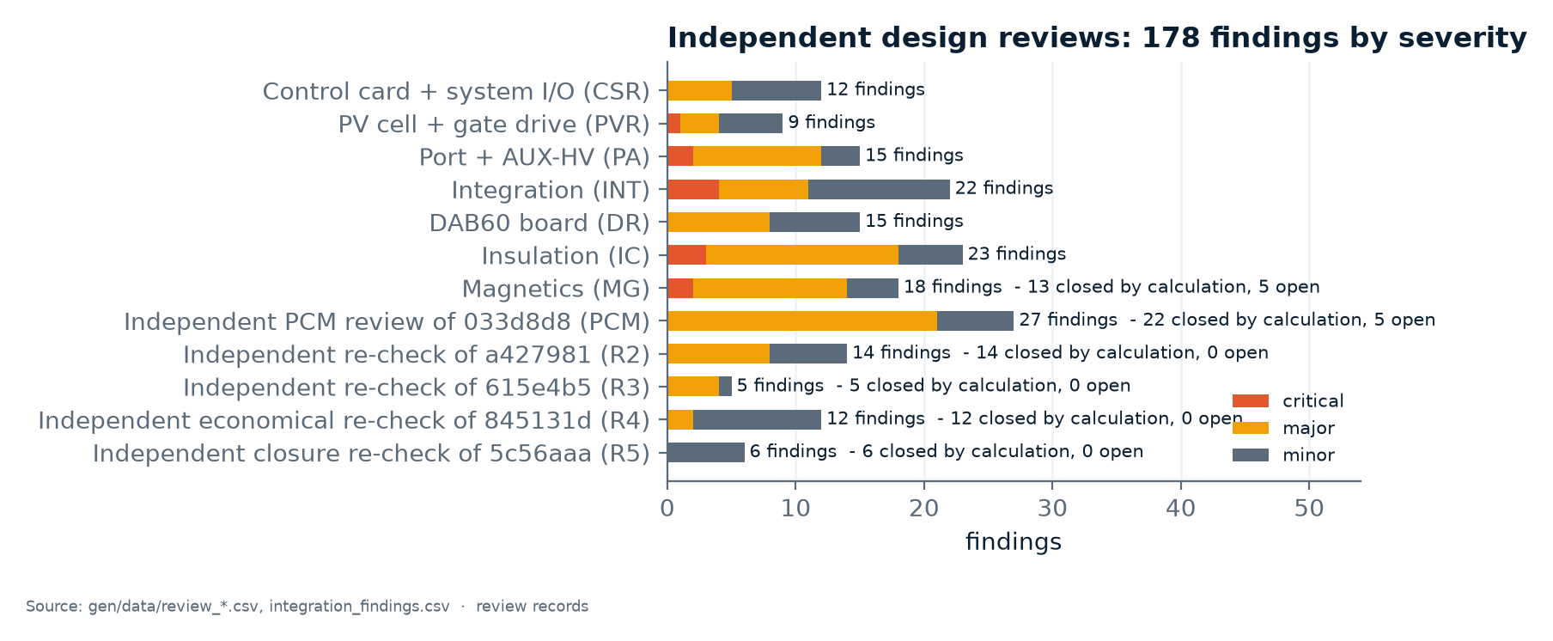
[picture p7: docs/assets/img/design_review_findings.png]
Findings of the independent design reviews by severity


<sub>Chart: [figures_design.py](../assets/figures_design.py) from `gen/data/review_*.csv` and
[integration_findings.csv](../../gen/data/integration_findings.csv).</sub>

| Review | Scope | Critical | Major | Minor | Status |
|---|---|---:|---:|---:|---|
| [CSR](../../gen/data/review_ctrl_sys.csv) | CTRL-C2000, SYS-IO-AUX | 0 | 5 | 7 | assigned to board revisions ([D-023](../requirements/DECISIONS.md)); boards then frozen as reference ([D-044](../requirements/DECISIONS.md)) |
| [PVR](../../gen/data/review_pvcell_gdrv.csv) | PVCELL-25, gate drive | 1 | 3 | 5 | the Miller-clamp critical (PVR-01) led to gate drive rev 5 and on ([D-028](../requirements/DECISIONS.md), [D-043](../requirements/DECISIONS.md)) |
| [PA](../../gen/data/review_port_auxhv.csv) | PV-PORT, AUX-HV | 2 | 10 | 3 | coil suppression and discharge criticals fixed on the earlier boards ([D-024](../requirements/DECISIONS.md), [D-025](../requirements/DECISIONS.md)) |
| [INT](../../gen/data/integration_findings.csv) | integration across boards | 4 | 7 | 11 | as CSR |
| [DR](../../gen/data/review_dab60.csv) | DAB60 board | 0 | 8 | 7 | DR-01…07 resolved by calculation in [dab_design report §0.1](../../sim/out/dab_design/report.md); DR-05 left as a residual risk |
| [IC](../../gen/data/review_insulation.csv) | insulation, all HV boards | 3 | 15 | 5 | partly closed by the Chipanalog isolators ([D-040](../requirements/DECISIONS.md)) and the varistor network ([D-042](../requirements/DECISIONS.md)) |
| [MG](../../gen/data/review_magnetics.csv) | magnetics | 2 | 12 | 4 | 13 closed by the rev M1 / M2 constructions (calculated), 5 open |
| [PCM](../../gen/data/review_pcm.csv) | independent review of commit `033d8d8`: PV-P75 / PV-P100-110 boards and control, PCS-P125 study and boards, DAB-D60 study | 0 | 21 | 6 | **22 closed, 5 open**; 21 Confirmed, 2 Firmware Handled, 3 Improvement Recommended, 1 Not Applicable ([D-065](../requirements/DECISIONS.md) to [D-069](../requirements/DECISIONS.md), [D-072](../requirements/DECISIONS.md); PCM-14 and PCM-22 closed by [D-074](../requirements/DECISIONS.md) / [D-076](../requirements/DECISIONS.md)) |
| [R2](../../gen/data/review_r2.csv) | independent re-check of commit `a427981`: the PCS-P125 protection chain, power stage, control study, start-up and hand-over; PV and DAB items | 0 | 8 | 6 | **14 closed in the register**; 9 Confirmed, 1 Firmware Handled, 2 Already Fixed, 1 Not Applicable, 1 Improvement Recommended ([D-078](../requirements/DECISIONS.md), [D-079](../requirements/DECISIONS.md)) |
| [R3](../../gen/data/review_r3.csv) | independent re-check of commit `615e4b5` (the R2 response): the inverter's synchronised close, the four-wire short against both trip layers, the DC-bus coordination with the PV modules, the SiC grades, the off-grid envelope | 0 | 4 | 1 | **5 closed in the register**; 4 Confirmed, 1 Improvement Recommended ([D-080](../requirements/DECISIONS.md)) |
| [R4](../../gen/data/review_r4.csv) | independent economical re-check of commit `845131d` (the D-080 documentation): twelve decision areas — the DESAT string's reverse rating, the battery-less DC bus, the off-grid envelope's applicability, the cold rating, the SiC grades, the magnetics and variant cost, and six restated or restricted items | 0 | 2 | 10 | **12 closed in the register**; 3 Confirmed, 4 Already Fixed, 3 Improvement Recommended, 2 Not Applicable ([D-081](../requirements/DECISIONS.md)) |
| [R5](../../gen/data/review_r5.csv) | independent closure re-check of commit `5c56aaa` (the D-081 documentation): six rows — the DESAT string's dynamic qualification, the battery-less link and harness, the cold and grid-forming claim boundaries, the SiC grades and the earlier platform's assemblies, and the standing physical-implementation gates | 0 | 0 | 6 | **6 closed in the register, no new defect**; 4 Already Fixed, 1 Not Applicable, 1 Improvement Recommended ([D-082](../requirements/DECISIONS.md)); every open gate of the five rounds is consolidated in [QUALIFICATION-PLAN.md](../requirements/QUALIFICATION-PLAN.md) |
| **Total** | | **12** | **95** | **71** | 178 findings |

The first four reviews are the round of [D-023](../requirements/DECISIONS.md): 58 defects (7 critical, 25 major, 26
minor) found **after** every board had passed its own checks — the reason the review step exists. The magnetics, PCM,
R2, R3, R4 and R5 files carry a status column; for the others the status is taken from the decision register. The PCM
register's severities map the reviewer's P1 to *major* and P2 / P3 to *minor*; the R2 register grades its findings
*high* (8) and *medium* (6), the R3 register *high* (4) and *low* (1), the R4 register *high* (2), *medium* (5) and
*low* (5), and the R5 register *low* (6), counted in the table and in the chart above as major (high) and minor (medium, low).

**How the PCM findings were handled.** Every finding was verified independently before anything changed: the
reviewer's evidence (code reading, recalculation, datasheet check) was reproduced against the code, the datasheets and
a fresh calculation — for example the 70.0 kW at 550 / 550 V (PCM-01), the 689.66 / 758.62 V of the four-phase battery
port (PCM-13), the 129.53 A rms circulating current at 950 / 400 V (PCM-12) and the deck peaks of 1,236 V and
1,398 / 1,437 V (PCM-11) were all reproduced, while the fault-timing ratio of PCM-10 was recomputed from the driver's
timing diagram and replaced (both the reviewer's 1.58 × and the earlier 0.97 ×). Each finding was then put in one of
six classes — Confirmed, Already Fixed, Firmware Handled, Not Applicable, False Finding, Improvement Recommended — and
only the required changes were made, at the source of the number (mostly the study scripts under `sim/`), with the
affected studies re-run and the boards rebuilt before a finding was marked closed. The closure text of each row is in
[review_pcm.csv](../../gen/data/review_pcm.csv); all of it is calculated, not measured.

| Open finding | Why it stays open | What closes it |
|---|---|---|
| PCM-08 | no Chinese 1700 V or 1200 V SiC maker publishes a short-circuit withstand, a hot V<sub>GS(th)</sub> minimum, a cosmic-ray curve or a qualification report | supplier evidence; for PV-P75 the qualified Microchip MSC035SMA170B4 assembly variant ([D-043](../requirements/DECISIONS.md)) |
| PCM-10 | the DAB study's fault chain is 0.99 × the assumed hot withstand; the 2 × rule needs 0.50 and no lever inside the NSI6651 reaches it (best 0.61) | maker-confirmed t<sub>SC</sub> ≥ 2.22 µs at 1000 V / 150 °C and E<sub>SC</sub> ≥ 2.18 J per device, or a short-circuit test |
| PCM-19 | the TLV9024's rejection at 3.3 V is unspecified; with the guaranteed 50 dB the window misses its 1.10 floor by 0.58 A | CMRR measured ≥ 60 dB at 3.3 V on samples plus 10 ppm/K ladder resistors (0.74 USD) |
| PCM-24 | no supplier quotation exists | quotations for the main switch, magnetics, contactors and film capacitors; assembly and test cost |
| PCM-27 | standards, pollution degree, coating and the custom transformer construction are not fixed from purchased texts | the standards bought, the levels fixed and type-tested |

> [!WARNING]
> **A closed finding is a corrected calculation, not a test.** The PCM round changed studies, two board pairs and the
> firmware requirements, but nothing it closed has been measured; five findings stay open because only supplier data,
> a measurement or a product decision can close them (PCM-14 and PCM-22 were closed by [D-076](../requirements/DECISIONS.md)
> and [D-074](../requirements/DECISIONS.md)). The R2, R3 and R4 re-checks below closed all 14, all 5 and all 12 of their
> rows in the register in the same sense — by calculation, simulation, firmware, product and acceptance rules, zero-cost
> values and one diode substitution — with their hardware gates listed separately. On the earlier
> platform the review round found 58 defects in boards that passed every automated check — the reason the step exists.

**How the R2 findings were handled** ([review_r2.csv](../../gen/data/review_r2.csv), [D-078](../requirements/DECISIONS.md),
[D-079](../requirements/DECISIONS.md); everything simulated or calculated). The same procedure as for PCM: each finding
was first reproduced with our own decks and models, then classified, then corrected at the source of the number, with
the studies re-run and the boards rebuilt before closure.
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

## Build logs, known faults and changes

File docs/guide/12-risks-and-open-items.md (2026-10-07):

<!-- breadcrumb --> [Home](../../README.md) › [Documentation](../README.md) › Risks and open items

# ⚠️ Risks and open items

> Every open risk and unverified assumption on record, grouped and ranked, with its consequence and what would close it.






---

> [!IMPORTANT]
> **Why this list is long.** Nothing has been built, bought, quoted or measured. Every risk below is either a figure
> that rests on an estimate or an assumption, or a property that only hardware can show. The list is collected from
> the [decision register](../requirements/DECISIONS.md), the risk tables of
> [ARCHITECTURE-COSTFIRST.md §13](../requirements/ARCHITECTURE-COSTFIRST.md#13-open-risks) (R-01…R-18) and
> [ARCHITECTURE-PCS.md §11](../requirements/ARCHITECTURE-PCS.md#11-open-risks), the "open items" sections of the
> simulation reports and the open findings of the independent reviews ([review_pcm.csv](../../gen/data/review_pcm.csv),
> [review_r2.csv](../../gen/data/review_r2.csv), [review_r3.csv](../../gen/data/review_r3.csv),
> [review_r4.csv](../../gen/data/review_r4.csv), [review_r5.csv](../../gen/data/review_r5.csv)). Where a source has since closed an item, it is left out.

**Ranking.** Priority **1** = high impact and likely, or a release condition; **2** = high impact but less likely, or
likely with a contained consequence; **3** = worth tracking. Impact and likelihood are judgements from the records, not
calculations.

## 🔬 The re-check R2 of commit a427981 (2026-10-07)

An independent re-check of commit `a427981` raised 14 findings, R2-01 to R2-14 (8 high, 6 medium). Each was verified
against our own models first and then classified; the register [review_r2.csv](../../gen/data/review_r2.csv) holds every
row with its status, classification and closure — all 14 are closed there. The dispositions are
[D-078](../requirements/DECISIONS.md) (power stage and protection chain) and [D-079](../requirements/DECISIONS.md)
(control study and hand-over).

| Classification (register) | Findings | Count |
|---|---|---:|
| Confirmed | R2-01, R2-02, R2-03, R2-04, R2-06, R2-07, R2-12, R2-13, R2-14 | 9 |
| Firmware Handled | R2-05 | 1 |
| Already Fixed | R2-08, R2-10 | 2 |
| Not Applicable | R2-09 | 1 |
| Improvement Recommended | R2-11 | 1 |
| False Finding | — | 0 |

Closed in the register does not mean closed on the bench. The closures are calculations, simulations on averaged models
and zero-cost firmware, DAC, acceptance or gate-resistor values; what only hardware can show stays open below:
short-circuit survival (C2), the turn-off at the trip's gates-off current and its layout inductance (C10, C11), the L1
inductance beyond 450 A (D11), the R<sub>DS(on)</sub> distribution (F4), the ride-through margin (E6), the AC-start
residuals (E11), the residual-current monitor and the AC coil module (F7, F10) and the standards texts (B1, F2). Rows that
D-078 / D-079 resolved are marked where they stood.

## 🔬 The re-check R3 of commit 615e4b5 (2026-10-07)

A third independent re-check, of commit `615e4b5` (the R2 response), raised five findings, R3-01 to R3-05 (4 high,
1 low). Each was reproduced in our own checks first and then classified; the register
[review_r3.csv](../../gen/data/review_r3.csv) holds every row with its status, classification and closure — all five are
closed there. The disposition is [D-080](../requirements/DECISIONS.md): firmware rules the study executes, acceptance
rules the assembly carries and one requirement row (AC-04) — nothing added to the BOM.

| Classification (register) | Findings | Count |
|---|---|---:|
| Confirmed | R3-01, R3-02, R3-03, R3-04 | 4 |
| Improvement Recommended | R3-05 | 1 |
| Firmware Handled, Already Fixed, Not Applicable, False Finding | — | 0 |

Resolved by D-080 where the rows stood (simulated on the averaged or executed models, or calculated — not measured):

- **The synchronised close (R3-01, row E11).** SYNC → GFL / GFM commanded both AC contactor coils at once (54.9 /
  58.2 W against the 48 W live peak) and the invariant I12 excluded SYNC. Now SYNC → SYNC_CLOSE_K2 → settled 200 ms →
  SYNC_CLOSE_K1 → GFL or GFM; I12 holds without the exception; 646 state-event pairs and 24 fault runs over both starts
  pass; the coil peak is 38.9 / 42.2 W (three- / four-wire).
- **The four-wire trip coverage (R3-02, row E12).** The line-to-neutral short's 425 A first peak had been screened
  against the window's 426.0 A edge only, while the CMPSS backup's low edge is 423.9 A. With both layers replayed on
  their own signals the D-079 firmware trips the backup at the low plant corner; a 270 A clamp for a 5 ms onset window
  keeps every studied corner off both layers (hold 378.7 A, smallest margin 13.3 A). Every "may a layer trip" screen now
  uses 423.9 A: the per-sample clamp is 378.0 A (was 380.1 A), the ride-through onset margins are 20.5 / 18.4 A net of an
  ADC-noise term, and the stiff-grid fallback is re-tabled (row E6).
- **The DC/DC coordination assumption (R3-03, row E5).** The tail model's "DC/DC stops 50 µs after the PCS trip" was
  tied to no circuit (the PV board's external stop responds in 1.47 ms). It is replaced by the coupled PCS / PV
  trajectory with the PV modules' own protections: on that one-node model the island rides a full-load rejection up to a
  909 V bus set point (two PV modules; 921 V with one) — a model validity, not a rating; since D-081 the cable is in the
  model and the product window is 750 V default, 782 V firmware limit (row E5).
- **The unscreened grade (R3-04, row F4).** The 209 A fallback was one corner (900 V, PF 0, 45 °C inlet) and the 110 %
  tier of a high-resistance population had never been limited. Now two module grades with full tier tables, bound to the
  module serial, and one 200 ms cap rule for both.
- **The off-grid envelope (R3-05, row E13).** It had been chosen to contain the simulated worst corner; it is now the
  ITIC-style points (FROM MEMORY), adopted by delegation as requirement AC-04, which the worst corner clears by
  +0.054 pu; the IEC 62040-3 classes are not met in the first 5 ms and not claimed.

New open items from D-080, in the tables below: the envelope as a delegated decision whose gates are the standards texts
and the bench (E13); the bench gates for the 13.3 A four-wire hold margin (E12), the 909 V set-point validity (E5; a
model figure, not a rating — D-081 enforces 750 / 782 V) and
the 20.5 A onset margin (E6); Sichain's R<sub>DS(on)</sub> distribution or a ≤ 40 mΩ bin, which now decides the grade a
module ships in (F4); the relay timings, the synchronisation model, the path-check method and the ADC noise figure, all
ASSUMED (E11, E6); what the coupled DC/DC model leaves out — the PV modules' V<sub>B</sub> loop (not credited), the cable
between the modules (modelled since D-081), a switched model (E5).

## 🔬 The re-check R4 of commit 845131d (2026-10-07)

A fourth independent review, an economical re-check of commit `845131d` (the documentation of D-080), grouped its
points into twelve decision areas, E01 to E12 (2 high, 5 medium, 5 low), each with a preferred option, an alternative, a
no-change boundary and a cost basis. Each was verified against our own models first and then classified; the register
[review_r4.csv](../../gen/data/review_r4.csv) holds every row with its status, classification and closure — all twelve
are closed there. The disposition is [D-081](../requirements/DECISIONS.md): one diode substitution, firmware and product
rules, a requirement wording (AC-04), a cold rating (AC-02) and an RFQ index — no topology, capacitor bank, brake chopper
or inter-module trip line.

| Classification (register) | Decision areas | Count |
|---|---|---:|
| Confirmed | E01, E04, E11 | 3 |
| Already Fixed | E02, E03, E05, E10 | 4 |
| Improvement Recommended | E06, E08, E12 | 3 |
| Not Applicable | E07, E09 | 2 |
| Firmware Handled, False Finding | — | 0 |

<sub>D-081's summary counts 4 *Confirmed* and 2 *Improvement Recommended*; the register classifies E08 *Improvement
Recommended* and three areas *Confirmed*. This page follows the register ([Where the records disagree](#where-the-records-disagree)).</sub>

What the reviewer executed independently, by the reviewer's report (not kept in the repository; calculations and
checks, not converter simulations): a manually transcribed command-table check over the 646 state-event pairs (no
simultaneous AC-coil command), a mutation test that reintroduced the two old SYNC transitions and produced the two
expected counterexamples, energy sensitivity cases for the battery-less bus and DESAT voltage screens. No repository
build, ERC, SPICE deck, pin audit, nonlinear simulation or hardware test was run in that round.

Resolved by D-081 where the rows stood (calculated or simulated, not measured):

- **The DESAT string (E01, rows F5 and C2) — the one new technical finding, and wider than reported.** The inverter's
  string was 2 × US1MH (1000 V), and its design check credited one diode with 95 % of the 1,050 V bus; on our own
  envelope that put 1,017–1,074 V on one diode. With the gates off and the contactors open nothing fixes the split
  between a leg's two switches, so the whole link can sit across one switch: 590–950 V in operation, 978–1,048 V in the
  over-voltage band, 1,071 V at its gates-off corner, 1,094–1,106 V latched after a trip, 1,060–1,061 V on a shared PV
  link, 1,063–1,130 V with the PV firmware dead — a static envelope of **1,130 V** (design value 1,150 V), and no
  datasheet gives a minimum leakage to prove better sharing. Now **2 × Vishay BYG23T-M3/TR** (1,300 V, t<sub>rr</sub>
  ≤ 75 ns, avalanche-rated 5 mJ non-repetitive, LCSC C145454) per channel on both 1,700 V presets: each diode alone
  blocks the static envelope (× 1.15 over 1,130 V, × 1.13 over 1,150 V), no balancing network; the dynamic share is
  ≤ 867 V per diode (junction capacitances ±20 %, ASSUMED); C<sub>J</sub> 9 pF at 4 V, not above the US1MH's 10 pF. The
  inverter's window stays 6.41–9.37 V, so D-080's grade tables are identical; a hard short is off 1.26 µs after it
  starts (was 1.28 µs). The PV preset goes from three diodes to two: 6.41–9.37 V (was 5.43–8.47 V), on-state margin
  × 2.0 (was × 1.7). Per module +0.96 (PCS-P125), +1.28 (PCS-P125-4W), +1.59 (PV-P75) and +2.12 USD (PV-P100/110) at
  5,000 units. Rejected: BYG10Y (standard recovery, 4 µs), STTH112A (dearer, or failing the sourcing rule SRC-2), SiC
  Schottky diodes (capacitance at low voltage), balancing resistors (1.7 W per channel at the latched bus), a third
  diode (sharing still unproven).
- **The battery-less DC bus (E04, row E5).** The coupled model had put the PCS link and the PV banks on one node. It
  now carries the inter-module cable (series R and L per PV module; an ASSUMED harness of 2 / 10 / 20 m runs at 0.6 or
  1.0 µH/m, 95 mm² copper at 20 °C), the PV banks on their own node, the PV detection on its own port voltage and two
  source extremes (the PV study's slowest current loop; the coordination chain at its full × 2 margin). The cable adds
  up to +28 V: at a 750 V set point the PCS node peaks at 849 / 856 / 887 V, at 782 V at 878 / 884 / 914 V (nominal /
  slow loop / slow loop and late detection) — every corner rides through below the 975 V soft limit. The window is now
  a product rule: **default set point 750 V** (755 V for the four-wire build in mode A), a **782 V firmware clamp** in
  the PV module's parameter set, and the inverter refuses an island start above **791 V** on a bus declared
  battery-less. The one-node 909 / 921 V and the cable model's 846 V are model validities, **not ratings**. The harness
  is an installation contract ([INSTALLATION.md](../requirements/INSTALLATION.md) INST-71, INST-76).
- **The off-grid envelope (E06, row E13).** The ITI curve describes the input tolerance of IT equipment at 120 V /
  60 Hz; it is not a product or distribution specification. AC-04 is reworded: the envelope is the module's **declared
  output capability** on a load step (worst corner +0.054 pu against the ITIC-style points FROM MEMORY), **not** a
  load-compatibility claim, with a release sequence — grid-following qualified first; grid forming for managed island
  loads with an agreed voltage-time and interruption specification; general-purpose off-grid or UPS-like supply only
  once an output class and its test method exist. The control measures did not change.
- **The inverter's cold rating (E11, rows A4 and F14).** Modelled the PV way (ESTIMATES ±50 %): with the fans off the
  inverter holds 20 / 15 / 8 kVA (three-wire) and 14 / 7 / 0 kVA (four-wire) at 600 V DC and −30 / −20 / −10 °C inlet,
  and nothing above 700 V DC — too little to be useful. The cold rating of AC-02 is amended by delegation: **full
  operation from −10 °C inlet**; below it standby or the passive table, under a firmware rule (fans off below −10 °C
  inlet, the current limited to the table, fans on at −10 °C or above or once a heatsink NTC exceeds 80 °C, a failed
  inlet NTC turns them on). The only −30 °C fan on file would add 225–299 USD (three-wire) / 299–399 USD (four-wire) per
  module and 2.2 × the fan power — rejected; a cold-rated 12 W fan (RFQ) is the way back to −30 °C at power.
- **Grade B's honest rating (E05, row F4).** D-080's two grades are the reviewer's preferred production strategy (pool
  measured devices into grade-A and grade-B banks, the grade bound to the serial). Added: grade B's declaration states
  its rating — 179.8 A continuous at 60 °C inlet is **124.57 kW** at PF 1 and 400 V (125 kW needs 180.42 A; the rated
  180 A is 124.71 kW). A supplier-guaranteed R<sub>DS(on)</sub> bin stays an RFQ item.
- **Magnetics and variant cost (E12, rows A1 and F3).** [RFQ-MAGNETICS.md](../requirements/RFQ-MAGNETICS.md) indexes
  ten requests for quotation with the rows a quotation must hold (inductance at current, losses, insulation,
  temperature), the type and production tests, the estimate held and 18 rows still without a number; the three- and
  four-wire builds stay separate assemblies; the 48 kHz weight-sensitive candidate is an appendix, not a substitution.
  Two record conflicts it found were fixed at the root: the PV port ring's catalog entry now names the
  flat-permeability grade (an RFQ item keyed by the size code N-C-644025), and the auxiliary transformer's thermal type
  test reads the 94.2 W rating (it read 82.5 W).
- **Already fixed or not applicable (E02, E03, E07–E10).** The one-coil synchronised close (the reviewer's 646-pair
  check found no counterexample); the four-wire onset clamp and its declared protective trip (first peaks ≤ 351 A,
  13.3 A margin, a bench item); the PV 550 V corner (published); the 1.09 comparator margin (a qualified availability
  restriction); the DAB study deferred with its restricted map; the upstream DC fault contract in INSTALLATION.md.

New open items from D-081, in the tables below: the new diode's V<sub>F</sub> at the DESAT current (0.59–0.81 V,
extrapolated, ASSUMED) and its temperature coefficient, a stored-charge mismatch after reverse conduction (bench: the
per-diode split), creepage across one diode in layout, no AEC-Q101 variant and LCSC stock of 10,840 against 60–160 k
parts a year (F5); the DAB / GDRV-HB 1,200 V string, which keeps 3 × US1MH at × 0.95 of its 1,048 V peak (C12); the
harness figures, ESR and skin effect and the PV voltage loop not credited, unequal run lengths not studied (E5); a
managed-island load specification (E13); the cold-rated fan RFQ (A4, F14); the magnetics RFQ's 18 open rows (A1, F3).

**Standing restrictions — accepted limitations, not ignored hazards.** The reviewer's rule for a waiver: it states the
excluded operating condition, the enforced limit, who accepts the consequence and what evidence lifts it. The register
rows and the records behind each (calculated, not measured):

| Restriction | Excluded condition and enforced limit | Boundary that stays | What would lift it | Rows · record |
|---|---|---|---|---|
| PV-P75 at 550 V (E07) | 75 kW from 556 V on the 135 A port; at 550 V × 135 A the port carries 74.25 kW before loss (73.34 kW delivered); delivered rating from 562 V at equal port voltages | no 75 kW claim at the 550 V corner | a higher current class with the port, magnetics, thermal design and protection revalidated | G2 · [D-065](../requirements/DECISIONS.md) |
| PV-P100/110 four-phase battery port, 145 A | a voltage-restricted derivative: 100 kW from 690 V A→B / 697 V B→A, full power to 35 °C inlet; PV-P110's 110 kW is a PV-input rating (108.8 kW delivered A→B) | the ideal minima (689.66 V for 100 kW, 758.62 V for 110 kW) are not ratings: the delivered-power direction and the losses stay in | a 180 A battery port, or the litz-wound inductor | D3, G3 · [D-056](../requirements/DECISIONS.md) |
| PV comparator margin 1.09 (E08) | the inductor window 67.9–80.5 A misses the 1.10 × normal-peak floor by 0.58 A: a nuisance trip at the worst stacked corner, accepted as an availability restriction | only the nuisance margin is accepted; the upper fault bound — window top 80.5 A, 1.52 µs to the gates, below the 81.1 A backup — is documented and not traded | the TLV9024's rejection measured ≥ 60 dB at 3.3 V and 10 ppm/K ladder resistors | C9 · [D-072](../requirements/DECISIONS.md) |
| DAB-D60 (E09) | the D2W study keeps its own identity and restricted map; the product is deferred behind the PV and PCS gates | no unrestricted 60 kW, high-voltage or short-circuit claim from the study alone | a better-qualified switching cell with the modulation, short-circuit and DC-port map revalidated, or an externally qualified isolated converter | D2, D9, C2 · [D-068](../requirements/DECISIONS.md) |
| Cold ambient (E11) | PV modules: below −10 °C inlet the passive table only; inverter: full operation from −10 °C inlet, below it standby or its passive table | the −30 °C rating is not kept silently: a storage rating is not fan qualification, and an untested passive table is not a full-power guarantee | a cold-rated fan within a few USD (RFQ), and a cold-chamber run of the passive tables | A4, F14 · [D-072](../requirements/DECISIONS.md), [D-081](../requirements/DECISIONS.md), AC-02 |
| Upstream DC fault protection (E10) | PV battery port: 0.97–1.25 kA within 0.26 s, ≤ 50 kA at L/R ≤ 1 ms; inverter: 0.97–2.01 kA within 2.5 s, ≤ 7.5 kA prospective at L/R ≤ 1 ms — left to the upstream device | no waiver of the uncovered bands: the actual device, its clearing time, the prospective current and L/R are bound per installation — a sentence in a manual is not a tested coordination | the integrator's coordinated device set, or a re-selected local fuse / contactor pair where a wider source envelope is needed | A5, B6 · [INSTALLATION.md](../requirements/INSTALLATION.md) INST-11…15 |
| Three-wire against four-wire (E12) | separate assemblies: the neutral leg, its sensor, filter, cooling and contactor poles only in PCS-P125-4W (about 287 USD more at 5,000 units) | no four-wire or unbalanced-load claim on the three-wire hardware; on a TN grid the three-wire build needs the battery's capacitance to earth ≤ 5.79 µF below 680 V | — (a product choice) | F1 · [D-074](../requirements/DECISIONS.md), INST-16 |

<sub>Boundaries: the register's recommendation column ([review_r4.csv](../../gen/data/review_r4.csv)) and the
reviewer's list of what may stay restricted; figures from the generated records named in each row's risk.</sub>

## 🔬 The re-check R5 of commit 5c56aaa (2026-10-07)

A fifth independent review, a closure re-check of commit `5c56aaa` (the documentation of D-081), gave six rows, R5-01 to
R5-06 (all low severity). The register [review_r5.csv](../../gen/data/review_r5.csv) holds each with its status,
classification and closure — all six are closed there and **no new defect was found**: 4 *Already Fixed* (R5-01 to
R5-04), 1 *Not Applicable* (R5-05), 1 *Improvement Recommended* (R5-06). The disposition is
[D-082](../requirements/DECISIONS.md); no hardware, firmware or requirement changed. The reviewer verified D-081 at BOM
level (12 / 16 / 24 / 32 BYG23T-M3/TR on PCS-PWR / PCS-PWR-4W / PV-PWR / PV-PWR-4, two per channel) and by his own
arithmetic (the 6.415–9.365 V DESAT window; 150 V of margin at the 1,150 V design envelope), confirmed the cable-aware bus
window (790.9 V permissive, 1.70 V harness drop, 752.4 V → 755 V), the −10 °C inverter grade, the AC-04 wording and the
two-grade policy, and recorded that the 1,300 V diode closure must not be carried to the earlier platform's 1,200 V class
(C12). His bottom line, accepted: the next useful milestone is a controlled prototype and a representative
switching-cell qualification, not another script pass.

What the round changes is one document: [QUALIFICATION-PLAN.md](../requirements/QUALIFICATION-PLAN.md) consolidates every
open gate of the five rounds as Q-01 … Q-44 — the acceptance number our records give, the test asset, the product or claim
it blocks and the stage (representative switching cell → controlled prototype → DVT → production controls) — and says
what a paper waiver cannot replace. R5-01 to R5-04 name Q-01 … Q-12 (the DESAT string's dynamic qualification, the
battery-less bus and harness, the cold rating with managed-island loads and grid code, the SiC switching cell); R5-06's
standing gates are Q-13 onward. The "what closes it" cells of the risk rows below are unchanged; the plan is where they
become a programme.

## ⚠️ Risk matrix

```mermaid
%%{init: {"theme": "base", "themeVariables": {"primaryColor": "#EEF3F7", "primaryBorderColor": "#0B1F33", "primaryTextColor": "#0B1F33", "lineColor": "#5B6B7A", "secondaryColor": "#D9F2EF", "tertiaryColor": "#FFF4D6", "fontFamily": "Inter, Helvetica, Arial, sans-serif"}}}%%
quadrantChart
    title Open risks - likelihood against impact (judgement)
    x-axis Less likely --> More likely
    y-axis Smaller impact --> Larger impact
    quadrant-1 Act now
    quadrant-2 Watch closely
    quadrant-3 Track
    quadrant-4 Plan the mitigation
    A1 No quotations: [0.92, 0.78]
    A2 SiC device data: [0.70, 0.90]
    B1 Standards from memory: [0.55, 0.85]
    B2 Driver impulse rating: [0.45, 0.80]
    C1 Miller margin: [0.40, 0.72]
    C2 Short-circuit withstand: [0.50, 0.68]
    C10 Turn-off at gates-off current: [0.42, 0.62]
    D11 L1 beyond 450 A: [0.35, 0.47]
    A4 Fan cold rating: [0.85, 0.42]
    B4 Touch current: [0.90, 0.35]
    C3 Six in parallel: [0.45, 0.50]
    D1 Magnetics models: [0.55, 0.40]
    E1 PCS control: [0.40, 0.55]
    A3 Module data: [0.75, 0.20]
    G1 AC-02 full load: [0.95, 0.58]
```

<sub>Point labels are the IDs used in the tables below. A point's position is a judgement made from the cited records.</sub>

---

## A · Evidence, supply and cost

| ID | Priority | Risk | Consequence | What closes it | Source |
|---|:---:|---|---|---|---|
| A1 | **1** | **No supplier quotations.** About two thirds (66 %) of the PV-P75 catalogue total is engineering estimate; most of the 5,000-unit figure rests on assumed volume factors. The 800 USD working budget is not met (980 USD catalogue / 820 USD at 5,000 units, as of 2026-10-07) | the gap to the benchmark cannot be judged honestly; it may be larger or smaller | quotations for the SiC devices, inductors, contactors, film capacitors and fuses; for the custom magnetics the rows a quotation must hold are indexed in [RFQ-MAGNETICS.md](../requirements/RFQ-MAGNETICS.md) (ten parts, 18 rows still without a number; review R4, E12) | [D-052](../requirements/DECISIONS.md), [D-081](../requirements/DECISIONS.md), [bom/COST.md](../../bom/COST.md) |
| A2 | **1** | **Sichain SG2M040170HJ** publishes no qualification statement, no short-circuit rating and no cosmic-ray data; PV-P75 uses it 24 times, PCS-P125 36 times. The LCSC pass of 2026-10-05 found it on LCSC (C42456100: 5.07 USD at 90+, 418 in stock = 17 / 13 / 11 modules) — the earlier 4.07 USD estimate was 1.00 USD low — but no Chinese SiC datasheet states a short-circuit rating, AEC-Q101 is stated only by InventChip and the Western automotive parts, and no maker publishes a reliability report or a cosmic-ray curve | release blocked until the data exist; the failure rate at 950–1000 V is unknown | Sichain reliability report, short-circuit data and a quotation; for PV-P75 the qualified Microchip MSC035SMA170B4 is an assembly variant — at 36 devices it does not fit the PCS budget | [D-043](../requirements/DECISIONS.md), [D-053](../requirements/DECISIONS.md), [D-069](../requirements/DECISIONS.md), [lcsc_semis.md](../../sim/data/lcsc_semis.md) |
| A3 | 3 | **Chinese power modules** (24 candidates): no public price, none on LCSC; short-circuit data on only a few sheets; HIITIO's sheets disagree with its OEM's for the same part | the module option cannot be evaluated; it stays a request-for-quotation alternate | quotations below the break-even prices; maker confirmation of the data | [D-055](../requirements/DECISIONS.md), [asia_modules.md](../../sim/data/asia_modules.md) |
| A4 | 2 | **Fan rated −10 °C** (Delta AFB1224SHE-F00) against the −30 °C requirement. The cold start is a modelled restriction ([D-072](../requirements/DECISIONS.md)): below −10 °C inlet the fans stay off and the power is limited to a passive-cooling table — PV-P75 19.2 / 17.5 / 15.5 kW at −30 / −20 / −10 °C inlet (pessimistic 6.8 / 0 / 0 kW), PV-P100/110 19.9 / 14.9 / 5.0 kW, none at 611 / 611 V; estimates ±50 %; the inlet warms from −30 to −10 °C in about 45–48 min. The inverter uses the same fans; its passive table is too small to be useful, so since [D-081](../requirements/DECISIONS.md) (review R4, E11) its cold rating is full operation from −10 °C inlet (risk F14) — an accepted limitation, [stated as such](#standing-restrictions) | PV-20's −30 °C holds at reduced power only, on an unvalidated model; the inverter's −30 °C (AC-02) holds as standby or its passive table only | a cold-chamber run of the passive tables; a cold-rated 12 W fan from an RFQ, worth adopting if it keeps the module within a few USD; the −30 °C fan on file (Sanyo 9GT1224P1S001, +225–300 USD per PV module, +225–299 / +299–399 USD per three- / four-wire inverter, 2.2 × the fan power) or a −20 °C one (ebm-papst 4414/2HHP, +63–198 USD) — priced, not taken | [R-05](../requirements/ARCHITECTURE-COSTFIRST.md#13-open-risks), [D-045](../requirements/DECISIONS.md), [D-072](../requirements/DECISIONS.md), [D-081](../requirements/DECISIONS.md), [PV-CTL design check](../../hardware/PV-CTL/outputs/PV-CTL_design_check.txt) |
| A5 | 2 | **Contactor and fuse data**: the Hongfa contactor does not state its coil-to-mounting insulation; the Hongfa aR fuse has no price and its curves are read conservatively. For the inverter's 400 A fuse (HIITIO HCHVF1000-400A-38R) the coordination is now computed ([D-067](../requirements/DECISIONS.md), [port report §14](../../sim/out/port_design/report.md)): the port window (387–413 A) opens the contactor up to its 967–1,033 A hold-off band (2.3 openings at the band top); from 0.97 to 2.01 kA nothing clears quickly; the 400 A links clear 2.0–7.4 kA; above 7.5 kA prospective the contactor's short-circuit capacity (8 kA for 6 ms, 10 kA for 1.5 ms) is exceeded. The fuse chart's high-current tail does not match its tabulated I²t | basic insulation unverified; two installation requirements for the inverter's battery side: interrupt 0.97–2.01 kA within 2.5 s, and limit the prospective current at the PCS DC terminals to ≤ 7.5 kA (L/R ≤ 1 ms) or interrupt above it within the contactor's capacity; every installation condition of the modules, with the generated line it comes from, is collected in [INSTALLATION.md](../requirements/INSTALLATION.md) | a Hongfa statement and quote, or an insulating mounting plate; the HIITIO curve confirmed by quotation or test | R-03, R-04, [D-061](../requirements/DECISIONS.md), [D-067](../requirements/DECISIONS.md), [PCS-PWR design check](../../hardware/PCS-PWR/outputs/PCS-PWR_design_check.txt) |
| A6 | 3 | **Film capacitors**: no Chinese price; the Faratronic second source is rated 1200 V at 70 °C instead of 1300 V | about half the voltage-life margin where the second source is used | quotes; use Faratronic only where the hot spot stays ≤ 70 °C | R-08, [ARCHITECTURE-COSTFIRST §12](../requirements/ARCHITECTURE-COSTFIRST.md#12-what-the-lean-design-gives-up-plain-list-for-the-owner) |
| A7 | 3 | **Unpriced lines**: the TLV9024PWR comparator has no price row (one line on PV-P75 and PCS-P125, two on PV-P100/110 and PCS-P125-4W), and the four-wire build's 200 Ω DC precharge resistor (RFQ) has no estimate row | the module totals are lower bounds (PCS-P125-4W by three lines) | a price row for the TLV9024PWR and an estimate or quotation for the resistor | [bom/COST.md](../../bom/COST.md), [D-075](../requirements/DECISIONS.md), [D-076](../requirements/DECISIONS.md) |

## B · Safety and insulation

| ID | Priority | Risk | Consequence | What closes it | Source |
|---|:---:|---|---|---|---|
| B1 | **1** | **Standard values transcribed from memory** (IEC 60664-1, EN 62477-1, IEC 62109-1/-2, CISPR 11, grid codes); whether a surge arrester may be credited for reinforced insulation is not verified against the standard text. Since [D-079](../requirements/DECISIONS.md) / [D-080](../requirements/DECISIONS.md) the inverter's ride-through profile and its declared off-grid transient envelope are also set against classes recalled from memory — the envelope (requirement AC-04) *is* the ITIC curve's points as remembered, the IEC 62040-3 classes 1–3 are not met in the first 5 ms and not claimed, the ride-through profile follows EN 50549-1 / VDE-AR-N 4105 / 4110 | barrier dimensions, the reinforced claim or the altitude rating could be wrong; a declared envelope or ride-through profile could miss the real class | buy the standards and check every value used in `sim/insulation.py` and `sim/pcs_control.py` | [D-032](../requirements/DECISIONS.md), [D-079](../requirements/DECISIONS.md), [D-080](../requirements/DECISIONS.md), R-12, [insulation report](../../sim/out/insulation/report.md) |
| B2 | **1** | **Gate-driver impulse rating** 6,250 V against the 8 kV reinforced requirement: the NSI6651 passes only with the 6 kV arrester credit of B1 | if a certifier refuses the credit, the driver fails the reinforced requirement | TI UCC21750 is the footprint-compatible fallback (all but two pins) | [D-043](../requirements/DECISIONS.md) |
| B3 | 2 | **Varistor thermal links have no DC rating** | a certifier may require the IEC 61643-31 end-of-life tests on the board | certifier's position, or the tests | [D-042](../requirements/DECISIONS.md) |
| B4 | 2 | **High touch current**: the capacitance to PE of the cost-first port filter puts about 11 mA into the protective conductor | the product needs the high-touch-current measures (PE ≥ 10 mm² Cu and a warning label); the insulation monitor settles more slowly | accepted in D-048; to be confirmed by measurement | [D-048](../requirements/DECISIONS.md) |
| B5 | 2 | **No rated safety function**: the external stop is single-channel with no SIL/PL claim; the controller sits at up to 1000 V from earth | a cabinet that needs a rated stop must open its own DC switching devices; service needs isolated tools | installation requirement, stated in the product documentation | [ARCHITECTURE-COSTFIRST §12](../requirements/ARCHITECTURE-COSTFIRST.md#12-what-the-lean-design-gives-up-plain-list-for-the-owner) |
| B6 | 2 | **Battery-port fault band**: currents of 0.95–1.3 kA are left to the upstream battery protection | an installation requirement the integrator must meet | stated as an installation requirement | [ARCHITECTURE-COSTFIRST §15](../requirements/ARCHITECTURE-COSTFIRST.md#15-changes-against-the-d-044-direction-where-i-refined-or-disagree) |
| B7 | 3 | **Terminal-short survival given up**: a bolted short at a port's terminals probably destroys that port's legs; the module fails without fire and is repaired | repair, not a hazard | accepted in D-044 | [D-044](../requirements/DECISIONS.md) |
| B8 | 3 | **Heatsink temperature probes** bridge the live control and the earthed heatsink | basic insulation unproven at the probe | a probe with a stated lead-to-lug test voltage of at least 2.2 kV rms | R-10 |
| B9 | 2 | **Port A making current** (R-04): the PV port has no precharge; K_A closing onto the empty 290 µF bank at the array's V<sub>oc</sub> makes about 499 A (estimate) against a published making rating of 140 A at 20 V only. The port A declaration ([D-072](../requirements/DECISIONS.md)) therefore admits a current-limited PV array only (I<sub>sc</sub> ≤ 168.8 A, V<sub>oc</sub> ≤ 1000 V, ≤ 1.1 µF behind ≥ 11 µH), and with port B live the converter precharges bank A to within 20 V first; a stiff DC source on port A (about 7.4 kA peak) and reverse power into an array are not admitted | a contact weld on a PV-only start at high V<sub>oc</sub> | Hongfa's making rating at 1000 V; until then the declaration and the precharge-first rule | R-04, [D-072](../requirements/DECISIONS.md), [PV-PWR design check](../../hardware/PV-PWR/outputs/PV-PWR_design_check.txt) |
| B10 | 3 | **The insulation barrier audit stops on the new boards**: `sim/insulation.py` has no domain map for PV-CTL, PCS-PWR, PCS-PWR-4W, PCS-CTL, PORT-LEAN and PORT-LEAN-HOLD and its PV-PORT IMD-switch override no longer matches the drawn pair; a run ends with 98 problems and a non-zero exit (pre-existing tooling item, not raised by the reviews; 102 before D-081 took PVCELL-25's DESAT strings from three diodes to two) | the single barrier table does not cover the cost-first and inverter boards, although each board checks its own barrier parts in its design check | add the domain maps, fix the override, re-run | [08 · Verification](08-verification.md) |
| B11 | 3 | **Grid tap ties DC− to the grid** (both inverter builds, [D-074](../requirements/DECISIONS.md)): with the grid present the tap's lower diodes clamp DC− to the most negative phase, so the insulation monitor's reading is valid only with the AC side de-energised, and the DC link is fed from the AC side with the battery disconnected | a wrong insulation reading if the sequence is not followed; a live DC link with the battery isolated | declared: installation sequence, a firmware "not measurable" state and the label "two sources — isolate AC and DC; wait 15 min" | [09 · PCS-P125](09-pcs-p125.md#-start-up-from-the-grid) |

## C · Power stage and gate drive

| ID | Priority | Risk | Consequence | What closes it | Source |
|---|:---:|---|---|---|---|
| C1 | **1** | **False turn-on margin** of the paralleled SiC gates rests on an estimated loop inductance and ringing | a parasitic turn-on at the extreme corner (high voltage, high current, hot) | the double-pulse test — the first bench item | [D-028](../requirements/DECISIONS.md), [D-043](../requirements/DECISIONS.md) |
| C2 | **1** | **Short-circuit withstand** of the Chinese SiC devices is assumed (no maker publishes one). The DAB study's chain is corrected ([D-068](../requirements/DECISIONS.md)): the driver's deglitch is inside its DESAT-to-output delay, and in a short the current falls with the gate voltage, so the energy-equivalent full-current time is 1.112 µs = **0.99 × the assumed 1.12 µs hot withstand** (fault energy 1.09 J per device); the 2 × rule needs 0.50 and no lever inside the NSI6651 reaches it (best 0.61). The PV and PCS gate-drive presets print the same acceptance rule (PCS: t<sub>SC</sub> ≥ 2.03 µs, E<sub>SC</sub> ≥ 0.80 J at 1050 V; PV: 2.19 µs, 0.91 J at 1100 V — with the 1,300 V DESAT diodes of [D-081](../requirements/DECISIONS.md); they were 2.07 µs / 0.82 J and 2.10 µs / 0.87 J). Since [D-078](../requirements/DECISIONS.md) (R2-07) the inverter keeps the pulse rating apart from survival: I<sub>D(pulse)</sub> 188 A per device for 100 µs is a thermal on-state rating that bounds a fault under load up to the DESAT detection (≤ 140 A per device); short-circuit survival stays a REQUIRES-HARDWARE-TEST release gate, never closed on paper | a shoot-through at 1000 V and 150 °C may destroy the devices (the fuse clears) | release block: for the DAB devices maker-confirmed t<sub>SC</sub> ≥ 2.22 µs at 1000 V / 150 °C (about 4.0 µs at 800 V / 25 °C) and E<sub>SC</sub> ≥ 2.18 J per device, the presets' figures for PV and PCS — or a short-circuit test on samples, or a device with a published withstand | [D-041](../requirements/DECISIONS.md), [D-068](../requirements/DECISIONS.md), [dab_design report §0.1](../../sim/out/dab_design/report.md), [PCS-PWR design check](../../hardware/PCS-PWR/outputs/PCS-PWR_design_check.txt), [GDRV-HB design check](../../hardware/GDRV-HB/outputs/GDRV-HB_design_check.txt) |
| C3 | 2 | **Six paralleled TO-247 devices per switch** in the inverter: static sharing is now bounded by an incoming acceptance rule (F4), dynamic sharing and the per-pair decoupling layout remain requirements, not results | one device runs hot; derating | layout extraction; double-pulse test | [D-053](../requirements/DECISIONS.md), [D-067](../requirements/DECISIONS.md) |
| C4 | 2 | **Common-mode transient margin** of the gate-drive channel: 150 V/ns rated against 124 V/ns calculated (× 1.21) | false trips or corrupted gate commands if the slew rate is higher than calculated | measurement on the first board | [PV-PWR design check](../../hardware/PV-PWR/outputs/PV-PWR_design_check.txt) |
| C5 | 2 | **Inductor-current sensor**: no dv/dt immunity figure at 124 V/ns | false or missed over-current trips | sensor data or a bench dv/dt test | R-07 |
| C6 | 3 | **Cosmic-ray failure rate** of the 1700 V devices: no maker curve; the 0.67 voltage rule is applied by scaling another maker's data | the failure-rate argument behind the device choice is an inference | maker data | [D-007](../requirements/DECISIONS.md), [pcs_design report](../../sim/out/pcs_design/report.md) |
| C8 | 2 | **Hardware over-current window** 67.9–80.5 A since the comparator's common-mode term is in it (was 68.9–79.9 A): its lower edge is 9.1 % above the 62.3 A normal peak (calculated) | nuisance trips at full current with every tolerance stacked | see C9 — the window's margin is now C9's open item | [D-058](../requirements/DECISIONS.md), [D-072](../requirements/DECISIONS.md), [PV-CTL design check](../../hardware/PV-CTL/outputs/PV-CTL_design_check.txt) |
| C10 | 2 | **Inverter turn-off at the trip's gates-off current** ([D-078](../requirements/DECISIONS.md), R2-02). The window trip turns the gates off at 520.5 A, not at the 485.5 A window top (3.54 µs chain on the L1 envelope, calculated); with R<sub>G,off</sub> raised from 7.5 to 8.75 Ω the leg deck peaks at 1,437 V against the 1,445 V limit (1,438 V at the over-voltage corner) and admits up to 533.6 A. The deck takes the bus and board inductance as 1.5 × an estimate; 8.75 Ω is not an E96 value (8.66 Ω would cost about 1.4 V of the 7.7 V margin) | a layout with more loop inductance than assumed would exceed 0.85 × V<sub>DSS</sub> at the trip | the layout's loop inductance extracted, or a double-pulse test near 520 A / 1,050 V; the resistor value fixed with the supplier | [D-078](../requirements/DECISIONS.md), [pcs_design report (e)](../../sim/out/pcs_design/report.md), [PCS-PWR design check](../../hardware/PCS-PWR/outputs/PCS-PWR_design_check.txt) |
| C11 | 3 | **Trip assumptions without maker data** ([D-078](../requirements/DECISIONS.md)): Sichain publishes no turn-off SOA — its switching data stop at 70 A per device, while the window trip turns off about 95 A on the hottest device; the TLV9024 delay is taken as 2 × typical (no maximum is published) and the sensor's 2 µs step as a pure delay; the CMPSS backup band (423.9–497.5 A as drawn, DAC ±1,075 codes) sits 6.6 A inside the 417.3–504.1 A requirement on stated DAC gain / INL, reference, resistor-drift and sensor errors | a slower comparator or a larger error moves the gates-off current toward the 533.6 A ceiling | a turn-off SOA statement from Sichain; comparator samples timed; the DAC setting checked against the idle null by the start-up self-test | [PCS-CTL design check](../../hardware/PCS-CTL/outputs/PCS-CTL_design_check.txt), [pcs_spec.json](../../sim/out/pcs_design/pcs_spec.json) `protection_chain` |
| C9 | 2 | **Comparator common-mode term: in every band now, the margin rule missed.** Since [D-072](../requirements/DECISIONS.md) every TLV9024 band on PV-CTL and PCS-CTL carries the common-mode error at the guaranteed 50 dB (3.3 V is unspecified; 0.98 A / 0.51 A at the inductor window) and the data-sheet delay at the real overdrive: the window is 67.9–80.5 A / 1.52 µs and misses the project's 1.10 × normal-peak floor (68.5 A) by 0.58 A, because the fixed error terms (5.84 A) exceed the corridor's half-width (5.69 A) — no ladder value restores it. Kept as drawn with a 1.09 margin and an [OPEN] line. The sensor's reference output still has no published drive rating or drift (63 µA drawn) | a nuisance trip at the worst ripple corner with every tolerance stacked, not a hazard; the top stays 0.7 A below the 81.1 A backup | the TLV9024's CMRR measured ≥ 60 dB at 3.3 V on samples plus 10 ppm/K ladder resistors (0.74 USD) give 68.8–79.8 A, which fits; the maker's data for the reference output | [D-058](../requirements/DECISIONS.md), [D-072](../requirements/DECISIONS.md), [PV-CTL design check](../../hardware/PV-CTL/outputs/PV-CTL_design_check.txt), PCM-19 |
| C12 | 3 | **The 1,200 V-class DESAT string was not re-rated** ([D-081](../requirements/DECISIONS.md)): the DAB-D60 / GDRV-HB presets keep 3 × US1MH (3,000 V); one 1,000 V diode alone holds × 0.95 of the DAB port-1 over-voltage band peak (1,048 V), and the dynamic share is 600 V of the 1,400 V trip-corner requirement (× 1.67) — marked OPEN in the check | the same sharing question E01 raised for the inverter, on a board that is kept and not developed further ([D-044](../requirements/DECISIONS.md)) | when that board is developed: the 1,700 V-class string (2 × BYG23T-M3/TR) is the drop-in | [GDRV-HB design check](../../hardware/GDRV-HB/outputs/GDRV-HB_design_check.txt), [D-081](../requirements/DECISIONS.md) |

Closed: **C7**, load rejection on the drawn power board, by [D-058](../requirements/DECISIONS.md) — the three-phase
board's battery-side film bank now has seven capacitors, 315 µF against 278.5 µF needed (calculated,
[module_spec.json](../../sim/out/pv_design/module_spec.json)); the re-based control model needs 243 µF
([D-065](../requirements/DECISIONS.md)). Closed by the review round: the leg commutation with the KEMET-era capacitor
values (R-08, its ESL part) — re-run with the drawn Jianghai parts, 1,374 V worst against 1,445 V
([D-072](../requirements/DECISIONS.md)). Closed by the re-check R2 ([D-078](../requirements/DECISIONS.md)): the
inverter's leg deck, which still carried the KEMET film values and chose R<sub>G,off</sub> at the 450 A window nominal
(R2-02) — it now runs the drawn Jianghai parts at the trip chain's gates-off current (C10). C9 stays as it is: the
re-check classified it *Improvement Recommended* (R2-11), a test gate, not a drawing change.

## D · Magnetics and thermal

| ID | Priority | Risk | Consequence | What closes it | Source |
|---|:---:|---|---|---|---|
| D1 | 2 | **Magnetics are calculated only.** The two models (OpenMagnetics and our own) disagree by 27 % on a flat wire's copper loss; the PV inductor's hot spot is 145 °C against a 155 °C limit at the worst point; thermal networks are estimates | losses and temperatures can be higher than designed | a wound sample with calorimetric loss and a thermal run | [D-054](../requirements/DECISIONS.md), [magnetics report §7](../../sim/out/magnetics/report.md) |
| D8 | 2 | **Magnetics tool data fault.** OpenMagnetics' data for the amorphous core material gives a permeability of 1 at 20, 24 and 30 kHz, so it modelled an air core there and flattered every amorphous inductor at those frequencies; only a change of the inverter's design point exposed it, when the script's own inductance differed from the tool's by a factor of 300 | every amorphous-core result at 20–30 kHz from before the fix is void: with the core modelled properly the 24 kHz inductor of D-059 loses 263 W instead of 165 W and reaches 198 °C against its 140 °C limit | the trade study is re-run (D-060); the script compares its own inductance with the tool's (limit 15 %) and now checks that its design files equal the study's selection; a wound sample with calorimetric loss decides | [D-060](../requirements/DECISIONS.md), [magnetics report](../../sim/out/magnetics/report.md) |
| D2 | 2 | **DAB loss gap**: Wolfspeed's own measurements show about 2.5 × the loss our model gives; DAB-04 (99.2 % peak) is not claimed | derating at full power, or a transformer redesign | calorimetric loss split on the bench | [D-015](../requirements/DECISIONS.md), [dab_design report §13](../../sim/out/dab_design/report.md) |
| D3 | 2 | **PV-P100/110 is a derated build on the cost-first boards**: full power only up to 35 °C inlet (92 % at 45 °C), and on the 145 A lean battery port 100 kW needs at least 690 V A→B and 697 V B→A (PV-P110: G3) | the four-phase build cannot be offered at the PV-P75's conditions | a litz-wound inductor (about +17 USD per phase) or more airflow; a 180 A port | [D-056](../requirements/DECISIONS.md), [module_spec.json](../../sim/out/pv_design/module_spec.json) |
| D6 | 2 | **Altitude: declared 2,000 m** ([D-075](../requirements/DECISIONS.md)). The control board's barrier B1 gives 8.0 mm clearance where 9.2 / 10.4 / 11.9 mm are needed at 3,000 / 4,000 / 5,000 m; it sets the ceiling, not the thermal model. Thermal: PV-P75 holds 86 / 79 / 70 % at 2,000 / 3,000 / 4,000 m and 45 °C inlet, the round-wire inductor's hot spot (144.7 °C against the 146.1–153.9 °C trip band) being the limit; the inverter has no altitude model. Megarevo publishes full rating to 3,000 m (PMD-75-G3) and 5,000 m with derating (PMA0125) | no high-site offer; two comparison rows below | the specified option: 15 mm (WW) isolators (+1.53 to +3.02 USD per board), AUX-T1 at ≥ 9.2 mm / 10.4 kV impulse, SELV connectors ≥ 9.2 mm from live copper — 3,000 m full, 5,000 m derated; a port-SPD credit to 4,000 m needs an effective level ≤ 4.0 kV and the standard's text (B1); thermally the remedies of D3 | [D-054](../requirements/DECISIONS.md), [D-056](../requirements/DECISIONS.md), [D-075](../requirements/DECISIONS.md), [PV-CTL design check](../../hardware/PV-CTL/outputs/PV-CTL_design_check.txt) |
| D7 | 3 | **Standby** 22.4 W with both contactors held at 1000 V against Megarevo's < 20 W (12.7 W with them open; 9.1 / 16.3 W at 600 V; estimate). It rose from 11.4 / 21.0 W when the control board's SELV logic grew to 1.44 W in standby (Ethernet not fitted) and the auxiliary was re-rated ([D-075](../requirements/DECISIONS.md), [D-076](../requirements/DECISIONS.md)); PV-P100/110's held case at the stack of maxima is 20.13 W (printed as a note, R-18) | a published figure 2.4 W worse in one state | open the PV contactor in standby, or lower the hold power | [D-056](../requirements/DECISIONS.md), [D-058](../requirements/DECISIONS.md), [D-076](../requirements/DECISIONS.md), [module_spec.json](../../sim/out/pv_design/module_spec.json) |
| D4 | 3 | **EMI**: emission estimate against limits recalled from memory | one or two more cores, or a wound choke (+20–30 USD) | early pre-compliance scan; buy CISPR 11 | R-11 |
| D5 | 3 | **Gate-bias transformer** is a new custom part (partial-discharge-free between secondaries, ≤ 5 pF) | gate-rail or false-turn-on margin | samples with a partial-discharge test | R-06, [D-048](../requirements/DECISIONS.md) |
| D9 | 3 | **DAB series-inductor saturation (MG-15).** The requirement rose to 700 A (1.1 × the 632 A trip fault peak of the corrected DR-03 chain); the rev M1 three-turn construction reaches 0.405 T = 0.99 B<sub>sat</sub> at 100 °C against the 0.8 check limit, on a typical B<sub>sat</sub> value | about 10 % margin to saturation in a fault | four turns on the same 4 × EE80: 0.74 B<sub>sat</sub>, 106 W worst (three turns 90 W) — decided in the DAB cost round (rev M2) — or a measured L(I) to 700 A at 100 °C | [magnetics report §6](../../sim/out/magnetics/report.md), [D-068](../requirements/DECISIONS.md) |
| D10 | 3 | **Auxiliary transformer re-wound** for AUX-75 rev A3 ([D-076](../requirements/DECISIONS.md)): turns 50:9:10 on the same EC39A core, current sense 3 × 0.866 Ω. Only about ±0.5 % of nominal L<sub>p</sub> works with that E96 value (the chosen low-ohm series must carry it); flux margin 5.7 % (10 % would need a larger core), drain margin 3.1 % at 1000 V; the design file's basis is the previous specification (values identical) | the re-rated live 30 W / 48 W rests on calculation | a new sample set: L<sub>p</sub>, both leakages, switched capacitance, partial discharge | [D-076](../requirements/DECISIONS.md), [aux75_spec.json](../../sim/out/aux_hv_design/aux75_spec.json) |
| D11 | 2 | **The inverter's L1 beyond 450 A** ([D-078](../requirements/DECISIONS.md), R2-03). The construction table used to end at 450 A; the trajectory to 700 A (141 points; hot, −10 % and +5 % parts) puts the flux-rule current at 566 A and the hot knee of the +5 % part at 578 A; OpenMagnetics' saturation figure gives about 553 A, and the knee rests on a hot saturation flux of 1.40 T that is an estimate (the tool's figure for 2605SA1 is 1.35 T). The CMPSS backup band was lowered so that every gates-off current stays below the knee (ceiling 533.6 A); a core holding the flux rule to 650 A (+32 / +27 USD per three-wire module) was not taken | a softer core than calculated moves the knee toward the trip's gates-off current; above the knee only DESAT stops a fault | the first-article type test: L(I) to 600 A pulsed, at 25 °C and with the core at ≥ 100 °C, accepted at or above the envelope up to 566 A | [spec_pcs_l1.md §2a](../../sim/out/magnetics/spec_pcs_l1.md), [D-078](../requirements/DECISIONS.md) |

## E · Control and firmware

| ID | Priority | Risk | Consequence | What closes it | Source |
|---|:---:|---|---|---|---|
| E1 | 2 | **PCS-P125 control is calculated, not switched or measured** ([D-066](../requirements/DECISIONS.md), [D-077](../requirements/DECISIONS.md), [D-079](../requirements/DECISIONS.md)): an αβ PR current loop on the converter current, crossover 1,750 Hz on a stiff grid inside a usable band of 1.0–3.25 kHz; with the drawn R<sub>d</sub>–C<sub>d</sub> branch PM ≥ 48.5° and GM ≥ 12.1 dB from stiff to SCR 5 at the named corners, and since R2-01 a 1,944-case mixed-tolerance factorial plus 1,000 random cases at the assembly's tolerances (C<sub>f</sub>, C<sub>d</sub> ±10 %, R<sub>d</sub> ±5 %): all meet the rule, worst PM 48.10°, worst GM 11.82 dB (rule 40° / 6 dB); THDi 1.5–2.2 % estimated with an assumed background distortion. Off-grid: voltage accuracy 0.59 % worst-case sum, frequency ±60 ppm, THDu 1.39 % / 2.11 % (three- / four-wire, analytical), imbalance ±0.41 % / ±0.76 %, the neutral-leg cascade PM 55°, GM 8.2 dB; full-load steps on the bounded averaged model 0.43 / 1.77 pu at the worst corner, inside the declared envelope — since [D-080](../requirements/DECISIONS.md) the ITIC-style points of requirement AC-04, cleared by +0.054 pu at the tightest point (the D-079 envelope, chosen to contain the simulation, and the 0.38 / 2.17 pu of D-077's unbounded model are superseded). The DC over-voltage limit at gates-off is now derived from the leg deck, 1,445 − 367 = 1,077 V (was the board's own 1,087 V), and the firmware ADC-PPB backup was lowered to 1,035 V (1,019–1,051 V) | no switched model, no measured THD or transient, no standards text (grid-code limits from memory), anti-islanding not simulated (IEC 62116 not claimed); not modelled: paralleled modules' restoration consensus, a switched neutral leg, the per-phase virtual reactance, mode B, droop and the PLL in the coupled four-wire cases, LVRT reactive-current injection | a switched simulation of the chosen loops; the first-millisecond excursion measured against the declared envelope at every corner; the standards bought; then the bench | [D-066](../requirements/DECISIONS.md), [D-077](../requirements/DECISIONS.md), [D-079](../requirements/DECISIONS.md), [D-080](../requirements/DECISIONS.md), [pcs_control report](../../sim/out/pcs_control/report.md) |
| E2 | 3 | **Firmware duplicates every hardware protection** and owns sequencing; a firmware error ends in a DESAT trip, a blown fuse or a watchdog reset | a damaged or stopped unit, not a hazard (by design) | the firmware safety-requirement list, with a start-up self-test of each trip path (firmware is out of scope here) | [D-050](../requirements/DECISIONS.md) |
| E3 | 3 | **Controller budget**: F280039C at 120 MHz — PV four phases untimed (R-14); the inverter's ISR is estimated at 4.8–5.8 µs = 31–37 % of its 15.6 µs period, 46.7 % in the four-wire row (operation count, cost model assumed), on 21 of 23 analog pins (22 for four-wire) and 6 (8) of 16 PWM outputs | control timing or a larger part (F28P550SJ, +0.39 USD) | a firmware timing measurement on the target | R-14, [pcs_control report §9](../../sim/out/pcs_control/report.md), [D-064](../requirements/DECISIONS.md), [D-077](../requirements/DECISIONS.md) |
| E4 | 3 | **PV outer-loop phase margin** 44.3° (three phases) / 45.0° (four) at the 250 V constant-power-load corner on the drawn port banks (rule of thumb 45°; modulus margin 0.67 / 0.66) | adequate, with less margin than usual | the inverter's own DC link raises it | [D-065](../requirements/DECISIONS.md), [pv_control report §5, §13](../../sim/out/pv_control/report.md) |
| E5 | 2 | **DC/DC-to-inverter link coordination.** The inverter's DC link that a DC/DC sees is 0.41 mF (the DAB control study had assumed 4 mF): at SCR 5 a 125 kW DC/DC load step collapses the bus and a 125 kW DC/DC trip lifts it to 1,098 V on the loop alone; with the protection in the loop ([D-079](../requirements/DECISIONS.md), R2-04) the comparator turns the gates off at 1,001–1,068 V and the bus is left at 1,094–1,106 V, latched (at the band top 1 V below the auxiliary's 1,107 V input lock-out — thin). On a battery-less bus that the inverter forms off-grid, the PV module's coordination row (its current references to 0 within 209 µs of V_B rising 30 V above the set point) is mandatory ([D-080](../requirements/DECISIONS.md), R3-03). Since [D-081](../requirements/DECISIONS.md) (review R4, E04) the coupled model carries the inter-module cable (series R and L per PV module; ASSUMED harness of 2–20 m at 0.6–1.0 µH/m) and two PV source extremes: the cable adds up to +28 V, the PCS node peaks at 849–887 V from a 750 V set point and 878–914 V from 782 V, every corner below the 975 V soft limit. The window is a product rule: **default set point 750 V** (755 V for the four-wire build in mode A), a **782 V firmware clamp** in the PV module, no island start above **791 V** on a bus declared battery-less; the one-node 909 / 921 V and the cable model's 846 V are model validities, **not ratings** (64 V from the clamp to the worst case). The harness (≤ 20 m and ≤ 20 µH per PV run, DC+ and DC− together, loop resistance ≤ 12.6 mΩ, nothing else on the link, ≤ 2 PV-P75 per link) and the PV power on one link ≤ the inverter's DC power tier are installation conditions. Without the row the comparator trips 1.50 / 1.94 ms after the step and the bus is left at 1,060–1,061 V, latched; with the PV firmware dead 1,126–1,130 V, above the auxiliary's 1,107 V lock-out — the island goes dark | an inverter trip, a dark island or a bus collapse on a weak grid | the trajectories are simulated on averaged models with an ASSUMED harness — its figures, capacitor ESR, the skin effect and the PV voltage loop are not credited, unequal run lengths are not studied; the bench confirms the peaks and the 209 µs cut; inside the enforced window no hardwired trip line is needed; the integrator holds the harness contract ([INSTALLATION.md](../requirements/INSTALLATION.md) INST-71, INST-76) | [D-079](../requirements/DECISIONS.md), [D-080](../requirements/DECISIONS.md), [D-081](../requirements/DECISIONS.md), [pcs_control report §7d, §7e](../../sim/out/pcs_control/report.md) |
| E6 | 2 | **Deep grid dips on a stiff connection — a firmware measure whose margin needs the bench.** [D-077](../requirements/DECISIONS.md) left the first-millisecond onset on a stiff grid (484 / 465 / 445 A at 0 / 0.1 / 0.2 pu against the 426 A window) to a pre-fault derating. Since [D-079](../requirements/DECISIONS.md) (R2-05, *Firmware Handled*) the ride-through state lowers the per-sample clamp to 270 A and predicts on the C<sub>f</sub> voltage with the divider's pole inverted: onset 382 A on a stiff 0 pu dip, 403 A at the worst corner and dip instant — **23.0 A** below the window's 426.0 A edge (rule ≥ 15 A) — and every peak ≤ 389 A from stiff to SCR 5 at 0–0.5 pu: rated current, no derating (simulated, averaged model). Since [D-080](../requirements/DECISIONS.md) (R3-02) the screen also takes the lower edge of the two hardware layers — the CMPSS backup's 423.9 A — and an ADC-noise term through the prediction (±1 LSB ASSUMED, 2.53 A worst case): **20.5 A** net to the window edge, **18.4 A** net to the backup's; the per-sample clamp outside the ride-through state is 378.0 A (was 380.1 A) | the margin rests on the averaged model's prediction and an assumed ADC noise; if a switched model or the bench shows less, the fallback applies: a grid-stiffness estimate (accuracy ASSUMED ±30 %) engages the derating 94.5 / 104.5 / 114.0 / 124.0 kW at 0 / 0.1 / 0.2 / 0.3 pu (was 95.5 / 105.5 / 115 kW) at an estimated SCR ≥ 61.7 (was 64.5) | the bench and a switched model confirm the margin; under the fallback the installation declaration applies — below 7.71 MVA fault level per 125 kW module no derating (was 8.07 MVA; n modules at one point: the point's fault level / n) | [D-077](../requirements/DECISIONS.md), [D-079](../requirements/DECISIONS.md), [D-080](../requirements/DECISIONS.md), [pcs_control report §4c](../../sim/out/pcs_control/report.md), [INSTALLATION.md](../requirements/INSTALLATION.md) |
| E7 | 3 | **DAB sensor offset — closed as a firmware rule.** The DAB60 check allowed ±4 A of uncalibrated transformer-current offset while the flux loop nulls the measured DC, so an un-nulled offset became a real bias of up to about 32 mT that the 5 A DC trip cannot see | none once the rule is implemented | FW-DAB-11: transformer- and branch-current offsets nulled at idle, a null outside ±4 A is a sensor fault ([D-071](../requirements/DECISIONS.md)); proven only when firmware exists | [D-071](../requirements/DECISIONS.md), [REFERENCE-LESSONS §6](../requirements/REFERENCE-LESSONS.md) |
| E8 | 3 | **Ethernet bridge CH9121T** ([D-075](../requirements/DECISIONS.md)): its supply current is published as typical only (× 1.3 assumed); LCSC showed 1,155 in stock; its LAN set-up tool cannot be disabled, so the firmware must authorise every write; one TCP client per port is assumed; the 25 MHz crystal's ageing reaches the 40 ppm limit near end of life | a supply-budget miss, a supply shortage, a configuration path that bypasses the firmware | a stock check before ordering, a measured supply current, the authorisation rule in firmware | [PCS-CTL design check](../../hardware/PCS-CTL/outputs/PCS-CTL_design_check.txt) |
| E9 | 3 | **No spare GPIO on the inverter's controller**: 55 of 55 used (the four-wire build needed none); a second firmware-read dry-contact input (the competitor's DI2) or a readable ready input would need a 56th | a later addition costs a function | take the HOLD read-back (the firmware can mirror it from IB_H) or a PCS-only line | [D-075](../requirements/DECISIONS.md), [pcs_ctrl_pin_plan.csv](../../gen/data/pcs_ctrl_pin_plan.csv) |
| E10 | 3 | **Thin control-board margins** ([D-075](../requirements/DECISIONS.md)): the status relay picks up at 4.66 V needed against 4.79 V at the coil at 85 °C with an assumed ≤ 3 Ω driver; the live +3.3 V rail is at 188 of 200 mA (94 %) | a relay that does not pick up hot; no room on +3.3 V | measure on the first board | [PV-CTL design check](../../hardware/PV-CTL/outputs/PV-CTL_design_check.txt) |
| E11 | 3 | **AC-start and synchronised-close residuals** ([D-079](../requirements/DECISIONS.md), R2-14; [D-080](../requirements/DECISIONS.md), R3-01). The AC start is part of the executed, fault-injected state machine (35 fault cases, no breach with the repairs H1–H5 and the own AC_STOP state); since D-080 the synchronised close of the DC-side start also closes one coil at a time (SYNC → SYNC_CLOSE_K2 → SYNC_CLOSE_K1; 24 fault runs over the grid and dead-bus starts, no breach), and the machine has 19 states and 15 invariants, all 646 state-event pairs passing. Left open: DC_MATCH stays in the transition table although the repaired start never enters it; the H2 numbers (2 s window, 0.2 % decay, 10 V below the tap peak) live in the executed code, not yet in the JSON; RECTIFY with a battery present has no DC-match timeout; H3 is checked at the coil command — a sag during the 100 ms pull-in is not among the 35 cases; relay timings and the 40 W auxiliary draw are ASSUMED; for the close also the module's synchronisation model, the path check after K1 (a small active-power step in grid-connected grid forming — an ASSUMED method) and the timeouts | a start-up or close path outside the checked set | the H2 numbers into the hand-over JSON, a DC-match timeout, a sag-during-pull-in case; relay and coil data from the RFQ; the synchronisation and the path check on the bench | [D-079](../requirements/DECISIONS.md), [D-080](../requirements/DECISIONS.md), [pcs_control report §9d, §9e](../../sim/out/pcs_control/report.md) |
| E12 | 2 | **Four-wire bolted output short: a firmware margin to the backup band** ([D-080](../requirements/DECISIONS.md), R3-02). With both trip layers replayed on their own signals (sensor delay and 200 kHz lag, board and node RC, the 32 kHz ripple up to 69.1 A peak-to-peak, each layer's threshold corners, the CMPSS 5-clock filter), the D-079 firmware let the CMPSS backup trip at the low plant corner (first peak 425 A against its 423.9 A edge). Adopted: a 270 A clamp for a 5 ms onset window on the shorted phase and the N leg — first peaks ≤ 351 A, hold 378.7 A, largest sensed peak 410.6 A, **13.3 A** below the backup's edge; no layer trips at any studied corner, the firmware trips at 200 ms, the healthy phases stay at 0.986–1.010 pu (simulated, averaged model with the ripple rebuilt) | the 13.3 A rests on the averaged model and a rebuilt triangle ripple (its exact shape and phase, the comparator's input noise and the N leg's own switching are not modelled); a unit outside the modelled bands trips in hardware — declared: latch, FAULT, no automatic clear after an over-current trip, a restart into a persisting short trips again, the third trip of a class within 10 min locks out (ASSUMED) | a switched model of the four-wire short and the bench; the backup band is not raised (D-078) | [D-080](../requirements/DECISIONS.md), [pcs_control report §9c-2](../../sim/out/pcs_control/report.md) |
| E13 | 2 | **The off-grid transient envelope: a declared output capability, not a load-compatibility claim** ([D-080](../requirements/DECISIONS.md), R3-05; reworded by [D-081](../requirements/DECISIONS.md), R4 E06; both *Improvement Recommended*). Requirement AC-04, adopted by delegation (D-051; the owner's instruction of 2026-10-07 to decide), declares what the module does on a 100 % load step: it stays inside the ITIC (CBEMA) curve's points as remembered — over 2 pu to 1 ms, 1.4 pu to 3 ms, 1.2 pu to 500 ms, 1.1 pu after; under 0 pu to 20 ms, 0.7 pu to 500 ms, 0.8 pu to 10 s, 0.9 pu after (FROM MEMORY). The simulated worst corner clears it by +0.054 pu at the tightest point (1.146 pu between 3 and 500 ms). The ITI curve describes the input tolerance of IT equipment at 120 V / 60 Hz, so meeting its points says nothing about what a 400 / 230 V load tolerates. Release sequence: grid-following qualified first; grid forming for managed island loads with an agreed voltage-time and interruption specification; general-purpose off-grid or UPS-like supply only once an output class and its test method exist. The IEC 62040-3 classes 1–3 (FROM MEMORY) are not met in the first 5 ms (1.77 against 1.3 pu) and not claimed | a load that needs a tighter class (UPS grade) or an island load without an agreed specification is not served; the margin is an averaged-model figure and the points themselves are recalled, not read | an agreed voltage-time and interruption specification per managed island; the owner's confirmation or change of AC-04; the ITIC and IEC 62040-3 texts on file; the first milliseconds measured at every corner of the drawn parts | [D-080](../requirements/DECISIONS.md), [D-081](../requirements/DECISIONS.md), [REQUIREMENTS.md AC-04](../requirements/REQUIREMENTS.md), [pcs_control report §7c](../../sim/out/pcs_control/report.md) |

## F · PCS-P125 specific

| ID | Priority | Risk | Consequence | What closes it | Source |
|---|:---:|---|---|---|---|
| F1 | 2 | **Three-wire version on an earthed-neutral grid**: the battery's capacitance to earth (assumed 1–20 µF) limits operation below about 680 V | an installation limit or a transformer | the battery data; the common-mode study | [D-053](../requirements/DECISIONS.md) |
| F2 | 2 | **Grid-code and safety clauses** (EN 50549-1, IEC 62109-2, GB/T 34120, IEC 62116) are quoted from memory; since [D-078](../requirements/DECISIONS.md) / [D-079](../requirements/DECISIONS.md) the residual-current monitor's trip thresholds, the reactive-current injection profile and the connection-code figures behind the ride-through declaration rest on them too, with the standard text as the gate | relay redundancy, residual-current monitoring, ride-through and anti-islanding details may change | buy the standards | D-053, [D-079](../requirements/DECISIONS.md), ARCHITECTURE-PCS R-07 |
| F3 | 2 | **The inverter's filter is 39 % of its BOM and powder-core inductors were not searched.** The filter is 443 USD and 39 kg of the 1,131 USD at 5,000 units; the inductor search covered gapped nanocrystalline and amorphous C-cores only, L1 runs at its 140 °C hot-spot limit at 60 °C inlet, and no inductor price is quoted. The exact frequency and inductance are not a firm result (the next two-level point is 11 USD away); the two-level choice is (148 USD below the cheapest compliant T-type) | powder block cores, which saturate softly and could be sized for the overload peak instead of the trip point, may be cheaper; a wrong inductor price moves the largest block; L1 has no thermal margin | add powder cores to the magnetics search before the filter is frozen; quotes against the rows of [RFQ-MAGNETICS.md](../requirements/RFQ-MAGNETICS.md) (RFQ-05 to RFQ-07: inductance at current, losses, insulation, temperature — not inductance and price alone); a wound L1 sample with a thermal run. The re-check R4 (E12) sets the order: magnetics quotations before reopening topology or frequency; the 48 kHz weight-sensitive candidate (−15.7 kg of filter, +25.7 USD at 5,000 units in the study) is recorded, not a qualified substitution | [D-060](../requirements/DECISIONS.md), [D-081](../requirements/DECISIONS.md), [tradeoff.md](../../sim/out/pcs_design/tradeoff.md) |
| F4 | 2 | **Six paralleled devices: acceptance rules and module grades whose feasibility is unconfirmed** ([D-067](../requirements/DECISIONS.md), [D-078](../requirements/DECISIONS.md)). *Matching:* R<sub>DS(on)</sub> of the six devices of a switch within ±5 % at V<sub>GS</sub> 18 V, 38 A pulsed, 25 °C; V<sub>GS(th)</sub> within ±0.25 V; one lot per switch — the hottest device then carries ≤ 1.08 × the mean and every 45 °C tier holds. *Absolute* (R2-07): the matching rule bounds the share, not the level, and the thermal model runs on typical R<sub>DS(on)</sub> — a switch of six 52 mΩ (data-sheet maximum) parts fails the 200 ms tier (9.68 V at 198 °C against the 6.39 V DESAT minimum), the 2-minute tier and 110 % continuous at 60 °C inlet; acceptance is therefore **R<sub>DS(on)</sub> ≤ 40.0 mΩ per device** in the same incoming measurement. *Grades* (R3-04, [D-080](../requirements/DECISIONS.md)): the result is a grade of the assembled module — **grade A** if every device passed, **grade B** otherwise (evaluated as six 52 mΩ devices per switch) — each with a full tier table over inlet 25–60 °C, 600–950 V DC, PF 1 and 0 and a cold or steady start. Grade A keeps the full tiers (198 / 216 / 259.2 A) to 45 °C and holds 198.0 / 216.0 / 242.9 A at 60 °C; grade B holds 196.8 / 207.5 / 207.5 A at 45 °C and 179.8 / 192.6 / 192.6 A at 60 °C (continuous / 2 min / 200 ms, steady start; no 110 % tier at 60 °C). The end-of-line test writes the grade's table into the controller's parameter set and the controller reports it with the module serial; no record = grade B (calculated; hot R<sub>DS(on)</sub> on the typical curve, ASSUMED). The single 209 A corner of D-078 is replaced. Since [D-081](../requirements/DECISIONS.md) (review R4, E05, *Already Fixed*) grade B's declaration states its honest rating: the 60 °C continuous limit 179.8 A is **124.57 kW** at PF 1 and 400 V (125 kW needs 180.42 A; the rated 180 A is 124.71 kW). The reviewer's preferred production strategy is this one — measure and pool the devices into grade-A and grade-B banks, bind the grade to the serial; the alternative, a supplier-guaranteed bin, is priced only as a sensitivity (0.50 USD per device = 18 / 24 USD per three- / four-wire module) | without the rules the data-sheet population takes 1.22 × the mean and 188 °C in the 45 °C 200 ms tier; the limit equals the data-sheet typical — the record estimates that a population centred on it puts about half the switches above the limit, and one such device makes the whole module grade B: no 200 ms tier above its 2-minute tier and, at 60 °C, no 110 % tier | Sichain's R<sub>DS(on)</sub> distribution or a ≤ 40 mΩ bin, with a price (RFQ) — it decides the grade mix; the integrator keeps the grade record with the module serial ([INSTALLATION.md](../requirements/INSTALLATION.md)) | [D-057](../requirements/DECISIONS.md), [D-067](../requirements/DECISIONS.md), [D-078](../requirements/DECISIONS.md), [D-080](../requirements/DECISIONS.md), [D-081](../requirements/DECISIONS.md), [pcs_design report (b), (e)](../../sim/out/pcs_design/report.md) |
| F5 | 3 | **Desaturation: re-coordinated with the overload, now re-rated for the link** ([D-067](../requirements/DECISIONS.md), [D-081](../requirements/DECISIONS.md)). Two diodes per channel since D-067 (three before), **2 × Vishay BYG23T-M3/TR, 1,300 V each,** since D-081 (review R4, E01; 2 × US1MH, 1,000 V, until then): each diode alone blocks the 1,130 V static envelope of an off switch (× 1.15; × 1.13 over the 1,150 V design value), the dynamic share is ≤ 867 V per diode (capacitances ±20 %, ASSUMED), no balancing network. Trip band 6.41–9.37 V (unchanged); at R<sub>G,off</sub> 8.75 Ω margin 1.07 at the 200 ms overload peak (66.2 A per device) at the predicted 162 °C junction, 1.00 at the 175 °C rating, 1.56 from a −30 °C inlet; a hard short is off 1.26 µs after it starts. The V<sub>F</sub> at the 0.35–0.65 mA DESAT current is extrapolated below the first published point (0.59–0.81 V per diode, ASSUMED) with an ASSUMED −2 mV/K; a switch of six data-sheet-maximum parts would reach 9.68 V at its own 198 °C junction, which the absolute acceptance rule of F4 handles ([D-078](../requirements/DECISIONS.md)); since [D-080](../requirements/DECISIONS.md) such a module is grade B, whose tier table is checked against the DESAT minimum at each inlet (6.31–6.45 V) | a nuisance trip of the 200 ms tier with maximum-R<sub>DS(on)</sub> parts — a protective stop, not a hazard. Not covered by either sharing rule: a stored-charge mismatch at the partner's turn-on after reverse conduction (the avalanche rating is the non-repetitive backstop); the BYG23T has no AEC-Q101 variant and LCSC showed 10,840 in stock against 60–160 k parts a year | measure the string's V<sub>F</sub> and the per-diode reverse split at temperature on a low-energy high-voltage set-up; creepage across one diode in layout (functional-insulation test route); a second source by RFQ | [D-061](../requirements/DECISIONS.md), [D-067](../requirements/DECISIONS.md), [D-081](../requirements/DECISIONS.md), [PCS-PWR design check](../../hardware/PCS-PWR/outputs/PCS-PWR_design_check.txt), [GDRV-HB design check](../../hardware/GDRV-HB/outputs/GDRV-HB_design_check.txt) |
| F6 | 3 | **The hardware dead time is above the study's 300 ns**: 185–510 ns at the gates, and a firmware dead band below about 433 ns is stretched (turn-off 156 ns at R<sub>G,off</sub> 8.75 Ω) | dead-time compensation and the THDi budget assume 300 ns | compensate with the measured value, not the hand-over's 300 ns | [D-061](../requirements/DECISIONS.md), [PCS-PWR design check](../../hardware/PCS-PWR/outputs/PCS-PWR_design_check.txt) |
| F7 | 2 | **Phase-current sensor frozen; the residual-current monitor is a contract without a part** ([D-067](../requirements/DECISIONS.md), [D-078](../requirements/DECISIONS.md)). Sinomags STK-250HO/4 (I<sub>PN</sub> 250 A, ±625 A linear, 3.2 mV/A on its own 2.5 V reference, 200 kHz, 2 µs maximum step, 4.3 kV rms / 8 kV impulse, > 8 mm creepage) is drawn with PCS-CTL's window at 426.0–485.5 A and, since D-078, the CMPSS backup at 423.9–497.5 A (risk C11); its maker states no working voltage, no qualification and no dv/dt immunity. No type-B part was found that carries ≥ 180 A per phase through three (four) conductors; since R2-13 the residual-current monitor has a frozen RFQ contract: type B, trips in firmware at ≥ 1,250 mA continuous within 0.3 s and at 30 / 60 / 150 mA steps within 0.3 / 0.15 / 0.04 s, ±2.0 A range, output 2.50 V + 1.00 V/A (0.5–4.5 V), sensor fault ≤ 0.25 V or ≥ 4.75 V within 100 ms, a 50 mA DC test input driven from GPIO21, 5 V ≤ 50 mA, apertures 27 × 19 / 30.5 × 18 mm — all ASSUMED (IEC 62109-2 class figures from memory) until a part is chosen; its output impedance (≤ 44 Ω for the fault window) belongs in the RFQ; candidate class Magtron RCMU101SN-3P50G-6C | the residual-current protection cannot be confirmed; the phase sensor's insulation rests on its impulse and creepage figures | a quotation with a data sheet for a monitor meeting the contract; the phase sensor's working voltage from the maker and a bench dv/dt test | [D-061](../requirements/DECISIONS.md), [D-064](../requirements/DECISIONS.md), [D-067](../requirements/DECISIONS.md), [D-078](../requirements/DECISIONS.md), [PCS-PWR design check](../../hardware/PCS-PWR/outputs/PCS-PWR_design_check.txt) |
| F10 | 2 | **AC contactors and their coils** ([D-067](../requirements/DECISIONS.md), [D-076](../requirements/DECISIONS.md), [D-078](../requirements/DECISIONS.md)): no OEM data. Since R2-06 one coil contract — **20 W pull-in for ≤ 100 ms, 4 W hold** — is the single constant behind the budget, the contactor BOM text and the self-check; the 24 / 5.5 W the auxiliary's rating would allow is printed only as margin to that contract (4 / 1.5 W). Budgets on the re-rated auxiliary (30 W live, 48 W for 1 s): synchronised close 38.9 W three-wire / 42.2 W four-wire (reserve 9.1 / 5.8 W), running 22.9 / 26.2 W (reserve 7.1 / 3.8 W). The AC surge arresters are not monitored | a coil above the contract eats the 4 / 1.5 W margin and, beyond it, browns out the auxiliary at the close; an arrester failure goes unseen | an AC coil module meeting 20 / 4 W (RFQ); monitor the arresters | [D-067](../requirements/DECISIONS.md), [D-076](../requirements/DECISIONS.md), [D-078](../requirements/DECISIONS.md), [PCS-PWR design check](../../hardware/PCS-PWR/outputs/PCS-PWR_design_check.txt) |
| F11 | 3 | **Thin discharge margin and a second failure.** With the full connected capacitance (409.4 µF on the bus plus C<sub>f</sub>, C<sub>d</sub> and the auxiliary bulk) the bleeders reach 60 V after 14.7 min worst case (13.3 min nominal) against the "wait 15 min" label; a shorted DC-link capacitor over-stresses the other half (1.58 × U<sub>N</sub> at 950 V) for about 20 ms until the DC contactor opens | the label depends on tolerances; a first failure may cause a second | measured capacitance and bleeder tolerances; the label stays at 15 min | [D-067](../requirements/DECISIONS.md), [pcs_design report (d)](../../sim/out/pcs_design/report.md) |
| F12 | 3 | **L-N surge on the four-wire build**: the path is two varistors in series, 2 × 1,240 V = 2,480 V at 150 A (8/20 µs) against the 4 kV OVC III rated impulse at 230 V; a 3+1 arrangement (L-N varistors and an N-PE spark gap) would halve it | surge stress on line-to-neutral loads | a GDT data sheet on file, then the 3+1 circuit (with B3's DC-rating question) | [D-074](../requirements/DECISIONS.md), [PCS-PWR-4W design check](../../hardware/PCS-PWR-4W/outputs/PCS-PWR-4W_design_check.txt) |
| F13 | 3 | **DC-component measurement**: the regulator holds the output's DC component at its measurement floor (0.56 V of the 1.15 V limit), but the ADC gain drift of the two channels is an open term | an offset above 0.5 % U<sub>n</sub> | VG<sub>x</sub> and VGN on one ADC module, or nulling at no load (firmware) | [D-074](../requirements/DECISIONS.md), [D-077](../requirements/DECISIONS.md) |
| F14 | 2 | **Inverter cold rating: full operation from −10 °C inlet** ([D-081](../requirements/DECISIONS.md), review R4, E11, *Confirmed*; REQUIREMENTS AC-02 amended by delegation). The fans are rated −10 °C. Modelled the PV way ([D-072](../requirements/DECISIONS.md); ESTIMATES ±50 %), the module without its fans holds 20 / 15 / 8 kVA (three-wire) and 14 / 7 / 0 kVA (four-wire) at 600 V DC and −30 / −20 / −10 °C inlet, 14 / 8 / 0 and 5 / 0 / 0 kVA at 650 V, 3 / 0 / 0 kVA (three-wire) at 700 V and standby only from 750 V: the L1 ripple loss and the devices' no-load loss exceed what the closed enclosure sheds (the PMA0125 body, ASSUMED), and the 75 °C heatsink NTC limit binds. Firmware rule: fans off below −10 °C inlet, the current limited to the table (standby with the gates off where it is 0), fans on at −10 °C or above or once any heatsink NTC exceeds 80 °C, a failed inlet NTC turns them on. 75 of the three-wire BOM's 128 orderable parts have no temperature-audit row | the PMA0125's −30 °C at power is not offered: below −10 °C standby or the passive table only — a stated limitation, not a silent rating ([standing restrictions](#standing-restrictions)) | a cold-rated 12 W fan (RFQ), worth adopting if it keeps the module within a few USD (the −30 °C fan on file adds 225–299 / 299–399 USD per three- / four-wire module and 2.2 × the fan power); a cold-chamber run of the passive table; the temperature audit extended to the inverter modules | [D-074](../requirements/DECISIONS.md), [D-081](../requirements/DECISIONS.md), [pcs_design report (d)](../../sim/out/pcs_design/report.md), [PCS-PWR design check](../../hardware/PCS-PWR/outputs/PCS-PWR_design_check.txt), [PCS comparison](../../sim/out/compare_megarevo_pcs/report.md) |
| F15 | 2 | **RFQ / CUSTOM parts without data sheets on the inverter**: the AC coil module, the 4-pole contactors, the type-B residual-current sensor (three and four conductors), the four-bar CM choke, the 220 Ω and 200 Ω precharge resistors (no pulse curve on file; the 200 Ω line is unpriced) | ratings, budgets and costs rest on class assumptions | requests for quotation with data sheets | [D-074](../requirements/DECISIONS.md), [D-076](../requirements/DECISIONS.md) |
| F16 | 3 | **Four-wire carrier ripple into a stiff grid**: 0.63 % of the rated peak at h640 at 950 V (three-wire 0.12 %, target 0.3 %; 0.04 % at SCR 50) | a pre-compliance finding on stiff connections | more L2 or the neutral leg's modulation | [D-074](../requirements/DECISIONS.md), [PCS-PWR-4W design check](../../hardware/PCS-PWR-4W/outputs/PCS-PWR-4W_design_check.txt) |

Closed on 2026-10-06 ([D-074](../requirements/DECISIONS.md)): **F8**, no start-up path from the AC side — both builds now
draw a grid tap (20 Ω + a 1.6 A / 500 V AC fuse per phase into six avalanche diodes, diode-OR into the auxiliary supply)
and an AC precharge (G7L-2A-X + 220 Ω on K_ACPRE), with a grid-start sequence in firmware ([09 · PCS-P125](09-pcs-p125.md#-start-up-from-the-grid));
**F9**, the four-wire build not drawn — PCS-PWR-4W and the four-wire assembly of PCS-CTL are drawn with a fourth
two-level leg (not a midpoint neutral), every check passes, and the neutral-leg loop was studied in
[D-077](../requirements/DECISIONS.md) ([09 · PCS-P125](09-pcs-p125.md#-the-four-wire-build-pcs-p125-4w)).

Resolved on 2026-10-07 by the re-check R2, where they stood: the stiff-grid pre-fault derating as the primary
ride-through measure (E6 — now the fallback behind the 270 A clamp, [D-079](../requirements/DECISIONS.md)); the AC start
outside the checked state machine (now executed with fault injection; residuals in E11); the unbounded 0.38 / 2.17 pu
off-grid transient (E1 — bounded at 0.43 / 1.77 pu, envelope declared); the two coil figures (F10 — one contract); the
CMPSS backup that could let the current run past the L1 knee (C11, D11 — band lowered on PCS-CTL,
[D-078](../requirements/DECISIONS.md)).

Resolved on 2026-10-07 by the re-check R3 ([D-080](../requirements/DECISIONS.md)), where they stood: the synchronised
close that commanded both AC coils at once (E11 — one coil at a time, the invariant without its exception); the
four-wire short screened against one trip layer (E12 — both layers replayed, a 5 ms onset clamp); the untied 50 µs DC/DC
stop (E5 — the coupled PCS / PV trajectory); the single-corner 209 A fallback for unscreened parts (F4 — two module
grades with full tier tables); the envelope chosen to contain the simulation (E13 — the ITIC-style points of AC-04). What
they leave open is in those rows.

Resolved on 2026-10-07 by the re-check R4 ([D-081](../requirements/DECISIONS.md)), where they stood: the DESAT string
whose 1,000 V diodes relied on unproven sharing (F5 — 2 × BYG23T-M3/TR at 1,300 V, each blocking the static envelope
alone); the one-node bus model without the cable and the 909 V figure read as a limit (E5 — the cable model, the
enforced 750 / 782 / 791 V window, the harness contract); the envelope read as load compatibility (E13 — a declared
output capability with a release sequence); the inverter's unmodelled cold start (F14 — the passive table, the firmware
rule and the −10 °C rating); grade B without a kW statement (F4 — 124.57 kW at 60 °C); the magnetics without an RFQ
index (A1, F3 — [RFQ-MAGNETICS.md](../requirements/RFQ-MAGNETICS.md)). What they leave open is in those rows and in
C12.

## G · Requirements the calculations contradict

Owner's decisions: the requirement file is not edited by the design work ([REQUIREMENTS.md](../requirements/REQUIREMENTS.md)).

| ID | Priority | Risk | Consequence | What closes it | Source |
|---|:---:|---|---|---|---|
| G1 | **1** | **AC-02 "full load from 600 V at 400 V ±15 %" is not reachable** with the stated margins (5 % loop headroom and dead-time compensation assumed): rated current needs 605–643 V DC at a 400 V grid depending on the power factor (624 V to connect) and 698–737 V at 460 V; 590–600 V DC serves grids up to about 360 V only; with the grid 10 % high, rated current needs 672 V (stiff) / 790 V (SCR 5) | the rectangular requirement cannot be met; the firmware refuses operating points below the map | the owner's requirement decision | [D-067](../requirements/DECISIONS.md), [pcs_design report (f)](../../sim/out/pcs_design/report.md), [pcs_control report §10](../../sim/out/pcs_control/report.md) |
| G2 | 2 | **PV-P75 at 550 V: PV-04 / PV-07 against PV-05 / PV-08.** 75 kW at exactly 550 V needs 136.4 A at the port before loss (138.1 A at the source with the module loss) against the 135 A rating — inconsistent by 1 %. The 135 A port carries 75 kW from 556 V; at 550 V × 135 A it carries 74.25 kW before loss, and the module delivers 73.3 kW at 550 / 550 V and its rating from 562 V at equal port voltages (both directions, 35 and 45 °C inlet). Since the re-check R4 (E07, *Not Applicable*: an arithmetic restriction, not a defect) the product tables state this current-limited corner explicitly — an [accepted limitation](#standing-restrictions) | the full-load range starts at 556 V on the port (562 V delivered), not 550 V | the owner's requirement decision; published as is | [D-065](../requirements/DECISIONS.md), [pv_control report §12.3](../../sim/out/pv_control/report.md) |
| G3 | 2 | **PV-P110's 110 kW is an input-side rating.** The 27.5 kW per-phase limit is held at the source (PV) node, so A→B the module delivers 108.8 kW and never 110 kW; B→A it delivers 110 kW only from 765 V and at 35 °C inlet. PV-P100 is rated from 690 V A→B / 697 V B→A; at 60 °C inlet no product reaches its rating | the 110 kW figure needs a qualifier | state 110 kW as a PV-input rating, or reference the per-phase limit to the delivered side (+1.0 % on the cells at the unity points ≥ 750 V, which the thermal derating then has to hold) | [D-065](../requirements/DECISIONS.md), [envelope.csv](../../sim/out/pv_control/envelope.csv) |

---

## Where the records disagree

Not risks to the product, but places where two records say different things today. Each is stated, not resolved. Five
disagreements found while documenting the re-check R2 on 2026-10-07 were resolved at their source by the re-runs of the
same day and are no longer listed: the trip-chain figures (D-078 now states the board's 3.542 µs / 520.5 A beside its
3.572 µs / 520.8 A), the firmware over-voltage backup (the hand-over prints 1,019–1,051 V, 34.0 µs), the uncoordinated
DC/DC figures (all records then printed 0.59–0.75 ms, 1,048–1,110 V — D-080 has since recomputed them to 1.50 / 1.94 ms and 1,060–1,061 V on the coupled model, and every record now carries those), the
CMPSS backup's status (every generated record now reads "adopted on PCS-CTL (D-078)") and the module parity register
(its R2 and R3 figures are aligned). Seven disagreements found by the 2026-10-05 documentation pass (DESAT band and hard-short response in D-067, the window edge in D-066, the pin-audit totals in D-070, the inverter thresholds in REFERENCE-LESSONS §6.2, the 400 A fuse sentence of the pcs_design report, the bandwidth statement) were resolved at their source the same day and are no longer listed. The documentation pass for the re-check R4 found one more resolved at its source and removed it: the PV short-circuit timing — the [pv_control report §9.3](../../sim/out/pv_control/report.md) now times 0.99 µs typical / 1.28 µs worst from the fault, the gate-drive check's blanking (276–861 ns) plus its 0.42 µs to the gates, with the deglitch inside the driver's delay as the [GDRV-HB design check](../../hardware/GDRV-HB/outputs/GDRV-HB_design_check.txt) has it.

| What | Record 1 | Record 2 | Status |
|---|---|---|---|
| PV-P75 cost in the register | D-052 records the cost of the drawn boards before the inductor change | [bom/COST.md](../../bom/COST.md) after D-054 | the register row is historical by design |
| PV inductor winding | D-048 chose edgewise flat wire | D-054 reverses it (the tool had been run on the wrong conductor) | settled by D-054 |
| Standby power | ≈ 15 W (ARCHITECTURE-COSTFIRST R-18); 12.6 / 22.3 W in [D-075](../requirements/DECISIONS.md) | 12.7 / 22.4 W at 1000 V for the module ([module_spec.json](../../sim/out/pv_design/module_spec.json), the comparison, [D-076](../requirements/DECISIONS.md)); 13.0 / 22.0 W in the power-board estimate ([PV-PWR design check](../../hardware/PV-PWR/outputs/PV-PWR_design_check.txt)) | all estimates; D-076 supersedes D-075's figure; the held case exceeds Megarevo's < 20 W (risk D7) |
| Inductor-current sensor | TMR sensors (ARCHITECTURE-COSTFIRST §0) | STK-HO/A 75 drawn on PV-PWR (design check) | the board is the later record |
| Inverter cost | the design study: 1,431 / 1,149 USD three-wire, 1,731 / 1,392 USD four-wire ([pcs_spec.json](../../sim/out/pcs_design/pcs_spec.json)) | the drawn boards: 1,589 / 1,349 USD and 1,926 / 1,636 USD ([bom/COST.md](../../bom/COST.md), as of 2026-10-07) | explained by D-063; both are shown and labelled |
| Inverter benchmark-equivalent BOM | ≈ 690 USD (ARCHITECTURE-PCS §12, AC-side current) | 744 USD ([bom/COST.md](../../bom/COST.md), gen/cost.py, 250 A DC-port current) | both quoted with their basis |
| DAB series-inductor saturation requirement | 700 A (D-068; dab report §13; magnetics check `lser_m1_b`) | 695 A = 1.1 × 632 A (dab report §0.1, DR-03 row); MG-15's recommendation and the magnetics report's cost section still say 635 A | these pages use 700 A |
| Classification counts of the re-check R4 | [D-081](../requirements/DECISIONS.md): 4 Confirmed, 4 Already Fixed, 2 Improvement Recommended, 2 Not Applicable | [review_r4.csv](../../gen/data/review_r4.csv): 3 Confirmed (E01, E04, E11), 4 Already Fixed, 3 Improvement Recommended (E06, E08, E12), 2 Not Applicable — D-081's text groups E08 with the already-fixed areas | the register is the per-row record; these pages use its counts |
| Status of R4 item E12 | [RFQ-MAGNETICS.md](../requirements/RFQ-MAGNETICS.md) (its badge and opening note): "item E12 open" | [review_r4.csv](../../gen/data/review_r4.csv): E12 closed, its closure being that page; D-081: "E12 Improvement Recommended, done" | the register wins; the RFQ page's wording predates the closure, and so do its module BOM totals (977.7 / 818.8 USD for PV-P75 and so on — 1 to 2.5 USD below the totals after the DESAT diodes of D-081) |
| DESAT diodes of the earlier platform's module BOMs | [bom/PV-P75-FULL_module_BOM.csv](../../bom/PV-P75-FULL_module_BOM.csv) and PV-P100-110-FULL (rolled up on 2026-10-05): 36 / 48 × US1MH on PVCELL-25, and the 2,836 / 2,275 USD built on them | the regenerated PVCELL-25 board ([PVCELL-25 design check](../../hardware/PVCELL-25/outputs/PVCELL-25_design_check.txt), `bom/PVCELL-25_BOM.csv`): 2 × BYG23T-M3/TR per channel, 8 per board (D-081) | the earlier platform is kept, not developed further; its module BOMs were not rolled up again |
| The inverter's cold rating in the parity register | [megarevo_2026_parity.csv](../../gen/data/megarevo_2026_parity.csv), PCS environment: "−30..+60 C declared (fans rated −10 C; the PV cold-start rule of D-072 applies, not yet modelled for the PCS)" | [D-081](../requirements/DECISIONS.md), REQUIREMENTS AC-02 and the [PCS-PWR design check](../../hardware/PCS-PWR/outputs/PCS-PWR_design_check.txt): full operation from −10 °C inlet, below it standby or the modelled passive table | the register's cells are edited by hand per decision and were not edited for D-081; the design check and D-081 are the later records |
| Small differences in today's register text | PM 56.4° / 1.4° (D-066); current-loop PM ≥ 57.6° (D-065); PV-P110 108.8 kW A→B (D-065) | 56.3° / 1.3° (pcs_control report); 57.5° for four phases (pv_control report); 108.75–108.99 kW at 750–950 V, 35 °C ([envelope.csv](../../sim/out/pv_control/envelope.csv)) | the generated reports are the records |

---

## 📐 Comparison summary

Both row-by-row comparisons, as their scripts print them (calculated against published; nothing measured), re-run on
2026-10-07 after the re-check R4 ([D-081](../requirements/DECISIONS.md)): the counts did not move. In the PCS table the
operating-temperature row now cites the inverter's cold rating of D-081 — full operation from −10 °C inlet, below it
standby or the passive table (20 / 15 / 8 kVA at 600 V DC and −30 / −20 / −10 °C for the three-wire build, an estimate)
— against the PMA0125's −30 °C; its verdict stays *below*. After the re-check R3 the overload and operating-temperature
rows had begun to print the 60 °C 200 ms tier as 243 A from the grade map (grade A's lowest over 600–950 V, 242.9 A; it
was 246 A, the 900 V point), and the re-check R2 had put the bounded off-grid transients (a 0 → rated step dips to
0.43 pu, rated → 0 overshoots to 1.75 pu, averaged model), THDu 1.39 / 2.11 % and the efficiency rows 98.98 % peak /
98.29 % at full load into the same table. The remedies of the rows below are in
[Comparison with Megarevo](11-megarevo-comparison.md) and in the risks named here.

| Comparison | Result line (generated) | Rows below the published figure | Risks |
|---|---|---|---|
| PV-P75 against the PMD-75-G3 ([report](../../sim/out/compare_megarevo/report.md)) | 2 better, 24 meets, 3 below, 5 not assessed, 0 pending, out of 34 published rows | operating temperature (fan rated −10 °C); operating altitude (79 % at 3,000 m, declared 2,000 m); standby 22.4 W with both contactors held | A4, D6, D7 |
| PCS-P125 / PCS-P125-4W against the PMA0125 ([report](../../sim/out/compare_megarevo_pcs/report.md)) | 2 better, 38 meets, 4 below, 9 not assessed, 0 pending, out of 53 published rows | operating and full-load DC window on 3W+PE (624 / 643 V against 590 / 600 V); operating temperature (full operation from −10 °C inlet since D-081, against −30 °C); altitude 2,000 m against 5,000 m | G1, F14, D6 |
| Module parity register ([megarevo_2026_parity.csv](../../gen/data/megarevo_2026_parity.csv)) | 32 rows; gaps closed by D-074 to D-080; the PCS cells aligned to the R3 figures on 2026-10-07 | altitude (option specified, not fitted); the inverter's cold side (its cell still reads "−30…+60 °C declared … not yet modelled for the PCS"; see below); the AC SPD-failure alarm and the residual-current sensor (still RFQ; its contract frozen by D-078) | D6, F14, F10, F7, F15 |

---

<!-- footer --> ← [Comparison with Megarevo](11-megarevo-comparison.md) · [Documentation index](../README.md) · [Repository guide](13-repository-guide.md) →

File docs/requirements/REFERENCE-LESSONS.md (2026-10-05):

# Lessons from recent TI reference designs (REF-2)

**Requirement:** REQUIREMENTS.md §7 REF-2 — "check out TI new designs like TIDA-010938 … make sure that we have everything".
**Status:** review of 2026-10-04, complete for the 14 designs and 2 application notes listed. **Honesty:** TI's numbers are
TI's lab measurements on their hardware; ours are calculated/simulated (nothing here is bench-validated). A TI design
removes unknowns, it does not set our ratings (REQUIREMENTS.md §6 rule 5).

Verdicts: **ADOPT** = change our design (where is stated) · **CONSIDER** = owner/designer decision, trade-off stated ·
**N/A** = not applicable (why). Only differences are listed; where TI does what we already do, nothing is written.
Citations: TI document id + page of the PDF on file under `docs/reference-designs/ti/<id>/`.

## 1. Designs reviewed

| id | what | doc (date) | relevant to |
|---|---|---|---|
| TIDA-010938 | 10 kW GaN string inverter + bidirectional battery DC/DC (2 × 5 kW PV boost, 2-phase interleaved buck/boost, HERIC inverter) | TIDUF64 Rev C (Jul 2026) + SLLA498 Rev A (Dec 2024) | PV cell, port sensing, IMD inputs |
| TIDA-010957 | 15–30 kW 3-phase+N three-level flying-capacitor converter, 650 V GaN on a 650–900 V link | TIDUFG9 Rev A (Mar 2026) + SDAA195 (Jan 2026) | 3-level PV cell option (D-031) |
| TIDA-010210 | 11 kW 3-phase ANPC, 600 V GaN on an 800 V link, CLB hardware interlocks | TIDUEZ0 Rev A (Mar 2022) | 3-level option, protection |
| PMP41037 | 1 kW 800 V → 12 V DCX with two 650 V GaN half-bridges in series, active voltage balancing | TIDT332 (2024) | stacked options, start-up |
| TIDA-010949 | 600 W GaN four-switch buck-boost PV power optimizer | TIDUF99 (Nov 2024) | PV cell modulation |
| TIDA-010054 | 10 kW SiC DAB (on file, re-read) | TIDUES0 Rev F (Apr 2026) | DAB-D60 |
| PMP23223 | UCC21732 + UCC14xxx-Q1 smart gate driver with bias | TIDT283 (May 2022) | GDRV-HB |
| PMP22817 | UCC5870/71-Q1 + UCC14240-Q1 gate driver and bias, 800 V | TIDT256 Rev A (Mar 2022) | GDRV-HB |
| TIDA-011011 | isolated gate driver + isolated bias for 3.3 kV SiC | TIDUFH7 (Mar 2026) | GDRV-HB (1700/2000 V devices) |
| TIDA-010232 | AFE for DC insulation monitoring (EV charging, solar) | TIDUEZ8 Rev D (Apr 2026) | PV-C5 IMD |
| TIDA-010985 | resistive-bridge IMD for 800 V with large Y capacitance | TIDUFG5 Rev A (Jan 2026) | PV-C5 IMD |
| PMP41009 | 350–1000 V in, 56 W quasi-resonant flyback | TIDT266 (Apr 2022) | AUX-HV |
| PMP41031 | 350–1500 V in, 150 W two-switch flyback, 4 outputs | TIDT355 (Oct 2023) | AUX-HV sizing (D-022) |
| TIDA-010955 | AFE for machine-learning DC arc detection (solar) | TIDUF85 Rev A (Dec 2024) | PV port (arc fault) |

## 2. Per-design findings

### TIDA-010938 — 10 kW GaN string inverter with BESS port (TIDUF64 Rev C, Jul 2026)
**What it is:** two 5 kW PV boost stages (50–500 V string → 400 V nominal / 520 V max link, LMG3522R030 650 V GaN +
C6D20065G SiC Schottky, 130 kHz, Bourns 145451 120 µH), a 10 kW bidirectional battery DC/DC (2-phase interleaved
synchronous half-bridges, 65 kHz per leg at 180°, 30 A, battery 50–500 V, Bourns 145452 200 µH per phase) and a 4.6 kW
HERIC/H-bridge inverter, all on one F280039C/F28P55x referenced to DC− (TIDUF64 p.1, p.5, p.16–18). Measured: boost
99.3 % (350→400 V, p.37–38), battery DC/DC 99.4 % peak (320 V↔400 V, p.39–41), 25–30 ns switching edges (p.37, p.41).

| # | TI does (doc p.) | We do | Verdict | Where / trade-off |
|---|---|---|---|---|
| 1 | Phase current by 1.5 mΩ shunt + AMC1302 **at each switch node**, powered from the GaN LDO (TIDUF64 p.19–20) | D-030 removed the switch-node shunt + AMC3302 from PVCELL (71–92 V/ns against a 95 V/ns minimum CMTI) | N/A | Confirms D-030: TI's nodes slew ≈16 V/ns (400 V in 25 ns, p.37), five times slower than our SiC legs |
| 2 | PV-array capacitance to PE "as high as 200 nF/kWp in damp environments" (TIDUF64 p.9; SLLA498 p.5) | `A_C_PV_PE` = 130 nF/kW × 75 kW = 10 µF (`sim/port_design.py`); IMD τ = 4.3 s | **ADOPT** | Use 200 nF/kWp as the worst case: 16.5 µF for PV-P75 (82.5 kWp), 22 µF for PV-P110 → IMD time constant ≈ 7 s instead of 4.3 s (≈ 21 s per state at 3τ) and the Y-capacitor / PE-current budget (port report §8, §10) |
| 3 | Controller referenced to DC−: non-isolated low-side drive, shunt + INA181 and op-amp dividers (TIDUF64 p.1, p.17–18) | PELV control card, reinforced isolation on every HV signal | N/A | 1000 V field-wired module with external comms and the dual-channel safety chain (D-012) on PELV; the isolator saving is small at 75 kW |
| 4 | Isolated CAN / RS-485 with integrated isolated power (ISOW1044, ISOW1412) (TIDUF64 p.1, p.28) | SYS-IO-AUX: ISO1042 / ISO1410 + one SN6505 push-pull + transformer + rectifier per port (4 sets) | CONSIDER | Removes ≈ 4 parts per port; check cost against the SN6505 set and the D-031 Asian alternatives (integrated-power isolated transceivers exist from Chinese makers) |
| 5 | MPPT stage is boost-only; TI states a buck or buck-boost MPPT stage "will be less efficient" (SLLA498 p.3) | buck **and** boost required (PV-10, PV-17) | N/A | Requirement-driven; it supports keeping the both-legs-switching band narrow (D_max 0.948, `sim/out/pv_control` §1) |
| 6 | HV auxiliary rail = non-isolated UCC28710 buck from the 520 V link (TIDUF64 p.22–23) | AUX-HV isolated flyback, 1700 V SiC, 200–1000 V | N/A | 520 V class, no isolation; not usable at 1000 V |

### TIDA-010957 — 3-phase+N three-level flying-capacitor converter, GaN (TIDUFG9 Rev A, Mar 2026; SDAA195, Jan 2026)
**What it is:** 4 flying-capacitor legs (3 phases + N), 16 × LMG3522R030 (650 V GaN, 15 kVA) or LMG3670R010 (25–30 kVA),
DC link 650–900 V (800 V nominal), 62.5 kHz per device / 125 kHz at the inductor (carriers 180° apart), flying capacitor
12 µF 630 V film (TDK B32676G6126K000) + 220 nF ceramic per leg, 87 µH inductors (Bourns MAG-3002584), FC voltage per leg
by AMC0311D across a 3 × 680 kΩ divider, TMCS1126 Hall on every switch-node current with an OC flag per leg, F28P55x
(TIDUFG9 p.1, p.3, p.5–9; BOM SLURB91 p.4, p.9–10). Measured 98.81 % peak at 700 V, 98.42 % at 900 V, junction 105–110 °C
at a 60 °C heatsink (TIDUFG9 p.14–18); switching at 70 kV/µs (SDAA195 p.11).

| # | TI does (doc p.) | We do | Verdict | Where / trade-off |
|---|---|---|---|---|
| 1 | 650 V devices only up to a **900 V** link: 450 V per device = 0.69 × V_DS (TIDUFG9 Table 1-1 p.3; SDAA195 p.2) | Gate-0 rule: continuous ≤ 0.67 × V_DSS, peak ≤ 0.85 (pv_tradeoff §6); port 1000 V, OVP 1100 V | CONSIDER (Gate-0 re-run, D-031) | In a 3-level cell on our ports a device blocks 500 V (550 V at OVP): 650 V parts = 0.77 / 0.85 → outside TI's own practice and our rule; 750 V parts = 0.67 / 0.73 → on the rule's edge, admissible only with vendor FIT-vs-V data at 500–550 V; 1200 V parts (candidate B) = 0.42 / 0.46 |
| 2 | **Flying-capacitor pre-charge/clamp network**: Zener string (3 × ZGL41-180A ≈ 540 V) + a few-ohm resistor across each outer switch S1 and S4; with MCU and aux off the rising link would otherwise put the full voltage on the outer devices; measured clamp 520 V; τ = 2 R_PR C_FC (SDAA195 §3.4 p.10, §4.1 p.11–12; SLURB91 p.4) | Candidate B carries "FC precharge before switching" as a cost item only (pv_tradeoff §4); no circuit, not in the transient checks | **ADOPT if B is chosen** | PVCELL: a clamp + pre-charge network across S1/S4 of **both** FC legs (either port can be energised first — PV precharge or battery — and AUX-HV starts at 229 V), sized so an outer device never exceeds 0.85 × V_DSS while its FC is at 0 V; gate enable only after both FCs are inside V/2 ± a window. Add its parts and the clamp energy to the B candidate in `sim/pv_tradeoff.py` |
| 3 | S1/S4 and S2/S3 strictly complementary; a violation shorts C_DC or C_FC and over-volts the other pair (TIDUFG9 §2.2.1 p.7; SDAA195 §2.1 p.4) | 2-level legs: hardware dead-time interlock on GDRV-HB (191–511 ns) | **ADOPT if B is chosen** | Hardware complementary interlock per pair on the gate-driver board (as today, one per pair) **plus** a forbidden-state and FC-out-of-window trip in the F28388D CLB/CMPSS (TIDA-010210 does its multilevel interlocks in the CLB, below) — no firmware-only path |
| 4 | FC voltage of every leg measured by its own isolated amplifier (AMC0311D, 2 V input) (SLURB91 p.9–10) | B priced with 2 isolated V sensors per cell | N/A (already planned) | Same as our B costing; keep it a direct FC measurement, not the difference of two bus readings |
| 5 | Two commutation loops (inner S2-S3-C1, outer S1-S4-C3) + an extra decoupling capacitor C2 to split the inner loop (SDAA195 §3.3 p.9) | 3-level transient check uses one lumped 25 nH outer loop (pv_tradeoff §6) | **ADOPT if B is chosen** | `sim/pv_tradeoff.py` DPT deck for B: model the inner and the outer loop separately (the inner loop sets the S2/S3 overshoot) |
| 6 | Switch-node current by an in-package Hall sensor (TMCS1126, ±120 A, 500 kHz) with a built-in 100 ns OC flag per leg, on legs switching at 70 V/ns (SLURB91 p.10; SDAA195 p.11) | PVCELL i_L: LEM LA 150-P closed-loop around an insulated lead (D-030) — no published dv/dt figure, 1.1 A offset to re-zero | CONSIDER | The 1000 V-class sibling TMCS1123 (on file: 1.3 kV reinforced working voltage, V_IORM 1697 Vpk, CMTI 150 kV/µs at V_CM 1000 V, 250 kHz, 110 ns delay, OC flag 100 ns, 80 A rms; TMCS1123 DS p.1, p.6, p.8) would give a published CMTI and a sensor-level OC layer. Limits: ±96 A range (5 V supply) is below the 96.3 A upper band of the CTRL backup trip and the 109 A saturation point (pv_control §10) — backup trip would move to ≤ 88 A upper band; the 47.5 A rms cell current must then flow through PCB copper into a SOIC-10 (R_IN 0.7 mΩ → 1.6 W, DS p.8; TIDA-010957 needed 3 oz copper for 36 A rms, TIDUFG9 p.21); TI-only (D-031: an Asian in-package Hall needs the same 1.3 kV reinforced rating) |
| 7 | AC-side pre-charge through PTC inrush limiters (Vishay PTCEL13R600LBE, 60 Ω, 500 V) + relays (SLURB91 p.6–7) | 220 Ω Miba RST 200 + thermal cut-off + supervision with 3 attempts / 30 s lock-out (port report §1, §3) | CONSIDER (low) | A PTC is self-protecting against pre-charge into a short or a welded load; needs a ≥ 1000 V DC PTC that absorbs ≈ 180 J per start (PV 4 cells at 1000 V) and repeated attempts into a short (757 J each, port report §1). No such part identified — keep ours |

### TIDA-010210 — 11 kW 3-phase ANPC, GaN (TIDUEZ0 Rev A, Mar 2022)
**What it is:** three-level ANPC inverter/PFC, 4 high-frequency LMG3422R030 (600 V GaN) + 2 line-frequency 650 V Si per
phase, 800 V link ("600-V rated switches in 800-V system"), 100 kHz, shunt (2 mΩ) + AMC3302 current sensing, SN6501
push-pull bias; 98.5–98.62 % measured (TIDUEZ0 p.1, p.8, p.10–11, p.18).

| # | TI does (doc p.) | We do | Verdict | Where / trade-off |
|---|---|---|---|---|
| 1 | "Hardware based interlocking protections needed to avoid device overvoltage under all operating conditions" implemented in the C2000 **CLB**, no extra parts (TIDUEZ0 p.1–2) | F28388D CLB unused; trips via CMPSS/PPB/trip zone + GDRV interlock | ADOPT if B is chosen | Same as TIDA-010957 row 3 — the F28388D has CLB tiles; put the 3-level state checks there |
| 2 | Series devices share voltage only if a defined state holds the mid node (Q6 kept on, p.5) | Candidate C (series-stacked split bus) assumes a midpoint balance loop | CONSIDER (only if C is re-opened) | Static sharing of series-connected halves needs an active state or balancing network in every mode including standby |

### PMP41037 — 1 kW 800 V → 12 V serial half-bridge bidirectional DCX, GaN (TIDT332, 2024)
**What it is:** two LMG3622 650 V GaN half-bridges **in series** across a split 760–840 V bus (up to 900 V; 3 × 22 µF
450 V per half), each half measured by its own AMC1311, firmware voltage-balancing loop (`SHB_BALANCING_CTRL`), 1 MΩ
bleeders and 220 V Zeners (BZG03C220) on the power board, LLC run as a DCX at resonance, F280039C; 98.0 % at 634 W
(TIDT332 p.1–2, p.6, p.8; power BOM TIDMCY2 p.1–2).

| # | TI does (doc p.) | We do | Verdict | Where / trade-off |
|---|---|---|---|---|
| 1 | Stacked 650 V stages on 800 V: per-half isolated voltage sensing + active balancing loop + passive bleeders/Zener clamps (TIDT332 p.2, p.6; BOM p.1–2) | Candidate C (series-stacked split bus) assumes a midpoint loop; no passive sharing in its costing | ADOPT if C (or any stacked option) is chosen | Passive sharing (bleeder + clamp per half) that holds with the controller off, plus per-half isolated sensing; add the bleeder loss at 1000 V to the candidate's loss model |
| 2 | Start-up procedure ramps the 800 V source at **< 1 V/ms** before the stage runs (TIDT332 p.6, §1.4.3–1.4.4) | Our ports rise through the 220 Ω pre-charge at ≈ 17 V/ms (PV, 3 cells: 1000 V / τ 59 ms) to ≈ 34 V/ms (DAB port 1, τ 30 ms) (port report §1), possibly before AUX-HV (229 V start) has the controller up | **ADOPT** (requirement for the Gate-0 re-run) | Any stacked or flying-capacitor PV cell must hold every device inside the voltage rule by passive means at ≥ 35 V/ms port ramps, in both pre-charge directions; no TI design demonstrates this |
| 3 | Transformer and resonant choke from a Chinese maker (YAXIN Electronic: YXS61041T PQ3230 1 kW, YXS50494T PQ2016 12 µH) in a TI design (BOM p.1–2) | Magnetics vendors open (MAG-2, D-031) | CONSIDER (low) | A data point that a Chinese magnetics house builds TI's HV magnetics; candidate RFQ vendor for AUX-HV T1 and the small chokes |

### TIDA-010949 — 600 W GaN four-switch buck-boost PV optimizer (TIDUF99, Nov 2024)
**What it is:** FSBB with 2 × LMG2100R026 (100 V GaN half-bridge), 80 V / 18 A, 300 kHz, 3.6 µH (Coilcraft SER2013-362MLB),
TMCS1127 Hall, P&O MPPT, PLC + wireless on one C2000; 99.0 % peak in switching mode at 15 A (TIDUF99 p.1, p.12–13; BOM p.1).

| # | TI does (doc p.) | We do | Verdict | Where / trade-off |
|---|---|---|---|---|
| 1 | **Stacked-carrier modulation**: one modulator 0–2, buck carrier 0–1.05, boost carrier 0.95–2; both legs switch in the 0.95–1.05 overlap, so buck / buck-boost / boost follow without a mode state machine; implemented by scaling the modulators (M_buck = 0.95 M, M_boost = 0.95 (M − 0.95)) because moving the carrier start costs ≈ 50 % PWM resolution on C2000 (TIDUF99 p.12–13) | Explicit buck / band / boost modes with 0.015 hysteresis, filtered-integrator exit and dead-time feed-forward (pv_control §1–§4) | CONSIDER (firmware) | Same band, simpler firmware, no hysteresis to tune; ours is the simulated one (unknown 150–500 ns dead time). Keep ours unless the bench shows mode chatter; then the stacked carrier is the fallback |

### TIDA-010054 — 10 kW SiC DAB, re-read for DAB-D60 (TIDUES0 Rev F, Apr 2026)
Already cross-checked in `sim/out/dab_design/report.md` §2 (L, n, phase, blocking-capacitor rule, EPS). New points only.

| # | TI does (doc p.) | We do | Verdict | Where / trade-off |
|---|---|---|---|---|
| 1 | Measured efficiency **98.0 % at 10 kW**, 98.8 % peak at 4 kW (text: 97.6 % full load) (TIDUES0 Table 1-1 p.4) | Model 98.51–98.68 % at 800/800 V 60 kW; Wolfspeed measured 97.0–97.6 % (D-015) | **ADOPT** (as evidence) | D-015 / D-017: a second measured DAB on file also stays below 99 % at full load — no reference demonstrates DAB-04; keep "not claimed" and the pessimistic derating map as the guaranteed envelope |
| 2 | Planar transformer with the series inductance integrated (Payton): 24:15, L_σ 34 µH, L_m 720 µH, R_dc 43 / 16 mΩ, 50 W + 15 W at 10 kW (TIDUES0 p.23, p.26) | Wound PM 114/93 N95 + separate 2.12 µH inductor, leakage ±20 % trimmed to ±5 % (dab_design §9) | CONSIDER | MAG-2 RFQ: ask for a planar variant with integrated L (repeatable leakage, cold-plate friendly) next to the wound design; the 1850 V DC PD-free barrier is harder in laminate windings |

### PMP23223 — smart isolated gate driver with bias supply (TIDT283, May 2022)
**What it is:** one-channel board for a SiC or IGBT switch: UCC21732-Q1 (10 A, DESAT through the OC pin, internal
two-level turn-off, CLMPE external clamp, AIN/APWM) with a UCC14240-Q1 bias module from 21–27 V and an LDO for VCC/ENA
(TIDT283 p.1, p.3–4). Rails +18/−4 V (p.10); R_on = R_off = 2.2 Ω (TIDMAI8 p.1); DESAT 5.4 V / 130 ns through 2 ×
STTH112A, not fitted as shipped (TIDT283 p.9; TIDMAI7 p.2). Tested only into a 100 nF capacitor: COM–VEE ripple 252 mV pp,
VDD–VEE 865 mV at 1 kHz (p.5); UCC14240 86.9 °C, UCC21732 80.5 °C at 1.5–1.8 W, no airflow, ambient not stated
(p.10–11). No power device, no double-pulse test, no fault timing.

| # | TI does (doc p.) | We do | Verdict | Where / trade-off |
|---|---|---|---|---|
| 1 | Rails set by two feedback dividers: VDD–VEE 21.9 V (77.7 k/10.0 k), COM–VEE 4.0 V (13.2 k/22.0 k); the board takes any module of the family by changing them; UCC14240 rated 25 V out (TIDMAI7 p.2, TIDMAI8 p.1) | PV +20/−4 V (VDD–VEE 23.79–24.51 V); +20/−5 V refused (up to 25.33 V) | CONSIDER | No TI design goes above 23 V total (+18/−4, +15/−5, +18/−5). Two rails fit under 25 V in our `rails()` model: **+19.9/−4.5 V** (87.6 k/10 k, 8.06 k/10 k → 24.04–24.76 V, VGS on 19.46–20.31 V) or **+18/−5 V** (82.5 k/10 k, 10 k/10 k → 22.78–23.47 V). Re-run `sim/pv_design.py` (E_off ×1.225 at −4 V against R_DS(on) at 18 V) before −4 V is frozen |
| 2 | External Miller clamp: CLMPE → 0 Ω → Si2318CDS N-FET (40 V, 5.6 A) gate-to-VEE, 10 kΩ pull-down, 0.1 µF VEE–COM at the FET (TIDMAI7 p.2, TIDMAI8 p.1) | One ZXTP25040DFH PNP follower per device on CLMPI; die +1.42 V vs V_th,min 1.48 V (D-028, 0.06 V margin) | CONSIDER | PV channel: one N-FET per device from its gate to its own C_VL, held fully on — a resistive path without the PNP's V_EB and base-drive limits. Gain not quantified: simulate it in the PV DPT deck first. Needs a CLMPE-type output (UCC21732, UCC218915); UCC21710 and the D-031 candidates on file (NSI66x1A-Q1 p.3, SiLM5992SH p.20) have an internal clamp pin only → make it a D-031 selection criterion, otherwise keep the PNPs and close D-028 on the bench |
| 3 | AIN/APWM across the barrier, thermistor with 6.19 kΩ in parallel and 10 nF (TIDMAI7 p.2). Bench: 80.33 % at AIN 0.6 V and 40 % at 2.5 V against the datasheet line 88 % → 10 % over 0.6–4.5 V (TIDT283 p.8–9) | DAB module NTC on AIN/APWM; our design check claims ±1.5 % duty = ±3 °C | **ADOPT** | TI's own points are 8–10 duty points low (≈ 0.5 V, ≈ 20 °C at 24 mV/°C), outside the datasheet window, unexplained. GDRV-HB design check and the DAB bench plan: two-point AIN→APWM check per channel before the NTC trip that D-017 relies on is trusted; no ±3 °C claim until then. TI-only feature (no AIN on NSI66x1A or SiLM5992SH) |
| 4 | Internal two-level turn-off listed as a feature (p.1); no level, duration or short-circuit test | Soft turn-off, I_STO ≥ 250 mA: 1.35 µs PV, 1.32 µs DAB (calculated) | N/A | Nothing to compare; UCC21732-only. None of the three driver designs publishes a fault-to-off measurement, so our times stay calculated |

### PMP22817 — SPI gate driver + UCC14240-Q1 bias, 800 V traction (TIDT256 Rev A, Mar 2022)
**What it is:** UCC5870-Q1 (30 A peak, SPI, DESAT, CLAMP, V_CE active clamp, ASC, AI1–AI6) with a UCC14240-Q1 bias module at
+15/−5 V (69.8 k/10.0 k and 10.0 k/10.0 k, 330 pF) fed from a 24 V LM5156-Q1 SEPIC (TIDT256 p.1; TIDMA63 p.1); gate R
3 × 4.3 Ω per side; DESAT 1.00 kΩ + one STTH112A + 100 pF, threshold not stated (TIDMA63 p.1); edges 12/14 ns unloaded,
333/326 ns into 100 nF (p.20). The report defers driver and bias performance to the datasheets (p.5).

| # | TI does (doc p.) | We do | Verdict | Where / trade-off |
|---|---|---|---|---|
| 1 | Bias and driver isolation 3 kVrms for 1 min, presented as enough for an 800 V DC bus (TIDT256 p.1); BOM rates the UCC14240 "> 2.5 kVrms" (TIDMA64 p.2) | UCC14241-Q1 reinforced, V_IOWM 1414 V DC, certification "planned" (D-016), 1000 V bus | CONSIDER | TI gives no working voltage or certificate for this family at 800 V, so nothing here closes D-016; ask TI for the VDE 0884-17 / IEC 60747-17 certificate status |
| 2 | **UCC15241-Q1** (ti.com product page, 2026-10-04): VIN 21–27 V (32 V abs max), 2.5 W at T_A ≤ 85 °C, > 2.0 W at 105 °C, 25 V output class, < ±1.3 % regulation, CMTI > 150 kV/µs; reinforced 7071 Vpk (IEC 60747-17), 5000 Vrms UL 1577 and CQC listed as **planned** | UCC14241-Q1: 2.0 W (85 °C) / 1.5 W (105 °C) | CONSIDER | Same 25 V ceiling and ±1.3 % → +20/−5 V still refused; certification also only planned → no D-016 relief. Gain: +25 % power, lifting the 3 × C3M0016120K DAB case (1.66 W) from margin 0.91 to ≥ 1.2 at 105 °C. Pin compatibility unverified (datasheet not on file). TI-only |
| 3 | Bias output overshoots **+0.5 V** at enable, and also on a VIN ramp with ENA held high, 75 mA load (TIDT256 p.19) | +24V_GD switched by CHB_OK with ENA on VCC — TI's VIN-ramp case. DAB VGS on ≤ 15.45 V vs BZX84-B16 knee 15.70 V; PV ≤ 20.55 V vs 21.60 V | **ADOPT** | `gen/gdrv.py` design check: add a +0.5 V start-up term. The DAB rail then reaches 15.95 V, past the B16 knee — harmless only while UVLO/RDY hold the gate low until PG (state it in the check). PV reaches 21.05 V and stays below |
| 4 | Bias thermal: 1.6 W (100 nF, 40 kHz) → UCC14240 73 °C, driver 56 °C, gate R 76 °C at 21–23 °C ambient, no fan (p.14); no efficiency data | Derating by ambient only: 2.0 W (85 °C) / 1.5 W (105 °C); DAB 1.15 W, PV 0.78 W | CONSIDER | ≈ 32 K/W self-heating (our scaling): DAB channel ≈ 97 °C at 60 °C local ambient — OK; the 3 × C3M0016120K option (1.66 W) ≈ 113 °C, beyond the 105 °C line → that option needs UCC15241 or airflow |
| 5 | V_CE active clamp (2 × SMCJ300A drain → VCECLP, FSV340AF into the gate, 100 Ω / 2.2 nF), ASC, AI1–AI6 over SPI (TIDMA63 p.1, TIDMA64 p.1) | Soft turn-off + RC damper; safe state = all off with bias removed (D-012) | N/A | 2 × 300 V TVS would conduct on our 1000 V bus (and on TI's 800 V); our worst normal peak is 1401 V = 0.82 × V_DSS. ASC is a motor safe state; SPI and AI are UCC5870-only |

### TIDA-011011 — isolated gate driver with isolated bias for 3.3 kV SiC (TIDUFH7, Mar 2026)
**What it is:** half-bridge board: 2 × UCC218915-Q1 pre-drivers (2.8 A, DESAT, soft shutdown, CLMPE, ASC; 1.06 kVrms working,
> 200 V/ns) into BUK6D43-40PX / BUK6D23-40EX buffers; 2 × UCC35131-Q1 bias modules, +18/−5 V from 12 V (TIDUFH7 p.1–4;
SLVRC10 p.1–2); gate R per channel 2 × 3.3 Ω on, 2 × 1 Ω off (SLVRC10 p.2; SLURBB9 p.1). Double-pulse on a 2.3 kV / 1.1 mΩ
module at 1.5 kV with 2.5 Ω: ≈ 40 V/ns at turn-off (400 A), ≈ 50 V/ns at turn-on (320 A); plots show ≈ 1.66 kV turn-off
peak (TIDUFH7 p.5–6). No DESAT threshold, blanking or short-circuit test.

| # | TI does (doc p.) | We do | Verdict | Where / trade-off |
|---|---|---|---|---|
| 1 | 2.8 A pre-driver → 120 Ω → P/N-FET buffer (10 kΩ pull-ups/downs); soft shutdown bypasses the buffer: SSD/GATE → 32.4 Ω → gate (SLVRC10 p.2; TIDUFH7 p.3) | DAB R_G,off 0.27 Ω, chosen so the UCC21710 sink stays ≤ 10 A (9.87 A); costs E_off +27 % against the CRD's 0 Ω (`dab_spec.json`) | CONSIDER | DAB channels: a buffer allows R_G,off → 0 Ω and a 2.8–5 A Asian pre-driver (widens D-031). Cost: 2 FETs + 4–5 resistors per channel, extra delay (not stated by TI), soft turn-off needs its own path to the gate |
| 2 | CLMPE → 10 Ω → BUK6D23-40EX N-FET at the gate; the gate steps from ≈ −3.5 V to −4.8 V ≈ 300 ns into turn-off when the clamp engages (SLVRC10 p.2; TIDUFH7 p.5 Fig. 3-4, read from plot) | PNP followers on CLMPI | CONSIDER | Same lesson as PMP23223 #2; the clamp only adds hold-off near VEE, so our timing check (clamp on ≤ 179 ns vs 191 ns dead time) still governs |
| 3 | UCC35131-Q1: VIN 5.5–20 V, 2.0 W at 85 °C, > 5 kVrms, 8.2 mm creepage/clearance; VDD–COM 15.0 k/2.40 k, VEE by one 51 kΩ, BSW + 3.3 µH (TIDUFH7 p.3; SLVRC10 p.1) | UCC14241-Q1 from +24V_GD (21.6–26 V) | N/A | Input range excludes our 24 V rail (each card would need a 12 V stage); total-rail limit and certification not stated; TI-only |
| 4 | Reaches 3.3 kV by referencing the MCU to the DC-link midpoint; parts rated 1050 Vrms working (TIDUFH7 p.2) | PELV control referenced to PE; the barrier holds the full 1000 V (1100 V trip) to earth; 8 mm packages are below the 10 mm reinforced value at PD2 (ECO-10) | N/A | Midpoint referencing halves the barrier stress only where the midpoint is earthed — not our system. The 8.2 mm package does not close the ECO-10 creepage item |
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

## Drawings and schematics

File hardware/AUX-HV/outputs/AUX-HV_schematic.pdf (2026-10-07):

1 | 2 | 3 | 4 | 5 | 6 | 7 | 8

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
Size: A3 | Rev: C1 | F Date: 2026-10-04
KiCad E.D.A. 10.0.6 | Id: 1/5

# Title: AUX-HV (builds PV, DAB-D60) - Cover / Hierarchy

## File: AUX-HV.kicad_sch

## Sheet: /

## Barrier: T1 (PD-tested, reinforced) + CNY65B, conformally coated (PD1) - D-032

## Schematics authored by Chinmoy Bhuyan

## Sheet 1

Builds: PV all fitted / DAB-D60 port B not fitted (DAB BOM). Not bench-validated.

## 03 PWM, SiC, clamp, T1, foldback

File: sheets/03_power.kicad_sch

## 04 Rectifier, output, feedback, PG

File: sheets/04_secondary.kicad_sch

## 01 HV input, limit, fuse, OR

File: sheets/01_input.kicad_sch

## 02 Start-up, brown-in, OV, timer

File: sheets/02_startup.kicad_sch | VS-8ETU04S + RC snubber, 3 x 100 uF polymer, ATL431 + CNY65B fast-lane type II with R-C feed-forward, TPS3700 window -> SN74LVC1G17 -> PG_HVAUX (active | high),
output connector (interfaces.AUX) 3 x BSS126 cascode on a compensated tap string; TPS3710 brown-in pulls COMP | low; TLV3202 ch 1 = input OV lockout (COMP low), ch 2 = latched overload timer (soft-start crowbar) -> hiccup | UCC28C59-Q1 at 65 kHz, IV2Q171R0D7Z 1700 V SiC, TVS clamp, T1 (CUSTOM EC34A), aux -> BC817 follower -> VDD, aux backup loop on FB, foldback: 10 nF onto RT/CT below ~8 V output (no current staircase)

CALCULATED (sim/aux_hv_design.py rev C1): DCM flyback 64.9 kHz; start 228 V (worst 232 V), stop 175-190 V; out 22.40-23.15 V; eta 80.8/84.0/83.5/82.2/80.4 % at 200-1000 V (T1 design M1); switch IV2Q171R0D7Z (alt. SG2M1K0170J2J), gate 15.5-18.1 V.
Protections: OV lockout 1114-1170 V; 4 kV/20 us residual -> HV_BULK 1199 V; foldback 5.9 kHz; overload timer 91-189 ms -> hiccup. Rating 30 W continuous, 38 W <= 91 ms (SYS rev E 27.8 W, 30.15 W <= 200 s). V_DS 1323 / 1428 V at 1000 / 1100 V.

CONFORMAL COATING (IC-17, D-032): coated to pollution degree 1 (IEC 60664-3 type 1) over the HV-PELV barrier parts T1, CNY65B and their HV copper. T1: PD <= 10 pC at 2461 Vpk on every unit, 4400 V rms 60 s, 8 kV impulse.

LAYOUT (not dimensions): reinforced HV <-> PELV for 1000 V DC, PD2, OVC II (IEC 62477-1 / 62109-1, ECO-10); only T1 and the CNY65B cross; 1000 V spacing between HV nets and between the ports; >= 4 cm2 2-oz Cu per SMCJ70A; VDD follower <= 85 C, away from T1 / SiC / clamp (sim report sec. 4, 6, 11).

BUILD OPTIONS: PV = all parts fitted (bom/AUX-HV_BOM.csv). DAB-D60 = port 1 only (D-021): the port-B input parts marked 'PV build only' (2 studs, 2 x 22 R, fuse, 2 OR diodes) are not fitted (bom/AUX-HV_DAB_BOM.csv).

Rev C1 | 2026-10-04 | Schematics authored by Chinmoy Bhuyan | 22.8 V / 30 W isolated control rail from the DC ports, 200-1000 V (1100 V transient)

### Per port: studs, 2 x 22 R pulse-rated AHEAD of the 1 A / 1000 VDC fuse, BYG10Y OR

of both poles; 2 x 3.3 uF / 1300 V film = surge absorber. Port B is not fitted on the DAB-D60 build (bom/AUX-HV_DAB_BOM.csv).

# AUX-HV (builds PV, DAB-D60)

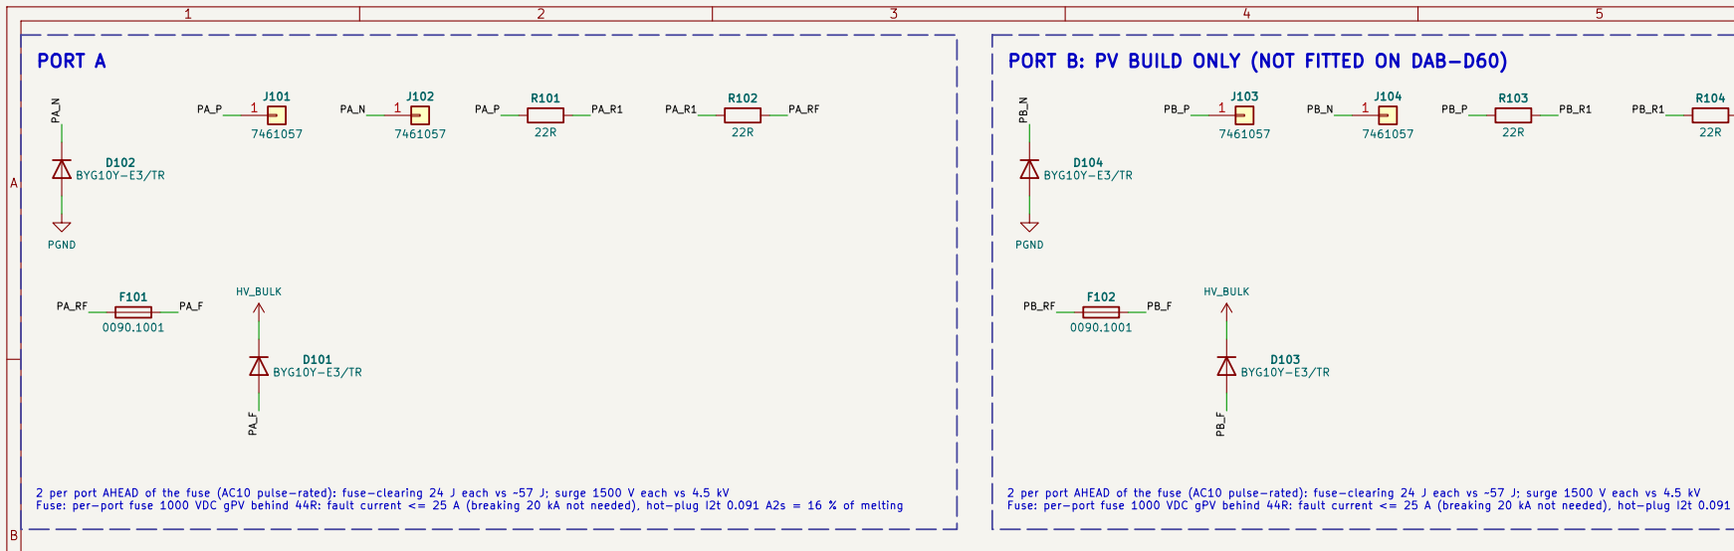
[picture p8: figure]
D101 BYG10Y-E3/TR 1; 7461057 D102 BYG10Y-E3/TR; 0090.1001 D104 BYG10Y-E3/TR; PGND; PORT A

C

D

E

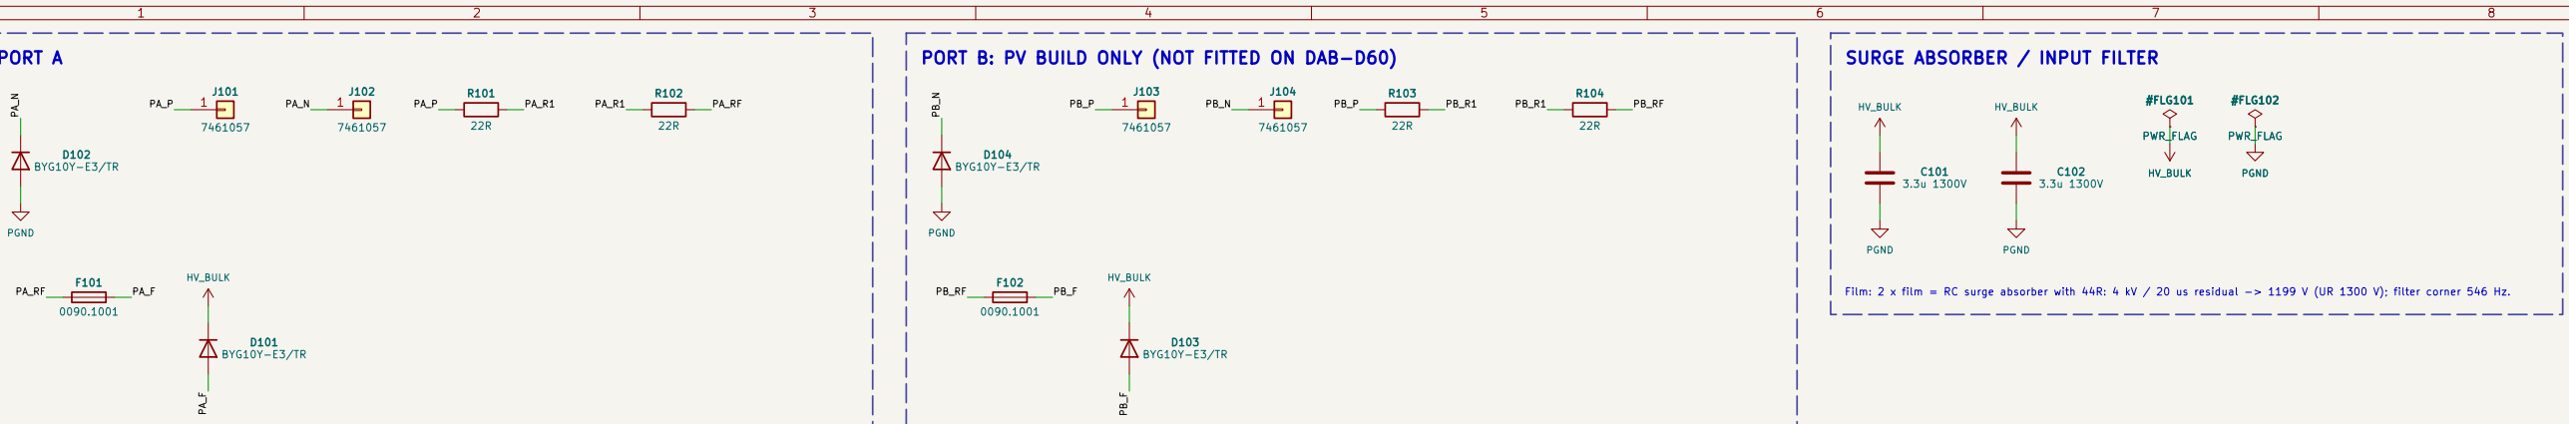
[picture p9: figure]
HV_BULK R101; 3.3u 1300V PGND; HV_BULK; #FLG102 PWR_FLAG; #FLG101 PWR_FLAG 1; 7461057 HV_BULK; D103 BYG10Y-E3/TR; PGND 1; PGND R103; C102 3.3u 1300V PGND; SURGE ABSORBER / INPUT FILTER; PGND #FLG101 PWR_FLAG

AB

C

D

E

# Title: AUX-HV (builds PV, DAB-D60) - HV input, limit, fuse, OR

## File: 01_input.kicad_sch

## Sheet: /01 HV input, limit, fuse, OR/

## Barrier: T1 (PD-tested, reinforced) + CNY65B, conformally coated (PD1) - D-032

## Schematics authored by Chinmoy Bhuyan
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

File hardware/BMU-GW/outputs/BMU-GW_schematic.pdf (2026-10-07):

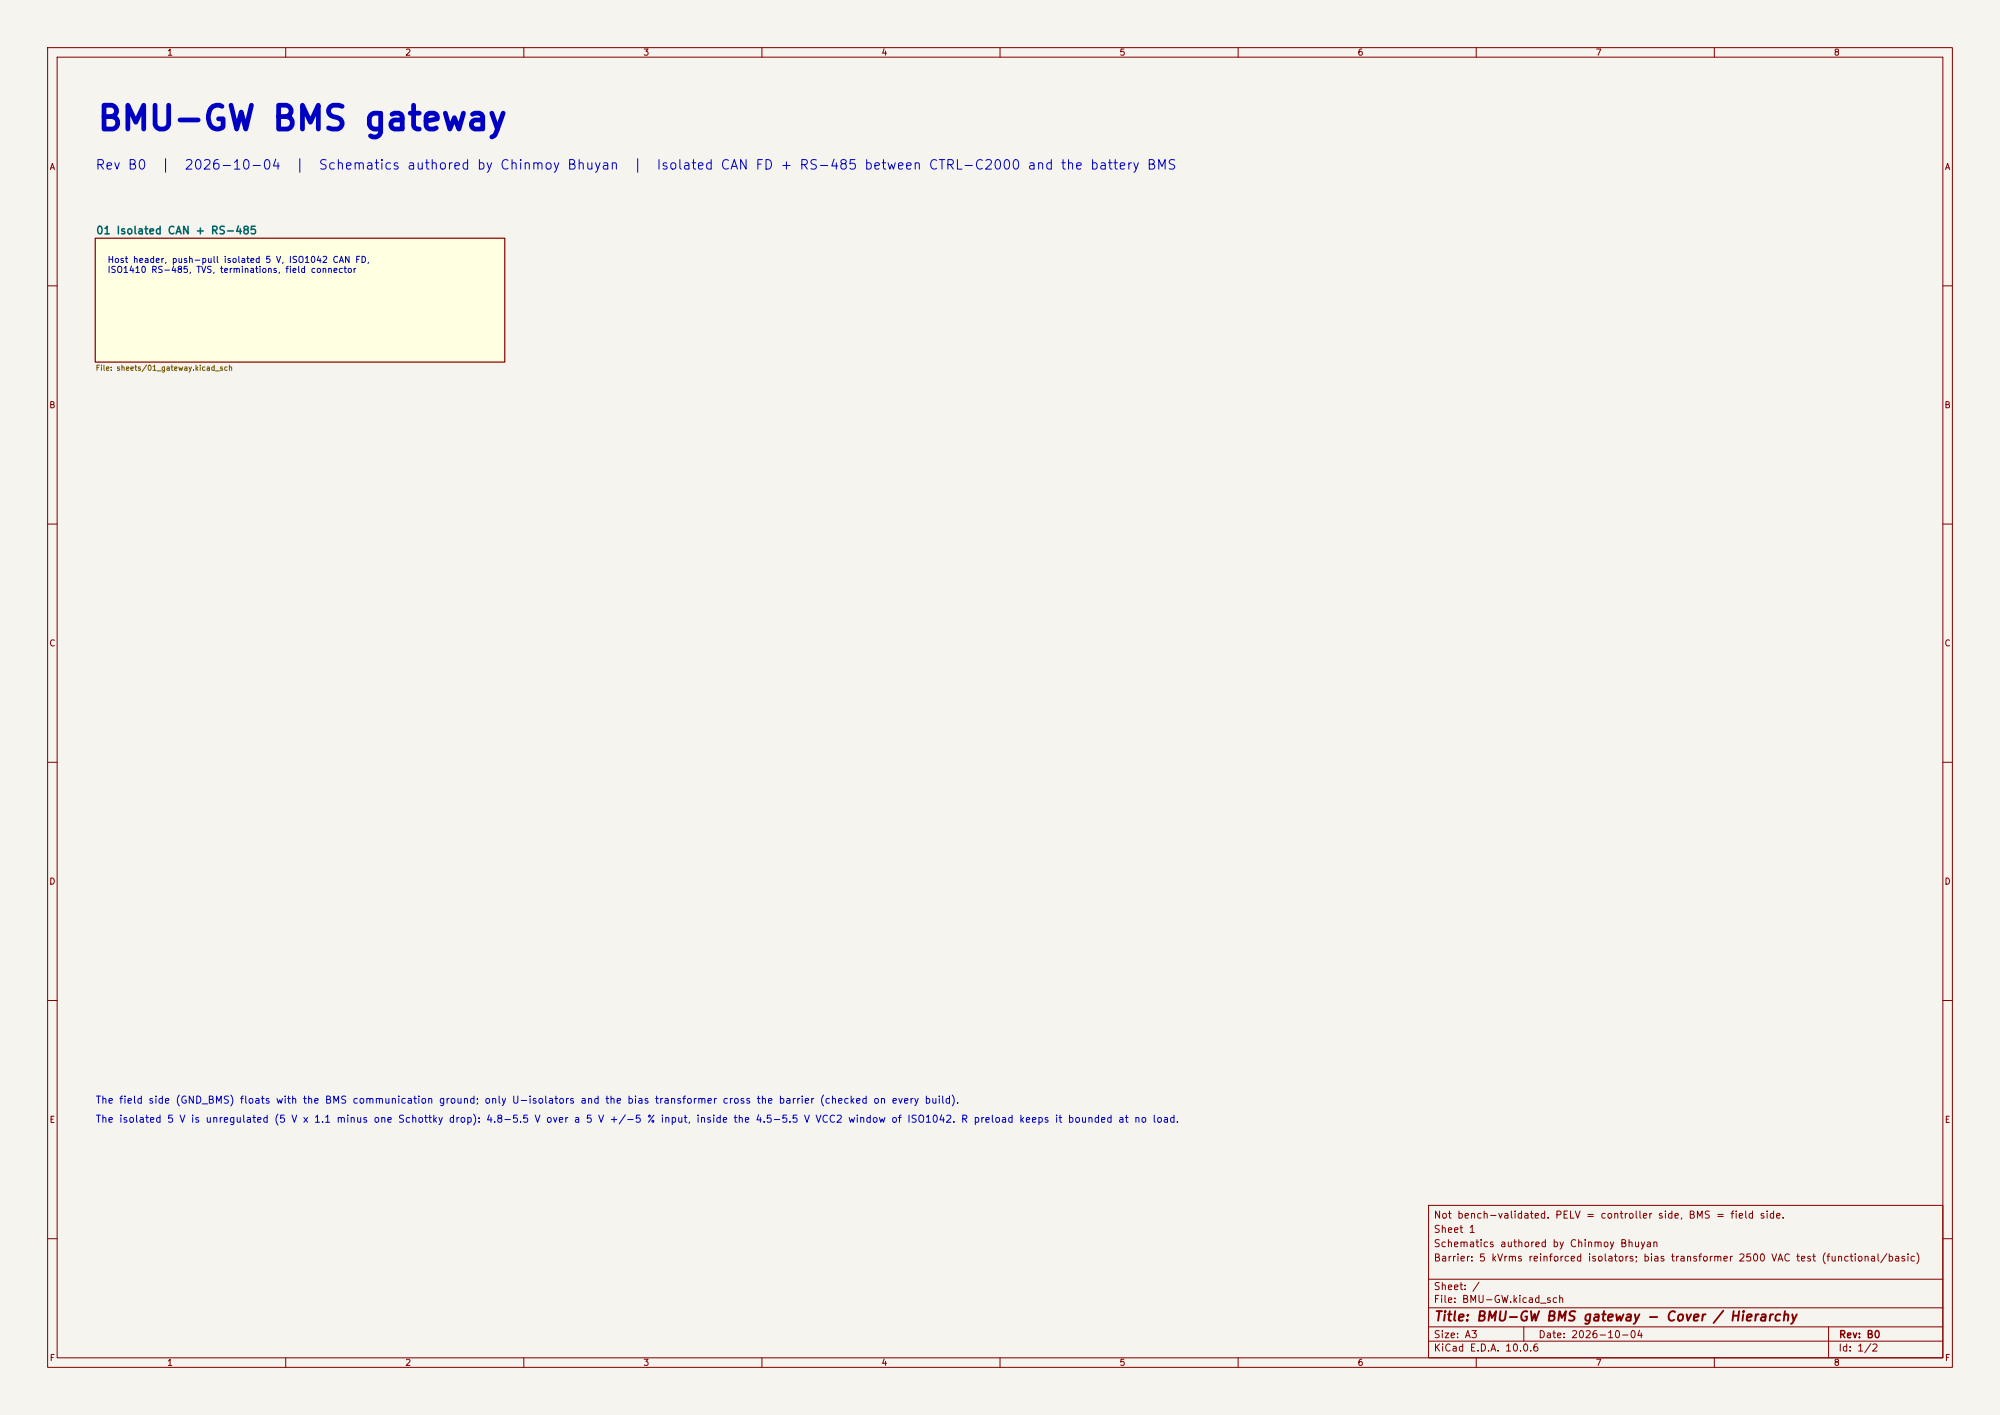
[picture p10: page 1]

ISO1410 RS-485, TVS, terminations, field connector BMU-GW BMS gateway

Rev B0 | 2026-10-04 | Schematics authored by Chinmoy Bhuyan | Isolated CAN FD + RS-485 between CTRL-C2000 and the battery BMS

Host header, push-pull isolated 5 V, ISO1042 CAN FD,

The field side (GND_BMS) floats with the BMS communication ground; only U-isolators and the bias transformer cross the barrier (checked on every build).
The isolated 5 V is unregulated (5 V x 1.1 minus one Schottky drop): 4.8-5.5 V over a 5 V +/-5 % input, inside the 4.5-5.5 V VCC2 window of ISO1042. R preload keeps it bounded at no load.

Not bench-validated. PELV = controller side, BMS = field side.
Sheet 1
Schematics authored by Chinmoy Bhuyan
Barrier: 5 kVrms reinforced isolators; bias transformer 2500 VAC test (functional/basic)

Sheet: /
File: BMU-GW.kicad_sch
Title: BMU-GW BMS gateway - Cover / Hierarchy

Size: A3 | Rev: B0 | F Date: 2026-10-04
KiCad E.D.A. 10.0.6 | Id: 1/2

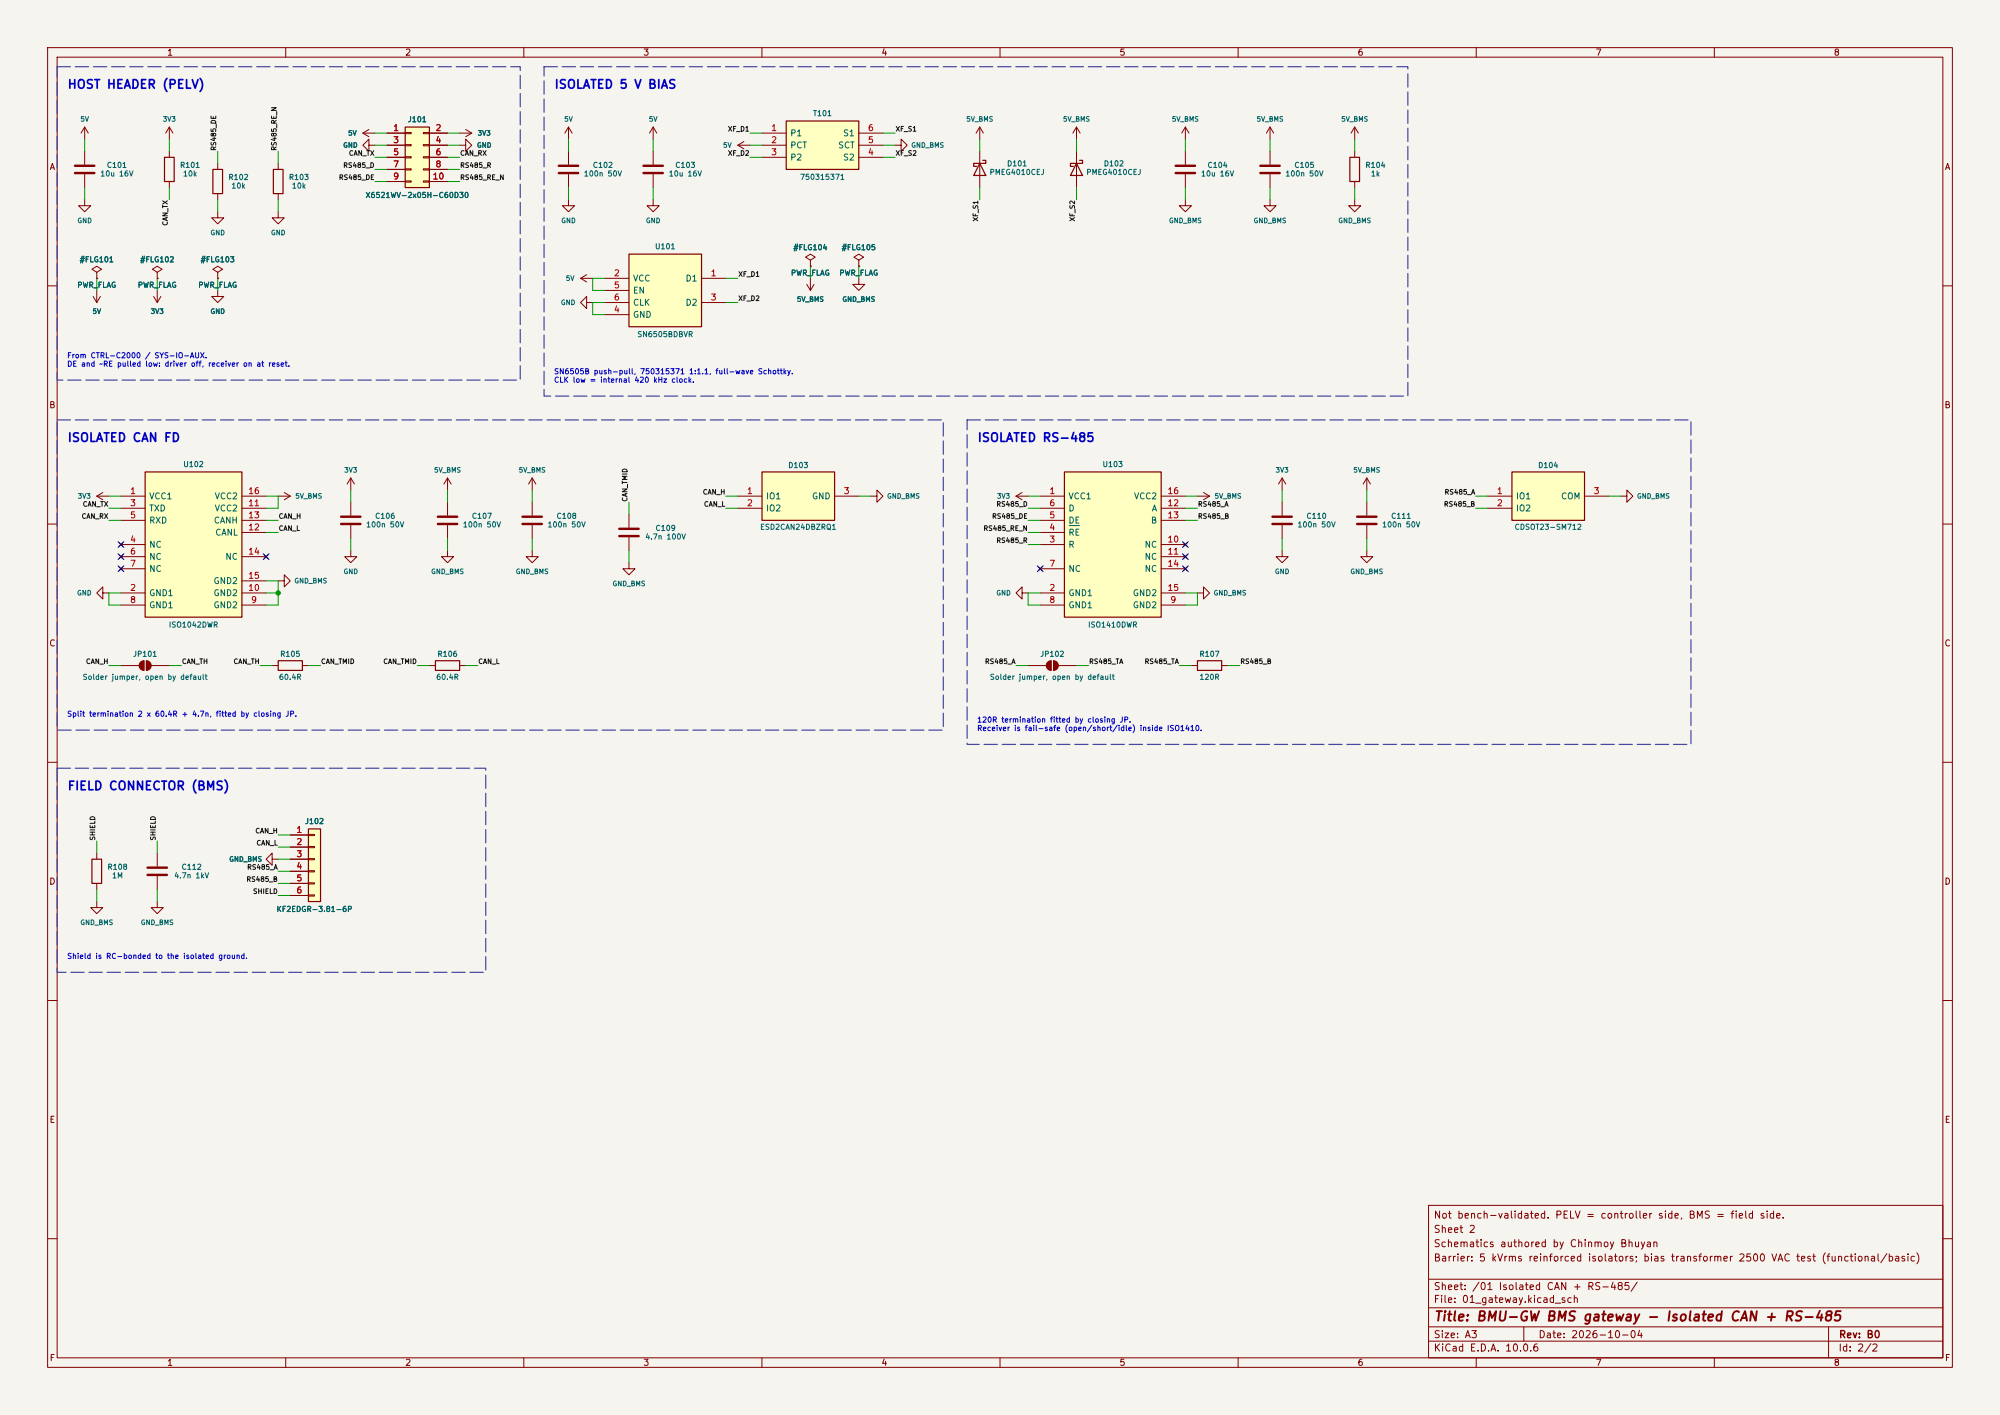
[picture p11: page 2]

From CTRL-C2000 / SYS-IO-AUX. DE and ~RE pulled low: driver off, receiver on at reset. #FLG101 PWR_FLAG
XF_D1 FIELD CONNECTOR (BMS)

SN6505B push-pull, 750315371 1:1.1, full-wave Schottky. CLK low = internal 420 kHz clock.

Solder jumper, open by default GND

Solder jumper, open by default

120R termination fitted by closing JP. Receiver is fail-safe (open/short/idle) inside ISO1410. Shield is RC-bonded to the isolated ground.

Not bench-validated. PELV = controller side, BMS = field side.
Sheet 2
Schematics authored by Chinmoy Bhuyan
Barrier: 5 kVrms reinforced isolators; bias transformer 2500 VAC test (functional/basic)

Sheet: /01 Isolated CAN + RS-485/
File: 01_gateway.kicad_sch
Title: BMU-GW BMS gateway - Isolated CAN + RS-485

Size: A3 | Rev: B0 | F Date: 2026-10-04
KiCad E.D.A. 10.0.6 | Id: 2/2

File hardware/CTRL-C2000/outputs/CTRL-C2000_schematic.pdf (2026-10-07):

1 | 2 | 3 | 4 | 5 | 6 | 7 | 8

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
Size: A3 | Rev: E0 | F Date: 2026-10-04
KiCad E.D.A. 10.0.6 | Id: 1/15

# Title: CTRL-C2000 control card - Cover / Hierarchy

## File: CTRL-C2000.kicad_sch

## Sheet: /

## All interface contracts: gen/interfaces.py (CELL x4, PORT, SYS)

## Schematics authored by Chinmoy Bhuyan

## Sheet 1

Not bench-validated. Values marked calculated are not simulated.

# 06 Fault receivers, enable, EN drivers

File: sheets/06_trip.kicad_sch

# 09 Cell port C3

File: sheets/09_cell3.kicad_sch 05 ADC reference, VMID, slow mux

File: sheets/05_adcref.kicad_sch | 07 Cell port C1

File: sheets/07_cell1.kicad_sch 03 TMS320F28388D (ZWT 337-ball)

File: sheets/03_mcu.kicad_sch 11 Port-board analog inputs

File: sheets/11_port.kicad_sch

# 01 Power regulators

File: sheets/01_power.kicad_sch

# 12 SYS-IO-AUX connector

File: sheets/12_sys.kicad_sch

# 08 Cell port C2

# File: sheets/08_cell2.kicad_sch 04 MCU supply decoupling

File: sheets/04_decoupling.kicad_sch

# 14 JTAG, UART, EEPROM, LEDs, SDFM

File: sheets/14_debug.kicad_sch

13 Ethernet PHY DP83822I File: sheets/13_eth.kicad_sch | 10 Cell port C4

File: sheets/10_cell4.kicad_sch

02 Supervisors, reset, clock, boot File: sheets/02_reset.kicad_sch MII to the CM EMAC (GPIO105-124, mux 14), own 25 MHz oscillator, 49.9 R MDI terminations to AVD; MDI pairs, LEDs and the centre-tap supply ETH_CT go to SYS enable (74LVC11A); line drivers on only with CHB_OK, MCU enable and RDY; EN readback on GPIO100-103. +24V_GD feeds only the cell eFuses. runs from the analog rail, so VREFHI and VDAC never exceed VDDA.

Pin plan with mux positions and trip bands: gen/data/ctrl_c2000_pin_plan.csv (checked against SPRSP14E table 6-1 on every build). Pin table: gen/data/f28388d_pins.csv (from the PDF).

TPS3703 windows on 3.3 V and 3.3 V analog, UV supervisor on 1.2 V -> XRSn; 25 MHz CMOS clock into X1; boot straps GPIO72/GPIO84 (flash by default)

SYS side: inputs via 74LVC244A / 74LVC1G17 (Ioff); I2C pull-ups and EEPROM 0x57 here; ETH_CT = PHY AVD; PORT +24V via its own eFuse.

Cn_EN = GATE_EN AND CHB_OK AND MCU enable (74LVC11A); line drivers on only while CHB_OK, MCU enable and RDY; EN drivers with readback; fail-safe FLT receivers CELL contract 2x20: 8 PWM RS-422 drivers, 3 dual-range analog inputs, RDY, ID,

### NTC; gate-driver supply +24V_GD through a 1.5 A eFuse (TPS26600)

Rev E0 | 2026-10-04 | Schematics authored by Chinmoy Bhuyan | TMS320F28388D common controller for PV-P75/100/110 and DAB-D60

+24V -> LMR38020 5 V -> TPS62133 3.3 V; PG chain enables TPS62130 1.2 V and TPS7A2033 3.3 V analog (VDDIO first, then VDD and VDDA) REF5025E 2.5 V for VREFHIA-D; OPA2388 buffers VMID 1.25 V (diff-amp offset) and VBIAS 2.5 V (ID/NTC bias); TMUX1208 for 4 NTC + 4 ID; 24 V monitor; AGND star CTRL-C2000 control card

80-way SYS contract: +24 V logic, +24V_GD (channel B), CAN, SCI, SPI, I2C, DI/DO, fault latch, GATE_EN, CHB_OK, watchdog, reset, fans, Ethernet MDI + centre tap

All 337 balls, pin table extracted from SPRSP14E (gen/data/f28388d_pins.csv); net per ball from the pin plan (gen/data/ctrl_c2000_pin_plan.csv) PORT contract 2x13: VA, VAX, VB, VBX, IA, IB, AUX1, AUX2 isolated-amplifier pairs, biased open-safe, through difference amp + RC + clamp; ID; +24V out through an eFuse CELL contract 2x20: 8 PWM RS-422 drivers, 3 dual-range analog inputs, RDY, ID,
NTC; gate-driver supply +24V_GD through a 1.5 A eFuse (TPS26600) | SPRSP14E 7.10.1.5: 0.1 uF per VDDIO/VDD3VFL/VDDOSC ball, 2.2 uF per VDDA ball, ~22 uF total on VDD + one 56 R load, 22 uF per VREFHI (16-bit mode) CELL contract 2x20: 8 PWM RS-422 drivers, 3 dual-range analog inputs, RDY, ID,

### NTC; gate-driver supply +24V_GD through a 1.5 A eFuse (TPS26600)

Protection without firmware: FLT_LATCH_N -> INPUTXBAR1 -> TZ1; each cell's FAULT (INPUTXBAR2-5) and AN1 CMPSS window -> TRIP4/5/7/8; port OV (ADC PPB on VA/VB, CMPSS backup), open inputs (CMPSS low), IA/IB SC (CMPSS) and OC (PPB), P_ID (PPB) -> TRIP9 for every cell; E-stop ->

CELL contract 2x20: 8 PWM RS-422 drivers, 3 dual-range analog inputs, RDY, ID,
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

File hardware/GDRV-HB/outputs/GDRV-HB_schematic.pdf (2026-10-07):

1 | 2 | 3 | 4 | 5 | 6 | 7 | 8

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
Size: A3 | Rev: J0 | F Date: 2026-10-04
KiCad E.D.A. 10.0.6 | Id: 1/4

# Title: GDRV-HB half-bridge gate driver - Cover / Hierarchy

## File: GDRV-HB.kicad_sch

## Sheet: /

## Barrier: NSI6651ASC + UCC14241-Q1 reinforced (VIOWM 2121 / 1414 VDC) vs 1000 V bus

Schematics authored by Chinmoy Bhuyan

## Sheet 1

Not bench-validated. PELV = logic side; HS, LS = floating channels; DCP = DC+ sense.

## 03 Low-side channel File: sheets/03_low.kicad_sch 01 Logic interface

File: sheets/01_interface.kicad_sch | 02 High-side channel File: sheets/02_high.kicad_sch

Hardware dead time 105-385 ns at the gates = max(firmware, hardware); firmware >= 315 ns is never stretched. Module NTC: plain analog line on the power board (no AIN). Barrier: NSI6651ASC VIOWM 2121 VDC (certified), UCC14241-Q1 1414 VDC (certification planned); CMTI >= 150 V/ns.

Layout (not in this repo): card over the module signal pins, driver within 25 mm of J201/J301, gate loop < 100 mm (roadmap GDRV); D_H/D_L pins and DESAT strings need 1000 V + overshoot creepage per the ECO-10 insulation coordination.

DESAT trips at V_DS 5.4-8.5 V after 263-821 ns blanking; worst-case gate-off 0.51 us (module) / 0.54 us (3 discretes) vs tSC 3 us of IMZA120R020M1H. Wolfspeed CBB011M12GM4T / C3M datasheets give no tSC: unverified.

CALCULATED by gen/gdrv.py design_check(), not measured (full list in outputs/GDRV-HB_design_check.txt). Gate rails +14.78..15.45 / -3.95..-4.07 V. Bias 1.02 W of 2.0 W for the module at 100 kHz; worst case 3 x C3M0016120K 1.53 W. Peak gate current 4.1 / 7.2 A (10 A rating).

NSI6651ASC + UCC14241-Q1 +15/-4 V, DESAT (3 x US1M), interlock with PWM_L, gate/Kelvin pins to the module Rev J0 | 2026-10-04 | Schematics authored by Chinmoy Bhuyan | Two NSI6651ASC channels for one leg of a CBB011M12GM4T module (DAB-D60) NSI6651ASC + UCC14241-Q1 +15/-4 V, DESAT (3 x US1M), interlock with PWM_H,

# gate/Kelvin pins to the module GDRV-HB half-bridge gate driver

### J101 to the power board: +24V, 3.3 V, PWM_H/PWM_L (single-ended, already received from RS-422 on the power board), EN, FLT_N, RDY (pin 15 spare: GND)

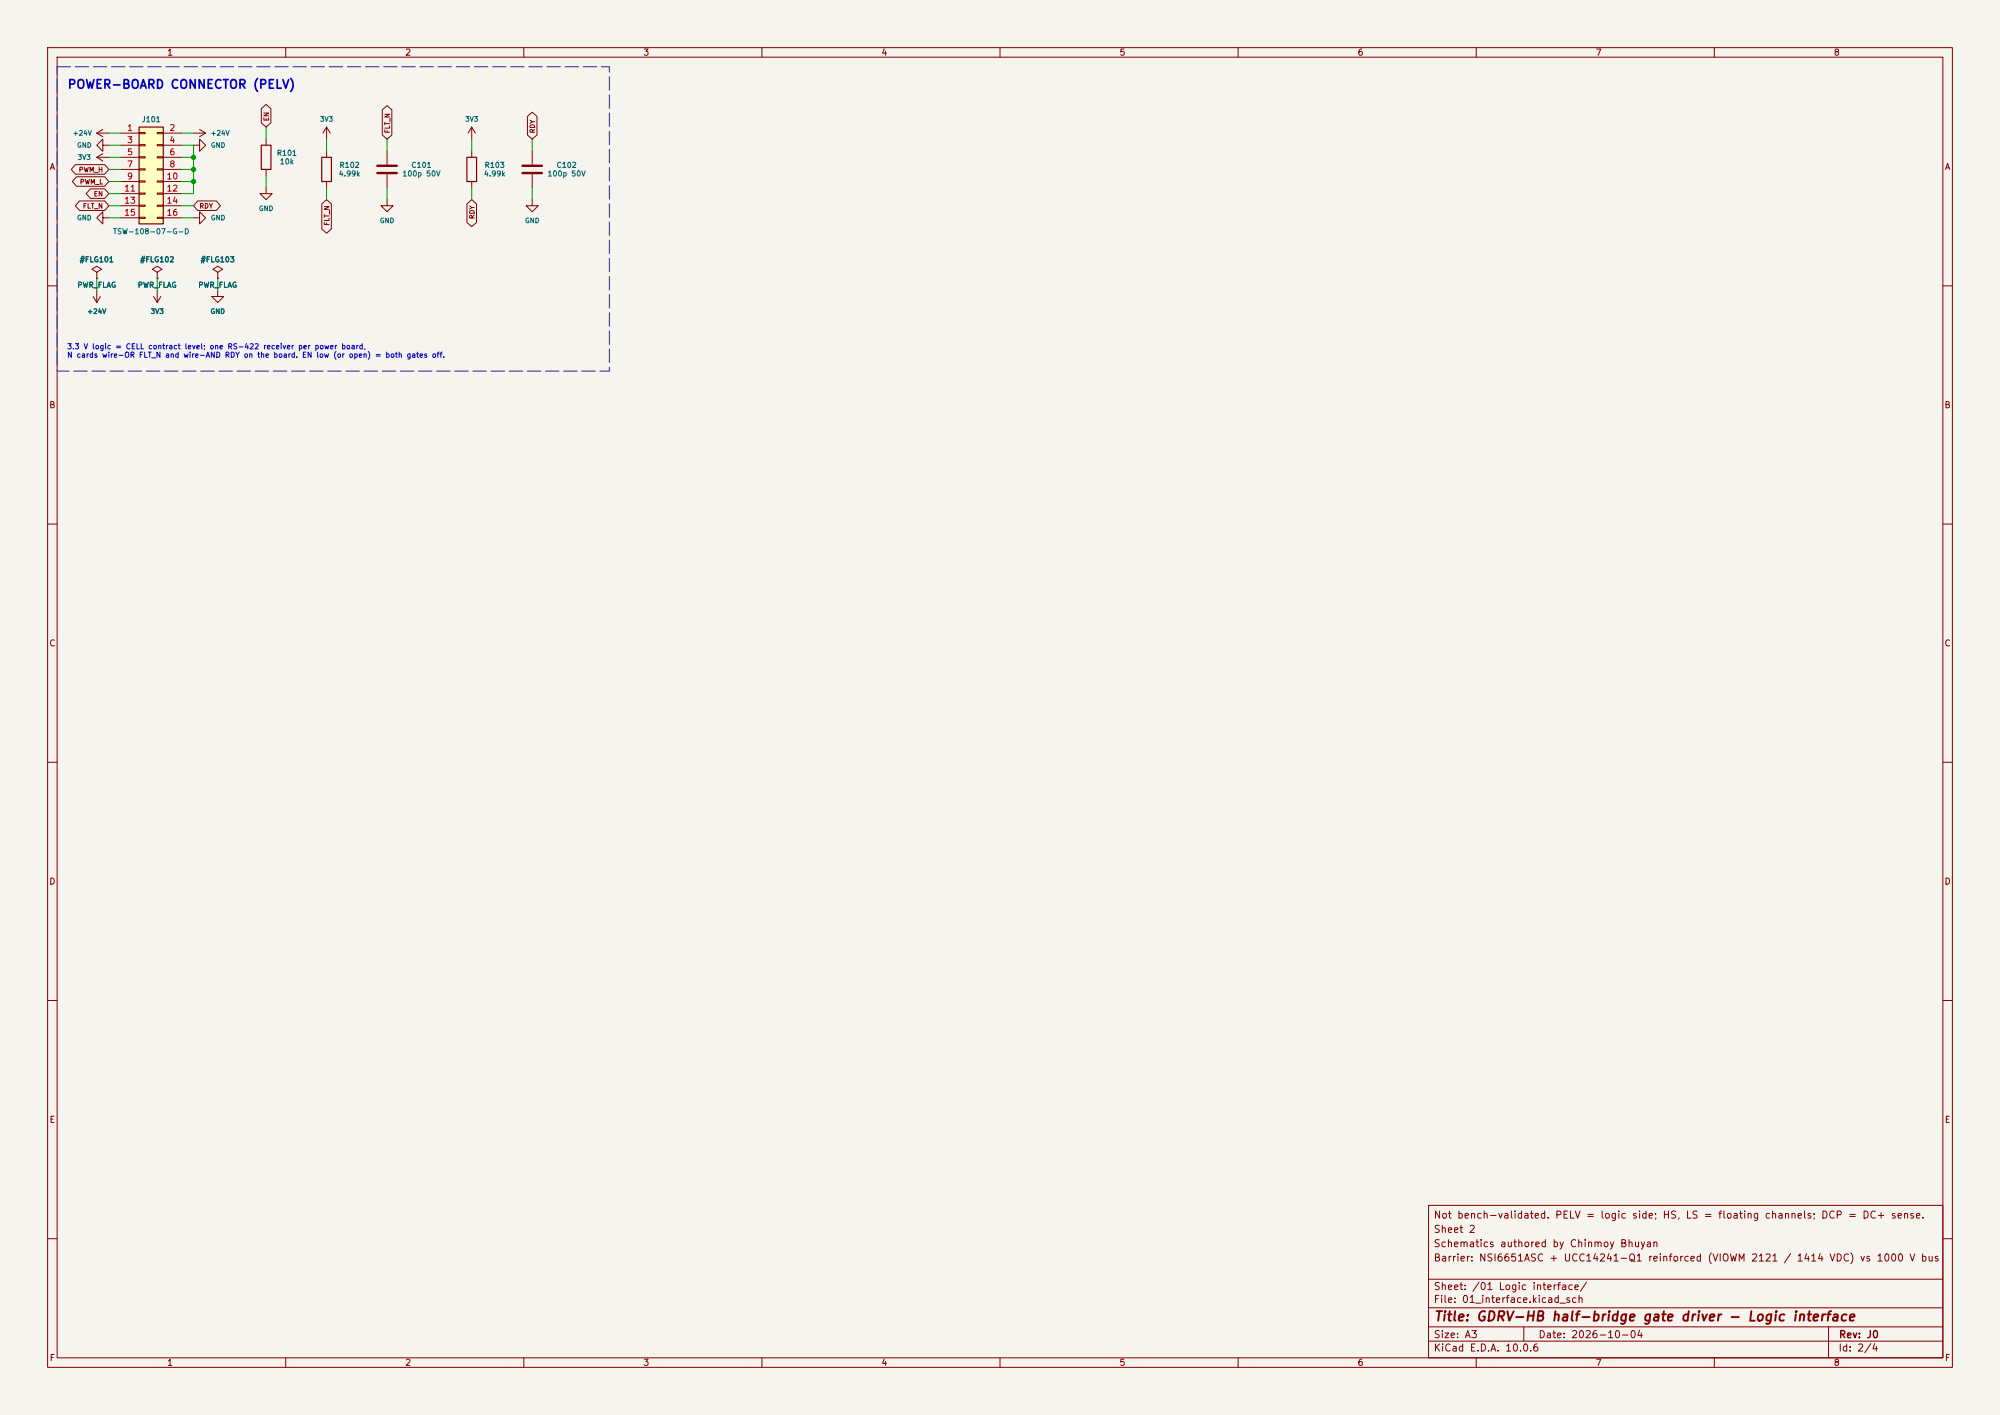
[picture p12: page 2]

Not bench-validated. PELV = logic side; HS, LS = floating channels; DCP = DC+ sense.
Sheet 2
Schematics authored by Chinmoy Bhuyan
Barrier: NSI6651ASC + UCC14241-Q1 reinforced (VIOWM 2121 / 1414 VDC) vs 1000 V bus

Sheet: /01 Logic interface/
File: 01_interface.kicad_sch
Title: GDRV-HB half-bridge gate driver - Logic interface

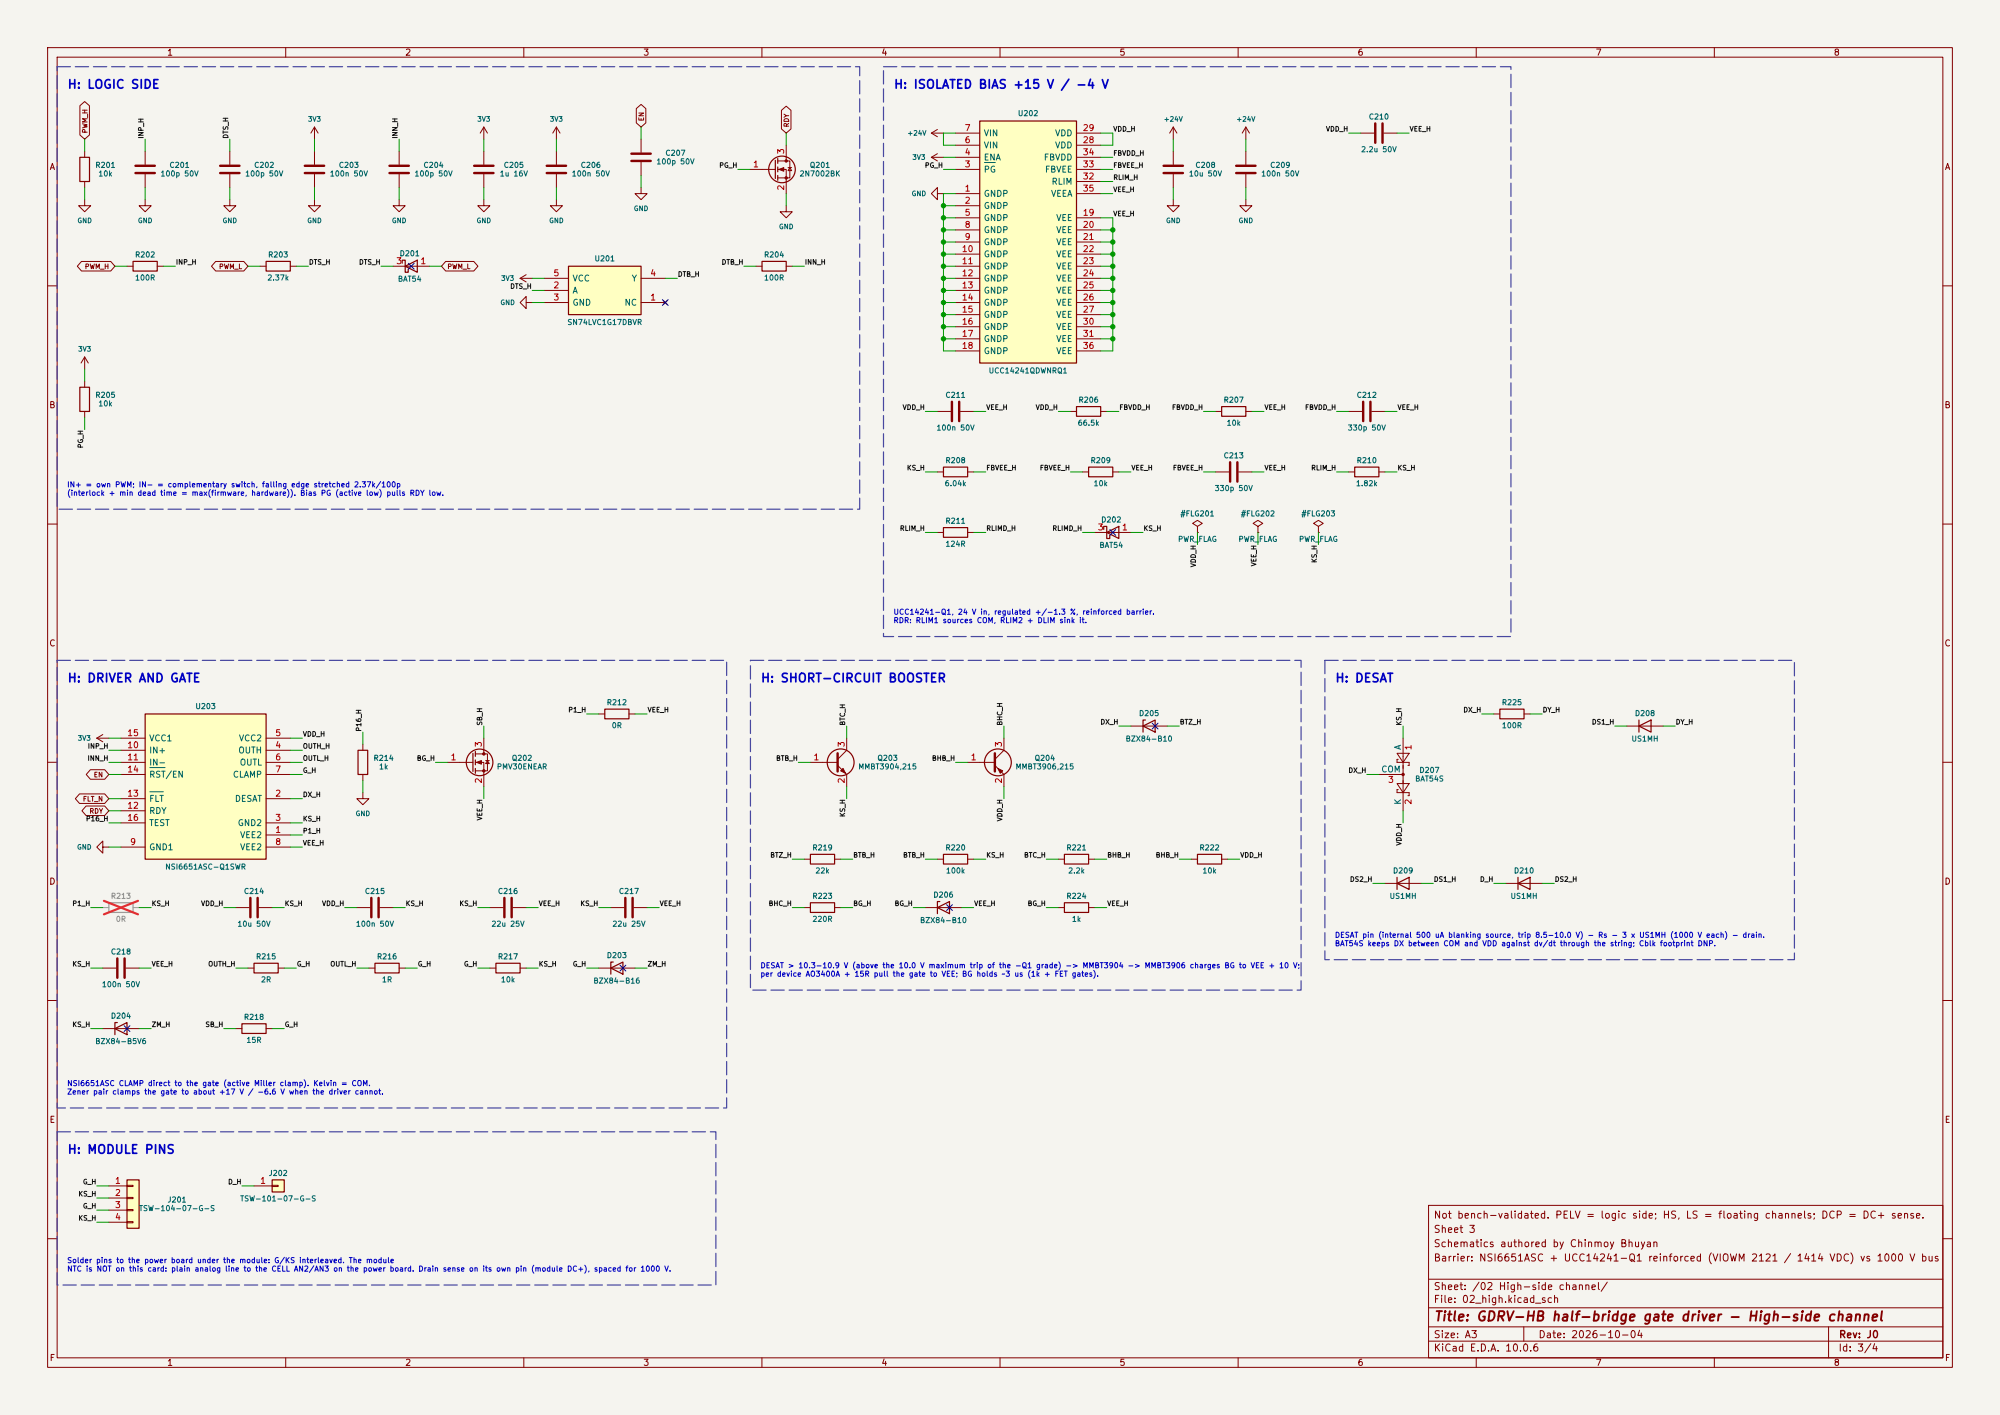
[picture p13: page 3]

IN+ = own PWM; IN- = complementary switch, falling edge stretched 2.37k/100p

DESAT pin (internal 500 uA blanking source, trip 8.5-10.0 V) - Rs - 3 x US1MH (1000 V each) - drain. BAT54S keeps DX between COM and VDD against dv/dt through the string; Cblk footprint DNP. H: DESAT
D207 BAT54S D209 US1MH

NSI6651ASC CLAMP direct to the gate (active Miller clamp). Kelvin = COM. Zener pair clamps the gate to about +17 V / -6.6 V when the driver cannot.

Not bench-validated. PELV = logic side; HS, LS = floating channels; DCP = DC+ sense.
Sheet 3
Schematics authored by Chinmoy Bhuyan
Barrier: NSI6651ASC + UCC14241-Q1 reinforced (VIOWM 2121 / 1414 VDC) vs 1000 V bus

Solder pins to the power board under the module: G/KS interleaved. The module NTC is NOT on this card: plain analog line to the CELL AN2/AN3 on the power board. Drain sense on its own pin (module DC+), spaced for 1000 V.

Sheet: /02 High-side channel/
File: 02_high.kicad_sch
Title: GDRV-HB half-bridge gate driver - High-side channel

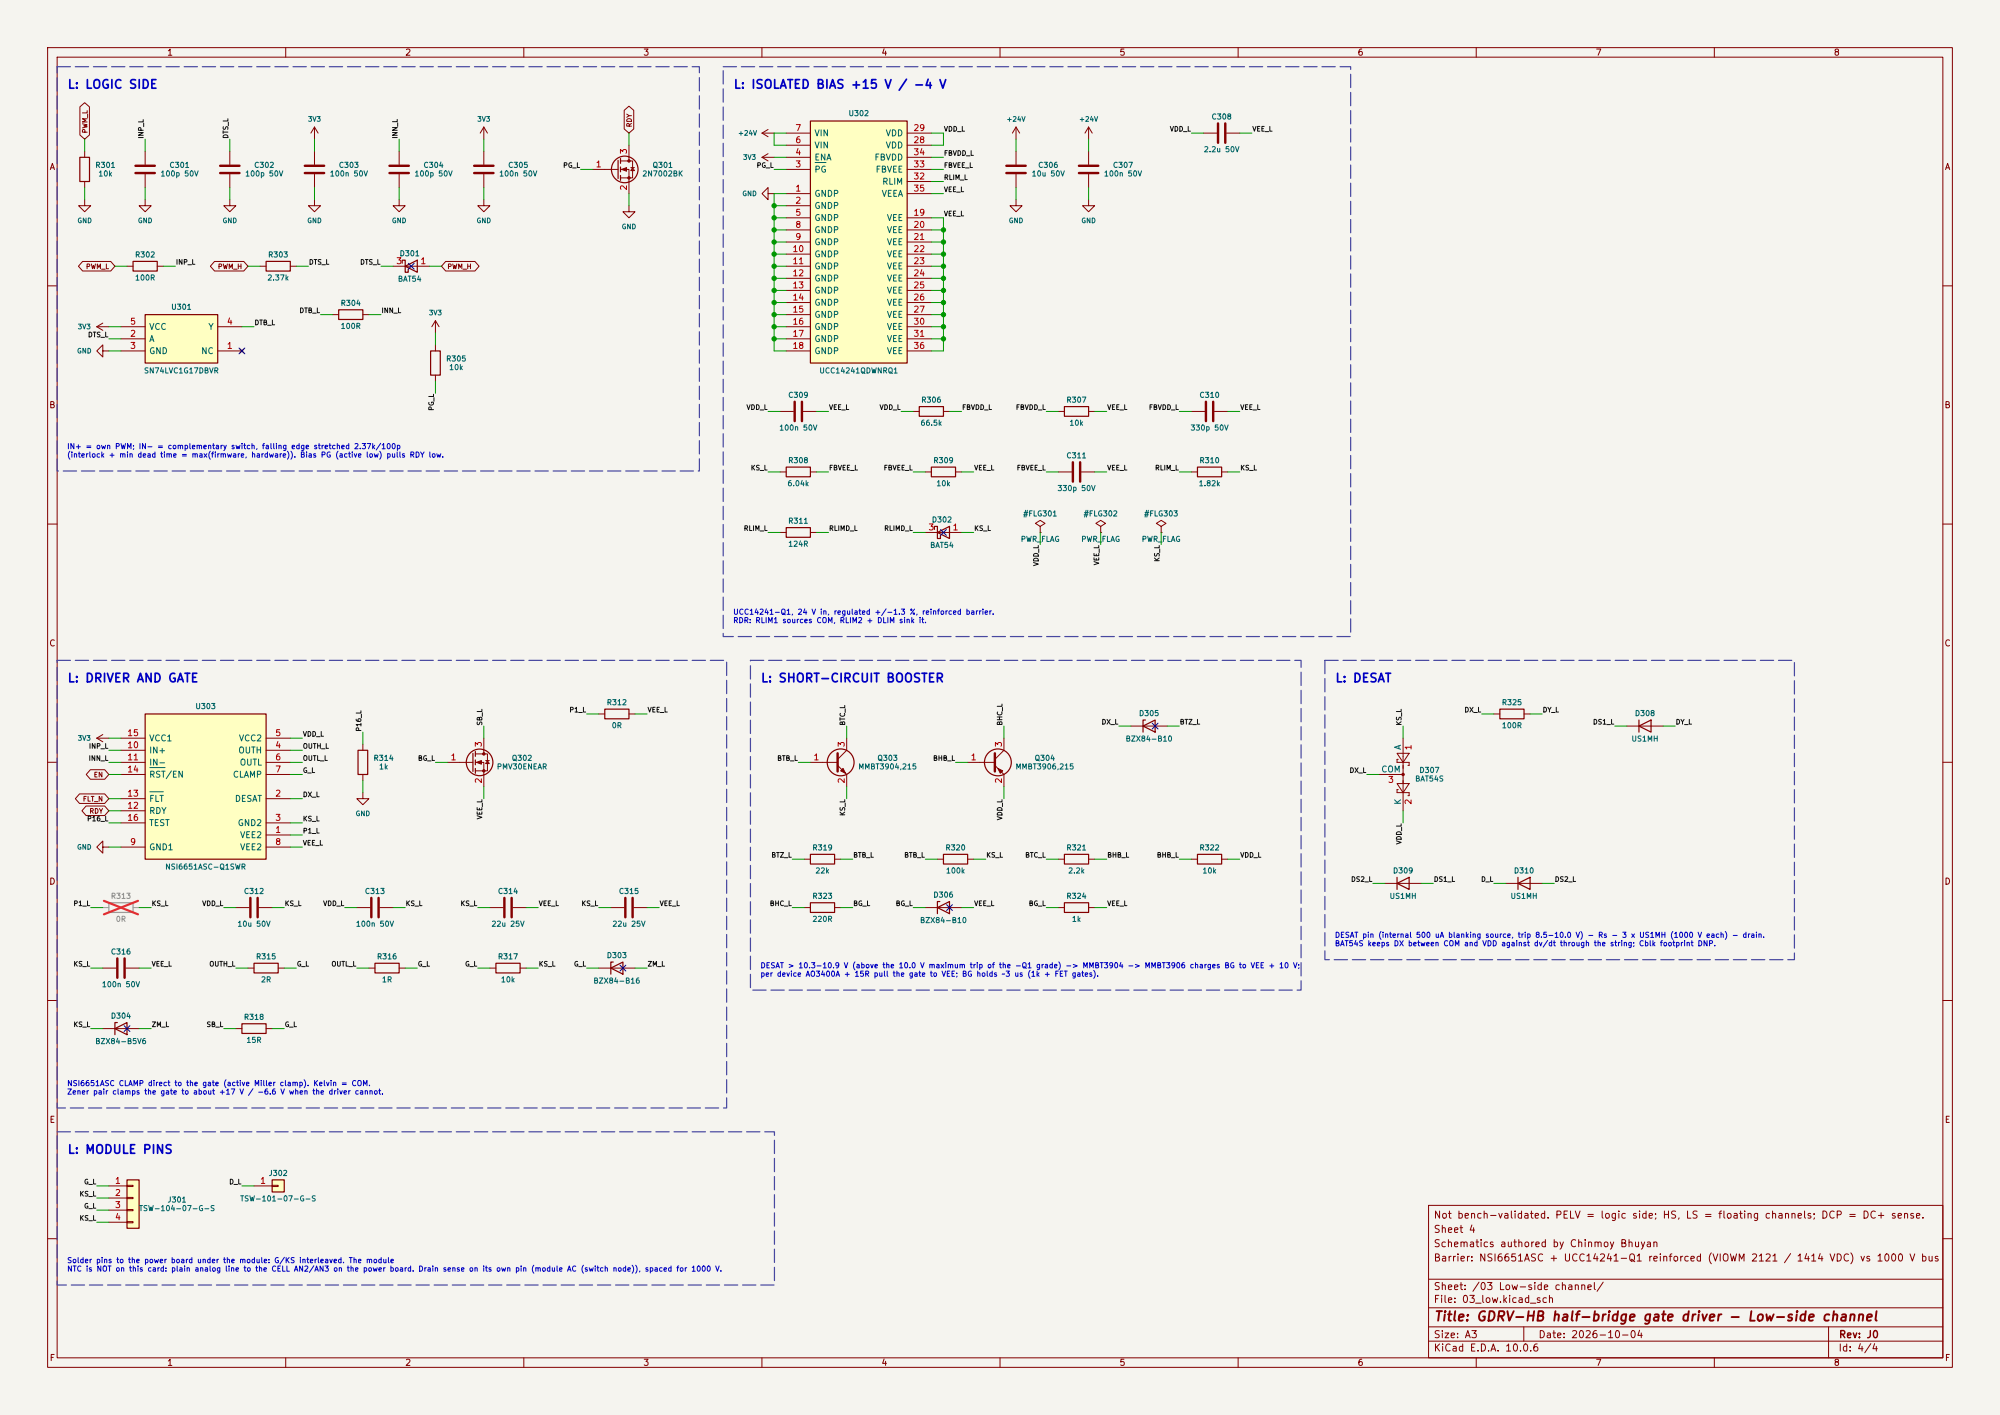
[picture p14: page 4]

IN+ = own PWM; IN- = complementary switch, falling edge stretched 2.37k/100p

UCC14241-Q1, 24 V in, regulated +/-1.3 %, reinforced barrier. RDR: RLIM1 sources COM, RLIM2 + DLIM sink it. L: DRIVER AND GATE
U303 NSI6651ASC-Q1SWR

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

Not bench-validated. PELV = logic side; HS, LS = floating channels; DCP = DC+ sense.
Sheet 4
Schematics authored by Chinmoy Bhuyan
Barrier: NSI6651ASC + UCC14241-Q1 reinforced (VIOWM 2121 / 1414 VDC) vs 1000 V bus

Sheet: /03 Low-side channel/
File: 03_low.kicad_sch
Title: GDRV-HB half-bridge gate driver - Low-side channel

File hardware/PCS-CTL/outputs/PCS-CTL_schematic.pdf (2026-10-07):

1 | 2 | 3 | 4 | 5 | 6 | 7 | 8

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
Size: A3 | Rev: A0
KiCad E.D.A. 10.0.6 | Id: 1/10 | F Date: 2026-10-05

# Title: PCS-CTL control board - Cover / Hierarchy

## File: PCS-CTL.kicad_sch

## Sheet: /

LIVE zone = BUS- (hazardous live); SELV zone behind reinforced barrier B1

Schematics authored by Chinmoy Bhuyan

## Sheet 1

Not bench-validated. All bands and budgets calculated in design_check().

# 09 Ethernet bridge (EMS, Modbus TCP)

File: sheets/09_eth.kicad_sch | 07 SELV supply, fans, stop, DI1, relay

# File: sheets/07_selv.kicad_sch 06 Barrier B1: isolators, CAN, RS-485

File: sheets/06_iso.kicad_sch 01 PC connector, supply, reset File: sheets/01_supply.kicad_sch

# 02 F280039C, clock, debug, recorder flash

File: sheets/02_mcu.kicad_sch | 03 Reference and analog front ends
File: sheets/03_afe.kicad_sch | 04 Hardware trip comparators

File: sheets/04_trip.kicad_sch

# 08 PCS_X: grid voltages, RCM, NTC9, K_AC2

File: sheets/08_pcsx.kicad_sch

# 05 Trip latch, watchdog, gating

File: sheets/05_latch.kicad_sch Pin plan: gen/data/pcs_ctrl_pin_plan.csv (from SPRSP61C, checked every build).

Assembly option: the two TLV9024 marked 'four-wire only' are not fitted on the three-wire build (bom/PCS-CTL-3W_BOM.csv); the four-wire build fits every part (bom/PCS-CTL-4W_BOM.csv).

ARCHITECTURE-PCS section 6; the PV-CTL schematic re-valued by gen/pcs_ctrl.py; PCS_PC / PCS_X levels as built on PCS-PWR (hardware/PCS-PWR/outputs/PCS-PWR_design_check.txt).

Rev A0 | 2026-10-05 | Schematics authored by Chinmoy Bhuyan | PCS-P125 inverter controller, PV-CTL assembly variant: F280039C on DC-, one trip latch

Reinforced barrier B1: CA-IS3050W CAN, CA-IS3082WNX RS-485, 2 x CA-IS3821LG,

### CA-IS3820LG, CA-IS3842HW (Ethernet UART, DI1); bus TVS, jumper terminations (SELV)

# PCS-CTL control board

7 x TLV9024 on +3V3 (open drain, no firmware): IL windows from each sensor's Uref; VA / VB over-voltage, NTC over-temperature and open probe from VREF ladders REF3030E 3.0 V = VREFHI = VDAC = NTC bias = trip thresholds; IL1-4 gain stages;

### power-board signals into the ADC through 100 R / 1 nF; 8 NTC biases + inlet NTC

SELV 24 V input (AUX-T1 reinforced winding, 12-36 V), TPS54360B 5 V and fan supply, 3 fan headers + tach, stop (chainable) / ready / DI1 terminals, relay, SELV 0 V to PE | 2x8 PCS_X contract to PCS-PWR (all LIVE): K_AC2 from the gating (sheet 05), RCM_TST from GPIO21; grid voltages, RCM and NTC9 into the ADC
74LVC07 wired-AND of every trip source -> PRE_N -> 74LVC1G74 latch (no firmware); heartbeat monoflop; 74LVC08 gating of 16 PWM, EN, K_A, K_B, K_PRE, STATUS, FAN WCH CH9121T UART-to-Ethernet bridge on the SELV side, HR913550AE RJ45 with | magnetics,

SRV05-4, TPS7A2033 3.3 V. FITTED on this variant.

2x32 PC contract to the power board (all LIVE): only +3V3 is used (200 mA allocated by PV-PWR); TPS3828 reset + 1.6 s watchdog

### TMS320F280039C (100-pin PZ), decoupling, 25 MHz SPXO, cTI-20 header in cJTAG mode

(LIVE), 4 MB recorder flash, boot straps, command pull-downs

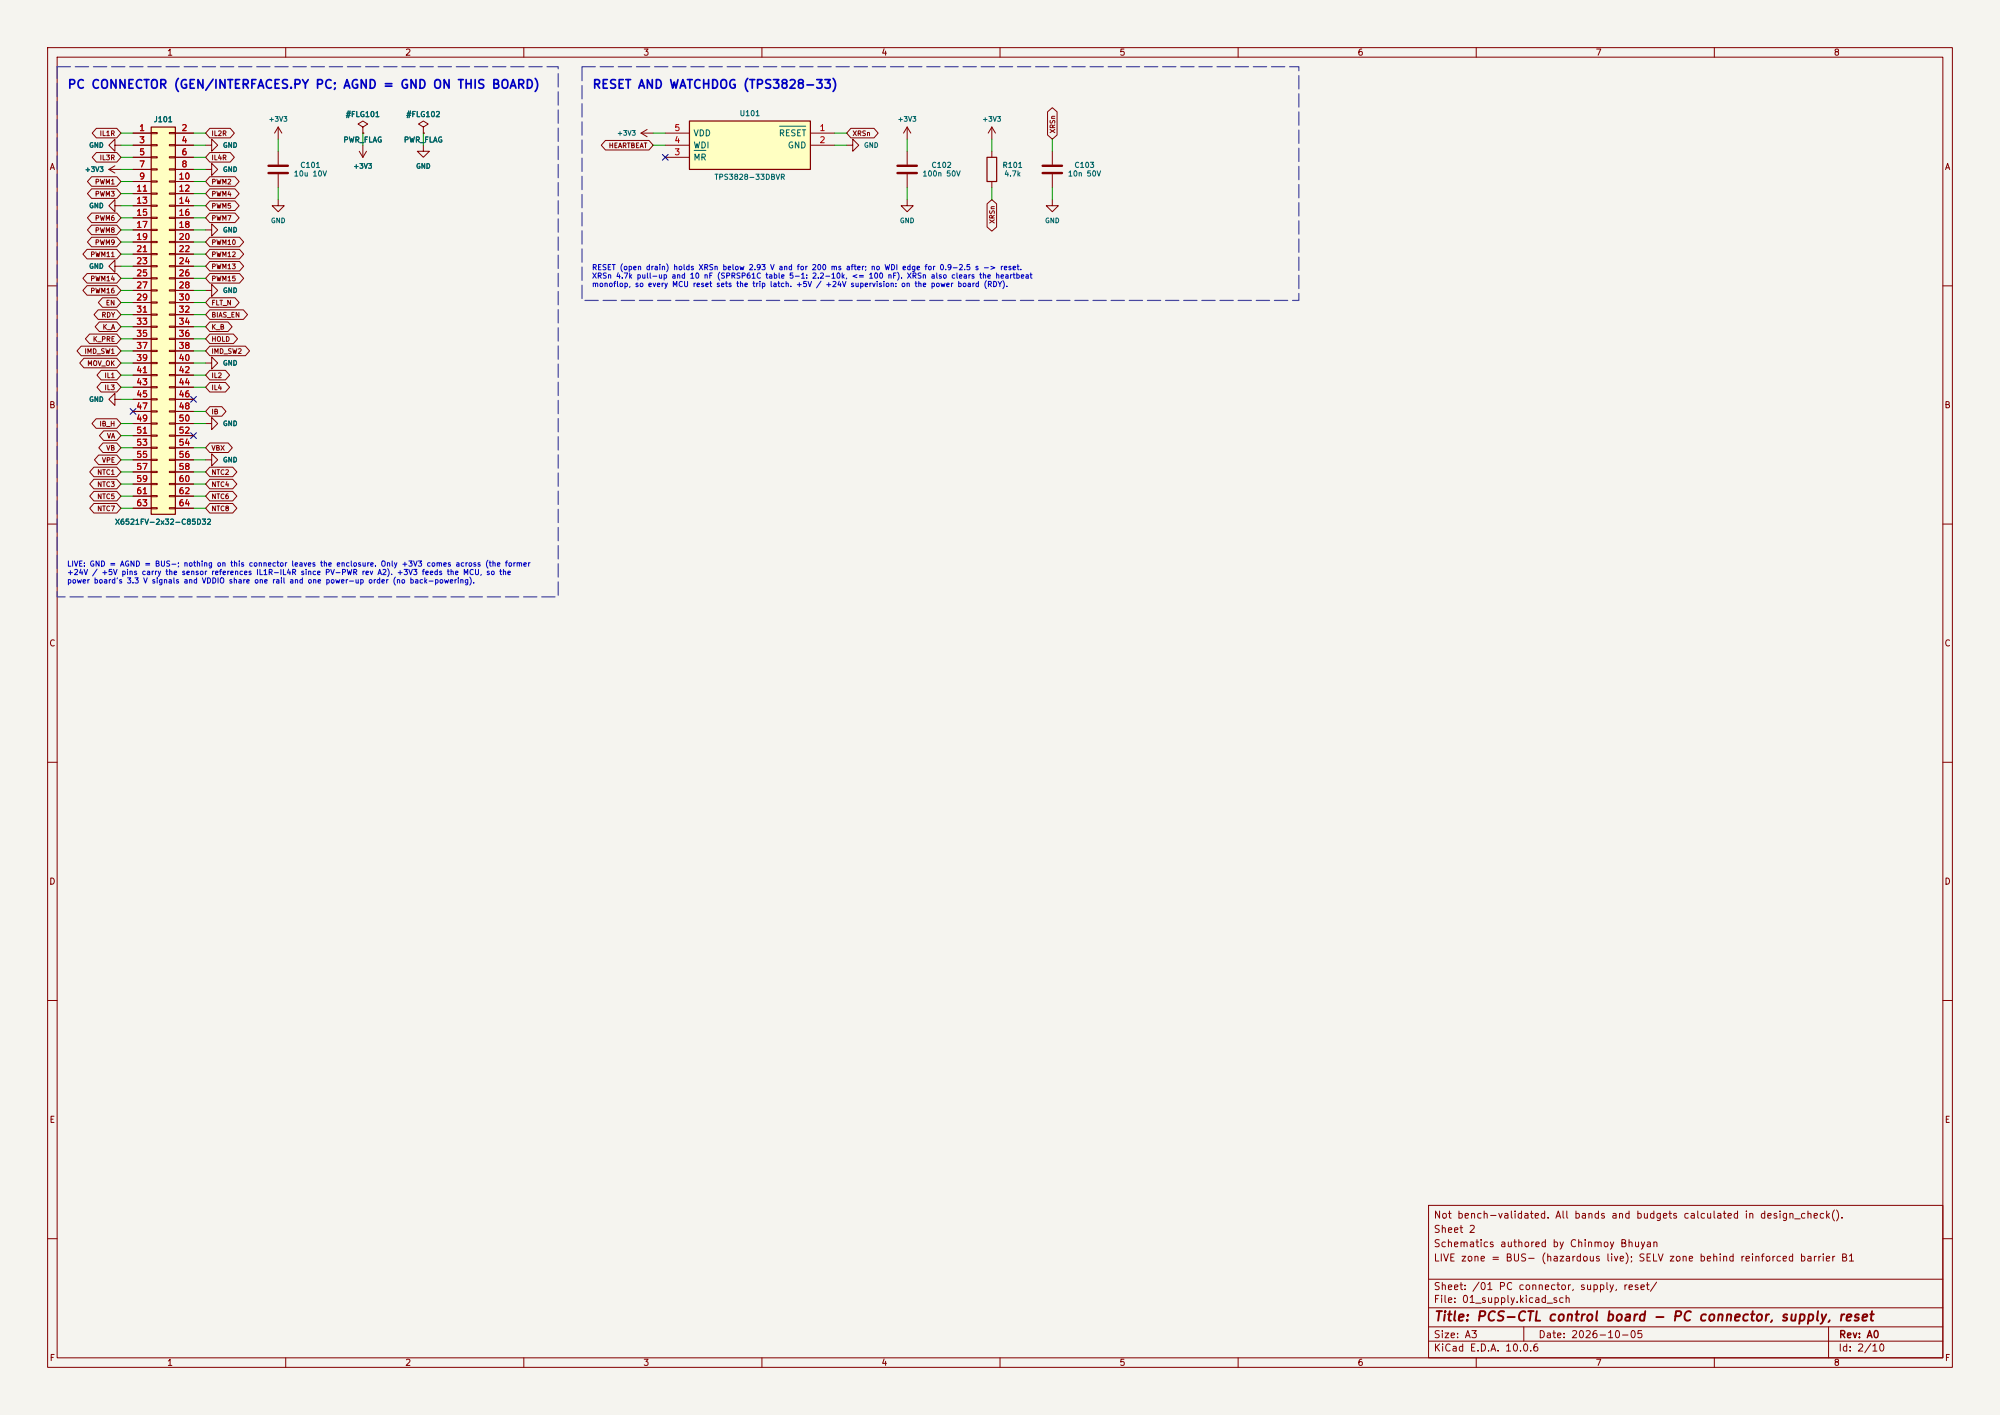
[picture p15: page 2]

RESET (open drain) holds XRSn below 2.93 V and for 200 ms after; no WDI edge for 0.9-2.5 s -> reset. XRSn 4.7k pull-up and 10 nF (SPRSP61C table 5-1: 2.2-10k, <= 100 nF). XRSn also clears the heartbeat monoflop, so every MCU reset sets the trip latch. +5V / +24V supervision: on the power board (RDY).

LIVE: GND = AGND = BUS-; nothing on this connector leaves the enclosure. Only +3V3 comes across (the former +24V / +5V pins carry the sensor references IL1R-IL4R since PV-PWR rev A2). +3V3 feeds the MCU, so the power board's 3.3 V signals and VDDIO share one rail and one power-up order (no back-powering).

Not bench-validated. All bands and budgets calculated in design_check().
Sheet 2
Schematics authored by Chinmoy Bhuyan
LIVE zone = BUS- (hazardous live); SELV zone behind reinforced barrier B1

Sheet: /01 PC connector, supply, reset/
File: 01_supply.kicad_sch
Title: PCS-CTL control board - PC connector, supply, reset

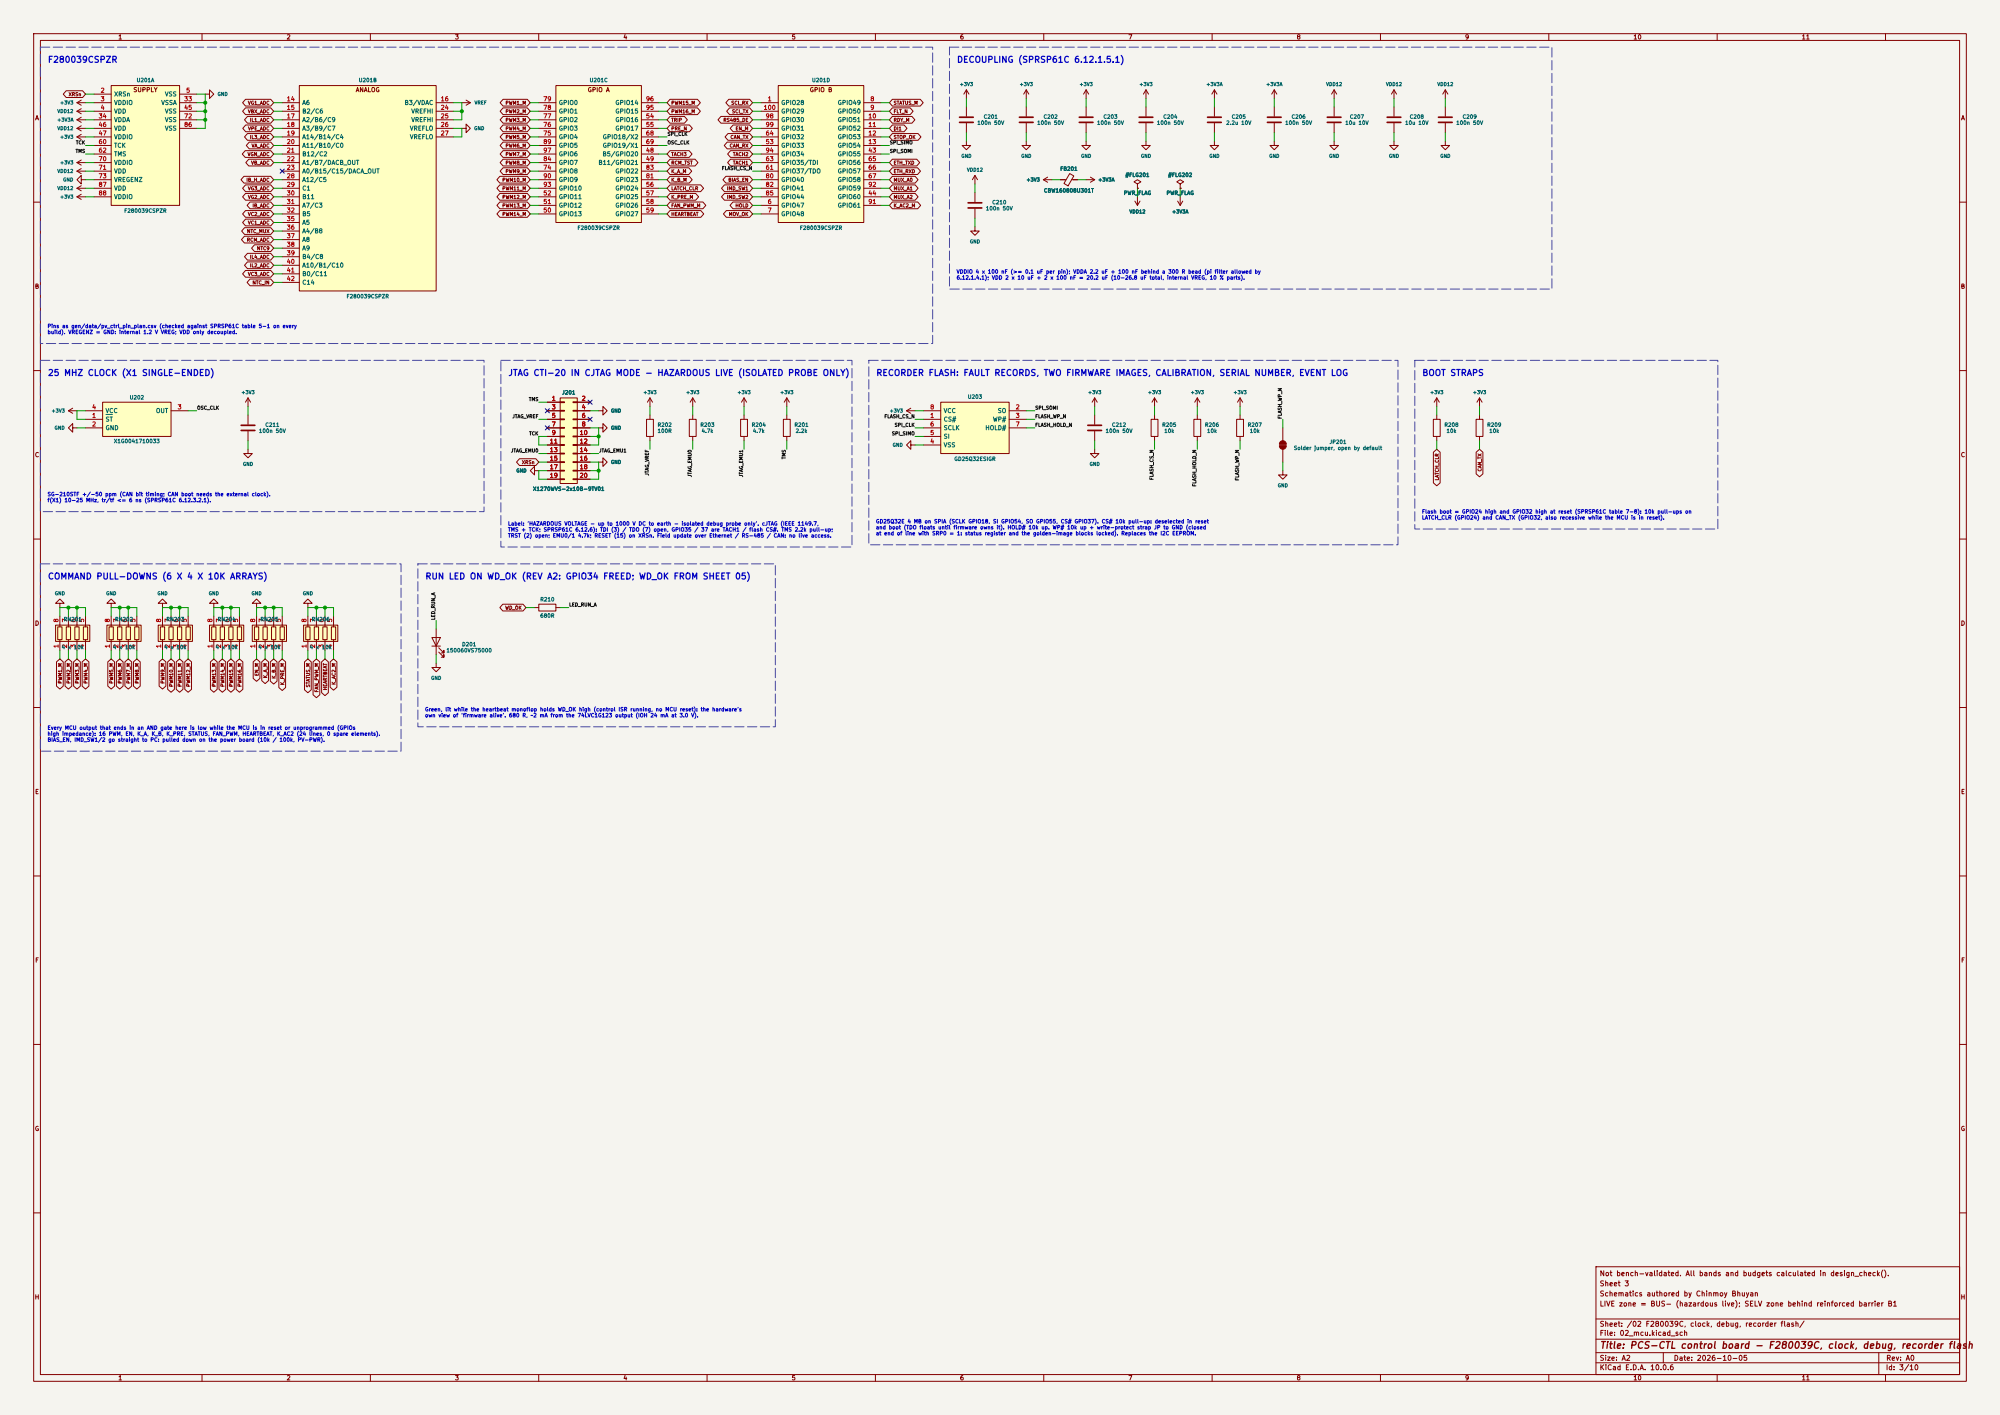
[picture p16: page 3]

25 MHZ CLOCK (X1 SINGLE-ENDED)

at end of line with SRP0 = 1: status register and the golden-image blocks locked). Replaces the I2C EEPROM. RECORDER FLASH: FAULT RECORDS, TWO FIRMWARE IMAGES, CALIBRATION, SERIAL NUMBER, EVENT LOG

Solder jumper, open by default

LATCH_CLR (GPIO24) and CAN_TX (GPIO32, also recessive while the MCU is in reset).

COMMAND PULL-DOWNS (6 X 4 X 10K ARRAYS)

RUN LED ON WD_OK (REV A2: GPIO34 FREED; WD_OK FROM SHEET 05)
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

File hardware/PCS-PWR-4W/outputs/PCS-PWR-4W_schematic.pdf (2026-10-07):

1 | 2 | 3 | 4 | 5 | 6 | 7 | 8

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
Title: PCS-P125 power 4W - Cover / Hierarchy | L2 out / N_F -> K1 -> K2 (4-pole) -> CM choke (4 bars) -> AC terminals L1-L3, N; coil drivers; 4 x TVT25751 + 4 x Y1 to PE_T; type-B RCM sensor around L1-L3 + | N
Size: A3 | | | Rev: A0
KiCad | E.D.A. 10.0.6 | | Id: 1/32 | F Date: 2026-10-06

## File: PCS-PWR-4W.kicad_sch

## Sheet: /

Live board referenced to DC-; gate islands functional; HV-PE basic

Schematics authored by Chinmoy Bhuyan

## Sheet 1

Not bench-validated. Values read from sim/out/pcs_design/pcs_spec.json; checks: design_check()

# 15 Phase a LCL filter, current sensor

File: sheets/15_filta.kicad_sch 19 AC voltage sensing

File: sheets/19_acsense.kicad_sch | 20 Port B power path (battery)

File: sheets/20_leanB_power.kicad_sch

# 02 DC link, bleeders, sensing

File: sheets/02_dclink.kicad_sch | 03 Phase leg a, power stage

File: sheets/03_lega.kicad_sch

# 06 Neutral leg n, power stage

File: sheets/06_legn.kicad_sch

23 DC terminals, insulation test File: sheets/23_dcterm.kicad_sch

# 07 Leg a high-side gate drive

File: sheets/07_gdah.kicad_sch

# 11 Leg c high-side gate drive

File: sheets/11_gdch.kicad_sch

# 08 Leg a low-side gate drive

File: sheets/08_gdal.kicad_sch

# 04 Phase leg b, power stage

File: sheets/04_legb.kicad_sch

# 12 Leg c low-side gate drive

File: sheets/12_gdcl.kicad_sch

# 17 Phase c LCL filter, current sensor

# File: sheets/17_filtc.kicad_sch 29 AUX75 PWM, SiC, clamp, AUX-T1

# 21 Port B sensing and interlocks

File: sheets/21_leanB_ctrl.kicad_sch

# 16 Phase b LCL filter, current sensor

# File: sheets/16_filtb.kicad_sch 28 AUX75 start-up, brown-in, OV, timer

# 24 AC port: contactors, SPD, RCM (four-wire)

File: sheets/24_acport.kicad_sch

# 01 Control connectors, defaults

File: sheets/01_pc.kicad_sch

# 05 Phase leg c, power stage

File: sheets/05_legc.kicad_sch

# 22 Port B coil drives

File: sheets/22_leanB_drive.kicad_sch 18 Neutral leg filter, current sensor

File: sheets/18_filtn.kicad_sch 13 Leg n high-side gate drive

File: sheets/13_gdnh.kicad_sch

# 09 Leg b high-side gate drive

File: sheets/09_gdbh.kicad_sch
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

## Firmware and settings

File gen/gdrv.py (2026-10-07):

"""GDRV - isolated SiC gate-driver channel block (rev 5, D-035: NOVOSENSE NSI6651ASC; D-036: TI UCC14241-Q1 bias) and the
GDRV-HB card.

1. Reusable block:  `channel(B, tag, pwm, en, flt_n, rdy, gate, source, drain, vdd, vee, ...)` adds ONE isolated
   channel to the current sheet of Builder B (it opens its own blocks there) and returns Channel(iso, xing, sec):
   iso = barrier refs (driver + bias module), xing = DESAT diode refs (they touch the drain), sec = the channel's
   floating-domain nets (use them in domain_of). Example, one leg on a power board:

       for leg in (1, 2):
           for side, other in (("H", "L"), ("L", "H")):
               t = "%s%d" % (side, leg)
               ch = gdrv.channel(B, t, pwm="PWM_%s" % t, en="EN", flt_n="FLT_N", rdy="RDY", gate="G_" + t,
                                 source="KS_" + t, drain="D_" + t, vdd="VDD_" + t, vee="VEE_" + t,
                                 interlock="PWM_%s%d" % (other, leg), r_on=2.0, r_off=1.0)
   Paralleled devices (PV cell, D-037: 2 x SG2M040170HJ per switch) - one gate net AND one Kelvin net per device;
   r_on/r_off are then per device:
       ch = gdrv.channel(B, t, ..., gate=("G_%sa" % t, "G_%sb" % t), source=("KS_%sa" % t, "KS_%sb" % t),
                         gate_v=(18, 3.5), vclass=1700, r_on=3.75, r_off=2.5, r_sb=22.0, v_peak=1396.0)
   net_ranges(...) returns the channel's DC net ranges for dcdclib.build(vrange=...).
   The caller adds once per shared net: FLT_N and RDY pull-ups (4.99k + 100p), EN pull-down (10k), PWR_FLAG on
   the logic rails.

2. `.venv/bin/python gen/gdrv.py` builds GDRV-HB: two channels for one leg of a CBB011M12GM4T full-bridge module.

Per channel (NSI66x1A-Q1 Rev 1.1 application section 9; UCC14241-Q1 SLUSF09A section 12.2):
  logic   IN+ = own PWM (100R/100p, 10k pull-down: an open or unpowered input is a low input -> gate off);
          IN- = the complementary switch's PWM, falling edge stretched (2.21k/100p + BAT54 + SN74LVC1G17 Schmitt):
          the driver ANDs IN+ with /IN- -> shoot-through interlock + a minimum dead time that
          equals max(firmware dead time, hardware stretch) and never adds delay to a correctly timed edge.
          RDY/FLT open drain (wired-AND / wired-OR on the caller's net); bias power-good pulls RDY low via 2N7002BK.
  bias    UCC14241-Q1 24 V -> +15/-4 V or +20/-4 V (VDD-COM / COM-VEE, GATE_V), regulated, reinforced barrier, RDR.
  gate    split Ron/Roff, CLAMP straight to the gate (Miller clamp), 10k gate-source, anti-series Zener clamp; with
          paralleled devices all of that per device plus an AO3400A Miller clamp at the gate-Kelvin pins (see channel()).
  DESAT   NSI6651 DESAT pin (internal blanking source), Rs + HV diode string to the drain, BAT54S clamp: 1700 V-device presets
          (PV cell, PCS) 2 x BYG23T-M3 (1300 V each, review R4 / E01); 1200 V class (DAB / GDRV-HB) 3 x US1MH (1000 V).
  SC      booster: DESAT above the driver's maximum trip fires an AO3400A + R_sb per gate (two-level, then fast off).
  NTC     none on the driver (no AIN/APWM): thermistors are plain analog lines to the CELL connector AN2/AN3.
Design numbers are computed and asserted by design_check() on every build.
"""
import math
import os
import sys
from collections import namedtuple

import json

import catalog
import dcdclib as L

# T_BIAS4 design by the magnetics engineer (rev M1): ratio, barrier capacitances, cost - read, not copied
_XF = json.load(open(os.path.join(os.path.dirname(os.path.dirname(os.path.abspath(__file__))), "sim", "out", "magnetics",
                                  "design_gdrv_bias_transformer.json")))
XF_N = _XF["electrical"]["ratio"]
XF_C = _XF["electrical"]["capacitance_F"]          # adjacent / one_apart / two_apart / high_side_to_primary
XF_COST = (_XF["cost"]["catalogue_1k_usd"], _XF["cost"]["build_5k_usd"])

PROJECT, REV, DATE = "GDRV-HB", "J0", "2026-10-04"
DS = "docs/datasheets/"
TI, NXP = "Texas Instruments", "Nexperia"
DS_SAMTEC = "https://suddendocs.samtec.com/catalog_english/tsw_th.pdf"

PARTS = {
    # UCC21710 SLUSD43B (May 2023): pins Table 5-1 + Fig 5-1 p3. Limits: abs max/ROC p4, insulation p6-7,
    # electrical p8-9, switching p10, function table p29, application p31-44.
    "UCC21710": dict(mfr=TI, mpn="UCC21710DWR", prefix="U", pkg="SOIC-16W (DW)", ds=DS + "gate-drivers/UCC21710.pdf",
                     desc="Isolated SiC gate driver 10 A, OC/DESAT, soft turn-off, Miller clamp, AIN-APWM; reinforced "
                          "VDE 0884-17, VIOWM 2121 VDC, CMTI >= 150 V/ns",
                     pins={"left": ["15 VCC pi", "10 IN+ i", "11 IN- i", "14 RST/EN i", None, "13 ~{FLT} oc",
                                    "12 RDY oc", "16 APWM o", None, "9 GND pi"],
                           "right": ["5 VDD pi", "4 OUTH o", "6 OUTL o", "7 CLMPI o", None, "2 OC i", "1 AIN i",
                                     None, "3 COM pi", "8 VEE pi"]}),
    # NOVOSENSE NSI66x1A-Q1 Rev 1.1 (docs/datasheets/gate-drivers/NSI66x1A-Q1.pdf; industrial twin NSI66x1A.pdf):
    # NSI6651ASC pin table p3 (1 and 8 VEE2, 2 DESAT, 3 GND2, 4 OUTH, 5 VCC2, 6 OUTL, 7 CLAMP | 9 GND1, 10 IN+, 11 IN-,
    # 12 RDY, 13 /FLT, 14 /RST(EN), 15 VCC1, 16 TEST "recommended to connect to GND1"). Abs max / ROC p4, UVLO p6,
    # outputs + clamp + logic p7, DESAT + soft turn-off p9, timing p9-10, insulation p15-16, certificates p18.
    # Primary: -Q1SWR (AEC-Q100 grade 1, -40..150 C); alternate: NSI6651ASC-DSWR (industrial, ISTO >= 250 mA).
    "NSI6651ASC": dict(mfr="NOVOSENSE", mpn="NSI6651ASC-Q1SWR", prefix="U", pkg="SOW-16 (10.3 x 7.5 mm)",
                       ds=DS + "gate-drivers/NSI66x1A-Q1.pdf",
                       desc="Isolated smart SiC gate driver 10 A, DESAT + soft turn-off, Miller clamp, FLT/RDY; reinforced "
                            "VDE 0884-17 (40052820) VIORM 2121 Vpk, UL 1577 5.7 kVrms; AEC-Q100 grade 1. Alternate: "
                            "NSI6651ASC-DSWR",
                       pins={"left": ["15 VCC1 pi", "10 IN+ i", "11 IN- i", "14 ~{RST}/EN i", None, "13 ~{FLT} oc",
                                      "12 RDY oc", "16 TEST i", None, "9 GND1 pi"],
                             "right": ["5 VCC2 pi", "4 OUTH o", "6 OUTL o", "7 CLAMP o", None, "2 DESAT i", None,
                                       "3 GND2 pi", "1 VEE2 p", "8 VEE2 pi"]}),   # pin 1 passive: 0R option VEE / COM (UCC21750 AIN)
    # UCC14241-Q1 SLUSF09A (Aug 2023): pins Table 6-1 + Fig 6-1 p4-5; VIN 21-27 V p6; insulation p7-8 (VIOWM 1414 VDC,
    # reinforced, certification PLANNED); 2 W at TA <= 85 C, 1.5 W at 105 C p1/p9; design equations p32-39.
    "UCC14241": dict(mfr=TI, mpn="UCC14241QDWNRQ1", prefix="U", pkg="SSOP-36 (DWN)", ds=DS + "gate-drivers/UCC14241-Q1.pdf",
                     desc="Isolated DC/DC module 24 V in, 2 W, adjustable VDD-VEE and COM-VEE, PG, reinforced (planned "
                          "VDE 0884-17) VIOWM 1414 VDC, CIO < 3.5 pF, CMTI > 150 V/ns",
                     pins={"left": ["7 VIN pi", "6 VIN pi", "4 ENA i", "3 ~{PG} oc", None]
                           + ["%d GNDP pi" % n for n in (1, 2, 5, 8, 9, 10, 11, 12, 13, 14, 15, 16, 17, 18)],
                           "right": ["29 VDD p", "28 VDD p", "34 FBVDD i", "33 FBVEE i", "32 RLIM p", "35 VEEA p", None]
                           + ["%d VEE p" % n for n in (19, 20, 21, 22, 23, 24, 25, 26, 27, 30, 31, 36)]}),
    # SN74LVC1G17 SCES351Y: DBV pins p3; VT+/VT- Table 5-1 p6; tpd 1.5-4.6 ns at 3.3 V p7; CI 4.5 pF p6.
    "SN74LVC1G17": dict(mfr=TI, mpn="SN74LVC1G17DBVR", prefix="U", pkg="SOT-23-5 (DBV)",
                        ds=DS + "isolation-interface/SN74LVC1G17.pdf", desc="Single Schmitt-trigger buffer, 3.3 V",
                        pins={"left": ["5 VCC pi", "2 A i", "3 GND pi"], "right": ["4 Y o", None, "1 NC nc"]}),
    # Nexperia BAT54 (1 Jul 2022): Table 2 p2 pin 1 A, 2 n.c., 3 K (= KiCad BAT54W numbering); VF <= 320 mV at 1 mA p4.
    "BAT54": dict(mfr=NXP, mpn="BAT54", prefix="D", pkg="SOT-23", stock=("Diode", "BAT54W"), ds=DS + "protection/BAT54.pdf",
                  desc="Schottky diode 30 V 200 mA, trr <= 5 ns"),
    # Nexperia BAT54S (1 Jul 2022): Table 2 p2 pin 1 A1, 2 K2, 3 K1/A2 (= KiCad BAT54S 1 A, 2 K, 3 COM).
    "BAT54S": dict(mfr=NXP, mpn="BAT54S", prefix="D", pkg="SOT-23", stock=("Diode", "BAT54S"), ds=DS + "protection/BAT54S.pdf",
                   desc="Dual series Schottky 30 V 200 mA (sense-node clamp to COM and VDD)"),
    # Nexperia BZX84 Rev 7: Table 2 p2 pin 1 A, 2 n.c., 3 K; VZ Table 8 p5 (B16 15.70-16.30 V, B5V6 5.49-5.71 V at 5 mA).
    "BZX84-B16": dict(mfr=NXP, mpn="BZX84-B16", prefix="D", pkg="SOT-23", stock=("Diode", "BZX84Cxx"),
                      ds=DS + "protection/BZX84.pdf", desc="Zener 16 V 2 % 250 mW (gate clamp, positive)"),
    "BZX84-B5V6": dict(mfr=NXP, mpn="BZX84-B5V6", prefix="D", pkg="SOT-23", stock=("Diode", "BZX84Cxx"),
                       ds=DS + "protection/BZX84.pdf", desc="Zener 5.6 V 2 % 250 mW (gate clamp, negative)"),
    "BZX84-B22": dict(mfr=NXP, mpn="BZX84-B22", prefix="D", pkg="SOT-23", stock=("Diode", "BZX84Cxx"),       # Table 8 p5
                      ds=DS + "protection/BZX84.pdf", desc="Zener 22 V 2 % 250 mW (gate clamp, positive, +20 V rail)"),
    # PMEG4010CEJ (shared catalog entry): per-gate Miller-clamp diode when devices are paralleled. Nexperia datasheet
    # (docs/datasheets/protection/PMEG4010CEJ.pdf) p2: VR 40 V, IFRM 7 A (tp <= 1 ms), VF <= 570 mV at 1 A.
    # Diodes Inc US1M DS16008 Rev 11-2: VRRM 1000 V, trr 75 ns, CT 10 pF at 4 V, IR 5/100 uA at 25/100 C p2; order US1M-13-F p1.
    # DESAT string: Taiwan Semiconductor US1MH (gen/data/alternates.csv DROP-IN for Diodes US1M-13-F, rev 5): VRRM 1000 V,
    # CJ 10 pF typ at 4 V, trr 75 ns, IR 150 uA at 125 C, AEC-Q101 (TSC-US1xH.pdf p1-3), same SMA land and cathode band.
    "US1M": dict(mfr="Taiwan Semiconductor", mpn="US1MH", prefix="D", pkg="SMA (DO-214AC)", stock=("Diode", "US1M"),
                 ds=DS + "power-semiconductors/TSC-US1xH.pdf",
                 desc="Ultrafast rectifier 1000 V 1 A trr 75 ns, AEC-Q101 (DESAT string)"),
    # DESAT string of the 1700 V-device presets (review R4 / E01, 2026-10-07): Vishay BYG23T-M3 (BYG23T.pdf, doc 89429 rev 25-Feb-2020):
    # p1 cathode band = cathode (KiCad US1M symbol: 1 K, 2 A, the same SMA land as the US1MH), V_RRM 1300 V, I_F 1 A, I_FSM 18 A,
    # E_R 5 mJ (avalanche, non-repetitive, I(BR)R 0.4 A, 25 C), T_J 150 C; p2 V_F 1.74 / 1.9 V (typ / max) at 1 A, I_R <= 5 / 50 uA at
    # 1300 V and 25 / 125 C, trr <= 75 ns, C_J 9 pF typ at 4 V; p3 Fig. 3 V_F from 0.1 A, Fig. 4 I_R vs % V_RRM, Fig. 5 C_J 0.1-100 V;
    # p4 outline and pad layout. Commercial grade (M3): no AEC-Q101 variant; JEDEC J-STD-020 MSL 1 and JESD 201 class 2 (p1). LCSC C145454.
    "BYG23T": dict(mfr="Vishay", mpn="BYG23T-M3/TR", prefix="D", pkg="SMA (DO-214AC)", stock=("Diode", "US1M"),
                   ds=DS + "power-semiconductors/BYG23T.pdf",
                   desc="Ultrafast avalanche rectifier 1300 V 1 A trr 75 ns, E_R 5 mJ (DESAT string)"),
    # Rev 7 per-phase bias (bias_phase): custom transformer, PNP-pass regulator, shunt for COM. PBSS5540X (Nexperia,
    # Nexperia-PBSS5540X.pdf p1-2, SOT-89: 1 E, 2 C/tab, 3 B; VCEO -40 V, IC -4 A, AEC-Q101). ATL431BIDBZR (TI ATL431.pdf
    # p3-4: DBZ 1 K, 2 REF, 3 A; Vref 2.475-2.525 V, IKA(min) <= 35 uA, VKA <= 36 V).
    "T_BIAS4": dict(mfr="", mpn="", prefix="T", pkg="EP10-class, sectioned bobbin, TIW secondaries", ds="", sourcing="CUSTOM",
                    desc="Gate-bias transformer per phase (sim/out/magnetics/design_gdrv_bias_transformer.json): %s %s, "
                         "%s, ratio 1:%g, barrier %.2f pF high-side winding to primary / %.2f pF adjacent sections, functional "
                         "insulation PD-free >= 1.75 kVpk; %.2f USD (1 k, ESTIMATE)" % (_XF["core"]["maker"],
                         _XF["core"]["part_number"], _XF["electrical"]["turns"], XF_N, XF_C["high_side_to_primary"] * 1e12,
                         XF_C["adjacent"] * 1e12, XF_COST[0]),
                    pins={"left": ["1 D1 p", "2 CT p", "3 D2 p"],
                          "right": ["4 S1A p", "5 S1B p", None, "6 S2A p", "7 S2B p", None, "8 S3A p", "9 S3B p", None,
                                    "10 S4A p", "11 S4B p"]}),
    "PBSS5540X": dict(mfr=NXP, mpn="PBSS5540X,135", prefix="Q", pkg="SOT-89", ds=DS + "power-semiconductors/Nexperia-PBSS5540X.pdf",
                      desc="PNP 40 V 4 A low VCEsat, AEC-Q101: pass transistor of the per-channel bias regulator",
                      pins={"left": ["3 B i"], "right": ["1 E p", "2 C p"]}),
    "ATL431-GD": dict(mfr=TI, mpn="ATL431BIDBZR", prefix="U", pkg="SOT-23-3 (DBZ)", ds=DS + "power-supply/ATL431.pdf",
                      desc="Shunt reference 2.5 V +/-1 %, 36 V: bias regulator and COM split",
                      pins={"left": ["2 REF i"], "right": ["1 K p", "3 A p"]}),
    # Miller clamp + SC booster FET behind the catalog KEY "AO3400A" (key kept for the board files; rev 6 part): Nexperia
    # PMV30ENEAR (LCSC C553092), Nexperia-PMV30ENEA.pdf: p1-2 pins 1 G / 2 S / 3 D, VDS 40 V, VGS +/-20 V, IDM 19 A (10 us),
    # AEC-Q101, Tj 175 C; p6 VGS(th) 1.0-2.5 V, RDSon <= 30 mOhm at 10 V / <= 40 mOhm at 4.5 V, QG(tot) 7.8 nC at 10 V.
    "AO3400A": dict(mfr=NXP, mpn="PMV30ENEAR", prefix="Q", pkg="SOT-23", stock=("Transistor_FET", "2N7002"),
                    ds=DS + "power-semiconductors/Nexperia-PMV30ENEA.pdf",
                    desc="N-MOSFET 40 V 4.8 A (19 A pulse), <= 40 mOhm at VGS 4.5 V, AEC-Q101: Miller clamp / SC booster"),
    "BZX84-B3V3,215": dict(mfr=NXP, mpn="BZX84-B3V3", prefix="D", pkg="SOT-23", stock=("Diode", "BZX84Cxx"),
                       ds=DS + "protection/BZX84.pdf", desc="Zener 3.3 V 2 % 250 mW (clamp-FET gate supply / trigger shift)"),
    "MMBT3904,215": dict(mfr=NXP, mpn="MMBT3904,215", prefix="Q", pkg="SOT-23", stock=("Transistor_BJT", "MMBT3904"),
                     ds=DS + "power-semiconductors/Nexperia-MMBT3904.pdf", desc="NPN 40 V 200 mA (clamp release / SC trigger)"),
    "MMBT3906,215": dict(mfr=NXP, mpn="MMBT3906,215", prefix="Q", pkg="SOT-23", stock=("Transistor_BJT", "MMBT3906"),
                     ds=DS + "power-semiconductors/Nexperia-MMBT3906.pdf", desc="PNP 40 V 200 mA (clamp inverter / SC booster)"),
    "BZX84-B10": dict(mfr=NXP, mpn="BZX84-B10", prefix="D", pkg="SOT-23", stock=("Diode", "BZX84Cxx"),
                      ds=DS + "protection/BZX84.pdf", desc="Zener 10 V 2 % 250 mW (SC trigger level / booster gate clamp)"),
    "BZX84-B20,215": dict(mfr=NXP, mpn="BZX84-B20,215", prefix="D", pkg="SOT-23", stock=("Diode", "BZX84Cxx"),
                      ds=DS + "protection/BZX84.pdf", desc="Zener 20 V 2 % 250 mW (gate clamp, positive, +18 V rail)"),
    "BZX84-B4V7": dict(mfr=NXP, mpn="BZX84-B4V7", prefix="D", pkg="SOT-23", stock=("Diode", "BZX84Cxx"),
                       ds=DS + "protection/BZX84.pdf", desc="Zener 4.7 V 2 % 250 mW (gate clamp, negative, -3/-3.5 V rail)"),
    # Nexperia 2N7002BK (17 Oct 2024): Table 2 p2 pin 1 G, 2 S, 3 D; VGSth 1.1-2.1 V, RDSon <= 2 ohm at 5 V p6.
    "2N7002BK": dict(mfr=NXP, mpn="2N7002BK", prefix="Q", pkg="SOT-23", stock=("Transistor_FET", "2N7002"),
                     ds=DS + "power-semiconductors/2N7002BK.pdf", desc="N-MOSFET 60 V 350 mA logic level"),
    # Diodes Inc ZXTP25040DFH (Oct 2021): p1 pin-out 1 B, 2 E, 3 C (= KiCad BC807); p2 VCEO -40 V, VECO -3 V, VEBO -7 V,
    # IC -3 A, ICM -9 A; p4 hFE >= 30 at -3 A/-2 V, VBE(sat) <= 1.0 V and VCE(sat) <= 220 mV at -3 A/-300 mA, Cobo 17.4 pF.
    # The Q-suffix part is the AEC-Q101 grade. Datasheet read from the URL; PDF not yet in docs/ (download needs approval).
    "ZXTP25040DFH": dict(mfr="Diodes Incorporated", mpn="ZXTP25040DFHTA", prefix="Q", pkg="SOT-23",
                         stock=("Transistor_BJT", "BC807"), ds=DS + "power-semiconductors/ZXTP25040DFH.pdf",
                         desc="PNP 40 V 3 A (9 A pulse) low VCEsat: local Miller-hold follower at each gate"),
    # Diodes Inc ZXTN25040DFH (DS33697 Rev. 3-2, Oct 2025): p1 pin-out as ZXTP (1 B, 2 E, 3 C = KiCad BC817), complement of
    # ZXTP25040DFH; p2 VCEO 40 V, IC 4 A, ICM 10 A; p4 hFE >= 300 at 1 A (p1), >= 30 at 4 A / 2 V, ~10 typ at 10 A
    "ZXTN25040DFH": dict(mfr="Diodes Incorporated", mpn="ZXTN25040DFHTA", prefix="Q", pkg="SOT-23",
                         stock=("Transistor_BJT", "BC817"), ds=DS + "power-semiconductors/ZXTN25040DFH.pdf",
                         desc="NPN 40 V 4 A (10 A pulse), hFE >= 300 at 1 A: Miller-clamp release of a 6-gate channel"),
    # Samtec TSW through-hole headers (DS_SAMTEC): board-to-board / solder pins.
    "J_LOGIC": dict(mfr="Samtec", mpn="TSW-108-07-G-D", prefix="J", pkg="2x8 2.54 mm THT", ds=DS_SAMTEC,
                    stock=("Connector_Generic", "Conn_02x08_Odd_Even"), desc="Header 2x8 2.54 mm, logic side to power board"),
    "J_GATE_H": dict(mfr="Samtec", mpn="TSW-104-07-G-S", prefix="J", pkg="1x4 2.54 mm THT", ds=DS_SAMTEC,
                     stock=("Connector_Generic", "Conn_01x04"), desc="Header 1x4 2.54 mm, gate/Kelvin source pins"),
    "J_GATE_L": dict(mfr="Samtec", mpn="TSW-106-07-G-S", prefix="J", pkg="1x6 2.54 mm THT", ds=DS_SAMTEC,
                     stock=("Connector_Generic", "Conn_01x06"), desc="Header 1x6 2.54 mm, gate/Kelvin source/NTC pins"),
    "J_HV": dict(mfr="Samtec", mpn="TSW-101-07-G-S", prefix="J", pkg="1x1 2.54 mm THT", ds=DS_SAMTEC,
                 stock=("Connector_Generic", "Conn_01x01"), desc="Single pin, drain sense; isolated by board spacing"),
}
CATALOG = dict(catalog.PARTS, **PARTS)

R_GATE = (2.0, 1.0)                     # Ron, Roff (ohm) for the GM4 module card; checked in design_check()
# DESAT per device voltage class (NSI6651 DESAT pin, p9: internal ICHG source, VDESAT_TH 8.5-10.0 V (-Q1 / industrial envelope)): DESAT - Rs - n x
# diode ("part", a catalog key of STRING_DIODE) - drain, BAT54S clamp of the pin to COM/VDD, Cblk footprint fitted DNP (c_blk None): string, clamp
# and pin capacitance alone set the blanking. 1200 V class (DAB-D60 / GDRV-HB, kept, not developed further - D-044): 3 x US1MH as drawn.
# 1700 V class = the PV cell AND the PCS (DESAT_PCS below is the same preset), review R4 / E01: 2 x BYG23T-M3 - each 1300 V diode alone
# blocks the highest static link of STRING_ENV, so the split by leakage (no datasheet bounds it) is not relied on; was 3 x US1MH (PV) and
# 2 x US1MH (PCS), whose 1000 V diodes needed that split. Two diodes, not three: one V_F more threshold (the PCS's 200 ms overload on-state,
# PCM-07) and fewer parts; the V_F band (vf at the string temperatures vf_t, slope vf_tc) is derived at DESAT_PCS below.
DESAT_1700 = dict(n_dhv=2, rs=100.0, c_blk=None, part="BYG23T", vf=(0.30, 1.01), vf_t=(-30.0, 125.0), vf_tc=-2e-3)
DESAT_CLASS = {1200: dict(n_dhv=3, rs=100.0, c_blk=None, part="US1M"), 1700: DESAT_1700}
DEADTIME = (2.37e3, 100e-12)            # falling-edge stretch R, C on the interlock input (GM4 / Gen-3 turn-off 75 ns;
                                        # 2.21k -> 2.37k for the NSI6651's 70 ns delay-mismatch budget)
DEADTIME_DAB3 = (4.02e3, 100e-12)       # 2-3 x 1200 V discretes per switch: the rev-5 clamps of the slowest set
                                        # (3 x IV3Q12013T4Z) must be on before the complementary turn-on
DEADTIME_PV = (3.40e3, 100e-12)         # 2 x MSC035SMA170B4: long enough that the Miller clamp of the paralleled gates
                                        # is on before the complementary turn-on at the minimum hardware DT (design_check)
DEADTIME_CLASS = {1200: DEADTIME, 1700: DEADTIME_PV}
R_KS = 0.5                              # paralleled devices: per-device Kelvin resistor to the COM star (PVR-05/06)
R_PU = 150.0                            # paralleled devices: OUTH -> CLAMP node, lifts that node at turn-on
R_VL, C_VL = 4.7, 1e-6                  # paralleled devices: local VEE per device (R from VEE, C to its Kelvin pin)
R_SB_CLASS = {1200: 68.0, 1700: 22.0}   # SC booster series R per device (gate -> booster FET -> VEE): sets the two-level
                                        # gate during the driver's reaction and the turn-off di/dt (design_check asserts)
RDR = (1.82e3, 124.0)                   # UCC14241 RLIM1 (source path), RLIM2 + DLIM (sink path), SLUSF09A Case B

# (VDD-COM, COM-VEE) rail settings and everything that depends on the rail: UCC14241 feedback dividers (SLUSF09A
# eq 19/20 p39, 0.1 %), gate clamp Zeners, number of 22u COM-VEE capacitors (K23, eq 4), RDR network (eq 14/15) and the
# default device voltage class (vclass -> DESAT_CLASS / DEADTIME_CLASS). Every row is checked by design_check(). (15, 4) = Wolfspeed Gen-3 / GM4 VGS(op) (C3M0021120K p1, CBB011M12GM4T p1); (20, 4) = Microchip
# MSC035SMA170B4 (recommended 20/-5 V, DS00005160A p3) with the off-bias reduced to -4 V, see REFUSED.
GATE_V = {
    (15, 4): dict(fbvdd=(66.5e3, 10e3), fbvee=(6.04e3, 10e3), zener=("BZX84-B16", "BZX84-B5V6"), c3=2, rdr=RDR,
                  rlim1_pkg="0805", vclass=1200),
    (18, 3): dict(fbvdd=(73.2e3, 10e3), fbvee=(2.00e3, 10e3), zener=("BZX84-B20,215", "BZX84-B4V7"), c3=3,
                  rdr=(1.58e3, 95.3), rlim1_pkg="1206", vclass=None),
    (18, 3.5): dict(fbvdd=(76.8e3, 10e3), fbvee=(4.02e3, 10e3), zener=("BZX84-B20,215", "BZX84-B4V7"), c3=3,
                    rdr=(1.58e3, 97.6), rlim1_pkg="1206", vclass=None),
    (18, 4): dict(fbvdd=(78.7e3, 10e3), fbvee=(6.04e3, 10e3), zener=("BZX84-B20,215", "BZX84-B5V6"), c3=3,
                  rdr=(1.40e3, 97.6), rlim1_pkg="1206", vclass=None),
    (20, 4): dict(fbvdd=(86.6e3, 10e3), fbvee=(6.04e3, 10e3), zener=("BZX84-B22", "BZX84-B5V6"), c3=3,
                  rdr=(1.54e3, 97.6), rlim1_pkg="1206", vclass=1700),
}
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

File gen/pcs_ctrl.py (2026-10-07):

"""PCS-CTL - control board of the PCS-P125 inverter: an assembly variant of gen/pv_ctrl.py (PV-CTL), same schematic
pattern, its own project, values and BOM (D-061; docs/requirements/ARCHITECTURE-PCS.md section 6; contract PCS_PC +
PCS_X in gen/interfaces.py). This script re-values the PV-CTL module in place (its build functions read these module
values at call time) and builds PCS-CTL; gen/pv_ctrl.py and its outputs are not changed. Nothing is bench-validated.

STAGES DONE / TODO (each DONE stage builds and passes every check):
  1 DONE  IL1-3 windows +/-450 A on the PCS phase-current sensor (since PCM-20 the Sinomags STK-250HO/4, 3.2 mV/A around its
          own Uref pin; rev A0 assumed an RFQ 4.0 mV/A part): divider 10.0k / 10.0k, Uref ladder re-valued (C.ILR_LAD),
          ADC stage Rf 2.49k; OV comparators
          1050 V on VB (DC link) and 560 V on VA (lower half); inductor OT ladder for the L1 140 C limit; K_A (= AC
          contactor 1) gated by HEALTHY only; the three SELV fan headers of PV-CTL; three-wire assembly bom/PCS-CTL-3W
  2 DONE  sheet 08: PCS_X socket (X6521FV-2x08, mate of PCS-PWR's box header); K_AC2 = K_AC2_M (GPIO61) AND HEALTHY
          on the 23rd 74LVC08 gate (10k pull-down, inside the latch evaluation); RCM_TST from GPIO21; VG1-3 / VC1-3 on
          100 R / 1 nF, one per ADC (A, B, C); RCM through 10.0k / 13.0k; NTC9 bias 10.0k; NTC1-8 through a TMUX1208 onto
          one ADC pin (MUX_A0-2 = GPIO58-60). IA / IA_H / VAX not read (J_PC pins open). Pin plan
          gen/data/pcs_ctrl_pin_plan.csv; budget asserted: 24 three-wire signals on 21 of the 23 analog pins with VDAC,
          PWM 6 of 16. The stage-1 count '24 of 25' was wrong: the data sheet's 25 channels count B5 / B11 twice (AGPIO
          pins 48 / 49), so 24 signals + VDAC did not fit without the mux (+0.23 USD)
  3 DONE  module PCS-P125 = PCS-PWR + PCS-CTL-3W (the three-wire assembly: neutral-leg comparators not fitted, as
          PV-P75 uses PV-CTL-P75) with fans, guards, harness and standoffs in gen/build_all.py extras; gen/cost.py
          MODULES / MODULE_AMPS; the lines the pricer could not price entered from sim/out/pcs_design/pcs_costed_bom.csv
          as labelled ESTIMATE / RFQ rows (@PCS-P125) in gen/data/cost_estimates.csv.
  4 DONE  four-wire assembly PCS-CTL-4W (with PCS-PWR-4W; module PCS-P125-4W): every part fitted (bom/PCS-CTL-4W_BOM.csv) -
          PWM7 / PWM8 = the N leg, the IL4 window and NTC4 / NTC8 comparators, NTC4 / NTC8 through the TMUX1208, VGN from PCS_X
          on pin 21 (B12/C2; 100R / 1 nF + 1 M pull-down: 0 V = a three-wire power board); PWM16 = K_ACPRE, the AC precharge relay
          command of both power-board builds (GPIO15 as a GPIO, gated AND HEALTHY). One pin plan for both builds (the routing does
          not differ): 22 of 23 analog pins with VDAC, PWM 6 / 8 of 16 - both budgets printed
REVIEW (PCM-04 / 05 / 06 / 14 / 20 and the control study's record errors): the IL window, ADC scaling and trip response on the
      STK-250HO/4's data-sheet values (parsed from PCS-PWR's design check, error terms of its p13); the inverter's firmware limits
      (pcs_spec handover firmware_limits) in the firmware table, incl. the upper DC-link half (VB - VA) by firmware; the
      inverter's own ADC plan (sim/out/pcs_control/pcs_control_spec.json firmware.sampling), dead band, CMPSS row and K_A route.
REVIEW R2 (2026-10-07; pcs_spec protection_chain, R2-02 / R2-03): the IL trip chain is the spec's - window cap, current ceiling (leg
      deck / L1 flux rule), the L1-envelope fault slope integrated over each response, the six-gate turn-off in every response, the
      bus limit at gates-off from the deck's over-voltage corner; the CMPSS backup DAC re-set inside the spec's requirement band (it
      was +/-532 A: L1 saturated before the gates went off), so the bands overlap and the window's rule is its cap plus its bottom
      above the control study's per-sample clamp; the RCM channel from residual_current_contract (R2-13); the firmware rows of the
      control study's R2-04 / R2-05 / R2-14 answers (soft DC-link limit holds CV mode, ride-through clamp, AC-start repairs).
OPEN: (1) closed (PCM-20): the sensor is the STK-250HO/4; what stays open is the maker's missing working-voltage / PD / dv/dt
      statement and qualification (PCS-PWR design check). (2) partly closed (R2): the chain constants come from pcs_spec
      protection_chain (CALCULATED, its comparator term 2 x typical ASSUMED and its six-gate turn-off an ESTIMATE); still this
      script's ASSUMPTIONS: firmware OV 975 V and the PV control_spec's OV lag limits (PCS_REQ below); the DC OV band is centred
      so its top is the hand-over's 1050 V. (3) The coordinator's brief asked for the DC contactor (K_B)
      gated by HEALTHY only; this build keeps K_B = HEALTHY OR HOLD (the hold-off layer of the DC contactor) and gates K_A
      (AC contactor 1) by HEALTHY only - the item listed by the power board (PCS-PWR OPEN 6); accepted in D-062.
      (4) closed (stage 4): the four-wire assembly is drawn; 22 of 23 analog pins (one spare, pin 23); four fans on three
      fan headers (Y-harness on header 3, fan 4's tach unread).
      (5) closed (R2-13): the RCM channel (scaling through PCS-PWR's 100R, the firmware fault window, the TEST drive) is set from
      pcs_spec residual_current_contract - an RFQ contract, ASSUMED until the part is chosen; the drawn 4-pin interface stays.
Usage: .venv/bin/python gen/pcs_ctrl.py
"""
import bisect
import contextlib
import copy
import csv
import functools
import hashlib
import io
import json
import math
import os
import re
import sys
import xml.etree.ElementTree as ET

import ctrl_c2000
import dcdclib as L
import interfaces as IF
import pv_ctrl as C
import pv_power as PP
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

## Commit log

2026-10-04 Import the power-conversion platform: schematic generators, simulations, BOMs and requirements
    Python generators (gen/) write the KiCad 10 schematics, netlists, PDFs and BOMs in hardware/ and bom/;
    simulations and design calculations live in sim/ with their reports in sim/out/; requirements, decisions,
    the cost review and the architecture specifications are in docs/requirements/.
    Third-party datasheets and reference-design files are not included: docs/SOURCES.csv lists each one with
    its URL and SHA-256, and docs/fetch.py downloads them again.
    Work in progress: nothing here is bench-validated; see docs/requirements/DECISIONS.md for open items.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
    [01_b1_power.kicad_sch, 01_cell.kicad_sch, 01_gateway.kicad_sch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]
2026-10-04 File Wolfspeed inverter references; settle the inverter topology; library index regenerates itself
    Reference library
    - CRD-25BDA6512N-K (25 kW T-type) design files and CRD200DA23N-GMA (200 kW two-level, 1500 V bus) guide
    and design files recorded in the manifests; notes for the new design.
    - docs/fetch.py: plain requests only, refuses a download whose hash differs from the manifest, flags files
    without a row, and regenerates the tables of docs/LIBRARY.md (--summary). Three datasheets that had no
    master row are now listed.
    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
    [PV-P100-110-FULL_costed_BOM.csv, PV-P100-110_costed_BOM.csv, PV-P75-FULL_costed_BOM.csv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]
2026-10-04 Add the documentation set; re-run the PV module and the Megarevo comparison on the cost-first boards
    Documentation
    - README.md (banner, status dashboard, architecture and workflow diagrams, generated cost table), the hub
    docs/README.md and docs/guide/01..13 with glossary and decision digest, to the style in docs/assets/STYLE.md.
    - Charts and the cost / status / comparison tables are generated from the project's data files by
    docs/assets/figures_overview.py and figures_design.py.
    Design results (calculated; nothing is bench-validated)
    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
    [comparison.csv, cost_estimates.csv, envelope.csv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]
2026-10-04 Cross-check the inverter topology against Wolfspeed's reference designs (D-057)
    - sim/pcs_crosscheck.py + crosscheck_wolfspeed.md: an independent check of the six claims behind D-053. The
    two-level SiC stage stands on robustness and simplicity, not on cost; the study priced its filter inductors
    at about half their material cost (about 979-1,028 USD at 5,000 units instead of 869) and understated the
    turn-on loss (peak efficiency about 98.9-99.1 %, not 99.20 %). Loss model calibrated on Wolfspeed's 25 kW
    board: 231 W calculated against 237 W.
    - Notes for CRD-25BDA6512N-K rewritten from its design files; its magnetics added to the reference table.
    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
    [SOURCES.csv, reference_magnetics.csv]
2026-10-04 Board revisions PV-PWR A2 / PV-CTL A1, inverter filter magnetics, documentation refresh (D-056..D-058)
    Boards (every build check passes)
    - PV-PWR / PV-PWR-4 rev A2: seventh battery-side film capacitor on the three-phase board (closes the
    load-rejection overshoot), bleeder 8 x 73.2 k so the bank still discharges within its 10-minute label.
    - PV-CTL rev A1: hardware over-current window 68.9-79.9 A, thresholds derived from each sensor's own
    reference; the board-to-board contract carries the four references on the former 24 V / 5 V pins.
    - Records aligned (contract comments, architecture corrections, port-current bandwidth); the frozen
    platform's module BOMs are kept instead of being re-ro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
    [01_pc.kicad_sch, 01_supply.kicad_sch, 02_leanA_power.kicad_sch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]
2026-10-04 Settle the inverter design point with real inductor designs (D-059); final documentation pass
    - sim/pcs_tradeoff.py + tradeoff.md: more than twenty candidates, each with its filter inductors designed by
    the magnetics model. Two-level SiC stays, at 24 kHz with L1 130 uH, C_f 75 uF, L2 6 uH: 1,365 USD at
    catalogue prices and 1,092 USD at 5,000 units (three-wire), peak efficiency 99.09 %. The earlier design
    corrected is 1,194 USD; a SiC T-type 1,236-1,279 USD; an IGBT T-type at 16 kHz 1,607 USD.
    - sim/pcs_design.py: turn-on energy at the drawn gate resistor, inductor ripple in the device losses,
    inductor cost, mass and loss taken from the magnetics model.
    - Documentation: inverter pages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
    [pcs_costed_bom.csv]
2026-10-04 Correct the inverter design point to 32 kHz / 120 uH after a fault in the magnetics tool (D-060)
    - OpenMagnetics' data for the amorphous core material gives a permeability of 1 at 20, 24 and 30 kHz: it
    modelled an air core and flattered every amorphous inductor at those frequencies. Caught by the script's own
    inductance comparison when the design point changed; sim/magnetics.py now models those parts with valid
    material data and checks that its design files equal the inverter study's selection.
    - Trade study re-run: two-level SiC at 32 kHz, L1 120 uH, C_f 50 uF, L2 6 uH - 1,409 USD at catalogue prices,
    1,131 USD at 5,000 units (three-wire), peak efficiency 98.99 %. 24 kHz / 130 uH is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
    [pcs_costed_bom.csv, review_magnetics.csv]
2026-10-05 Draw the inverter power board PCS-PWR rev A0 (D-061)
    - gen/pcs_power.py: three two-level legs with six paralleled 1700 V SiC devices per switch, split film DC
    link, filter capacitor bank and damping, DC port (contactor, 400 A fuses, precharge, surge network,
    insulation monitor, interlocks), two AC contactors in series, AC surge network, 75 W auxiliary supply.
    26 sheets, 1,692 parts, 763 nets; ERC, netlist identity, isolation domains, part stress and BOM checks pass.
    - gen/gdrv.py: gate-drive preset for six paralleled devices (existing presets' results unchanged).
    - gen/interfaces.py: PCS_PC (the PV contract pin for pin) and PCS_X; the board is registered in build_all.
    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
    [01_pc.kicad_sch, 02_dclink.kicad_sch, 03_lega.kicad_sch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]
2026-10-05 Draw the inverter control board PCS-CTL rev A0, first stage (D-062)
    A re-valued variant of the PV control board: current window for +-450 A, DC-link and lower-half over-voltage
    comparators, inductor over-temperature threshold, AC contactor 1 gated by HEALTHY only. 7 sheets, 288 parts,
    193 nets; every build check passes; the PV control board's outputs are unchanged. Not done yet: the PCS_X
    signals, the second AC contactor, the residual-current test output, the inverter pin plan, the module BOM.
    Everything is calculated or estimated; nothing is bench-validated.
    [01_supply.kicad_sch, 02_mcu.kicad_sch, 03_afe.kicad_sch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]
2026-10-05 Register the inverter module PCS-P125: module BOM and costed BOM of the drawn boards (D-063)
    PCS-PWR rev A0 + PCS-CTL-3W rev A0: 1,521 USD at catalogue prices, 1,291 USD at 5,000 units, against the
    design study's 1,409 / 1,131 USD (studs, circuitry outside the study's allowances, the cost model's own
    volume factors). Lines the pricer cannot price are entered from the study's costed list as labelled
    estimates. The PV module totals are unchanged. Everything is calculated or estimated.
    [PCS-P125_costed_BOM.csv, PCS-P125_module_BOM.csv, cost_estimates.csv]
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2026-10-05 Document the inverter boards; treat the inverter as a drawn module in the generated tables and audits
    - docs/guide/09-pcs-p125.md: the drawn boards (table, block diagram, gate-drive preset for six paralleled
    devices, controller budget, board-level cost against the study), risks and badges brought up to date;
    the other pages, the decision digest (D-061 to D-064) and the repository guide follow.
    - The generated board table labels PCS-PWR and PCS-CTL as the inverter module; gen/temp_audit.py covers
    the inverter module BOM (242 parts, 80 not yet audited); bom/COST.md no longer says the inverter has no boards.
    [cost.py, figures_overview.py, temp_audit.py]
2026-10-05 Resolve the independent PCM review of 033d8d8 (PCM-01..27): verify, classify, fix at the root (D-065..D-072)
    Register gen/data/review_pcm.csv: 27 findings, each verified before a change - 21 Confirmed, 2 Firmware
    Handled, 3 Improvement Recommended, 1 Not Applicable; 20 closed, 7 open with their closing path.
    PV family (D-065, D-072): the 45 A port rating no longer clamps the inductor current in the near-unity
    band (inductor rating 47.7 A there; 550/550 V 73.3 kW; rated power from 562 V); control model re-based on
    the drawn boards with a published delivered-power envelope per product and direction; leg commutation
    re-run on the drawn Jianghai capacitors (1374 V worst vs 1445 V); comparator c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
    [02_dclink.kicad_sch, 02_high.kicad_sch, 02_leanA_power.kicad_sch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]
2026-10-05 Document the review response and align the records (D-065..D-072 in README and docs/guide; gate-drive chain consistency)
    Documentation: README status, docs index, every guide page and the decisions digest brought to the state
    after the PCM review - the review register and its seven open items on the verification page; the risk
    register rewritten (A2, A4, A5, C2, C8, C9, E1, E3, E4, F4, F5, F7, F10, D3, D6 updated; B9, B10, D9,
    E5..E7, F11 and group G - the AC-02 and 550 V requirement conflicts, PV-P110 as an input rating - added);
    inverter page with the control study and the corrected link, DESAT, sharing, coordination, sensor and
    envelope; DAB page with the study identity, the derated 900-9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
    [review_pcm.csv]
2026-10-06 Megarevo module parity: four-wire inverter, AC-side start-up, Ethernet and recorder on the control board, aux rev A3 (D-073..D-077)
    - D-073 parity policy and register (modules only; PMA0125 and PMD-75-G3 sheets, PMA manual notes, catalogue 2026 manifest row)
    - D-074 PCS-PWR-4W + PCS-CTL-4W = PCS-P125-4W drawn (fourth leg, L_N, 4-pole AC port, VGN, IL4), AC start-up tap and
    AC precharge on both builds, 30 firmware rows, declarations (kVA tiers, AC short-circuit coordination, airflow, precision)
    - D-075 control board: CH9121T Ethernet bridge over CA-IS3842HW (fitted on PCS-CTL), GD25Q32E recorder flash replacing the
    EEPROM, chainable stop / ready / battery-fault inputs and HFD27 ready rela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
    [01_pc.kicad_sch, 01_supply.kicad_sch, 02_dclink.kicad_sch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]
2026-10-07 Respond to the independent re-check R2 of a427981 (D-078, D-079): gates-off commutation closed, backup band lowered, SiC acceptance, bounded grid-forming transients, ride-through without derating, AC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
    - Register gen/data/review_r2.csv: 14 findings verified and dispositioned (9 Confirmed, 1 Firmware Handled,
    1 Improvement Recommended, 2 Already Fixed, 1 Not Applicable), every row closed with its evidence
    - D-078 power stage: the discrete window turns the gates off at 520.8 A, not at the 485.5 A window top; the leg deck
    at that current peaked at 1457 V against 1445 V, closed at zero cost by R_G,off 7.5 -> 8.75 ohm (1437 V, admissible
    533.6 A); L1 i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
    [03_lega.kicad_sch, 04_legb.kicad_sch, 05_legc.kicad_sch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]
2026-10-07 Respond to the independent re-check R3 of 615e4b5 (D-080): synchronisation close one coil at a time, both trip layers replayed on the four-wire short, PCS-to-PV over-voltage trajectory coupled, two S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
    - Register gen/data/review_r3.csv: 5 findings verified and closed (4 Confirmed, 1 Improvement Recommended); no hardware change
    - Control study: SYNC -> SYNC_CLOSE_K2 -> SYNC_CLOSE_K1 with the unconditional I12 (646 pairs, 24 fault runs); the four-wire
    line-to-neutral short replayed through the comparator window and the CMPSS backup with a 5 ms onset clamp (13.3 A margin,
    no hardware trip); the per-sample clamp 378.0 A against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
    [03_lega.kicad_sch, 04_legb.kicad_sch, 05_legc.kicad_sch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]
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2026-10-07 Respond to the independent economical re-check R4 of 845131d (D-081): DESAT string re-rated to 1300 V diodes, cable-aware DC-bus window enforced, off-grid envelope stated as declared capability, inve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
    - Register gen/data/review_r4.csv: 12 decision areas closed (3 Confirmed, 4 Already Fixed, 3 Improvement Recommended, 2 Not Applicable)
    - E01: the DESAT sense string sees the whole DC link (static envelope 1130 V) on an off switch; 2 x Vishay BYG23T-M3/TR (1300 V)
    per channel on both presets, each diode blocking the envelope alone; PCS window unchanged, PV preset 3 -> 2 diodes; grade
    tables identical; +0.96 to +2.12 USD per mo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
    [02_high.kicad_sch, 03_low.kicad_sch, 03_ph1_gda.kicad_sch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]
2026-10-07 Price labels carry each row's own date; D-081 names the boards that keep the 1000 V DESAT diodes correctly
    [DAB-D60-FULL_costed_BOM.csv, PCS-P125-4W_costed_BOM.csv, PCS-P125_costed_BOM.csv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]
2026-10-07 Respond to the independent closure re-check R5 of 5c56aaa (D-082): no new defect; every open gate of the five rounds consolidated into QUALIFICATION-PLAN.md (44 gates, four stages)
    Register gen/data/review_r5.csv: six closure rows, 4 Already Fixed, 1 Not Applicable
    (the earlier platform's diode strings stay deferred with their own qualification),
    1 Improvement Recommended. No hardware change; nothing measured.
    - docs/requirements/QUALIFICATION-PLAN.md: Q-01..Q-44 with acceptance criterion,
    test asset, blocked claim and stage (cell -> controlled prototype -> DVT -> production)
    - DECISIONS.md D-082, guide 12 (R5 section, standing restrictions), guide 08 (R5 row),
    guide 13 and decisions.md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
    [review_r5.csv]

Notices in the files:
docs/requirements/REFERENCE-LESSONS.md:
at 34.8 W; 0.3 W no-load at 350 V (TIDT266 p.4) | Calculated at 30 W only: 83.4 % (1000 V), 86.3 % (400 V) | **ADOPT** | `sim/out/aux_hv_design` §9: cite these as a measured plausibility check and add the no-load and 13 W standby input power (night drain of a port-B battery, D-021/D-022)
